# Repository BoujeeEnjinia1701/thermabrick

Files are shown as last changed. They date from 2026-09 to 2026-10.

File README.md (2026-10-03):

# ThermaBrick

  

**Area:** CleanTech · **TRL:** 3 of 9 (proof of concept) · **Status:** Concept · **Value-engineering target:** USD 728, the test article budget decided by Amish on 2026-09-25 (on hold with TRL 4); estimated cost of the constructable design USD 3,869 (USD 3,141 over the target) · **Difficulty:** 3 of 5

Sand thermal battery in an insulated steel drum. Resistive elements charge it from surplus PV, and a fan pulls hot air out for space heating.

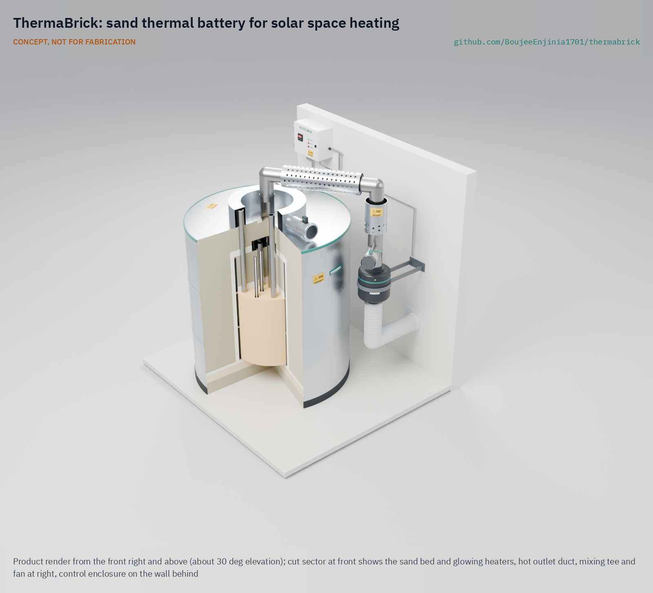
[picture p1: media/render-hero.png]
ThermaBrick: sand thermal battery for solar space heating, product render


[Exploded render](media/render-exploded.png) · [Detail render](media/render-detail.png) · [Interactive 3D model](media/viewer.html) · [Concept blueprint (PDF)](media/concept-blueprint.pdf) · [General arrangement TBK-DWG-001 (PDF)](cad/drawings/TBK-DWG-001.pdf) · [Sizing calculations](docs/04-calcs/TBK-CAL-001-sizing.md) · [Prototype build plan](docs/05-build-plan.md) · [Design decisions](docs/06-design-decisions.md) · [Review note](docs/REVIEW.md)

> **Out-of-phase work archived (2026-09-25).** The portfolio is capped at TRL 3, and TRL 4 is on hold by Amish's instruction. The reduced-scale test article, its test plan and report template, firmware, controller schematic and board, enclosure, purchasing checklist, build procedure and cut list were made in an earlier session that went past the cap. They are kept, unchanged and with full history, in [archive/out-of-phase-trl4/](archive/out-of-phase-trl4/README.md), and are not current work.

## Concept rationale

Heat is the largest energy load in a cold-climate home, and it is the one load that can be stored cheaply in an inert, abundant material. Sand costs almost nothing, does not burn and does not wear out with cycling, and quartz holds more heat per kilogram as it gets hotter. Storing midday solar surplus as heat at up to 450 °C, and releasing it as warm air in the evening, uses the surplus far better than exporting it for a few cents. It also avoids spending lithium battery cycles on a job that sand can do.

The design is open and garage-buildable because the ideas that make it work are simple and well published, while the barrier is detail: how many heater wells, how thick the insulation, how to keep the sand below its quartz inversion and the jacket cool. A standard 55 US gal drum, threaded black steel pipe, stock cartridge heaters and fiber insulation need no welding, pressure parts or machining. Publishing the model, calculations and drawings lets makers, students and community energy groups check the numbers and adapt the design to their own climate and tariff.

## Burning platform

Heat is the largest energy end use. The International Energy Agency reports that heat accounted for almost half of total final energy consumption and for 38 % of energy-related CO2 emissions in 2022, and that renewables supplied only 13 % of global heat consumption that year ([IEA, *Renewables 2023*, Heat](https://www.iea.org/reports/renewables-2023/heat)).

At the same time, grids with a lot of solar already throw some of it away. The California Independent System Operator curtailed 2.4 million MWh (2.4 TWh) of utility-scale wind and solar output in 2022, and more than 2.3 million MWh in the first nine months of 2023 ([US EIA, *Today in Energy*](https://www.eia.gov/todayinenergy/detail.php?id=60822)). Rooftop systems face the same timing problem at house scale: the surplus arrives at midday and the heating demand arrives after dark.

## Where it could be used

### By industry

| Industry | Use |
| --- | --- |
| Residential heating | Shift rooftop solar surplus into evening and night space heat in homes with a slab-on-grade utility room, basement or garage |
| Agriculture | Warm air for small greenhouses, farm workshops and livestock rooms from the farm's own PV |
| Small commercial and workshops | Background heat for workshops and small warehouses that stand empty at midday and need heat at opening time |
| Community energy groups | A documented, shared demonstrator for absorbing local solar surplus as heat instead of exporting it |
| Education and research | A teaching rig for heat transfer, thermal storage and control, with a published model and calculation note |

*Table 1. Uses by industry.*

### By country or region

| Country or region | Why it matters there |
| --- | --- |
| United States (California) | Solar output is already curtailed at grid scale, 2.4 TWh in 2022 ([US EIA](https://www.eia.gov/todayinenergy/detail.php?id=60822)), and since April 15, 2023 new rooftop systems take the Net Billing Tariff, which credits exports at avoided-cost values that are usually lower than the retail rate ([California Public Utilities Commission](https://www.cpuc.ca.gov/industries-and-topics/electrical-energy/demand-side-management/customer-generation/net-energy-metering-and-net-billing)) |
| Finland | Sand heat storage already supplies district heating there: a 200 kW, 8 MWh unit at Kankaanpää since 2022 and a 1 MW, 100 MWh unit at Pornainen since June 2025 ([Polar Night Energy](https://polarnightenergy.com/news/what-is-a-sand-battery/); see also [UNRIC](https://unric.org/en/sand-warms-up-the-finnish-polar-night/) on the Kankaanpää unit); ThermaBrick tests the idea at single-house scale |
| Australia | About 4.2 million homes and small businesses had rooftop solar by June 2025 ([Clean Energy Council, September 15, 2025](https://cleanenergycouncil.org.au/news-resources/australia-powers-ahead-on-rooftop-solar-as-nation-set-to-achieve-2030-rooftop-target-new-report)), and in South Australia the market operator can direct rooftop solar exports to be curtailed during minimum-demand events ([SA Power Networks](https://www.sapowernetworks.com.au/your-power/quality-reliability/solar-curtailment-for-minimum-system-demand-events/)); storing the surplus as heat keeps it in the home |
| China | China, the European Union and the United States account for three-quarters of recent renewable heat growth, and China dominates global solar thermal ([IEA, *Renewables 2023*, Heat](https://www.iea.org/reports/renewables-2023/heat)); a solar-to-sand store brings rooftop PV into a market already large for solar heat |
| Mongolia (Ulaanbaatar) | January temperatures fall below −20 °C, and more than half of ger-area households still heat with traditional coal stoves, pushing winter fine-particle levels in those neighborhoods above 100 times the WHO 24-hour guideline ([World Bank, 2018](https://www.worldbank.org/en/news/feature/2018/06/26/better-air-quality-in-ulaanbaatar-begins-in-ger-areas)); clean stored heat is a direct substitute for the stove |

*Table 2. Where ThermaBrick matters, by country or region.*

## What sparked the idea

The starting point was Finland's sand batteries, which store surplus renewable electricity as heat in sand for district heating. The first commercial unit, built by Polar Night Energy for the utility Vatajankoski at Kankaanpää and commissioned in 2022, is rated 200 kW and 8 MWh and feeds a network that heats homes, offices and the municipal swimming pool ([Polar Night Energy, "World's first Sand Battery"](https://polarnightenergy.com/reference/worlds-first-sand-battery/)); the United Nations Regional Information Centre reports that it holds its sand at 500 to 600 °C ([UNRIC, "Sand warms up the Finnish polar night"](https://unric.org/en/sand-warms-up-the-finnish-polar-night/)). A 1 MW, 100 MWh unit followed at Pornainen in June 2025 ([Polar Night Energy, "What is a Sand Battery?"](https://polarnightenergy.com/news/what-is-a-sand-battery/)). Those units serve district heating networks. ThermaBrick asks whether the same physics can be scaled down to one house with rooftop PV and no heating network: a drum of sand, a set of cartridge heaters and a warm-air outlet, built from parts a maker can buy.

## Problem

Surplus rooftop solar gets exported cheaply or curtailed, while heating still burns gas.

## Concept

Sand thermal battery in an insulated steel drum. Resistive elements charge it from surplus PV, and a fan pulls hot air out for space heating.

The v0.2 design, made constructable on 2026-09-30 (TBK-DDR-003), stores 18.3 kWh(th) in 210 kg of sand between 150 °C and 450 °C. Twelve 250 W heaters charge it at up to 3.0 kW, filling it in 9.6 h, and six steel U-tubes deliver 1.0 kW of warm air for about 14 h. A reduced-scale test article (about 6 kWh(th), budget $727.70) is the next step, to measure the sand and insulation properties the design depends on. It is archived and on hold with TRL 4.

| Document | ID | Version |
| --- | --- | --- |
| [Problem statement](docs/01-problem.md) | TBK-PRB-001 | 0.11 |
| [Design precis](docs/02-concept.md) | TBK-PRC-001 | 0.8 |
| [Requirements](docs/03-requirements.md) | TBK-REQ-001 | 0.12 |
| [Thermal and electrical sizing](docs/04-calcs/TBK-CAL-001-sizing.md) | TBK-CAL-001 | 0.5 |
| [General arrangement](cad/drawings/TBK-DWG-001.pdf) | TBK-DWG-001 | Rev P3 |
| [Concept sheet](media/concept-blueprint.pdf), with [hero](media/hero.png), [cutaway](media/cutaway.png) and [exploded](media/exploded.png) renders, [heat flow](media/flow.png) and [3D viewer](media/viewer.html) | TBK-DWG-006 | Rev P3 |
| [Recommendations accepted](docs/decisions/0002-recommendations-accepted.md) | TBK-DDR-002 | 0.2 |
| [Design for construction](docs/decisions/0003-design-for-construction.md) | TBK-DDR-003 | 0.3 |
| [Prototype build plan](docs/05-build-plan.md), with making sketches TBK-DWG-101 to 110 | TBK-BLD-001 | 0.2 |
| [Design decisions register](docs/06-design-decisions.md) | TBK-DEC-001 | 0.3 |
| [Purchasing checklist](archive/out-of-phase-trl4/bom/purchasing-checklist.md) (archived) | | Test article, by supplier |
| [Controller board BOM (optional, deferred; archived)](archive/out-of-phase-trl4/bom/bom-controller-board.csv) | | +$24.85 net |

## Key components

- 55 gal open-head steel drum, unlined
- Sand, 210 kg
- AES fiber blanket and stone wool insulation
- Nichrome cartridge heaters, 12 x 250 W, in steel wells
- Six 1-1/4 in steel U-tubes (discharge heat exchanger)
- Solid state relays and a safety contactor
- K-type thermocouples and an independent high-limit controller
- ESP32 controller and PV export meter
- Inline fan with mixing tee

The working bill of materials is in [bom/bom.csv](bom/bom.csv).

## Building the prototype

The [prototype build plan](docs/05-build-plan.md) (TBK-BLD-001) shows how to make each of the 21 components and put them together, with a making sketch for every made part, close-ups of the joints and a picture for every assembly step. Writing it made the design constructable: the wells and U-tubes now have a seat and fittings that match the drawings, the base and plenum can be built and fixed, the hot outlet clears the galvanized cap, and the heater leads and thermocouples reach the outside (TBK-DDR-003). Decisions still open are in the [design decisions register](docs/06-design-decisions.md). It is a plan only; building to it is TRL 4 work, which is on hold.

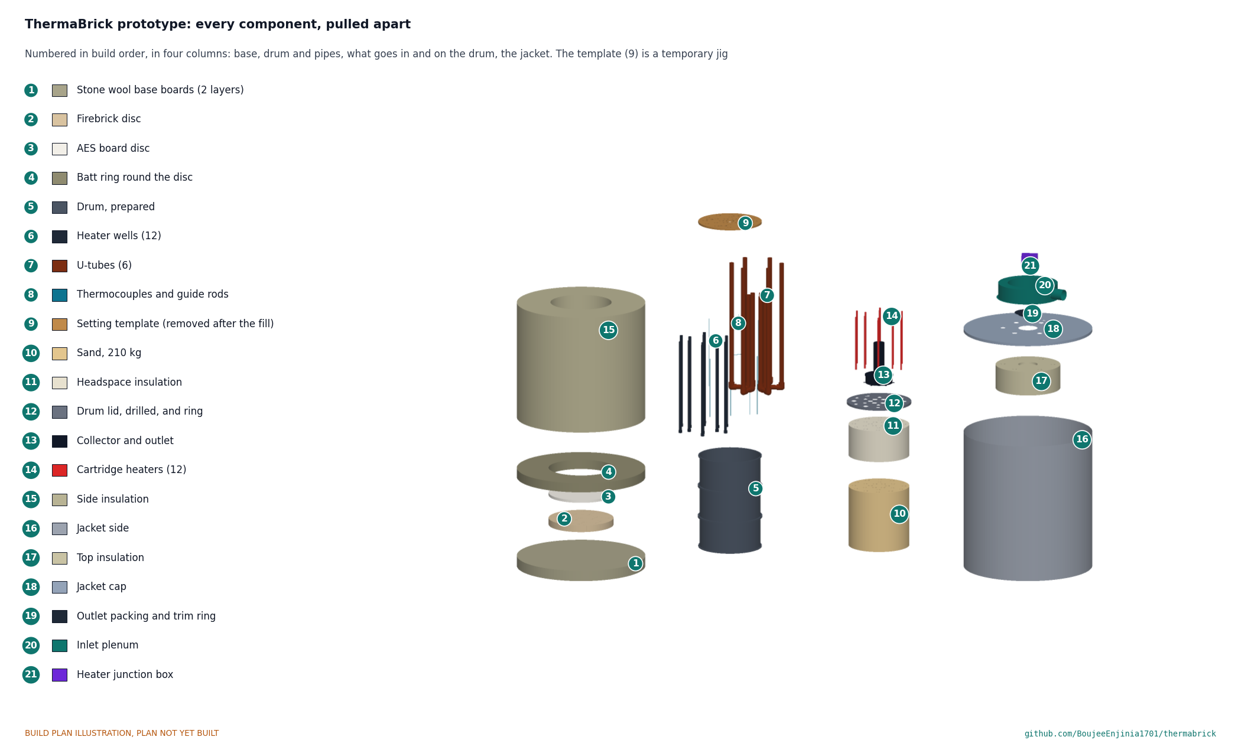
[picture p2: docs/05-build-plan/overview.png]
ThermaBrick prototype: every component, pulled apart and numbered in build order


## Safety

> Operates at up to 550 °C inside and weighs about 415 kg. Use a dedicated 240 V circuit with a 5 mA GFCI breaker, keep the hot outlet duct guarded and 450 mm from combustibles, keep the independent high limit in service, and stand the unit on a concrete slab. See TBK-PRC-001, sections 6 and 7.

## Repository layout

| Folder | Contents |
| --- | --- |
| `docs/` | Problem, concept, requirements, calculations and design decisions |
| `cad/src/` | build123d Python source, the source of truth for all geometry |
| `cad/step/`, `cad/stl/` | Exported models for FreeCAD, other CAD tools and printing |
| `cad/drawings/` | 2D sketches and dimensioned drawings |
| `bom/` | Bill of materials |
| `electronics/` | KiCad schematics and PCB layouts (empty at TRL 3; earlier work archived) |
| `firmware/` | Microcontroller code (empty at TRL 3; earlier work archived) |
| `media/` | Renders, perspectives and photos |
| `build-log/` | Dated prototyping notes |

## Documentation

Controlled documents follow the portfolio [documentation standard](.kit/STANDARDS.md). Each carries a document ID (TBK-PRC-001 for the precis), a version and a revision history. Branded PDFs are built with `python .kit/render.py` and attached to GitHub Releases when a document is tagged, for example `TBK-PRC-001/v1.0`.

## Credits

Designed by Amish Chadha, with contributions from Ashok Kumar Chadha. See [CONTRIBUTORS.md](CONTRIBUTORS.md) for roles. To cite this design, use [CITATION.cff](CITATION.cff) (GitHub shows it as "Cite this repository").

AI assistance (Claude) was used to accelerate concept renders, prototype documentation and first-pass sizing calculations. Design direction and all decisions are Amish Chadha's, recorded in this repository's decision records (`docs/decisions/`).

## Licenses

- **Hardware** (CAD, drawings, BOM, electronics): [CERN-OHL-S v2](LICENSE)
- **Software** (firmware, scripts, notebooks): [MIT](LICENSE-SOFTWARE)

A project of the [Design Molecule](https://designmolecule.com) lab.

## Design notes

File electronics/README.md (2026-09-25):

# Electronics

| Path | Contents |
| --- | --- |
| `src/schematic.py` | Generator for the test article controller schematic (TBK-DWG-003), the source of truth for that circuit |
| `src/board.py` | Generator for the optional controller board: schematic, PCB layout, gerbers and TBK-DWG-004 |
| `test-article/` | KiCad project for TBK-DWG-003: the whole controller, mains and low voltage, as hand-wired modules |
| `controller-board/` | KiCad project for the optional low-voltage controller board, with gerbers for fabrication. **Optional and deferred:** not to be ordered unless Amish decides so |

Change a circuit in its script, not in KiCad, then regenerate from the repo root:

```bash
python electronics/src/schematic.py
```

```bash
python electronics/src/board.py
```

Both scripts need KiCad 9 or later. They look for it in `/Applications/KiCad`, in `~/Applications/KiCad`, or on the mounted KiCad disk image.

`schematic.py` runs KiCad's electrical rules check (ERC). It then exports the netlist and checks every net against the circuit the script declares. It fails on any ERC error or net mismatch.

`board.py` works in three stages:

1. It builds and checks the board schematic in the same way as `schematic.py`.
2. It re-runs itself inside KiCad's bundled Python. That stage places the footprints, routes the board with its own two-layer grid router (F.Cu preferred, clearance 0.25 mm against a 0.2 mm rule) and pours the GND plane on B.Cu.
3. It runs KiCad's DRC with schematic parity, then exports the gerber and drill package and the drawing sheet.

The P1 board passes with 0 errors, 0 warnings and 0 unconnected items. The routing is reproducible, but KiCad assigns fresh internal IDs, so the `.kicad_pcb` file changes on every run even when the layout does not.

Both projects carry every symbol and footprint they use, so they open without KiCad's global libraries installed. Terminal numbers on K1, U1 and U2 of TBK-DWG-003 are functional; wire to each part's own label.

**Board fit.** The board takes an ESP32-DevKitC V4 with 38 pins and header rows 25.4 mm apart. 30-pin and narrow clone boards do not fit. The pinout follows the Espressif DevKitC V4 user guide, header J2 on the left and J3 on the right, both numbered from the antenna end. Check your module against it before soldering the sockets.

**Licenses.** CERN-OHL-S-2.0 for the hardware; MIT for the generator scripts.

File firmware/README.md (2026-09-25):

# ThermaBrick test article firmware

ESP32 controller firmware for the reduced-scale test article (TBK-PRC-002). It covers the five functions that test plan TBK-TST-001, section 1, requires: charge mode, hold mode, blower control, logging and the safe state. It is written for the Arduino framework and built with PlatformIO. Licensed MIT (see `LICENSE-SOFTWARE`).

> **Safety:** This firmware is the second layer of protection, not the first. The REX-C100 limit and the latching relay open the heater circuit at 600 °C whatever the ESP32 is doing. Never bridge or bypass them, and run TBK-TST-001 TP1 before any heated test.

## Layout

| Path | Contents |
| --- | --- |
| `src/main.cpp` | Controller: thermocouples, heater burst firing, blower, HTTP API, log buffer |
| `lib/control/` | Control and safety logic with no Arduino dependency: PI loops, fault latching, MAX6675 decoding, airflow and power math |
| `test/test_control/` | Unit tests for `lib/control`, run on the host |
| `tools/logger.py` | Logging host: polls the controller and writes the test CSV; also the heartbeat |
| `tools/git_rev.py` | Stamps the build with the Git commit |
| `include/secrets.example.h` | Template for Wi-Fi credentials and the API token |

## Build and flash

```bash
pip install platformio
```

```bash
cp firmware/include/secrets.example.h firmware/include/secrets.h
```

Edit `secrets.h` with the Wi-Fi name, password and a long random `API_TOKEN`. The file is ignored by Git. Then, from `firmware/`:

```bash
pio test -e native
```

```bash
pio run -e esp32dev -t upload
```

```bash
pio device monitor
```

The monitor prints the IP address once Wi-Fi connects, then one CSV row every 10 s. Build `esp32dev_test` instead only for TP1 step 5. It adds an `/inject` endpoint that fakes T1, and it must never be used for a heated test.

## Wiring

The complete circuit, including the 120 V side, is the schematic TBK-DWG-003 (`cad/drawings/TBK-DWG-003.pdf`), with KiCad source in `electronics/test-article/`. Table 1 lists the ESP32 connections. The optional controller board, TBK-DWG-004, uses the same pins. On that board GPIO 26 drives the SSR through a 2N3904 and GPIO 25 drives an IRLZ44N; high means on in both cases, so the firmware is unchanged.

| Signal | ESP32 GPIO | Connects to |
| --- | --- | --- |
| SCK (shared) | 18 | SCK on all five MAX6675 modules |
| SO (shared) | 19 | SO on all five MAX6675 modules |
| CS, T1 well wall (control) | 5 | MAX6675 #1 |
| CS, T3 sand center | 17 | MAX6675 #2 |
| CS, T4 sand outer | 16 | MAX6675 #3 |
| CS, T5 exchanger outlet air | 4 | MAX6675 #4 |
| CS, T6 room air | 22 | MAX6675 #5 |
| SSR input + | 26 | SSR terminal 3, with a **10 kΩ pull-down from GPIO 26 to GND** |
| Blower PWM | 25 | MOSFET module signal input, with a 10 kΩ pull-down to GND |
| 5 V and GND | 5V, GND | 12 V to 5 V buck converter; MAX6675 modules take 3.3 V |

*Table 1. Controller wiring.*

Generic SSR-25DA relays specify a 3 V to 32 V input, so 3.3 V from the GPIO is near the bottom of their range. If the SSR's LED does not light reliably, drive its input from 5 V through a small NPN transistor, and keep the pull-down on the GPIO. The pull-down on GPIO 26 is required. It holds the SSR off while the ESP32 boots, resets or is unprogrammed (TBK-TST-001, section 1, item 5). T2 is not wired to the ESP32; it goes only to the REX-C100.

The heater circuit is the 120 V line through the 10 A fuse, then the latching relay contacts, then the SSR, then the four heaters in parallel. The latching relay coil circuit is the line through STOP (normally closed), then START (normally open) in parallel with the relay's own holding contact, then the REX-C100 relay (closed below 600 °C), then the coil.

## How it works

- **Thermocouples.** All five channels are read once a second, by a bit-banged read with the timing of the Adafruit driver. A frame of all zeros, or with the dummy sign bit or device ID bit set, is rejected as a bus fault. An open thermocouple is reported separately. Invalid readings are logged as blank fields, never as 0 °C.
- **Heater output.** A 10 ms timer fires the SSR in bursts within a 1 s window, so the zero-cross SSR switches whole mains cycles. The duty resolution is 1 %, or 10 W on the 1.0 kW article.
- **Charge mode.** Full power until T1 first reaches the setpoint (550 °C by default), then PI control on T1 with a bumpless handover. The default gains are 0.05 per K (full to zero over 20 K) and 300 s. Tune them in TP3 if T1 overshoots by more than 10 K or oscillates.
- **Hold mode.** PI control on T1 from the start, at a lower setpoint, for the TP2 bake-out.
- **Manual mode.** A fixed duty of up to 25 %, for commissioning and the TP1 fault checks only.
- **Blower.** Either a fixed PWM duty, or a closed-loop exchanger duty in watts: ṁ cp (T5 − T6), with airflow from the TP0 duty-to-flow table. The PWM frequency defaults to 100 Hz, which suits 2-wire 12 V blowers switched by a MOSFET. Change it with `/config?pwm_hz=` if the blower stalls or whines.
- **Logging.** One row every 10 s goes into a 3 h ring buffer in RAM and to the serial port. `tools/logger.py` collects the rows over HTTP. The time stamp is seconds since boot; the logger adds wall-clock time.

## Safety model

Any of the conditions in Table 2 latches a fault. A latched fault turns the heaters off at once and sets the heater mode to off. Clearing the fault never restarts heating: the operator must clear it and then command the heater mode again.

| Bit | Fault | Trigger |
| --- | --- | --- |
| 1 | T1 invalid | T1 open or unreadable for 3 consecutive reads (3 s) |
| 2 | T1 high | T1 above 575 °C, after the calibration offset |
| 4 | Sand high | T3 or T4 above 560 °C (quartz inversion margin) |
| 8 | Log stale | No `/log` poll for more than 60 s, or none since boot |
| 16 | Loop stall | Main loop silent for 6 s; the output timer also forces the SSR off by itself |

*Table 2. Latched faults.*

The ESP32 task watchdog resets the controller if the main loop hangs for 8 s. After a reset the heaters stay off, held by the pull-down resistor, until they are commanded again. The "log stale" fault is latched at every boot, so heaters cannot run until a logging host is connected and the fault has been cleared.

## HTTP API

Every request needs `?token=` when `API_TOKEN` is set. All requests are GET, so they can be sent with `curl` or a browser.

| Request | Effect |
| --- | --- |
| `/status` | JSON: temperatures, modes, duties, power, energy, airflow, exchanger duty, faults |
| `/log?since=N` | CSV header, then the buffered rows after sequence N (up to 360 per call); also the heartbeat |
| `/heater?mode=charge&sp=550` | Charge mode; the setpoint is limited to 20 °C to 550 °C |
| `/heater?mode=hold&sp=200` | Hold mode |
| `/heater?mode=manual&duty=0.10` | Manual duty, 0 to 0.25 |
| `/heater?mode=off` | Heaters off |
| `/blower?mode=duty&value=0.5` | Fixed blower duty, 0 to 1 |
| `/blower?mode=power&value=250` | Closed-loop exchanger duty in W |
| `/blower?mode=off` | Blower off |
| `/config` | Show the configuration. With parameters, set and save it to flash: `v_line`, `r_heat`, `kp`, `ti`, `kpb`, `tib`, `bmin`, `off_t1`, `pwm_hz`, `air` |
| `/clear` | Clear latched faults if no fault condition is present |

*Table 3. HTTP API.*

The `air` table takes duty-to-airflow pairs from TP0, as duty (0 to 1) and L/s, in ascending order. For example: `/config?air=0.25:1.1,0.5:2.2,0.75:3.2,1:4.0`. Set `r_heat` to the parallel hot resistance: the TP0 cold values in parallel, times 1.04. Set `v_line` to the voltage measured at the start of each run.

## Running a test

A typical TP3 charge, from the repo root. Replace `HOST` and `TOKEN` with the controller's address and the API token.

```bash
python firmware/tools/logger.py --host HOST --token TOKEN --procedure TP3 --vline 119.6
```

With the logger running, in a second terminal:

```bash
curl "http://HOST/clear?token=TOKEN"
```

```bash
curl "http://HOST/heater?mode=charge&sp=550&token=TOKEN"
```

Stop by commanding `mode=off`, or press STOP on the enclosure. The logger writes to `docs/05-tests/data/YYYY-MM-DD_TP3.csv`, and a restart on the same day appends to the same file.

## Tests

`pio test -e native` runs 14 unit tests on the host. They cover:

- MAX6675 decoding and bus-fault rejection;
- charge mode's full-power-then-PI behavior;
- PI windup recovery;
- hold and manual modes;
- every safety latch and the rule that faults clear only when conditions are gone;
- burst timing, the airflow lookup and the power and duty math.

The hardware behavior is tested on the article itself in TBK-TST-001, TP1.

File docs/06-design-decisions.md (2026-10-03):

---
doc_id: TBK-DEC-001
title: ThermaBrick design decisions register
project: ThermaBrick
doc_type: Design decisions register
version: "0.4"
status: Draft
date: '2026-10-03'
author: Amish Chadha
license: CERN-OHL-S-2.0
revisions:
  - version: "0.1"
    date: '2026-10-01'
    author: Amish Chadha
    change: Register opened with the open decisions from REVIEW.md, TBK-PRC-001, TBK-DDR-002 and TBK-DDR-003; budget treated as a value-engineering target
  - version: "0.2"
    date: '2026-10-02'
    author: Amish Chadha
    change: 'Amish approved the recommendations for all nine open decisions on 2026-10-02 (TBK-DDR-003 accepted); moved to decisions made'
  - version: "0.3"
    date: '2026-10-02'
    author: Amish Chadha
    change: 'Cost restated to USD 3,869 with the warning labels (BOM line 47) and the approved wording; stray full stop fixed'
  - version: "0.4"
    date: '2026-10-03'
    author: Amish Chadha
    change: "Amish accepted the cost overrun against the value-engineering target on 2026-10-03; row added to decisions made; value engineering section updated"
---

# ThermaBrick design decisions register

Every design decision still to be made, and every decision made, in one place. Each decision is argued in full in its decision record under `docs/decisions/` or in the review note; this register is the index Amish works from. The build plan (`docs/05-build-plan.md`) describes the design as it stands and does not list open decisions.

## Open decisions

None. All open decisions were decided on 2026-10-02.

## To confirm when parts are bought

| # | What to confirm | Why it matters | Source |
| --- | --- | --- | --- |
| 1 | The cartridge heaters can be made with 72 in (1,829 mm) ceramic-beaded leads | Shorter leads do not reach the junction box from the far wells | TBK-DDR-003, P9 |
| 2 | The 1-1/4 in elbows' centre-to-end size (about 44.5 mm) and thread make-up, with the 4 in nipple, give 155 mm between leg centres | Sets the U-tube leg spacing that matches the lid holes | TBK-DDR-003, P2 |
| 3 | The stone wool base board is rated 60 kPa or more at 10 % strain | It carries the firebrick load of 15.0 kPa with a safety factor of 4 | TBK-CAL-001, section 7 |
| 4 | The inline fan's pressure curve and speed input meet 60 L/s at 150 Pa | Sets the discharge air flow | TBK-PRC-001, section 9 |
| 5 | The drum's lid is 16 ga, its rim 597 mm and its bottom rim stands on a flat ring | The lid layout and the AES disc size depend on it | TBK-DDR-003, P3 and P5 |
| 6 | At the first firing (TRL 4): the galvanized jacket cap at the edge of the outlet hole stays below 200 °C | R13; if not, fit a listed double-wall stovepipe thimble | TBK-DDR-003, P8 |

## Value engineering

Value-engineering target: USD 728 (a hypothetical control target, not a limit; `budget_usd` in `project.yaml`, set as the reduced-scale test article budget by Amish on 2026-09-25). Estimated cost of the constructable design: USD 3,869 (USD 3,141 over the target). Main cost drivers and savings worth trying:

Amish accepted this overrun on 2026-10-03: the full-scale estimate of USD 3,869 against the USD 728 target (USD 3,141 over). Amish: "Cost over target - i accept all the cost variations and overruns". It stays reported against the target as an accepted overrun, and the savings below remain worth trying.

- The largest groups are insulation (USD 871), controls and instrumentation (USD 863), heaters and wells (USD 776) and the discharge exchanger and air path (USD 740). The largest single lines are the twelve cartridge heaters (USD 588), the stone wool batts (USD 225), the four stone wool boards (USD 180) and the eight thermocouples (USD 208).
- Making the design constructable added USD 180, and the approved warning labels USD 15: longer heater leads and thermocouples, 4 in nipples, two firebricks, a second AES rope, fasteners, and the template, trim ring, guide rods and grommets.
- Savings worth trying (`bom/bom-notes.md`, Table 2): generic import heaters (about USD 300), a reconditioned drum (about USD 100), reading export from the inverter instead of a meter (USD 90), MAX31855 amplifiers (about USD 50), and an existing 240 V circuit (up to USD 190), and stone wool batts in place of board in the base (about USD 100), together about USD 830, which would bring the estimate to about USD 3,040, still far over the target; only the reduced-scale test article (archived, on hold with TRL 4) comes near it.

## Decisions made

| Date | Decision | Decided by | Record |
| --- | --- | --- | --- |
| 2026-09-24 | Build a reduced-scale test article first, within the prototype budget | Amish | TBK-PRB-001, section 5 |
| 2026-09-25 | Test article budget USD 727.70; revisit the full-scale budget with its results (both on hold with TRL 4) | Amish: "i accept all your recommendations, go with them across all repos." | [TBK-DDR-002](decisions/0002-recommendations-accepted.md), A1, A2 |
| 2026-09-25 | Design decisions D1 to D8: silica sand 150 to 450 °C, cartridge heaters in capped wells, twelve 250 W wells, closed U-tubes, cold-side damper with mixing tee and heat trap, wells end at the lid, AES hot face with stone wool, 240 V burst-fire SSRs with contactor | Amish, same instruction | [TBK-DDR-002](decisions/0002-recommendations-accepted.md), A3 |
| 2026-09-25 | Requirement targets R1 to R20 as written, including the 500 °C drum-wall limit | Amish, same instruction | [TBK-DDR-002](decisions/0002-recommendations-accepted.md), A4, A5 |
| 2026-09-25 | R3 charge-time miss: choose the fix after the test article measures sand conductivity (on hold with TRL 4) | Amish, same instruction | [TBK-DDR-002](decisions/0002-recommendations-accepted.md), A6 |
| 2026-09-25 | Controller board stays deferred; KiCad install on hold with TRL 4 | Amish, same instruction | [TBK-DDR-002](decisions/0002-recommendations-accepted.md) |
| 2026-09-30 | The design is made physically buildable as the build plan is drawn | Amish: "If you are realising that the design cannot be built as per concept - fix the design assumptions to match and be physically feasible as you draw the illustrations." | [TBK-DDR-003](decisions/0003-design-for-construction.md) (its changes accepted on 2026-10-02, below) |
| 2026-09-30 | Outstanding decisions live in this register, not in the build plan | Amish: "don't log outstanding decisions in this build plan - that is not the place for it." | This register |
| 2026-10-01 | Budgets are value-engineering targets, not limits | Amish: "the budgets are a hypothethical control target to ensure we are thinking along a value engineering lens." | This register, Value engineering |
| 2026-10-02 | Design for construction accepted: the changes P1 to P11 and their knock-on changes, as made | Amish: "i approve your recommendations for all 555 open decisions." | TBK-DDR-003, Table 1 |
| 2026-10-02 | Warning labels: one BOM line, about USD 15, for hot-surface and 240 V warning labels on the jacket, outlet guard, junction box and enclosure (option a) | Amish: "i approve your recommendations for all 555 open decisions." | TBK-DDR-003, C1; REVIEW 2026-09-26, item 4 |
| 2026-10-02 | Air path beyond the unit: the layout stays illustrative at TRL 3 (option a), and its siting rules become requirements an installer must meet: the hot outlet duct is kept 450 mm from combustibles and guarded by a perforated steel sleeve, the outlet run forms a heat trap, and the fan sits below the mixing tee | Amish: "i approve your recommendations for all 555 open decisions." | TBK-DDR-003, C2; REVIEW 2026-09-26, item 2 |
| 2026-10-02 | Standby loss: 459 W standby loss accepted for now (option a); the stainless upper inlet legs and microporous hot face (357 W, about USD 450) are decided together with the R3 charge-time fix once the test article has measured loss | Amish: "i approve your recommendations for all 555 open decisions." | TBK-PRC-001, section 9; TBK-CAL-001, Table 5 |
| 2026-10-02 | Ground-fault protection: a 2-pole 5 mA GFCI breaker; 30 mA equipment ground-fault protection only if the heaters still trip it after bake-out and the installing electrician confirms the code allows it at that location | Amish: "i approve your recommendations for all 555 open decisions." | TBK-PRC-001, sections 8 and 9 |
| 2026-10-02 | The 80 degree cut sector is kept for the hero and detail renders only; drawings and STEP files stay whole | Amish: "i approve your recommendations for all 555 open decisions." | REVIEW 2026-09-26, item 1 |
| 2026-10-02 | Fan, guard sleeve, intake and grille sizes in the renders accepted as placeholders until the fan is chosen | Amish: "i approve your recommendations for all 555 open decisions." | REVIEW 2026-09-26, item 3 |
| 2026-10-02 | The teal top trim ring and kick plinth are optional cosmetic parts with no BOM line; the renders must also show the functional black outlet trim ring (BOM line 44) | Amish: "i approve your recommendations for all 555 open decisions." | REVIEW 2026-09-26, item 4 |
| 2026-10-02 | The insulation stays drawn as an AES hot face over stone wool | Amish: "i approve your recommendations for all 555 open decisions." | REVIEW 2026-09-26, item 5 |
| 2026-10-03 | Cost overrun accepted: the full-scale estimate of USD 3,869 against the USD 728 target (USD 3,141 over) | Amish: "Cost over target - i accept all the cost variations and overruns" | [REVIEW.md](REVIEW.md), session 2026-10-03 |

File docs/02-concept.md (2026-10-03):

---
doc_id: TBK-PRC-001
title: ThermaBrick design precis
project: ThermaBrick
doc_type: Design precis
version: "0.8"
status: Draft
date: '2026-10-02'
author: Amish Chadha
license: CERN-OHL-S-2.0
revisions:
- version: "0.1"
  date: '2026-09-24'
  author: Amish Chadha
  change: Initial scaffold
- version: "0.2"
  date: '2026-09-24'
  author: Amish Chadha
  change: Full v0.2 design. Architecture, sizing summary from TBK-CAL-001, charge and discharge subsystems, controls, build and commissioning sequence, safety, design decisions, risks and open questions; general arrangement TBK-DWG-001 Rev P1
- version: "0.3"
  date: '2026-09-24'
  author: Amish Chadha
  change: Updated charge and discharge figures for standby loss (TBK-CAL-001 v0.2); recorded the R3 shortfall and the options to close it; added the reduced-scale test article (TBK-PRC-002) as the next build
- version: "0.4"
  date: '2026-09-24'
  author: Amish Chadha
  change: 'Review pass: design decisions D1 to D8 marked proposed, awaiting Amish; none has been reviewed or accepted'
- version: "0.5"
  date: '2026-09-25'
  author: Amish Chadha
  change: Recommendations accepted by Amish (DDR-002)
- version: "0.6"
  date: '2026-10-01'
  author: Amish Chadha
  change: 'Design made constructable (TBK-DDR-003): mass 415 kg, parts $3,854, build sequence points to the build plan TBK-BLD-001; budget worded as a value-engineering target'
- version: "0.7"
  date: '2026-10-02'
  author: Amish Chadha
  change: 'Decisions of 2026-10-02 (TBK-DEC-001): 5 mA GFCI breaker, siting rules as installer requirements, warning labels, standby loss accepted for now'
- version: "0.8"
  date: '2026-10-02'
  author: Amish Chadha
  change: 'Parts cost $3,869 with BOM line 47 (warning labels); label positions in TBK-BLD-001 step 22'
---

# ThermaBrick design precis

ThermaBrick is a 55 US gal steel drum filled with 210 kg of dry silica sand, insulated to 1.21 m diameter and charged by twelve 250 W cartridge heaters from surplus rooftop PV. It stores 18.3 kWh(th) between 150 °C and 450 °C. It fills in 9.6 h at up to 3.0 kW, then delivers 1.0 kW of warm air for 14.3 h through six steel U-tubes buried in the sand. The design needs no welding and no pressure parts. It keeps all sand below the 573 °C quartz inversion and the jacket below 30 °C. Its weaknesses are cost, standby loss and charge time. The constructable design's parts are estimated at $3,854 (TBK-DDR-003), USD 3,126 over the USD 728 value-engineering target. It releases 459 W passively at full charge. With that loss running, a full charge takes 9.6 h, against the 8 h in R3. A reduced-scale test article (TBK-PRC-002, budget $727.70 decided by Amish on 2026-09-25) will measure the sand and loss properties behind all three before the full-scale build. It is archived and on hold with TRL 4.

| Parameter | Value |
| --- | --- |
| Storage | 210 kg dry silica sand in an unlined 55 US gal open-head drum |
| Usable heat | 18.3 kWh(th), 150 to 450 °C energy-weighted mean |
| Charge | 12 cartridge heaters of 250 W in steel wells; 3.0 kW, 12.5 A at 240 V |
| Charge time from empty | 10.9 kWh in 4 h; full in 9.6 h |
| Discharge | Six 1-1/4 in U-tubes; 1.0 kW for 14.3 h, to 154 °C sand mean; 1.5 kW boost for 8.1 h |
| Supply air | 30 L/s at 50 °C (1.0 kW), mixed from exchanger outlet air and room air |
| Standby loss | 459 W at full charge; 8.7 kWh over 24 h idle |
| Envelope and mass | 1,209 mm diameter by 1,462 mm high; about 415 kg in service |
| Controls | ESP32, seven thermocouple channels, live PV export from an energy meter, independent 600 °C hardware limit |
| Parts cost | $3,869 estimated (bom/bom.csv), against a USD 728 value-engineering target |

*Table 1. Key parameters of the v0.2 design.*

General arrangement drawing TBK-DWG-001 Rev P2

*Figure 1. General arrangement, TBK-DWG-001 Rev P2, generated from `cad/src/model.py`. The front view is a section with the sand omitted; the isometric view has one quarter cut away.*

## 1. Architecture

ThermaBrick has five subsystems. Heat flows between them in one direction during charge and the other during discharge, and the sand never moves.

1. **Storage vessel and medium.** The drum holds the sand bed, 571 mm deep, with a 299 mm stack of insulation in the headspace above it.
2. **Charge subsystem.** Twelve cartridge heaters sit in capped steel wells in two rings of six. Heat conducts from each well into the surrounding sand.
3. **Discharge subsystem.** Six U-tubes run through the bed. Room air flows down the outer legs, across the drum floor and up the inner legs into a collector on the lid. From there a steel duct carries it to a mixing tee, where room air tempers it before the fan delivers it.
4. **Insulation envelope.** The side is insulated with AES blanket and stone wool, the top with a stack in the headspace plus more over the lid, and the base with board and firebrick. A galvanized jacket covers it all.
5. **Controls and safety.** An ESP32 reads the thermocouples and the grid export meter. It drives two SSRs and the inlet damper, and controls the fan. A separate hardware limit opens a contactor if a well wall passes 600 °C.

## 2. Storage vessel and medium

The vessel is a new, unlined, open-head 55 US gal steel drum (571.5 mm inside diameter, 883 mm high) with a bolted lid. It carries no pressure: the lid penetrations are gasketed with AES rope but not sealed, so the bed breathes to the room. Most of the drum wall stays near the 432 °C sand temperature midway between wells. Beside the outer ring of wells, 41 mm from the wall, it may reach about 480 °C at full charge. Mild steel keeps adequate strength at that temperature and scales only slowly; R8 caps the wall at 500 °C.

The medium is 210 kg of washed silica sand, sieved to remove fines and dried in place during commissioning. Silica sand was chosen over basalt, olivine or brick for cost and availability. Its one drawback is the alpha to beta inversion of quartz at 573 °C, so the controller keeps the hottest sand, at the well walls, at or below 550 °C. The heat capacity of quartz rises from 916 J/(kg K) at 150 °C to 1,162 J/(kg K) at 450 °C, which is why 210 kg is enough (TBK-CAL-001, section 2).

## 3. Charge subsystem

Heat input is limited by how fast dry sand conducts heat, not by heater rating. The sand conducts only about 0.3 W/(m K), so twelve wells are used instead of six. That cuts the full-charge time from over 30 h to 9.6 h at the same 3.0 kW, with standby loss counted (TBK-CAL-001, Table 9).

- **Heaters.** 5/8 in by 20 in cartridge heaters, 250 W at 240 V, with an Incoloy 800 sheath, NiCr 80/20 winding in MgO and ceramic-beaded nickel leads. The surface load is 1.1 W/cm², and the hottest calculated sheath temperature is 634 °C against a 760 °C rating.
- **Wells.** 3/4 in Sch 40 black steel pipe, 906 mm long, with a threaded malleable iron cap at the bottom. The wells stand on the drum floor in rings of 150 mm and 245 mm radius and end 25 mm above the lid, so no steel crosses the top insulation. The heater leads rise through the insulation to a junction box on the jacket top. Any heater can be drawn out and replaced from above.
- **Switching.** Two groups of six heaters, each on a zero-cross SSR, with burst-fire control over 1 s windows. A 2-pole contactor upstream opens both legs whenever a hardware limit trips.
- **Charge profile.** Full 3.0 kW for the first 3.2 h, then tapering as the well walls reach 550 °C, to 1.2 kW at full charge (TBK-CAL-001, Figure 1).

## 4. Discharge subsystem

Air never touches the sand. Six closed U-tubes of 1-1/4 in black steel pipe carry it, so no dust is carried into the room and the pressure drop stays low (107 Pa at 25 L/s). Table 2 traces the air path.

| Step | Component | Air temperature |
| --- | --- | --- |
| 1 | Room air enters the 4 in inlet collar on the annular inlet plenum on the jacket top, through a servo-driven damper | 20 °C |
| 2 | Down the six outer legs (radius 235 mm), across the drum floor, up the six inner legs (radius 80 mm) | Rising |
| 3 | Into the 10 in collector on the lid, then up the 4 in steel outlet, which rises and turns down as a heat trap | Up to 314 °C |
| 4 | Mixing tee: room air joins through a manual balancing damper | 50 °C setpoint |
| 5 | 4 in EC inline fan, then insulated flexible duct to the room register | 50 °C or below |

*Table 2. Discharge air path.*

The controller sets heat output with the inlet damper and holds the supply air at 50 °C with fan speed. At full charge 2.8 L/s through the exchanger carries 1.0 kW. As the bed cools the damper opens, up to 25 L/s at a 154 °C sand mean (TBK-CAL-001, Figure 2). Of the 18.3 kWh stored, 14.5 kWh leaves as controlled output and 3.8 kWh as standby loss into the same room. The inlet damper sits on the cold side, so an ordinary galvanized butterfly and a hobby servo can do the job. When it closes, the heat-trap bend in the outlet stops convection through the tubes.

## 5. Controls and instrumentation

The ESP32 runs three modes, and more than one can be active at once.

- **Charge.** When the meter shows export above 150 W, the controller raises heater power by the export less a 100 W margin, up to 3.0 kW. A PI loop on the hotter of the two well-wall thermocouples holds 550 °C, and charging stops at 100 % state of charge.
- **Discharge.** When the room is below its setpoint, or on a schedule, the damper opens under PI control on estimated heat output, and the fan holds supply air at 50 °C.
- **Idle and fault.** The heaters are off and the damper is closed. On a controller reset, loss of the export signal for 60 s, an open thermocouple or a supply-air reading above 65 °C, the controller drops into this mode and stays there until the fault clears.

State of charge is the energy-weighted mean of the four sand thermocouples, converted through the quartz enthalpy curve. The weights will be calibrated against the calorimetric test for R18.

| Tag | Location | Sensor | Purpose |
| --- | --- | --- | --- |
| T1, T2 | Well wall, one ring A and one ring B well, mid heated length | Type K, MI 3 mm | Charge limit, 550 °C |
| T3 | Well wall, second ring A well | Type K, MI 3 mm | Independent hardware limit, 600 °C |
| T4 to T6 | Sand at mid-depth: center; 200 mm radius; 270 mm radius | Type K, MI 3 mm | State of charge, radial gradient |
| T7 | Sand 100 mm below the surface, 200 mm radius | Type K, MI 3 mm | State of charge, top of bed |
| T8 | Collector air | Type K, MI 3 mm | Exchanger outlet, heat output estimate |
| A1 to A3 | Room, supply air, jacket surface | DS18B20 | Comfort control, supply limit, surface check |
| E1 | Main panel, grid conductors | Energy meter with 50 A CTs | PV export signal |

*Table 3. Instrumentation.*

## 6. Build and commissioning

The prototype build plan TBK-BLD-001 (`docs/05-build-plan.md`) gives the full, illustrated sequence for the constructable design (TBK-DDR-003); this section is the summary. The build takes about three weekends. It needs a pipe threader (rental), a drill with hole saws, snips and a rivet gun.

1. **Drum.** Strip the exterior paint, then burn the drum empty outdoors to 300 °C to remove residues. Drill the lid through a plywood setting template made from the model: twelve 36 mm holes for the wells (each also passes a well-wall thermocouple), twelve 48 mm holes for the U-tube legs and four 6 mm holes for the sand thermocouples.
2. **Base.** Lay two layers of stone wool board over the full diameter on the slab. Add a 610 mm disc of insulating firebrick under the drum footprint and a 25 mm AES board disc on top, with a ring of 89 mm stone wool batt round them out to the jacket.
3. **Internals.** Set the drum on the base. Level a 14 mm first lift of sand and stand the capped wells on it; stand the U-tubes (two elbows and a 4 in nipple each) on the floor. Fix thermocouples T1 to T3 to the wells and T4 to T7 to stainless guide rods, then clamp the setting template on the rim to hold every pipe upright during the fill.
4. **Sand.** Fill in 100 mm lifts to 571 mm, settling each lift around the pipes by rodding. Weigh every bag; the total is 210 kg.
5. **Top and side.** In the headspace, lay 50 mm of AES blanket on the sand and fill the rest with stone wool, cut around the pipes. Lift off the template and fit the lid, ring, collector (riveted to the lid by six tabs) and outlet. Wrap two layers of AES blanket and three of stone wool around the drum. Close the jacket, add the top insulation, the screwed top cap with the outlet trim ring, and the inlet plenum, then connect the ducts.
6. **Electrical.** Drop the heaters into the wells before the top insulation goes on and land their 72 in leads in the junction box on the cap. Wire the enclosure, then have the 240 V circuit connected.
7. **Bake-out.** Check each heater's insulation resistance; it should read 1 MΩ or more at 500 V. Hold the bed at a 150 °C sand mean for 24 h with the collector outlet open and the room ventilated, to drive out moisture and burn off the stone wool binder. Then step to 300 °C and finally 450 °C, logging throughout.

> **Safety:** Respirable crystalline silica. Fill the drum outdoors or with local exhaust, and wear a P100 or N95 respirator while pouring and sieving sand.

> **Safety:** Fiber insulation. AES and stone wool fibers irritate skin, eyes and airways. Wear gloves, long sleeves, eye protection and a respirator while cutting and fitting.

> **Safety:** First firing. Binder burn-off and residual coatings release smoke and odor up to about 350 °C. Keep the space ventilated and occupied only as needed until the bake-out is complete.

## 7. Safety design

The design layers its protection so that no single failure can overheat the unit.

- **Temperature limits.** The ESP32 limits the well walls to 550 °C. The independent limit controller on T3 opens the 2-pole contactor at 600 °C and latches until reset by hand. The heaters are rated to 760 °C, so even a failure of both limits would leave some margin. An SSR that fails shorted is the most likely single failure, and it is covered by the contactor.
- **Electrical.** Dedicated 20 A circuit with a 2-pole 5 mA GFCI breaker, supplementary 10 A fuses per group and a steel enclosure. 30 mA equipment ground-fault protection is used only if the heaters still trip the 5 mA device after bake-out and the installing electrician confirms the code allows it at that location (decided 2026-10-02). The heater junction box on the jacket top stays near room temperature.
- **Surfaces.** The jacket runs at 26 °C at full charge. The hot outlet duct, up to 314 °C, is the only hot part outside the jacket. It is guarded by a perforated steel sleeve and kept 450 mm from combustibles, as for single-wall stovepipe. These siting rules, with the heat trap in the outlet run and the fan below the mixing tee, are requirements an installer must meet (R15, decided 2026-10-02).
- **Warning labels.** Hot-surface and 240 V warning labels go on the jacket, outlet guard, junction box and enclosure (decided 2026-10-02; BOM line 47, USD 15, positions in TBK-BLD-001 step 22).
- **Materials.** No zinc, paint, liner or plastic above 200 °C. The jacket is galvanized, but it runs cold. AES fiber replaces refractory ceramic fiber, which is classed as a possible carcinogen.
- **Structure.** The unit weighs about 415 kg and must stand on a concrete slab; wood floors are not permitted.

> **Safety:** Stored energy. A charged unit stays hot for days after power is removed. Label it, and do not open the lid or pull a heater until the sand mean reads below 60 °C.

## 8. Key design decisions and risks

The choices in Table 4 were proposals by the designer. Amish accepted all of them on 2026-09-25, and they are recorded in design decision record TBK-DDR-002 (`docs/decisions/0002-recommendations-accepted.md`).

| No. | Decision | Alternatives considered | Reason | Status |
| --- | --- | --- | --- | --- |
| D1 | Silica sand, window 150 to 450 °C | Basalt, olivine or soapstone to 600 °C and above | Cost and availability. The window keeps all sand below the 573 °C quartz inversion, and the 150 °C floor is where 1.0 kW output ends. | Decided by Amish, 2026-09-25: go with recommendation |
| D2 | Cartridge heaters in capped wells | Bare nichrome coils buried in sand; electric air heater in a closed air loop | Replaceable from the top without removing sand; heaters isolated from sand and moisture; standard parts | Decided by Amish, 2026-09-25: go with recommendation |
| D3 | Twelve wells of 250 W | Six of 500 W; six of 1-1/2 in; nine of 333 W; twelve of 1 in | Fastest affordable layout: 9.6 h against 15.2 h or more for fewer wells. Twelve 1 in wells reach 8.4 h at higher cost (TBK-CAL-001, Table 9) | Decided by Amish, 2026-09-25: go with recommendation |
| D4 | Closed U-tubes for discharge | Air blown directly through the sand bed | No dust in room air, low pressure drop and no fluidization risk | Decided by Amish, 2026-09-25: go with recommendation |
| D5 | Cold-side damper with a mixing tee and heat trap | Hot-side damper; fan pushing through the bed | Room-temperature damper and fan; convection stopped with no moving parts | Decided by Amish, 2026-09-25: go with recommendation |
| D6 | Wells end at the lid | Wells run through the top insulation | Removes a 94 W thermal bridge | Decided by Amish, 2026-09-25: go with recommendation |
| D7 | AES fiber hot face, stone wool bulk | Refractory ceramic fiber throughout | Handling safety and cost | Decided by Amish, 2026-09-25: go with recommendation |
| D8 | 240 V, 3.0 kW, burst-fire SSRs plus contactor | 120 V at 1.8 kW | Only 240 V can absorb a full sunny day's surplus; the contactor covers SSR failure | Decided by Amish, 2026-09-25: go with recommendation |

*Table 4. Key design decisions.*

The main technical risks are as follows.

- **Thermal ratcheting.** The sand expands while the drum is still cool, then settles into the gap when the drum expands, and the drum may grow a little each cycle. Heating from the core outward helps, and R19 sets a 1 % growth limit to watch. A compressible AES liner inside the drum wall is the fallback if growth appears.
- **Sand conductivity.** If the sand conducts 20 % less heat than assumed, the charge time grows to 12.1 h (TBK-CAL-001, Table 8). The test article will fit the real value.
- **GFCI nuisance trips.** Twelve MgO heaters leak a little current when damp. Bake-out usually cures this. The design specifies a 5 mA GFCI breaker; a 30 mA equipment ground-fault device is a measured exception, used only if the heaters still trip the 5 mA device after bake-out and the installing electrician confirms the code allows it (decided 2026-10-02).
- **Cost.** At $3,869, the parts cost about five times the USD 728 value-engineering target. Heaters, insulation and pipe account for 53 % of it (`bom/bom-notes.md`). The prototype budget now funds the test article, at $727.70 (decided by Amish, 2026-09-25).
- **Charge time.** With standby loss counted, a full charge takes 9.6 h against the 8 h in R3. The options are to cut loss (TBK-CAL-001, Table 5), move to twelve 1 in wells (8.4 h), or relax R3 to 10 h. Decided by Amish, 2026-09-25 (TBK-DDR-002): choose after the test article has measured sand conductivity and loss. That choice is on hold with TRL 4.

## 9. Open questions

- [x] Decide the budget path. Amish decided on 2026-09-24 to build the reduced-scale test article (TBK-PRC-002) first, and on 2026-09-25 set its budget at $727.70 and accepted revisiting the full-scale budget with its results (TBK-DDR-002). Both are on hold with TRL 4.
- [ ] Close the R3 charge-time gap of 1.6 h (section 8, charge time risk). Decided: choose the fix after the test article measures sand conductivity (TBK-DDR-002); on hold with TRL 4.
- [x] Accept 459 W standby loss, or adopt the stainless leg sections and microporous panel (TBK-CAL-001, Table 5). Decided 2026-10-02 (TBK-DEC-001): accept 459 W for now; decide the upgrade together with the R3 charge-time fix once the test article has measured loss.
- [ ] Confirm the fan's pressure curve and speed-control interface against 60 L/s at 150 Pa.
- [ ] Confirm the compressive strength of the stone wool base board on the data sheet (60 kPa or more).
- [x] Choose between a 5 mA GFCI and 30 mA equipment protection with the electrician. Decided 2026-10-02 (TBK-DEC-001): a 2-pole 5 mA GFCI breaker; 30 mA equipment ground-fault protection only if the heaters still trip it after bake-out and the installing electrician confirms the code allows it at that location.
- [ ] Controller schematic, firmware and test plan TBK-TST-001: drafted for the test article in an earlier session and archived under `archive/out-of-phase-trl4/`; on hold with TRL 4.
- [x] Review proposals D1 to D8. Accepted by Amish on 2026-09-25 and recorded in TBK-DDR-002.

## 10. Deliverables in this revision

| Item | Location |
| --- | --- |
| Problem statement v0.2 | `docs/01-problem.md` (TBK-PRB-001) |
| Requirements v0.2 | `docs/03-requirements.md` (TBK-REQ-001) |
| Sizing calculation v0.2 and script | `docs/04-calcs/` (TBK-CAL-001) |
| Test article precis, sizing, drawing and BOM (archived, on hold with TRL 4) | TBK-PRC-002, TBK-CAL-002, TBK-DWG-002, `bom/bom-test-article.csv`, all under `archive/out-of-phase-trl4/` |
| Parametric model | `cad/src/model.py`; exports in `cad/step/` and `cad/stl/` |
| General arrangement, Rev P2 | `cad/drawings/TBK-DWG-001` (SVG, PDF, PNG), built by `cad/src/sheets.py` |
| Bill of materials | `bom/bom.csv` and `bom/bom-notes.md` |

*Table 5. Deliverables of the v0.2 draft.*

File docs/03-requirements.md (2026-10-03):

---
doc_id: TBK-REQ-001
title: ThermaBrick requirements
project: ThermaBrick
doc_type: Requirements
version: "0.12"
status: Draft
date: '2026-10-02'
author: Amish Chadha
license: CERN-OHL-S-2.0
revisions:
- version: "0.1"
  date: '2026-09-24'
  author: Amish Chadha
  change: Initial scaffold
- version: "0.2"
  date: '2026-09-24'
  author: Amish Chadha
  change: Defined 20 requirements with targets, verification methods and v0.2 compliance status traced to TBK-CAL-001
- version: "0.3"
  date: '2026-09-24'
  author: Amish Chadha
  change: Updated R3, R4 and R5 status for standby loss (TBK-CAL-001 v0.2), so R3 is now not met; R20 notes the $600 reduced-scale test article
- version: "0.4"
  date: '2026-09-24'
  author: Amish Chadha
  change: R20 test article estimate updated to $599.70 after adding the pull-down resistors
- version: "0.5"
  date: '2026-09-24'
  author: Amish Chadha
  change: R20 test article estimate updated to $635.70 after the controller enclosure fit check (TBK-DWG-005)
- version: "0.6"
  date: '2026-09-24'
  author: Amish Chadha
  change: R20 records the decision to accept the test article at $635.70
- version: "0.7"
  date: '2026-09-24'
  author: Amish Chadha
  change: R20 test article budget updated to $727.70 after the build procedure's additions
- version: "0.8"
  date: '2026-09-24'
  author: Amish Chadha
  change: 'Review pass: R20 shows $727.70 as the BOM total, proposed and awaiting Amish; the accepted budget remains $635.70'
- version: "0.9"
  date: '2026-09-25'
  author: Amish Chadha
  change: Recommendations accepted by Amish (DDR-002)
- version: "0.10"
  date: '2026-10-01'
  author: Amish Chadha
  change: 'Design made constructable (TBK-DDR-003). R15 at 415 kg; R20 full-scale estimate $3,854 reported against the value-engineering target; R13 and R17 notes for the outlet trim ring and the screwed jacket cap'
- version: "0.11"
  date: '2026-10-02'
  author: Amish Chadha
  change: 'Decisions of 2026-10-02 (TBK-DEC-001): R11 names the 5 mA GFCI breaker and the condition for 30 mA protection; R15 adds the siting rules as installer requirements. No status changed'
- version: "0.12"
  date: '2026-10-02'
  author: Amish Chadha
  change: 'R20 full-scale estimate $3,869 (warning labels, BOM line 47); no status changed'
---

# ThermaBrick requirements

The v0.2 design meets 16 of the 20 requirements below, by analysis, inspection or design. Three depend on firmware or on testing that has not yet been done (R12, R18 and R19). One is not met: charge time (R3) misses by 1.6 h once standby loss is counted. Amish accepted the recommendation to choose how to close R3 only after the test article has measured sand conductivity, so R3 stays open while TRL 4 is on hold (TBK-DDR-002). R20 is restated to match the budget decisions: the prototype budget covers the reduced-scale test article, set at $727.70 by Amish on 2026-09-25, and the full-scale estimate is reported against it. The targets of R1 to R20 were accepted by Amish on 2026-09-25 (TBK-DDR-002). Every requirement will be confirmed by test on the first build.

Verification methods are analysis (A), inspection (I), demonstration (D) and test (T). Status reflects the v0.2 analysis in TBK-CAL-001 and the BOM. "Met (A)" means shown by analysis and not yet tested.

## 1. Performance

| ID | Requirement | Target | Verification | v0.2 status |
| --- | --- | --- | --- | --- |
| R1 | Stored heat between 150 °C and 450 °C energy-weighted mean sand temperature | 18 kWh(th) or more | A: TBK-CAL-001 section 2. T: calorimetric discharge (air flow and temperature rise) | Met (A): 18.3 kWh(th) |
| R2 | Charge power drawn only from PV surplus, following export in real time | 0 to 3.0 kW in steps of 25 W or finer; grid import from charging 50 Wh per day or less | D: log export meter and heater power through three sunny days | Met by design |
| R3 | Charge acceptance from empty with full surplus available | 11 kWh or more in 4 h; full in 8 h or less | A: TBK-CAL-001 section 3. T: charge from 150 °C at 3.0 kW | **Not met (A):** 10.9 kWh in 4 h, full in 9.6 h. The fix is chosen after the test article measures sand conductivity (TBK-DDR-002); on hold with TRL 4 |
| R4 | Rated heat output | 1.0 kW held down to 170 °C sand mean or lower | A: TBK-CAL-001 section 4. T: discharge at 1.0 kW demand | Met (A): held 14.3 h, to 154 °C |
| R5 | Boost heat output | 1.5 kW for 8 h or more from full | A: TBK-CAL-001 section 4. T | Met (A): 8.1 h |
| R6 | Supply air temperature at the register | 55 °C or below at all times | T: log supply air through charge and discharge | Met by design (50 °C setpoint) |
| R7 | Standby loss | 500 W or less at full charge; 9 kWh or less over 24 h idle from full | A: TBK-CAL-001 section 5. T: 24 h cool-down from full | Met (A): 459 W; 8.7 kWh |

## 2. Safety

| ID | Requirement | Target | Verification | v0.2 status |
| --- | --- | --- | --- | --- |
| R8 | Peak temperatures | Sand and well wall 550 °C or below; heater sheath 700 °C or below; drum wall 500 °C or below | A: TBK-CAL-001 section 3. T: well-wall and sand thermocouples, plus a temporary drum-wall thermocouple beside a ring B well | Met (A): 550 °C, 634 °C and about 480 °C |
| R9 | Accessible surface temperature at full charge, 20 °C room | 45 °C or below on the jacket; hot outlet duct guarded | A: TBK-CAL-001 section 5. T: surface survey with a contact probe | Met (A): 26 °C side |
| R10 | Independent over-temperature protection | Hardware limit, separate from the ESP32, opens a 2-pole contactor at 600 °C well-wall temperature and latches until manually reset | I: wiring against the schematic. T: trip test with a heated thermocouple | Met by design |
| R11 | Electrical supply and protection | Dedicated 240 V, 20 A circuit with a 2-pole 5 mA GFCI breaker (30 mA equipment ground-fault protection only if the heaters still trip it after bake-out and the installing electrician confirms the code allows it; TBK-DEC-001, 2026-10-02); continuous current 16 A or less; supplementary fuses per heater group | A: TBK-CAL-001 section 6. I | Met (A): 12.5 A |
| R12 | Fail-safe behavior | On controller reset, loss of Wi-Fi, a sensor fault or a fan fault: heaters off, inlet damper closed | D: fault injection for each case | Firmware to be written |
| R13 | Materials in hot zones | No zinc, paint, liner or plastic above 200 °C; AES (body-soluble) fiber in place of refractory ceramic fiber | I: against the BOM | Met by design. The hot outlet passes the galvanized jacket cap in a 180 mm hole packed with AES and covered by a black steel trim ring, so no zinc sits within 39 mm of it (TBK-DDR-003) |

## 3. Physical and installation

| ID | Requirement | Target | Verification | v0.2 status |
| --- | --- | --- | --- | --- |
| R14 | Envelope | 1,250 mm diameter or less; 1,500 mm high or less, including ducts | I: CAD and as-built | Met: 1,209 mm by 1,462 mm |
| R15 | Siting and floor load | Indoors, inside the heated space, on a concrete slab; 450 kg or less in service. Installer rules (TBK-DEC-001, 2026-10-02): the hot outlet duct is kept 450 mm from combustibles and guarded by a perforated steel sleeve, the outlet run forms a heat trap, and the fan sits below the mixing tee | A: TBK-CAL-001 section 7 | Met (A): 415 kg (TBK-CAL-001 v0.3); the installer rules are checked at installation |
| R16 | Buildability | No welding, machining or pressure parts; hand tools, a pipe threader and pop rivets only | I: build log | Met by design |
| R17 | Serviceability | Any heater replaceable from the top without removing sand | D: replace one heater | Met by design: heaters sit in wells; the jacket cap is screwed, not riveted, so it and the top insulation lift off to reach them (TBK-DDR-003) |

## 4. Controls, openness and cost

| ID | Requirement | Target | Verification | v0.2 status |
| --- | --- | --- | --- | --- |
| R18 | Monitoring | Log all temperatures, heater power and export at 10 s intervals; report state of charge within 10 % of the calorimetric value | T: compare against R1 test | Firmware to be written |
| R19 | Durability | 1,000 charge cycles without drum growth over 1 % in circumference or loss of heater function | T: measure drum circumference every 25 cycles | Open: sand ratcheting risk, see TBK-PRC-001 section 8 |
| R20 | Prototype cost | Reduced-scale test article (TBK-PRC-002, archived): $727.70 USD or less in parts, decided by Amish on 2026-09-25 (TBK-DDR-002). Full-scale parts cost estimated and reported; its budget is revisited with the test article's results | I: against the BOMs | Met (I): test article BOM $727.70 (archived, on hold with TRL 4). Full-scale estimate of the constructable design $3,869 reported, USD 3,141 over the USD 728 value-engineering target; revisit on hold with TRL 4 |

## 5. Traceability

The requirements trace to TBK-PRB-001 as follows: R1 to R7 to section 4 (success measures); R8 to R13 to section 3 (safety constraint); R14 to R17 to section 3 (buildability and siting); R18 to section 4 (reproducibility); R20 to section 3 (budget). R19 comes from the ratcheting risk identified in the design precis.

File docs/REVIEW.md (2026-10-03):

# ThermaBrick review, September 2026

Prepared for Amish's review on 2026-09-24. It covers everything built since the v0.2 draft (commit `982233a`), every decision recorded on Amish's behalf, and every open issue. Nothing in this review adds scope.

**Where things stand.** The full-scale design is complete as a draft, but it misses its charge-time requirement (R3) by 1.6 h and loses 47 % of its stored heat in a day of standing. The reduced-scale test article is fully documented, from purchasing to the test report template, and none of it has been built or tested. Its BOM now totals $727.70. Amish accepted $635.70; the rise to $727.70 is proposed and awaits Amish's decision.

## 1. What was built since v0.2

| Commit | Work | Verified by | Not verified |
| --- | --- | --- | --- |
| `b575702` | Test article design: TBK-PRC-002, TBK-CAL-002, TBK-DWG-002, `cad/src/test_article.py`, `bom/bom-test-article.csv`. Corrected TBK-CAL-001 to v0.2 (see section 4) | CAD solids valid; sand mass checked in CAD within 0.4 % | Nothing built |
| `9823c32` | Test plan TBK-TST-001 (TP0 to TP6) | Renderer check | Not run |
| `9628cf2` | ESP32 firmware and logging host (`firmware/`) | 14 host unit tests pass; compiles for ESP32 with no warnings; logger checked against a mock controller | Never run on an ESP32 |
| `2c9b262` | Analysis script `docs/05-tests/tbk_tst_001_fit.py` | Synthetic self-test recovers known values (two seeds) | No real data yet |
| `a5ae50d` | Controller schematic TBK-DWG-003, generated from `electronics/src/schematic.py` | KiCad ERC 0 errors, 0 warnings; all 36 nets checked against the netlist | Not wired |
| `b37fd78` | Optional controller board TBK-DWG-004, gerbers | KiCad DRC 0 errors, 0 warnings, 0 unconnected, schematic parity clean | Not fabricated; now deferred |
| `412cf5d` | Controller enclosure model TBK-DWG-005; schematic to Rev P2 (DIN-rail supply) | Fit check at 3 mm clearance, including three deliberate faults it caught | Part envelopes from supplier listings, not measured |
| `24cfbd1` | Recorded Amish's decision to accept $635.70 | | |
| `08a839f` | Purchasing checklist, generated from the BOM | Totals match the BOM | Prices are estimates, not quotes |
| `a4b95ba` | Build procedure and generated cut list (`docs/07-build/`); TBK-DWG-002 to Rev P2; four BOM additions | Cut list generated from the models and schematic | Not used on a build |
| `45bdd0f` | Build log template and entry helper | Helper tested on a scratch copy | No entries yet |
| `d8c6256` | Test report template TBK-TST-002 and fill script | Dry run on self-test results | No real data yet |

*Table 1. Work since v0.2.*

**Software installed on this machine for this work:**

- through Homebrew: `uv`, `pango` and `cairo`;
- as a `uv` tool: PlatformIO;
- a Python environment at `~/.venvs/ohp-kit`.

The KiCad install failed because the Homebrew package needs an administrator password. KiCad is running from the downloaded disk image, mounted at `/Volumes/KiCad` until the next restart.

## 2. Decisions

### 2.1 Made by Amish

| Decision | Date |
| --- | --- |
| Develop ThermaBrick to a v0.2 draft | 2026-09-24 |
| Build the 6 kWh reduced-scale test article, within $600 | 2026-09-24 |
| Budget option 1: accept the test article at $635.70, all parts at once | 2026-09-24 |
| Add the four items the build procedure found to the BOM | 2026-09-24 |
| Commit and push each step to `main` | 2026-09-24 |

*Table 2. Decisions made explicitly by Amish.*

### 2.2 Recorded on Amish's behalf, now returned to "proposed, awaiting Amish"

| Item | Where it was recorded as accepted | Now |
| --- | --- | --- |
| Test article budget of $727.70 | TBK-PRB-001, TBK-REQ-001 R20, TBK-PRC-002, BOM notes, purchasing checklist, README, `project.yaml` (budget 728) | Proposed, awaiting Amish at the time. Decided by Amish, 2026-09-25: go with recommendation ($727.70; `project.yaml` 728; TBK-DDR-002) |
| Full-scale design decisions D1 to D8 | TBK-PRC-001, Table 4 | Each marked "Proposed, awaiting Amish" at the time. Decided by Amish, 2026-09-25: go with recommendation (TBK-DDR-002) |

*Table 3. Items reverted in this pass.*

### 2.3 Design choices never reviewed

These were never labeled as accepted when this review was written. Decided by Amish, 2026-09-25: go with recommendation (TBK-DDR-002, items A4 to A11); the test article, enclosure, firmware, test plan and board items are on hold with TRL 4.

- **Storage window:** 150 °C to 450 °C, with a 550 °C well-wall limit for the quartz inversion margin.
- **Full scale:** twelve 250 W heater wells, 1-1/4 in U-tubes, and 50 mm AES blanket plus 267 mm stone wool.
- **Test article scale and cuts:** a 16 US gal drum, 68 kg of sand, four heater cells, one U-tube, 120 V plug-in, stone wool as the hot face, and a 12 V blower with a dilution stack.
- **Controller enclosure:** 250 × 200 × 150 mm polycarbonate, with a DIN-rail Mean Well HDR-15-12, a DPDT JQX-30F relay, a REX-C100 as the independent limit, and ungrounded thermocouples.
- **Firmware safety rules:** heaters stay off until the logging host connects; any fault switches the heater mode off; T1 trips at 575 °C and the sand at 560 °C.
- **Test plan:** the pass criteria and tolerances in TBK-TST-001, and the fitted power correction in its analysis.
- **Requirements:** the targets for R1 to R20 in TBK-REQ-001, including R8's 500 °C drum-wall limit.
- **Optional controller board:** its circuit choices (R-78E regulator, IRLZ44N, 2N3904).

## 3. Open issues

1. **Charge time misses R3.** With standby loss included, the full-scale unit fills in 9.6 h against the 8 h target, and stores 10.9 kWh in 4 h against 11 kWh (TBK-CAL-001 v0.2). If the sand conducts 20 % less than assumed, the fill takes 12.1 h. There are three options (TBK-PRC-001, section 8): cut the loss, use twelve 1 in wells (8.4 h), or relax R3 to 10 h. The test article is meant to measure the sand conductivity before a choice is made.
2. **Standby loss is 47 % of the stored heat per day.**
   - **Full scale:** loses 459 W at full charge, or 8.65 kWh over 24 h idle, 47 % of the 18.3 kWh window.
   - **Test article:** loses 249 W, 69 % in 24 h.
   - **Where it goes:** the heat is released into the room, so the unit must stand inside the heated space, but it cannot be switched off.
   - **Options:** stainless upper inlet legs and a microporous hot face would bring the full-scale loss to 357 W (7.1 kWh per day) for about $450 (TBK-CAL-001, Table 5).
   - **Decision needed:** whether the loss is acceptable is an open decision in TBK-PRB-001.
3. **The test article budget has risen from $600 to $727.70.** Every step came from correcting a real gap, not from added features:

   | Stage | Total |
   | --- | --- |
   | First estimate | $599.50 |
   | Pull-down resistors added | $599.70 |
   | Enclosure fit check, which replaced a $10 enclosure too shallow for the REX-C100 and a barrel-jack supply, and added glands, DIN rail and connectors | $635.70, accepted by Amish |
   | Build procedure: second stone wool pack, heater cable, wiring consumables, thermocouple extension | $727.70, proposed |

   The optional board would take it to $752.55. The full-scale BOM is $3,673.50, about six times the original $600 target.
4. **The full-scale CAD model had one invalid solid. Fixed after this review was written, at Amish's request.** The U-tube at 270° failed the BRep validity check, because building each tube at its own angle let near-zero sine and cosine terms defeat the boolean. The model now builds one U-tube along +X and rotates copies into place. All six tubes are valid and identical (935.34 cm³), the assembly is valid, and the re-exported STEP reads back as 47 valid solids. The design geometry is unchanged. The regenerated TBK-DWG-001 differed from the committed sheet by one pixel in 2.26 million, so the sheet was not reissued.
5. **TRL is not recorded.** Section 9 of the standard is in the newer kit (1.1.x) used by the other portfolio repos. ThermaBrick still runs kit 1.0.0, which has no section 9, and its `render.py --check` does not check TRL. The TRL 3 evidence is otherwise complete:
   - calculation notes TBK-CAL-001 and TBK-CAL-002;
   - the build123d model and its STEP export;
   - drawing sheets TBK-DWG-001 to TBK-DWG-005;
   - fully priced BOMs, with no empty unit cost in 89 lines.

   When this review was written, the invalid solid in item 4 meant the "working model" condition was not fully met, so `trl`, `trl_target` and `trl_evidence` were not added to `project.yaml`. With item 4 fixed, the TRL 3 evidence is complete. **Update after the review:** at Amish's request the kit was synced to 1.1.4 and `trl: 3` recorded, with the build log entry `build-log/2026-09-24-trl-3-recorded.md`. **Second update:** at Amish's request the kit was then synced to 1.2.0 (option A): `trl_target` is now 3 under the portfolio cap in `.kit/PHASE.yaml`, and the required concept media are generated in `media/` by `cad/src/concept_media.py` (concept sheet TBK-DWG-006 Rev P1). Recorded in `build-log/2026-09-24-kit-1-2-0.md`. The 1.2.0 check warns that the test article work is beyond the TRL 3 cap; it is kept and not extended. The 1.1.4 check would also pass an unsupported `trl: 4` here, because it counts the test plan and the build log's `README.md` and `TEMPLATE.md` as TRL 4 evidence. That weakness belongs in the kit source. Section 9 also requires every change of TRL to be recorded in the build log. That would be a new entry, which this pass does not create.
6. **Nothing physical has been verified.** Specifically:
   - **Prices:** estimates from US list prices, not quotes.
   - **Heaters:** made-to-order imports with a two to four week lead time and untested quality.
   - **SSR:** counterfeits are common.
   - **Blower:** its curve is assumed.
   - **Enclosure parts:** sized from supplier listings, not measured.
   - **Firmware:** never run on an ESP32.
   - **Controller board:** never fabricated.
7. **Design risks carried forward:**
   - sand ratcheting and drum growth (R19);
   - GFCI nuisance trips from the MgO heaters;
   - a drum-wall hot spot of about 480 °C beside the outer wells, estimated but not resolved by the 1D model;
   - stone wool used at a 450 °C hot face in the test article, which burns off its binder;
   - the full-scale AES blanket, which the test article does not test.
8. **Model limitations.** The radial cell model treats each pipe's share of sand as a circle, spreads the standby loss evenly, and lumps axial effects. The fit intervals are optimistic. The TP5 self-test checks the code path, not the physics.
9. **Documentation gaps:**
   - D1 to D8 are not yet design decision records.
   - TBK-TST-002 is an empty template.
   - `project.yaml` still says `status: concept`.
   - Nothing has been tagged or released.
10. **Tooling:** KiCad needs a proper install before any schematic or board can be regenerated after a restart:

    ```bash
    brew install --cask kicad
    ```

## 4. Errors found and corrected along the way

| Error | Found by | Correction |
| --- | --- | --- |
| TBK-CAL-001 v0.1 left standby loss out of the charge and discharge runs. It claimed a 7.9 h charge and 1.0 kW for 18 h | Test article sizing | CAL-001 v0.2: 9.6 h and 14.3 h; R3 marked not met |
| Test article thermocouples left too low: tips at 245 mm would put the 500 mm probes' lead junctions in the hot insulation | Build procedure | Tips at 300 mm (TBK-TST-001 v0.4) |
| Wells listed as 717 mm long | Cut list | 692 mm (667 mm finished plus 25 mm crimp) |
| Base bricks overlapped at the drum center in the model | Cut list | Moved under the chime (TBK-DWG-002 Rev P2) |
| U-tube legs modeled 80 mm above the jacket; the shortest stock nipple that reaches gives 152 mm | Cut list | Model and TBK-DWG-002 Rev P2 |
| Enclosure 100 mm deep, which cannot take the REX-C100 | Enclosure fit check | 250 × 200 × 150 mm |
| 12 V supply specified as a barrel-jack adapter | Enclosure model | DIN-rail HDR-15-12; TBK-DWG-003 Rev P2 |
| Relay not specified as double pole; pull-downs missing from the BOM; earth bonding unspecified | Schematic | BOM and TBK-PRC-002 corrected |
| Glands, DIN rail, connectors, earth stud, second insulation pack, heater cable, wiring consumables and thermocouple extension missing from the BOM | Enclosure model and build procedure | Added |
| Grounded-junction thermocouples not excluded, which risked a ground loop | Purchasing checklist | Specified as ungrounded |
| This review's first commit (`b2bc80a`) pushed four revision rows whose unquoted "Review pass:" text broke the YAML front matter; a piped command hid the failing check | Re-running the check with its exit status | Rows quoted and PDFs rendered in the following commit |

*Table 4. Errors and corrections.*

## 5. Changed in this review pass

- **This document:** added as `docs/REVIEW-2026-09.md`; renamed `docs/REVIEW.md` at Amish's request on 2026-09-24, as kit 1.2.0 expects.
- **Budget:** $727.70 returned to proposed in TBK-PRB-001 (v0.7), TBK-REQ-001 (v0.8), TBK-PRC-002 (v0.11), the BOM notes, the purchasing checklist, the README, and `project.yaml` (budget back to 636).
- **Design decisions:** D1 to D8 in TBK-PRC-001 (v0.4) marked "Proposed, awaiting Amish".
- **Controller board:** marked optional and deferred in TBK-PRC-002, the README, the BOM notes, the purchasing checklist and `electronics/README.md`.
- **Attribution:** the two decisions Amish made are now attributed to Amish by name.
- **TRL:** not added (section 3, item 5).

## 6. Awaiting Amish

1. Accept, cut or reject the $727.70 test article budget. Decided by Amish, 2026-09-25: go with recommendation ($727.70; on hold with TRL 4).
2. Review design proposals D1 to D8 and the unreviewed choices in section 2.3. Decided by Amish, 2026-09-25: go with recommendation (TBK-DDR-002).
3. Choose a path on the R3 charge-time miss, or wait for the test article's measurements. Decided by Amish, 2026-09-25: go with recommendation (wait for the test article's measurements; on hold with TRL 4).
4. Decide whether 47 % daily standby loss is acceptable, or adopt the loss-reduction options. No recommendation made; still proposed, awaiting Amish.
5. Confirm the controller board stays deferred. Decided by Amish, 2026-09-25: go with recommendation (deferred; archived).
6. Done after the review: the U-tube solid is fixed, TRL 3 is recorded, and the kit is on 1.3.1 with `trl_target: 3`.
7. Install KiCad properly. Decided by Amish, 2026-09-25: go with recommendation; on hold with TRL 4, since the electronics are archived.
8. Done: renamed to `docs/REVIEW.md` at Amish's request, as kit 1.2.0 expects.

## 7. Log

- 2026-09-24: kit synced to 1.3.0 at Amish's request. Concept media regenerated with a scale figure, a 3D viewer (`media/model.glb`, `media/viewer.html`) and a heat flow diagram (`media/flow.png`, TBK-CAL-001 estimates); TBK-DWG-006 reissued at Rev P2. Recorded in `build-log/2026-09-24-kit-1-3-0.md`.
- 2026-09-24: kit synced to 1.3.1 at Amish's request. Only `media/flow.png` changed (new layout, same values). Recorded in `build-log/2026-09-24-kit-1-3-1.md`.

## Session 2026-09-25: rein-in to TRL 3

Done at Amish's instruction ("yes" to the rein-in recommendation, 2026-09-25). TRL 4 is on hold for the whole portfolio.

**What was done**

- Moved all TRL 4 material to [archive/out-of-phase-trl4/](../archive/out-of-phase-trl4/README.md) with `git mv`, keeping history and deleting nothing: the test article precis, sizing, drawings, models and BOMs; test plan and report template; build procedure and cut list; KiCad schematic, controller board and Gerbers; firmware and logging host; purchasing checklist; build-log template and helper.
- `cad/src/sheets.py` now builds TBK-DWG-001 only. The archived copy builds the test article and enclosure sheets.
- README: links to archived items removed and an archive note added.
- `project.yaml`: `trl: 3`, `trl_target: 3` unchanged. The `trl_evidence` list already pointed only at TRL 3 files (TBK-CAL-001, the model, STEP, TBK-DWG-001, `bom/bom.csv`).

**Decisions**

- Unchanged and still Amish's: develop to a v0.2 draft; the test article budget of $635.70. That budget now applies to archived work and is on hold.
- Still "Proposed, awaiting Amish" at the time: the $727.70 test article budget; full-scale design decisions D1 to D8; the design choices in section 2.3. All three decided by Amish, 2026-09-25: go with recommendation (see the session below).

**Still open at TRL 3** (from section 3): R3 charge time (9.6 h against 8 h); 47 % standby loss per day; the full-scale budget ($3,674 against the $600 concept figure); design decision records for D1 to D8.

**Recommended next step.** Decide D1 to D8 and how to close R3 and the standby loss, all on paper. TRL 4 stays on hold; when it is lifted, the archived test article is the starting point.

## Session 2026-09-25: recommendations accepted

On 2026-09-25 Amish wrote: "i accept all your recommendations, go with them across all repos." Every item with a recommendation is now decided by Amish, 2026-09-25: go with recommendation. The full list is in [TBK-DDR-002](decisions/0002-recommendations-accepted.md).

**Decisions applied and what changed**

| Decision | Before | After |
| --- | --- | --- |
| Test article budget | $635.70 accepted; $727.70 proposed | $727.70 decided; on hold with TRL 4 |
| `project.yaml` `budget_usd` | 636 | 728 |
| R20 prototype cost | "About $600 USD in parts"; not met | Restated to the test article budget of $727.70 or less, full-scale cost reported; met (I) for the test article BOM ($727.70). Full-scale estimate unchanged at $3,674 |
| D1 to D8 (TBK-PRC-001, Table 4) | Proposed, awaiting Amish | Decided; TBK-DDR-002 is their design decision record |
| Section 2.3 design choices and R1 to R20 targets | Unreviewed proposals | Decided; test article, enclosure, firmware, test plan and board items on hold with TRL 4 |
| R3 charge-time path | Open | Decided: choose the fix after the test article measures sand conductivity; on hold with TRL 4. R3 stays not met (9.6 h against 8 h) |
| Full-scale budget | Revisit proposed | Revisit with test results decided; on hold with TRL 4 |
| Controller board | Deferred, to be confirmed | Kept deferred (archived) |
| KiCad install | Awaiting Amish | Decided; on hold with TRL 4 |

*Table 5. Decisions applied on 2026-09-25.*

No geometry, BOM line or calculation changed, because the full-scale design already embodied D1 to D8. `cad/src/model.py`, TBK-DWG-001 (Rev P1), TBK-CAL-001 (v0.2) and the concept media were regenerated only to refresh the footer, which now points to designmolecule.com.

Controlled documents changed: TBK-PRB-001 0.7 to 0.8; TBK-PRC-001 0.4 to 0.5; TBK-REQ-001 0.8 to 0.9; TBK-DDR-002 0.1 new. Also changed: `project.yaml`, `README.md` (budget line, hero image and links line, links to archived files corrected, and new sections "Concept rationale", "Burning platform", "Where it could be used" and "What sparked the idea"), and `bom/bom-notes.md`.

**Requirement status now (TBK-REQ-001 v0.9)**

- Not met (1): R3 charge time, 10.9 kWh in 4 h and full in 9.6 h against 11 kWh and 8 h.
- Open (3): R12 fail-safe behavior and R18 monitoring (firmware; archived and on hold), R19 durability (ratcheting, needs test).
- Met (16): R1, R2, R4 to R11, R13 to R17 and R20, by analysis, inspection or design; none tested.

**Still awaiting Amish** (no recommendation was made)

- Standby loss: accept 459 W at full charge (8.7 kWh, 47 % of the window, per day idle), or adopt the Table 5 options in TBK-CAL-001 (357 W for about $450).
- GFCI choice: 5 mA GFCI or 30 mA equipment protection, with the installing electrician.

**Cross-repo actions:** none.

**TRL.** `trl: 3` and `trl_target: 3` are unchanged. TRL 4 remains on hold by Amish's instruction: nothing was built, bought, tested or measured, and `archive/out-of-phase-trl4/` was not touched.

## Session 2026-09-26: sources strengthened

README "Where it could be used" and "What sparked the idea", per Amish's instruction of 2026-09-26 ("Fix the weaker sources"). Every link below was fetched and checked against the claim it supports.

| Item | Old source | New source |
| --- | --- | --- |
| United States (California) row, tariff claim | None | California Public Utilities Commission, "Net Energy Metering and Net Billing" (Net Billing Tariff from April 15, 2023, Decision D.22-12-056); US EIA curtailment link rechecked and kept |
| United States (Colorado and the Mountain West) row | None | Row removed; no credible source found for the climate claim within this session's search budget |
| Finland row | Wikipedia, "Thermal energy storage" (alone) | Polar Night Energy, "What is a Sand Battery?", with UNRIC alongside |
| Australia row | None | Clean Energy Council rooftop solar report, September 15, 2025, and SA Power Networks on AEMO-directed curtailment; the uncited "export limits common" and "cool winters" claims were dropped |
| Northern China row | None | Rewritten as "China" to state only what the IEA reports (*Renewables 2023*, Heat) |
| Ladakh, India row | None | Replaced by "Mongolia (Ulaanbaatar)": World Bank feature, June 26, 2018 (coal stoves, winter PM2.5 above 100 times the WHO 24-hour guideline) |
| What sparked the idea | Wikipedia, "Thermal energy storage" | Polar Night Energy, "World's first Sand Battery" and "What is a Sand Battery?"; UNRIC, "Sand warms up the Finnish polar night" |

Corrections from the primary source: the Kankaanpää unit is 200 kW and 8 MWh per Polar Night Energy, not the 0.1 MW that Wikipedia gave (UNRIC also gives 100 kW; the company figure is used). The "up to 600 °C" claim is now attributed to UNRIC (500 to 600 °C storage). The inspiration event is unchanged; its line in `INSPIRATIONS.md` was updated to the new sources. No controlled document changed; TBK-PRB-001 had no link to the weak source.

## Session 2026-09-26: product appearance model and photoreal renders

Amish chose this repo for the first batch of product renders on 2026-09-26. This session added `cad/src/product_model.py`, an appearance model for photoreal renders, and pointed the README hero at `media/render-hero.png` with a link to `media/render-exploded.png`. The render files are produced later by the orchestrator. No existing model, BOM, drawing or controlled document was changed.

**What `product_model.py` adds**

- `product_parts()`: 80 named parts (18 shell, 13 internal, 44 accessory, 5 context), each with colour, material, BOM line, group and explode offset; `TITLE` and three `RENDER_VIEWS` (hero, exploded, detail).
- Jacket finish: three lapped rows with riveted seams, a vertical lap seam, a teal top trim ring, a dark kick plinth, a name plate, and HOT SURFACES INSIDE and HOT OUTLET warning labels.
- An 80 deg cut sector at the front through the jacket, stone wool, AES blanket, drum, sand and base, showing the sand bed, two heater wells split open with lit cartridge heaters and their beaded leads, a U-tube, and the three base layers (stone wool board, insulating firebrick with joints, AES board).
- Inlet damper with its servo, intake bell mouth and grille on the plenum collar; heater junction box with lid, screws, gland and a DANGER 240 V label.
- Hot outlet duct as 4 in black stovepipe that rises and turns down as a heat trap, in a perforated guard sleeve with a HOT SURFACE label; mixing tee with the balancing damper and room-air grille; EC inline fan with collars, accent ring, rating label and lit run light, on a wall bracket; ribbed insulated flexible supply duct into a wall collar.
- Wall-mounted control enclosure with door, hinges, latch, name plate, 1/16 DIN high-limit readout (lit), charge, discharge and fault lights (charge lit) and a DANGER 240 V label.
- Context: a compact slab floor patch, a back wall patch, surface conduit and straps.

**Where the appearance model differs from `model.py`** (each one Proposed, awaiting Amish)

1. *Cut sector.* The renders remove an 80 deg sector (268 to 345 deg) to show the inside, and the two wells in it are split open. Recommendation: keep it for the hero and detail renders only; the drawings and STEP stay whole.
2. *Duct, fan and enclosure layout.* `model.py` ends at the 4 in outlet stub and the inlet collar. The route of the hot duct (toward 35 deg, drop at 800 mm radius, tee at 1,150 mm), the fan position and bracket, the supply duct into the back wall, the junction box position (120 deg, 430 mm radius) and the enclosure position on the wall are an appearance layout only. Recommendation: treat it as illustrative; add it to TBK-DWG-001 only if Amish wants an installation layout sheet.
3. *Sizes not in the design.* The fan body (236 mm diameter by 230 mm), guard sleeve (about 160 mm diameter), intake bell mouth and grille, and the room-air grille are assumed for appearance. Recommendation: accept as placeholders until the fan is chosen (open question on its pressure curve).
4. *Cosmetic items not in the BOM.* The teal top trim ring, kick plinth, name plates and warning labels have no BOM lines. Recommendation: add one BOM line for warning and rating labels, since hot-surface and 240 V labels are a safety item; treat the trim ring and plinth as optional cosmetic parts.
5. *Insulation split.* `model.py` draws all insulation as one body; the appearance model splits it into the AES hot face and the stone wool by the thicknesses in PARAMS. No dimension changes.

**TRL.** This is an appearance model only: no tolerances, fabrication detail, PCB layout or firmware. `trl: 3` and `trl_target: 3` are unchanged, and TRL 4 remains on hold by Amish's instruction.

## Session 2026-09-27: kit 1.5.0 and image quality

- Kit 1.5.0 synced: STANDARDS v1.5 (sections 12 to 15: product renders, storefront images and image quality, public release, authorship and signing), `.kit/cards.py`, `.kit/image_qc.py`, `.kit/release_gate.py`, issue templates, and the `/render-product` and `/release` commands. `CLAUDE.md` now matches `.kit/CLAUDE.md`.
- Every `media/render-*.png` recaptioned from its original render with the new layout: the title, concept label and repository sit in a band above the render and the view note in a band below it, each line wrapped to the image width, so no text overlaps other text or the render or runs off the image. `media/card.png` and `media/social-preview.png` regenerated with the same rules.
- `python .kit/image_qc.py` and `python .kit/release_gate.py` pass. trl stays 3.

## Session 2026-10-01: kit 1.7.0, design for construction and the prototype build plan

Kit 1.7.0 installed (`.kit/`, `.claude/commands/`, `CLAUDE.md` from `.kit/CLAUDE.md`). Following `/build-plan` and `.kit/STANDARDS.md` section 18, the model was reviewed for constructability with build123d checks, made physically buildable under Amish's 2026-09-30 instruction ("fix the design assumptions to match and be physically feasible"), and the illustrated build plan and the design decisions register were written. `design_state: constructable` is set in `project.yaml`. Nothing was built, bought or tested; TRL stays 3.

**Design changes made for construction** (TBK-DDR-003, Draft, open for Amish's review)

1. Heater wells stand on a levelled 14 mm first lift of sand at their concept height (they hung unsupported); cut length 876 mm (the BOM said 906 mm).
2. U-tubes: two elbows and a 1-1/4 x 4 in nipple (the 2-1/2 in nipple gave 118 mm leg spacing, not 155 mm), elbows resting on the drum floor; leg cut lengths 1,175 and 866 mm.
3. Lid holes 36 mm (wells, with room for the T1 to T3 sheaths) and 48 mm (legs), four 6 mm holes for T4 to T7, AES rope collars.
4. Plywood setting template on the drum rim holds the pipes during the sand fill (the concept used the lid, which blocks the fill). New BOM line 43.
5. Base: 610 mm firebrick disc (16 bricks, was 14) and AES disc, with an 89 mm stone wool batt ring out to the jacket (the concept left a void).
6. Inlet plenum 140 mm tall (was 110), collar hole cut through, flanges riveted to the cap; inlet legs 30 mm longer.
7. Collector fixed to the lid by six tabs between the wells with steel rivets; top disc with a folded, riveted edge.
8. Hot outlet passes the galvanized cap in a 180 mm hole packed with AES and covered by a black steel trim ring (the cap touched the 314 °C pipe, against R13). New BOM line 44.
9. Heaters with 72 in leads (36 in could not reach the junction box); junction box placed on the cap at 120°, 430 mm out, over a grommeted hole. New BOM line 46.
10. Thermocouples: routes through the lid, T4 bent across the sand surface to a lid hole, stainless guide rods for T4 to T7 (new BOM line 45), 1,500 mm sheaths (was 1,000 mm), one exit grommet in the cap.
11. Jacket cap from three lapped strips with a 25 mm skirt held by screws, so it lifts off for heater service (R17).

`python cad/src/model.py --check` runs 72 constructability checks; all pass.

**Key results.** Operating mass 415 kg (was 410 kg; R15 450 kg met); TBK-CAL-001 v0.3 re-run, thermal and electrical results unchanged; R3 is still **not met** (9.6 h against 8 h). Value-engineering target: USD 728. Estimated cost of the constructable design: USD 3,854 (USD 3,126 over the target; +USD 180 for construction).

**Files.** `cad/src/model.py`, `cad/src/build_plan_media.py` (new), `cad/src/sheets.py`, `cad/step/thermabrick.step`, `cad/stl/thermabrick.stl`, TBK-DWG-001 Rev P2, TBK-DWG-101 to 110 (new), `docs/05-build-plan/` (overview, 3 layouts, 9 joints, 20 steps, wiring), `docs/05-build-plan.md` TBK-BLD-001 v0.1 (new), `docs/06-design-decisions.md` TBK-DEC-001 v0.1 (new), `docs/decisions/0003-design-for-construction.md` TBK-DDR-003 v0.1 (new), TBK-CAL-001 v0.3, TBK-PRC-001 v0.6, TBK-REQ-001 v0.10, TBK-PRB-001 v0.9, `bom/bom.csv`, `bom/bom-notes.md`, `project.yaml`, `README.md`, concept media (`media/hero.png`, `cutaway.png`, `exploded.png`, `flow.png`, `concept-blueprint.*`, `model.glb`, `viewer.html`).

**Proposed, awaiting Amish** (all in TBK-DEC-001): review of the changes above; a BOM line for warning labels; keep the air path layout illustrative; plus the items carried over (standby loss, ground-fault device, render deviations).

**Stale, made on Amish's Mac.** `media/render-*.png`, `media/card.png`, `media/social-preview.png` and `cad/src/product_model.py` still show the concept base, the 110 mm plenum and no trim ring or cap fixings; the visible changes are small but real, so they should be re-rendered.

**Safety.** Unchanged in substance: the trim ring restores R13 at the outlet; the cap-edge temperature is to be confirmed at the first firing (TBK-DEC-001). The build plan carries the silica, fiber, 240 V, first-firing and stored-heat stops.

**Recommended next step.** Amish reviews TBK-DDR-003 and the register; then re-render the product images on the Mac.

## Session 2026-10-02: open-decision recommendations approved

Amish, 2026-10-02: "i approve your recommendations for all 555 open decisions." This approves the recommendation for every open decision in the design decisions register. 9 decisions were recorded: each moved to Decisions made, dated 2026-10-02, with the approved recommendation and its record. trl stays 3; no build or test work was done, and the CAD model, BOM quantities and prices, and pictures were not changed.

### Documents changed

- `docs/06-design-decisions.md` (TBK-DEC-001 v0.2): the nine open decisions moved to Decisions made; Open decisions now reads none
- `docs/decisions/0003-design-for-construction.md` (TBK-DDR-003 v0.2): status accepted with Amish's words (P1 to P11, C1 and C2); Table 3 marked accepted; consequence added
- `docs/decisions/0002-recommendations-accepted.md` (TBK-DDR-002 v0.2): standby loss and GFCI choice decided
- `docs/03-requirements.md` (TBK-REQ-001 v0.11): R11 names the 5 mA GFCI breaker and the condition for 30 mA protection; R15 adds the siting rules as installer requirements; no status changed
- `docs/04-calcs/TBK-CAL-001-sizing.md` (TBK-CAL-001 v0.4): branch circuit breaker stated as 5 mA GFCI; no result changed
- `docs/02-concept.md` (TBK-PRC-001 v0.7): safety design: 5 mA GFCI, siting rules as installer requirements, warning labels; standby loss and GFCI open questions closed
- `docs/01-problem.md` (TBK-PRB-001 v0.10): standby loss open decision recorded as decided
- `README.md`: safety note: 5 mA GFCI breaker and the outlet duct guard and clearance
- `bom/bom-notes.md`: breaker type, approved label line, and the cosmetic and functional trim rings noted; no quantity or price changed
- PDFs regenerated with `python3 .kit/render.py`; superseded PDF versions removed by the render.

### Follow-up actions to carry approved decisions into the design

1. Decision 2 (bom): Add one BOM line, about USD 15, for hot-surface and 240 V warning labels on the jacket, outlet guard, junction box and enclosure, and re-run the cost total
2. Decision 2 (pictures): Add the label positions to the build plan (TBK-BLD-001) final steps and pictures
3. Decision 5 (bom): Change the spec of BOM line 39 to a 2-pole 20 A, 5 mA GFCI breaker
4. Decision 8 (pictures): Regenerate the photoreal renders from `cad/src/product_model.py` so they show the functional black outlet trim ring (BOM line 44) as well as the optional teal top ring, and name the two rings distinctly in the appearance model (on Amish's Mac)
5. Decision 1 (pictures): Regenerate the photoreal renders, `media/card.png` and `media/social-preview.png` for the accepted construction (base, plenum, cap fixings), on Amish's Mac
6. Decision 4 (calcs): Decide the stainless upper inlet legs and microporous hot face together with the R3 charge-time fix once the test article has measured loss (on hold with TRL 4); no change now

### Points found in the review

- The value-engineering target ($728) is the reduced-scale test article's budget, but it is compared with the full-scale constructable design ($3,854); these are not like for like, so the $3,126 overrun is not meaningful. Set a full-scale target or compare the test article with its own estimate.
- Value engineering text has a stray full stop mid-sentence: "(up to USD 190). with stone wool batts".
- Two different "trim rings" now exist: the cosmetic teal top ring in the renders and the functional black outlet ring of P8; name them distinctly.
- There is no 0001 decision record in this repo; the 2026-09-24 decision is recorded only in TBK-PRB-001.

## Session 2026-10-02: approved follow-ups carried out

Amish approved all follow-up actions on 2026-10-02. Done: 4 of 6 in full, 2 on Amish's Mac. No requirement changed status; R3 stays not met. trl stays 3.

### Follow-ups

1. Decision 2, BOM: done. Line 47 added, USD 15.00 (five labels at about USD 3 each); BOM total $3,868.50. Value-engineering target: USD 728. Estimated cost of the constructable design: USD 3,869 (USD 3,141 over the target). `budget_usd` unchanged.
2. Decision 2, pictures: done. Step 22 and Figure 26 (`docs/05-build-plan/step-22.png`) give the five label positions; the bought components list and safety stop S6 name the labels. Label plates added to the CAD model (jacket, cap, junction box) with 11 new checks; 88 of 88 checks pass; STEP and STL regenerated.
3. Decision 5, BOM: done. Line 39 is a 2-pole 20 A, 5 mA GFCI breaker; price kept at $110.00 with the basis in `bom/bom-notes.md`.
4. Decision 8, renders: scenes done, photoreal not done (made on Amish's Mac). `cad/src/product_model.py` now shows the galvanized jacket cap and the functional black outlet trim ring (BOM line 44), and names the teal part "Optional teal top bead (cosmetic, no BOM line)". Render scenes exported to `/home/claude/renders/thermabrick` (hero, exploded, detail, plus `thermabrick__jobs.json`).
5. Decision 1, renders, card and social preview: not done: made on Amish's Mac from the exported scenes.
6. Decision 4, calcs: not done: on hold with TRL 4 and the R3 charge-time fix; no change by decision.

### Documents changed

- `bom/bom.csv`, `bom/bom-notes.md`: lines 39 and 47, total, groups, cost-down figure
- `cad/src/model.py`, `cad/step/thermabrick.step`, `cad/stl/thermabrick.stl`: label plates and checks
- `docs/04-calcs/tbk_cal_001.py` and TBK-CAL-001 v0.5: mass re-run, 414.7 kg (about 415 kg), no result changed
- TBK-DWG-001 Rev P3 (labels row); concept media regenerated; overview picture redrawn
- TBK-BLD-001 v0.2, TBK-DEC-001 v0.3 (cost wording; stray full stop fixed), TBK-PRC-001 v0.8, TBK-PRB-001 v0.11, TBK-REQ-001 v0.12 (R20 cost), TBK-DDR-003 v0.3, `README.md`

### Cross-repo actions

None.

### Points for Amish

- The outlet guard sleeve has no BOM line (it is only in the appearance model and the build plan text). Consider a line for it.

## 2026-10-02: photoreal renders redone on the constructable design

Rendered with Blender Cycles on Amish's Mac from the updated appearance model; captioned with `.kit/photo_caption.py`; `media/card.png` and `media/social-preview.png` regenerated with `.kit/cards.py`. Views: hero, exploded, detail. image_qc passes. Appearance deviations are those logged above as proposed, awaiting Amish.

## 2026-10-03: decisions recorded

Amish decided on 2026-10-03: "Cost over target - i accept all the cost variations and overruns". Recorded for this repo: the full-scale estimate of USD 3,869 against the USD 728 target (USD 3,141 over).

- `docs/06-design-decisions.md`: row added to decisions made; value engineering section says the overrun was accepted by Amish on 2026-10-03.

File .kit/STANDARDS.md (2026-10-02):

---
doc_id: OHP-STD-001
title: Documentation and drawing standard
project: Open Hardware Portfolio
doc_type: Standard
version: "1.7"
status: Released
date: 2026-09-30
author: Amish Chadha
license: CC-BY-SA-4.0
revisions:
  - version: "1.0"
    date: 2026-09-24
    author: Amish Chadha
    change: First release of the standard
  - version: "1.1"
    date: 2026-09-24
    author: Amish Chadha
    change: Adopt Technology Readiness Levels (section 9) for project maturity
  - version: "1.2"
    date: 2026-09-24
    author: Amish Chadha
    change: Portfolio phase cap (section 10), concept media standard (section 11), CLAUDE.md guardrails
  - version: "1.3"
    date: 2026-09-24
    author: Amish Chadha
    change: Scale figure, interactive 3D viewer and flow diagrams added to concept media; session slash commands
  - version: "1.4"
    date: 2026-09-26
    author: Amish Chadha
    change: Every sheet and render names the project and its GitHub repository; overall dimensions, ISO centre lines and 300 dpi PNG on sheets; titles name the device and view labels state the viewing direction; optional photoreal renders with Blender
  - version: "1.5"
    date: 2026-09-27
    author: Amish Chadha
    change: Product renders (section 12), storefront images and image quality check (section 13), public release and release gate (section 14), authorship, citation and commit signing (section 15)
  - version: "1.6"
    date: 2026-09-29
    author: Amish Chadha
    change: Licensing metadata with REUSE (section 16), Zenodo DOI and Software Heritage archiving (section 17), release gate checks REUSE and a single CITATION.cff license, archive.py
  - version: "1.7"
    date: 2026-09-30
    author: Amish Chadha
    change: Concept and constructable design states; design decisions register (DEC) kept apart from the build plan; prototype build plan (BLD, section 18) with pictures by component is required TRL 3 evidence; every repo targets TRL 3 during the populate phase; build_views.py; /to-trl3 and /build-plan commands
---

# Documentation and drawing standard

Every project in the portfolio uses this standard, so that each precis, write-up and sketch looks the same and carries its own version history. The standard ships as a kit in each repo's `.kit/` folder. The kit version is in `.kit/KIT_VERSION`.

## 1. Document types and IDs

Every controlled document has a unique ID in the form `PRJ-TYP-NNN`.

- `PRJ` is the three-letter project code listed in section 7.
- `TYP` is the document type code from the table below.
- `NNN` is a sequence number within that project and type, starting at 001.

| Code | Type | Typical file |
| --- | --- | --- |
| PRC | Design precis | `docs/02-concept.md` |
| PRB | Problem statement | `docs/01-problem.md` |
| REQ | Requirements | `docs/03-requirements.md` |
| CAL | Calculation or sizing note | `docs/04-calcs/*.md` |
| DDR | Design decision record | `docs/decisions/*.md` |
| BOM | Bill of materials | `bom/bom.csv` |
| DWG | Drawing or sketch sheet | `cad/drawings/*.svg` |
| BLD | Prototype build plan (section 18) | `docs/05-build-plan.md` |
| DEC | Design decisions register (section 18) | `docs/06-design-decisions.md` |
| TST | Test plan or test report (front matter adds `environment: lab` or `relevant`) | `docs/05-tests/*.md` |

Example: `TBK-PRC-001` is the ThermaBrick design precis.

## 2. Revision scheme

| Artifact | While in draft | When released | Change after release |
| --- | --- | --- | --- |
| Documents | 0.1, 0.2, 0.3 ... | 1.0 | 1.1 for minor edits, 2.0 for a design change |
| Drawings | Rev P1, P2 ... (preliminary) | Rev A | Rev B, C ... |

- Every change to a controlled document adds a row to its revision history before the commit.
- The `version` field in front matter always equals the newest row in `revisions`. The renderer rejects a document where they differ.
- Status is one of `Draft`, `In review`, `Released` or `Superseded`. Draft and In review documents print with a status band on every page.
- Every release is tagged in Git as `<doc_id>/v<version>`, for example `TBK-PRC-001/v1.0`. Drawings are tagged `TBK-DWG-001/revA`.
- Git history is the full audit trail. The in-document revision table is the human-readable summary.

## 3. Document front matter

Every Markdown document under version control starts with this block:

```yaml
---
doc_id: TBK-PRC-001
title: ThermaBrick design precis
project: ThermaBrick
doc_type: Precis
version: "0.1"
status: Draft
date: 2026-09-24
author: Amish Chadha
license: CERN-OHL-S-2.0
revisions:
  - version: "0.1"
    date: 2026-09-24
    author: Amish Chadha
    change: Initial draft
---
```

Quote version numbers so YAML keeps `1.0` as text instead of turning it into a number. List revisions newest last.

## 4. Writing style

- Chicago Manual of Style.
- No em dashes. Restructure the sentence instead.
- Lead each section with its conclusion, then support it.
- SI units throughout, in the form `12 kW`, `450 °C`, `3.2 m`. Imperial values may follow in parentheses.
- Number every figure and table ("Figure 2", "Table 1") and give each a caption.
- State every assumption in the calculation that depends on it.
- Put safety notes in a blockquote starting with **Safety:**.

## 5. Visual identity

| Element | Specification |
| --- | --- |
| Typeface | IBM Plex Sans for text, IBM Plex Mono for code and values (SIL Open Font License, bundled in `.kit/fonts`) |
| Ink | `#111827` |
| Secondary text | `#4B5563` |
| Rules and grid | `#D1D5DB` |
| Accent (one only) | `#0F766E` teal |
| Document page | US Letter, 20 mm margins |
| Drawing sheet | ANSI B landscape (431.8 x 279.4 mm) |
| Footer | Document ID, version, status, license and designmolecule.com on every page |

## 6. Drawing and sketch conventions

- Units are millimeters unless the title block says otherwise.
- Third-angle projection, marked with the symbol in the title block.
- Line weights: visible outlines 0.5 mm, hidden lines 0.25 mm dashed, center lines 0.18 mm chain.
- The title block contains the project, title, drawing number, revision, scale, units, projection, sheet, author, date, material or notes, and license.
- Every sheet and every render names the project and its GitHub repository (from `repo:` in `project.yaml`), at the top of the sheet and in the title block, so a printed or forwarded sheet is never anonymous.
- The drawing title names the device, not only the drawing type (for example "Handheld near-infrared resin scanner: general arrangement").
- Every view label states its scale and viewing direction (for example "Scale 1:1; side elevation looking along +Y"), and every isometric or render states where it is seen from.
- Orthographic views generated with `add_ortho` carry overall dimensions (length and depth on the top view, height on the front view) and ISO 128 centre lines on cylinders; hidden lines are dashed. Tolerances are not shown before TRL 4.
- Sheets are exported as SVG, PDF and a 300 dpi PNG.
- The revision table in the top right of the sheet lists every revision.
- Concept sketches use the same sheet and title block and carry the label "CONCEPT, NOT FOR FABRICATION".
- Geometry comes from `cad/src/*.py` (build123d). Sheets are generated by `.kit/drawing.py` and never edited by hand.

## 7. Project codes

| Code | Project | Code | Project | Code | Project |
| --- | --- | --- | --- | --- | --- |
| TBK | ThermaBrick | PCF | PicoFlow | HLT | HelioLite |
| CCB | CharCube | DRN | DustRunner | TRT | TremorTrace |
| STC | StepCue | FXH | FlexHand | CPD | ColdPod |
| SCL | SunClave | STR | SteamRoot | GGD | GrainGuard |
| SDL | SeedLine | ZBX | ZeerBox | RMS | RootMesh |
| DWD | DewDrive | SSK | StillStack | PPR | PotPress |
| WWT | WaterWatch | LMF | LumaFlow | FCL | FieldCell |
| CNP | ConePro | CVC | CulvertCrawl | EGD | EmberGuard |
| SNF | SnapFrame | CGM | CargoMule | SCM | StepClimber |
| SWC | SwapCell | PLP | PalletPilot | FTK | FlatTrike |
| WWK | WaterWalker | GRR | GrowRider | SSP | SunSpoke |
| SGN | StepGen | PBX | PowerBox | WML | WasteWise-ml |
| WSC | WasteWise Scan | RFE | ReflowEconomy | | |
| OHP | Portfolio-wide | | | | |

## 8. Build and publish

- `python .kit/render.py` checks every controlled document and renders it to `docs/pdf/<doc_id>_v<version>.pdf`.
- `python .kit/drawing.py` (called from each project's `cad/src/sheets.py`) builds drawing sheets as SVG and PDF in `cad/drawings/`.
- The GitHub Action in `.github/workflows/docs.yml` runs the checks on every push and attaches PDFs to a GitHub Release whenever a release tag is pushed.
- Public releases follow section 14: `python .kit/release_gate.py` must pass, and the release tag is `v0.<TRL>.0` (for example `v0.3.0` at TRL 3).

## 9. Technology Readiness Level (TRL)

Each project states its maturity as a Technology Readiness Level on the NASA and US DOE 1 to 9 scale. The TRL rates this specific design, not the underlying technology. A sand battery is commercial elsewhere, but a new sand battery design starts at TRL 2 until evidence shows otherwise.

| TRL | Definition | Evidence the repo must contain |
| --- | --- | --- |
| 1 | Basic principles observed | Problem statement (PRB) |
| 2 | Technology concept formulated | Draft precis (PRC) and requirements (REQ) |
| 3 | Analytical or experimental proof of concept | Calculation note (CAL), working build123d model with STEP export, drawing sheet (DWG), priced BOM with every unit cost filled in, prototype build plan (BLD) with pictures, `design_state: constructable` |
| 4 | Components validated in the lab | Test report (TST) with `environment: lab`, build log entries |
| 5 | Validated in a relevant environment | Test report (TST) with `environment: relevant` |
| 6 | System prototype demonstrated in a relevant environment | Precis at version 1.0 or later with status Released, a drawing at a lettered revision (Rev A or later), and a system-level TST with `environment: relevant` |
| 7 to 9 | Operational demonstration through proven in service | Beyond portfolio scope; claim only with a named deployment partner and evidence |

Rules:

- `project.yaml` records `trl` (current level), `trl_target` (the level the current effort aims for) and `trl_evidence` (the files that support the claim).
- `python .kit/render.py --check` fails if the evidence for the claimed TRL is missing. CI runs this check on every push.
- Documentation alone cannot go past TRL 3. TRL 4 and above require hardware and a test report.
- TRL and visibility are independent. A repo can be public at TRL 3 as a documented design ready to build.
- A change of TRL is recorded in the build log with the date and the evidence that justified it.
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

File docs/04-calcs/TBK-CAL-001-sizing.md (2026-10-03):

---
doc_id: TBK-CAL-001
title: ThermaBrick thermal and electrical sizing
project: ThermaBrick
doc_type: Calculation
version: "0.5"
status: Draft
date: '2026-10-02'
author: Amish Chadha
license: CERN-OHL-S-2.0
revisions:
- version: "0.1"
  date: '2026-09-24'
  author: Amish Chadha
  change: Initial draft. Sizing for 18 kWh(th) of sand storage, charge and discharge models, standby loss, electrical, air path and floor load
- version: "0.2"
  date: '2026-09-24'
  author: Amish Chadha
  change: Corrected the charge and discharge results to include standby loss, which v0.1 omitted. Full charge now takes 9.6 h, so R3 is not met; rated output holds for 14.3 h. Updated Tables 1, 3, 8 and 9 and Figures 1 and 2
- version: "0.3"
  date: '2026-10-01'
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

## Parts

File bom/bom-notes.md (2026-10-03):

# BOM notes

The bill of materials in `bom.csv` totals **$3,868.50** for the constructable design (Table 1). It was $3,673.50 for the v0.2 concept; making the design buildable (TBK-DDR-003, 2026-09-30) added $180.00: longer heater leads and thermocouple sheaths, 4 in nipples, two more firebricks, a second AES rope, more fasteners, and four new lines (setting template, outlet trim ring, thermocouple guide rods and cap grommets, lines 43 to 46). The warning labels approved on 2026-10-02 (line 47, $15.00) bring the total to $3,868.50.

Value-engineering target: USD 728 (`budget_usd` in `project.yaml`, set as the reduced-scale test article budget, decided by Amish on 2026-09-25, TBK-DDR-002; the concept's original target was about $600). Estimated cost of the constructable design: USD 3,869 (USD 3,141 over the target). The target is a hypothetical control figure for value engineering, not a spending limit.

| Group | Cost (USD) | Share |
| --- | --- | --- |
| Insulation | 871.00 | 23 % |
| Controls and instrumentation | 862.50 | 22 % |
| Heaters and wells | 776.00 | 20 % |
| Discharge exchanger and air path | 740.00 | 19 % |
| Storage vessel, sand and setting template | 233.00 | 6 % |
| Branch circuit | 190.00 | 5 % |
| Jacket, trim ring, grommets and warning labels | 196.00 | 5 % |
| Total | 3,868.50 | 100 % |

*Table 1. BOM cost by group.*

## Cost basis

- Unit costs are budgetary estimates in US dollars, based on typical US retail and distributor list prices in September 2026, before tax and shipping. They are not quotes. Confirm every price at order.
- Suppliers are examples of where each part can be bought. "Or equal" means any part that meets the spec column.
- Quantities include cutting allowance: 227 kg of sand is bought for a 210 kg fill, and pipe comes in full 10 ft sticks.
- Excluded: tool purchase or rental (pipe threader, hole saws), electrician labor for the branch circuit, permits, and the room thermostat if one is added.
- Quantities and dimensions follow `cad/src/model.py`. When the model changes, update this BOM in the same commit (CONTRIBUTING.md).

## Cost-down options

These options together save about $830 (to about $3,040) with no change in performance. None of them reaches the value-engineering target at 18 kWh(th).

| Option | Saving | Trade-off |
| --- | --- | --- |
| Generic import cartridge heaters instead of US industrial brands | About $300 | Wider tolerance on resistance and weaker lead insulation; test each on arrival |
| Reconditioned open-head drum | About $100 | Must be unlined and free of residues; burn out before use |
| Read export from the inverter's local API instead of an energy meter | $90 | Works only with supported inverters |
| MAX31855 amplifiers instead of MAX31856 | About $50 | Type K only, which is all this design uses |
| Stone wool batts for the base instead of board, loads carried by firebrick under the full base | About $100 | More firebrick; slightly higher base loss |
| Existing 240 V circuit or breaker | Up to $190 | Site dependent |

*Table 2. Cost-down options.*

A reduced-scale test article is the only route to a cost near the target. It was the next build, and is now archived and on hold with TRL 4. It is a 16 US gal drum with 68 kg of sand, four heater cells and one U-tube, storing 5.9 kWh(th) (TBK-PRC-002). Its separate BOM, `archive/out-of-phase-trl4/bom/bom-test-article.csv`, is estimated at $727.70. Modeling the controller enclosure (TBK-DWG-005) added $36.00. The resulting $635.70 was accepted as the test article budget on 2026-09-24. The build procedure then added a second stone wool pack, the heater cable, wiring consumables and thermocouple extension wire ($92.00), for $727.70. Decided by Amish, 2026-09-25: go with recommendation, so the test article budget is $727.70 (TBK-DDR-002). Nothing will be bought while TRL 4 is on hold. The optional controller board (`archive/out-of-phase-trl4/bom/bom-controller-board.csv`, TBK-DWG-004), kept deferred by Amish's 2026-09-25 decision, would add $24.85 net, taking the test article to $752.55, so it is not part of the $600 baseline. An earlier note here suggested a 30 US gal drum. Sizing showed that drum gives a bed too shallow for the full-scale heaters, so the 16 US gal drum replaced it.

The purchasing checklist and its generator, `checklist.py`, are archived with the test article under `archive/out-of-phase-trl4/bom/`.

Decisions of 2026-10-02 (TBK-DEC-001), carried into the bill of materials the same day:

- Line 39 is now a 2-pole 20 A, 5 mA GFCI breaker; the price stays at $110.00 (basis: a Class A 2-pole GFCI breaker for a typical residential panel is within the same price band as the 30 mA type it replaces; confirm at order). 30 mA equipment ground-fault protection only as a measured exception agreed with the installing electrician.
- Line 47 (new, $15.00): five self-adhesive vinyl warning labels rated 105 C or higher, at about $3 each: HOT SURFACES INSIDE (jacket), HOT OUTLET (jacket cap), HOT SURFACE (outlet guard sleeve), DANGER 240 V (junction box) and DANGER 240 V (control enclosure). Positions are in TBK-BLD-001 step 22. The labels add about 0.05 kg; operating mass stays 415 kg.
- The teal top bead and kick plinth in the renders are optional cosmetic parts with no BOM line; the black outlet trim ring (line 44) is a functional part and is drawn as such in the appearance model.

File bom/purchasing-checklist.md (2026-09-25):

# Purchasing checklist

Test article (TBK-PRC-002). BOM total $727.70; accepted budget $635.70, rise to $727.70 proposed, awaiting Amish. Generated from `bom-test-article.csv` and `bom-controller-board.csv` by `bom/checklist.py`; regenerate after any BOM change instead of editing this file.

Prices are the BOM's budgetary estimates (US list prices, September 2026, before tax and shipping). Record the price actually paid beside each line.

Tick an item's box when it is ordered, and its **Received** box once it has arrived and passed its check.

## 1. Made-to-order heaters (order first)

Made-to-order cartridge heaters take two to four weeks. Order them the day the build is approved. Subtotal $72.00.

- [ ] **Nichrome heating elements**, qty 4, $18.00 each, $72.00. Supplier: Made-to-order import cartridge heater supplier (Amazon or AliExpress).
  - Specify: 5/8 in (15.9 mm) diameter, 18 in long, 120 V, 250 W, 16 in heated with the 2 in cold end at the lead end, leads 24 in or longer rated for high temperature.
  - [ ] Received: Measure each cold resistance: 55 to 60 ohm, all four within 5 % of each other.

## 2. Uline

Ships in one to three days. Subtotal $115.00.

- [ ] **Steel drum**, qty 1, $115.00 each, $115.00. Supplier: Uline S-19411.
  - Specify: Open head with bolt ring, unlined interior (Uline S-19411).
  - [ ] Received: No liner or interior coating. Remove the lid gasket before first firing.

## 3. Kiln or refractory supplier

Local pottery or kiln suppliers stock K-23 brick; call ahead. Subtotal $22.00.

- [ ] **Insulating firebrick**, qty 4, $5.50 each, $22.00. Supplier: Kiln or refractory supplier.
  - Specify: K-23 insulating firebrick, not dense firebrick.
  - [ ] Received: Light enough to lift easily; about 0.8 kg each.

## 4. DigiKey or Mouser

One order. Subtotal $12.20.

- [ ] **12 V supply**, qty 1, $12.00 each, $12.00. Supplier: Mean Well HDR-15-12 via DigiKey or Mouser.
  - Specify: Mean Well HDR-15-12, or an equal DIN-rail 12 V supply of 1.25 A or more.
  - [ ] Received: quantity and specification match the order.
- [ ] **Pull-down resistors**, qty 2, $0.10 each, $0.20. Supplier: DigiKey or an assortment on hand.
  - Specify: 10 kOhm, 1/4 W. Skip if an assortment is on hand.
  - [ ] Received: quantity and specification match the order.

## 5. Amazon or an electrical wholesaler

Controls, wiring and small parts. Buy from sellers with easy returns. Subtotal $182.00.

- [ ] **Inlet blower**, qty 1, $10.00 each, $10.00. Supplier: Amazon (9733 blower or equal).
  - Specify: 12 V, 0.8 A or less, 97 x 94 x 33 mm. High-speed 2 A to 3 A versions overload the supply.
  - [ ] Received: Run it on 12 V and measure the current.
- [ ] **Blower driver**, qty 1, $3.00 each, $3.00. Supplier: Amazon.
  - Specify: Logic-level MOSFET module rated 5 A or more.
  - [ ] Received: quantity and specification match the order.
- [ ] **Buck converter**, qty 1, $3.00 each, $3.00. Supplier: Amazon.
  - Specify: 12 V in, 5 V out, 3 A.
  - [ ] Received: Set or check 5.0 V out before connecting the ESP32.
- [ ] **ESP32 controller**, qty 1, $7.00 each, $7.00. Supplier: Amazon or Espressif via DigiKey.
  - Specify: Any ESP32-WROOM-32 board exposing GPIO 4, 5, 16, 17, 18, 19, 22, 25 and 26. For the optional controller board, a genuine 38-pin ESP32-DevKitC V4 only.
  - [ ] Received: quantity and specification match the order.
- [ ] **Thermocouple amplifier**, qty 1, $15.00 each, $15.00. Supplier: Amazon.
  - Specify: MAX6675 modules, pack of five.
  - [ ] Received: Pin order GND, VCC, SCK, CS, SO (required for the optional board).
- [ ] **K-type thermocouples**, qty 4, $8.00 each, $32.00. Supplier: Amazon (or Omega or Auber for tighter tolerance).
  - Specify: Type K, mineral insulated, ungrounded junction, 3 mm sheath, 500 mm.
  - [ ] Received: Check with a multimeter that neither lead is connected to the sheath.
- [ ] **Solid state relay**, qty 1, $9.00 each, $9.00. Supplier: Amazon (SSR-25DA or equal).
  - Specify: Zero-cross, DC control 3 to 32 V, AC load, 25 A.
  - [ ] Received: Counterfeits are common. Test it switching a lamp from a 3.3 V and a 5 V control signal.
- [ ] **SSR heat sink**, qty 1, $6.00 each, $6.00. Supplier: Amazon.
  - Specify: Panel mount with thermal pad, sized for one SSR.
  - [ ] Received: quantity and specification match the order.
- [ ] **Independent high limit**, qty 1, $14.00 each, $14.00. Supplier: Amazon.
  - Specify: REX-C100 with relay output (R*AN code), type K input, 100 to 240 VAC supply.
  - [ ] Received: Confirm the output is a relay, not an SSR driver, before panel cutting.
- [ ] **Latching power relay**, qty 1, $10.00 each, $10.00. Supplier: Amazon.
  - Specify: JQX-30F 2Z, DPDT, 120 VAC coil (not 220 VAC or 12 VDC), with DIN-rail socket.
  - [ ] Received: quantity and specification match the order.
- [ ] **Start and stop buttons**, qty 1, $5.00 each, $5.00. Supplier: Amazon.
  - Specify: 22 mm, one red normally closed (STOP) and one green normally open (START), rated 120 VAC.
  - [ ] Received: Check contact states with a multimeter.
- [ ] **Control enclosure**, qty 1, $30.00 each, $30.00. Supplier: Amazon or an electrical wholesaler.
  - Specify: Polycarbonate, 250 x 200 x 150 mm or larger, UL 94 V-0 or 5VA, IP65, with a mounting plate.
  - [ ] Received: Inside depth 140 mm or more (TBK-DWG-005).
- [ ] **DIN rail**, qty 1, $3.00 each, $3.00. Supplier: Amazon or an electrical wholesaler.
  - Specify: TS35 x 7.5.
  - [ ] Received: quantity and specification match the order.
- [ ] **Cable glands**, qty 4, $1.50 each, $6.00. Supplier: Amazon (assortment).
  - Specify: Nylon, IP68, with locknuts: one M16, two M20, one M25.
  - [ ] Received: quantity and specification match the order.
- [ ] **Lever connectors and PE stud**, qty 1, $5.00 each, $5.00. Supplier: Amazon or Home Depot.
  - Specify: Two 5-way lever connectors (Wago 221-415 or equal); M5 earth stud with ring lugs.
  - [ ] Received: quantity and specification match the order.
- [ ] **Wiring consumables**, qty 1, $12.00 each, $12.00. Supplier: Amazon.
  - Specify: Stranded 16 AWG and 22 AWG hookup wire rated 105 C; ferrules to suit; M5 ring lugs; heat-shrink.
  - [ ] Received: quantity and specification match the order.
- [ ] **Thermocouple extension**, qty 1, $12.00 each, $12.00. Supplier: Amazon.
  - Specify: Type K extension grade (not copper), with miniature type K plugs and jacks.
  - [ ] Received: Check polarity: yellow positive, red negative (ANSI).

## 6. Home Depot or Lowe's (one trip)

Pipe, sheet metal, insulation and sand. Subtotal $324.50.

- [ ] **Sand**, qty 3, $6.50 each, $19.50. Supplier: Home Depot or Lowe's (Quikrete play sand or equal).
  - Specify: Washed play sand. Avoid all-purpose or leveling sand, which contains clay.
  - [ ] Received: Weigh each bag.
- [ ] **Heater well pipe**, qty 1, $28.00 each, $28.00. Supplier: Home Depot or Lowe's.
  - Specify: 3/4 in black steel, not galvanized, 10 ft.
  - [ ] Received: quantity and specification match the order.
- [ ] **U-tube legs**, qty 2, $28.00 each, $56.00. Supplier: Home Depot or Lowe's.
  - Specify: 1-1/4 in x 36 in black steel nipples, not galvanized.
  - [ ] Received: quantity and specification match the order.
- [ ] **U-tube elbow**, qty 2, $8.00 each, $16.00. Supplier: Home Depot or Lowe's.
  - Specify: 1-1/4 in black malleable iron 90 deg elbows.
  - [ ] Received: quantity and specification match the order.
- [ ] **U-tube bottom nipple**, qty 1, $6.00 each, $6.00. Supplier: Home Depot or Lowe's.
  - Specify: 1-1/4 in x 6 in black steel nipple.
  - [ ] Received: quantity and specification match the order.
- [ ] **Dilution stack**, qty 1, $12.00 each, $12.00. Supplier: Home Depot or Lowe's.
  - Specify: 4 in single-wall black stovepipe, 24 in, not galvanized.
  - [ ] Received: quantity and specification match the order.
- [ ] **Stone wool batt**, qty 2, $60.00 each, $120.00. Supplier: ROCKWOOL Comfortbatt R15 via Home Depot or Lowe's.
  - Specify: ROCKWOOL Comfortbatt R15, 3.5 in, unfaced.
  - [ ] Received: quantity and specification match the order.
- [ ] **Jacket sheet**, qty 1, $30.00 each, $30.00. Supplier: Home Depot or Lowe's.
  - Specify: Aluminum roll flashing, 20 in x 25 ft.
  - [ ] Received: quantity and specification match the order.
- [ ] **Jacket fasteners and tape**, qty 1, $8.00 each, $8.00. Supplier: Home Depot or Lowe's.
  - Specify: Aluminum foil tape and sheet metal screws.
  - [ ] Received: quantity and specification match the order.
- [ ] **Fuse**, qty 1, $5.00 each, $5.00. Supplier: Home Depot or auto parts store.
  - Specify: Inline holder with 10 A fast-acting fuse; buy a spare fuse.
  - [ ] Received: quantity and specification match the order.
- [ ] **Supply cord**, qty 1, $8.00 each, $8.00. Supplier: Home Depot or Lowe's.
  - Specify: 14/3 SJT with NEMA 5-15 plug, 6 ft.
  - [ ] Received: quantity and specification match the order.
- [ ] **Heater junction box**, qty 1, $8.00 each, $8.00. Supplier: Home Depot plus Amazon.
  - Specify: Steel handy box; ceramic terminal block rated 250 V, 10 A or more.
  - [ ] Received: quantity and specification match the order.
- [ ] **Heater cable**, qty 1, $8.00 each, $8.00. Supplier: Home Depot or Lowe's.
  - Specify: 16/3 SJT, 2 m, black, white and green conductors.
  - [ ] Received: quantity and specification match the order.

**Test article total: $727.70** across 35 lines.

## Optional and deferred: controller board (TBK-DWG-004)

Deferred: do not order unless Amish decides to build the controller on the printed board. Parts $27.85; the board replaces the buck converter and blower driver above ($6.00), so skip those two lines. Upload `electronics/controller-board/thermabrick-controller-board-gerbers-P1.zip` to the board house: 2 layers, 1.6 mm FR-4, 1 oz copper, HASL, any color.

- [ ] **Printed circuit board**, qty 1, $15.00 each, $15.00. 110 x 80 mm, 2 layer FR-4 1.6 mm, 1 oz copper, HASL; gerbers in electronics/controller-board (minimum order of 5 shares the cost). Supplier: JLCPCB or PCBWay.
  - [ ] Received: quantity and specification match the order.
- [ ] **Regulator**, qty 1, $4.50 each, $4.50. RECOM R-78E5.0-1.0, 12 V to 5 V switching regulator, SIP-3 (U1). Supplier: DigiKey or Mouser.
  - [ ] Received: quantity and specification match the order.
- [ ] **Input capacitor**, qty 1, $0.20 each, $0.20. Aluminum electrolytic 10 uF 25 V, 5 mm diameter, 2 mm pitch (C1). Supplier: DigiKey or Mouser.
  - [ ] Received: quantity and specification match the order.
- [ ] **Output capacitor**, qty 1, $0.20 each, $0.20. Aluminum electrolytic 22 uF 10 V, 5 mm diameter, 2 mm pitch (C2). Supplier: DigiKey or Mouser.
  - [ ] Received: quantity and specification match the order.
- [ ] **SSR driver transistor**, qty 1, $0.10 each, $0.10. 2N3904 NPN, TO-92 (Q1). Supplier: DigiKey or Mouser.
  - [ ] Received: quantity and specification match the order.
- [ ] **Blower MOSFET**, qty 1, $1.20 each, $1.20. IRLZ44N logic-level N-MOSFET, TO-220 (Q2). Supplier: DigiKey or Mouser.
  - [ ] Received: quantity and specification match the order.
- [ ] **Flyback diode**, qty 1, $0.15 each, $0.15. 1N5819 Schottky, DO-41 (D1). Supplier: DigiKey or Mouser.
  - [ ] Received: quantity and specification match the order.
- [ ] **Resistors**, qty 2, $0.10 each, $0.20. 1 kOhm (R3) and 100 Ohm (R4), 1/4 W, axial. Supplier: DigiKey or an assortment on hand.
  - [ ] Received: quantity and specification match the order.
- [ ] **ESP32 sockets**, qty 2, $0.80 each, $1.60. Female header 1x19, 2.54 mm, straight. Supplier: DigiKey or Amazon.
  - [ ] Received: quantity and specification match the order.
- [ ] **Module sockets**, qty 5, $0.30 each, $1.50. Female header 1x5, 2.54 mm, straight. Supplier: DigiKey or Amazon.
  - [ ] Received: quantity and specification match the order.
- [ ] **Screw terminals**, qty 3, $0.40 each, $1.20. 2-way screw terminal, 5.08 mm pitch (Phoenix MKDS 1,5 or equal). Supplier: DigiKey or Amazon.
  - [ ] Received: quantity and specification match the order.
- [ ] **Standoffs**, qty 4, $0.50 each, $2.00. M3 x 10 mm nylon standoff with screw. Supplier: Amazon.
  - [ ] Received: quantity and specification match the order.

## Tools and safety equipment (not in the budget)

- [ ] Multimeter with continuity and resistance ranges
- [ ] Bathroom scale (0.1 kg graduation)
- [ ] Vise, pipe cutter for 3/4 in pipe, and pipe wrenches
- [ ] Drill with hole saws or step drill: 22.5 mm (buttons), 28.7 mm and 44.2 mm (drum lid), 16.5, 20.5 and 25.5 mm (glands)
- [ ] Jigsaw or nibbler and file for the 45 x 45 mm REX-C100 cutout
- [ ] Tin snips and pop rivet gun
- [ ] Stopwatch and 159 L (42 gal) contractor bags for the airflow calibration
- [ ] Contact or infrared thermometer for jacket and stack surfaces (all five MAX6675 channels are in use)
- [ ] Insulation tester at 500 V, borrowed or rented, for TBK-TST-001 TP2
- [ ] P100 or N95 respirator, gloves and eye protection for sand and mineral wool

## Before building

- [ ] Every Received box ticked and every arrival check passed.
- [ ] Heater resistances recorded for TBK-TST-001 TP0.
- [ ] Firmware built and host unit tests passing (`pio test -e native` in `firmware/`).
- [ ] Analysis self-test passing (`python docs/05-tests/tbk_tst_001_fit.py selftest`).

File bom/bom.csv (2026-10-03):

item | qty | spec | supplier | unit_cost_usd | make_buy | notes
55 gal steel drum | 1 | Open-head steel drum, 55 US gal, unlined, 18 ga body, 16 ga lid, bolted closing ring, ID 571.5 mm | Uline or local drum reconditioner | 150.00 | buy | Storage vessel. Strip exterior paint before first firing. No interior liner or coating.
Sand, 210 kg fill | 10 | Washed play sand, 50 lb (22.7 kg) bag, sieved to remove fines; 227 kg bought for 210 kg fill | Home Depot or Lowe's (Quikrete play sand or equal) | 6.50 | buy | Storage medium. Dried in place during bake-out; see TBK-PRC-001.
Nichrome heating elements | 12 | Cartridge heater, 5/8 in x 20 in (15.9 x 508 mm), 240 V, 250 W, Incoloy 800 sheath, NiCr 80/20 winding in MgO, 2 in cold end, 72 in (1829 mm) ceramic-beaded nickel leads | Tempco or Watlow (or equal industrial heater supplier) | 49.00 | buy | 1.1 W/cm2 watt density. Rated sheath 760 C; controller keeps it below 700 C. 72 in leads reach the junction box from every well (TBK-DDR-003 P9).
Heater well pipe | 4 | Black steel pipe, 3/4 in Sch 40, ASTM A53, 10 ft; cut to twelve 876 mm wells, threaded one end | Home Depot or Lowe's | 32.00 | buy | Not galvanized. Three wells per stick. Each well stands on its cap on a levelled 14 mm first lift of sand (TBK-DDR-003 P1).
Heater well cap | 12 | Black malleable iron cap, 3/4 in NPT | Home Depot or Lowe's | 3.50 | buy | Assemble with nickel anti-seize; no PTFE tape or paste.
U-tube pipe | 5 | Black steel pipe, 1-1/4 in Sch 40, ASTM A53, 10 ft; cut to six 1175 mm inlet legs (two per stick) and six 866 mm outlet legs (three per stick), threaded one end | Home Depot or Lowe's | 55.00 | buy | Discharge heat exchanger.
U-tube elbow | 12 | Black malleable iron 90 deg elbow, 1-1/4 in NPT | Home Depot or Lowe's | 9.00 | buy | Two per U-tube.
U-tube nipple | 6 | Black steel nipple, 1-1/4 in x 4 in | Home Depot or Lowe's | 7.00 | buy | Radial run at the bottom of each U-tube. With two elbows it sets the 155 mm leg spacing (TBK-DDR-003 P2).
Nickel anti-seize | 1 | Nickel anti-seize compound, rated 1300 C, 8 oz | McMaster-Carr or auto parts store | 18.00 | buy | All threads inside the drum.
Collector shell | 1 | Single-wall black stovepipe, 10 in, 24 ga, 24 in length; cut an 80 mm ring | Home Depot or Lowe's | 32.00 | buy | Hot collector on the lid over the six outlet legs.
Collector top and outlet collar | 1 | Steel sheet 18 ga, 12 x 12 in, plus 4 in crimped start collar | Home Depot or Lowe's | 22.00 | make | Top disc with its edge folded down over the ring and riveted; the ring's foot is cut into six tabs folded out and riveted to the lid with steel rivets (TBK-DDR-003 P7). Seal with AES rope.
Hot outlet duct | 1 | Single-wall black stovepipe kit, 4 in, 24 ga: 24 in length and two adjustable 90 deg elbows | Home Depot or Lowe's | 40.00 | buy | Rises and turns down as a heat trap. Guard it; keep 450 mm from combustibles.
Mixing tee | 1 | Black stovepipe tee, 4 in, 24 ga | Home Depot or Lowe's | 20.00 | buy | Hot branch meets room air; air downstream is 60 C or below.
Inlet damper | 1 | Manual butterfly damper, 4 in, galvanized, with blade shaft extended for servo drive | Home Depot or Lowe's | 12.00 | buy | Cold side. Closed whenever the fan is off.
Inlet damper servo | 1 | Metal-gear hobby servo, 180 deg, 5 to 6 V, 10 kg cm (MG996R class) | Amazon or Adafruit | 12.00 | buy | Modulates heat output. Linkage stays below 40 C.
Bypass damper | 1 | Manual balancing damper, 4 in, galvanized | Home Depot or Lowe's | 12.00 | buy | Sets the room-air share at the mixing tee.
Inline fan | 1 | EC inline duct fan, 4 in (100 mm), at least 60 L/s at 150 Pa, PWM or 0-10 V speed input, air temperature rating 60 C or higher | AC Infinity CLOUDLINE T4 or Vents TT PRO 100 (confirm speed interface) | 130.00 | buy | Pulls through the exchanger and bypass; delivers mixed air at 50 C.
Supply duct and register | 1 | Insulated flexible duct 4 in x 8 ft, clamps and a 4 in floor or wall register | Home Depot or Lowe's | 35.00 | buy | Downstream of the fan only.
Ceramic fiber insulation | 2 | AES (body-soluble) fiber blanket, 25 mm x 610 mm x 7.62 m (1 in x 24 in x 25 ft), 128 kg/m3, rated 1100 C or higher | Superwool Plus (Morgan Thermal Ceramics) via a kiln or refractory supplier | 130.00 | buy | Two layers on the drum side and 50 mm hot face in the headspace and over the lid. AES replaces RCF for handling safety.
AES fiber board | 1 | Rigid AES fiber board, 25 mm, 610 x 914 mm, rated 1100 C or higher | Kiln or refractory supplier | 70.00 | buy | Hot face under the drum, cut to a 610 mm disc (TBK-DDR-003 P5).
Insulating firebrick | 16 | K-23 insulating firebrick, 230 x 114 x 64 mm | Kiln or refractory supplier | 6.00 | buy | One course laid flat, cut to a 610 mm disc under the drum; 15 bricks needed with cuts, one spare (TBK-DDR-003 P5). Carries the load.
Stone wool batt | 3 | Stone wool batt, 89 mm (3.5 in), 15.25 x 47 in, 59.7 ft2 per pack | ROCKWOOL Comfortbatt R15 via Home Depot or Lowe's | 75.00 | buy | Three layers on the side; headspace and over the lid; one layer as the 89 mm ring round the firebrick disc in the base (TBK-DDR-003 P5). Binder burns off on first heat.
Stone wool board | 4 | Stone wool board, 50 mm, 610 x 1219 mm, compressive strength 60 kPa or higher at 10 % strain | ROCKWOOL Comfortboard 110 or ProRox board | 45.00 | buy | Two layers across the full base. Verify the data sheet strength before purchase.
AES rope gasket | 2 | AES fiber rope, 12 mm, 3 m | Kiln or refractory supplier | 20.00 | buy | Lid, collector, lid penetrations (a collar round every pipe) and the outlet packing.
Jacket sheet | 2 | Galvanized steel flashing coil, 0.4 to 0.6 mm, 610 mm x 15.2 m (24 in x 50 ft) | Home Depot or Lowe's | 65.00 | buy | Side wrap in three rows plus the top cap and inlet plenum. Surface stays below 30 C.
Jacket fasteners and tape | 1 | Aluminum pop rivets, steel pop rivets (collector tabs), stainless sheet metal screws (jacket cap), aluminum foil tape | Home Depot or Lowe's | 30.00 | buy | The cap is screwed, not riveted, so it can be lifted for heater service (TBK-DDR-003 P11).
ESP32 controller | 1 | ESP32-DevKitC-32E, 4 MB flash | Espressif via DigiKey or Mouser | 11.00 | buy | Charge and discharge control; logs to local API.
Thermocouple amplifier | 7 | MAX31856 universal thermocouple amplifier breakout, SPI | Adafruit (product 3263) | 17.50 | buy | Two well-wall, four sand and one collector channel.
K-type thermocouples | 8 | Type K, mineral insulated, 3 mm Inconel 600 sheath, 1500 mm, ungrounded junction, mini plug | Omega or Auber Instruments (or equal) | 26.00 | buy | Seven on the controller and one on the independent limit. 1500 mm reaches the exit grommet on the jacket cap from every point; spare length is coiled in the top insulation (TBK-DDR-003 P10).
Air temperature sensor | 3 | DS18B20 digital probe, stainless tip, 1 m lead | Adafruit or Amazon | 4.00 | buy | Room, supply air and jacket surface.
Solid state relay | 2 | Zero-cross SSR, 25 A, 24 to 280 VAC load, 3 to 32 VDC control | Crydom D2425 via DigiKey or Mouser | 60.00 | buy | One per six-heater group (1.5 kW each). Burst-fire control.
SSR heat sink | 2 | Panel heat sink for single-phase SSR, 2 K/W or better, with thermal pad | DigiKey or Mouser | 15.00 | buy | 7.5 W per SSR at 6.25 A.
Safety contactor | 1 | Definite-purpose contactor, 2-pole, 30 A, 24 VAC coil | Grainger or HVAC supply | 30.00 | buy | Opens both legs when any limit trips.
Control transformer | 1 | Control transformer, 240 VAC to 24 VAC, 40 VA, with fused secondary | Grainger or HVAC supply | 22.00 | buy | Powers the contactor coil through the limit chain.
Independent high limit | 1 | 1/16 DIN temperature controller, type K input, relay output, latching alarm with manual reset | Auber Instruments or equal | 45.00 | buy | Trips the contactor at 600 C well-wall temperature. Separate from the ESP32.
Branch fuses | 2 | 2-pole DIN rail fuse holder with 10 A class CC fuses | DigiKey or Mouser | 15.00 | buy | Supplementary protection per heater group.
DC power supply | 1 | DIN rail power supply, 12 VDC, 2 A, with 5 V buck converter | DigiKey or Mouser | 25.00 | buy | ESP32, servo and fan signal.
Export meter | 1 | Two-channel Wi-Fi energy meter with 50 A CT clamps and local API | Shelly Pro EM-50 | 90.00 | buy | Measures grid export at the main panel; sets the charge power.
GFCI breaker | 1 | 2-pole 20 A, 5 mA (Class A) GFCI breaker to match the existing panel | Home Depot or Lowe's | 110.00 | buy | Dedicated 240 V circuit (decision of 2026-10-02, TBK-DEC-001). 30 mA protection only as a measured exception agreed with the installing electrician. Installed by a licensed electrician where required.
Branch wiring | 1 | 12 AWG THHN copper, conduit, fittings and disconnect | Home Depot or Lowe's | 80.00 | buy | 20 A circuit to the control enclosure.
Control enclosure | 1 | Steel enclosure 300 x 250 x 150 mm, DIN rail, terminal blocks, cable glands | DigiKey or Automation Direct | 70.00 | buy | Mounted on the wall beside the unit.
Heater junction box | 1 | Steel junction box 150 x 150 x 100 mm with ceramic terminal blocks | Home Depot plus McMaster-Carr | 35.00 | buy | On the jacket top; gathers the 24 heater leads.
Setting template | 1 | Exterior plywood 18 mm, 610 x 610 mm (2 x 2 ft), cut to a 597 mm disc and drilled as the lid plus five pour holes | Home Depot or Lowe's | 18.00 | make | Temporary jig that holds the wells, U-tubes and thermocouples upright on the drum rim during the sand fill (TBK-DDR-003 P4). Not part of the finished unit.
Outlet trim ring | 1 | Uncoated (black) steel sheet 18 ga, 12 x 12 in, cut to a 250 mm ring with a 106 mm hole | Home Depot or Lowe's | 12.00 | make | Covers the AES packing where the hot outlet passes through the galvanized jacket cap; keeps zinc 39 mm from the hot pipe (TBK-DDR-003 P8).
Thermocouple guide rods | 4 | Stainless steel rod 3/16 in (4.8 mm) x 36 in, with stainless tie wire | McMaster-Carr or welding supply | 3.00 | buy | Cut to 561 mm. One beside each sand thermocouple T4 to T7, standing on the drum floor.
Cap grommets | 1 | Silicone rubber grommets, 40 mm and 25 mm hole sizes, rated 200 C, pack | McMaster-Carr | 9.00 | buy | Heater lead hole under the junction box and the thermocouple exit in the jacket cap.
Warning labels | 1 | Self-adhesive vinyl labels rated 105 C or higher: HOT SURFACES INSIDE (jacket side), HOT OUTLET (jacket cap), HOT SURFACE (outlet guard sleeve), DANGER 240 V (junction box and control enclosure) | Amazon or a safety-sign supplier (Brady or equal) | 15.00 | buy | Five labels, one pack per site. Positions in TBK-BLD-001 step 22 (decision of 2026-10-02, TBK-DEC-001). Basis: about USD 3 per 100 x 65 mm label.

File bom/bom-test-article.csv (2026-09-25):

item | qty | spec | supplier | unit_cost_usd | make_buy | notes
Steel drum | 1 | Open-head steel drum, 16 US gal, unlined, 20 ga, bolt ring; 13.5 in (343 mm) ID x 26.5 in (673 mm) high | Uline S-19411 | 115.00 | buy | Strip the exterior paint and discard the lid gasket before first firing. Seal the lid with stone wool strip.
Sand | 3 | Washed play sand, 50 lb (22.7 kg) bag; 68 kg fill | Home Depot or Lowe's (Quikrete play sand or equal) | 6.50 | buy | 5.9 kWh(th) between 150 and 450 C. Weigh every bag.
Nichrome heating elements | 4 | Cartridge heater, 5/8 in x 18 in (15.9 x 457 mm), 120 V, 250 W, stainless or Incoloy sheath, NiCr winding in MgO, 16 in heated, 2 in cold end, 24 in high-temperature leads | Made-to-order import cartridge heater supplier (Amazon or AliExpress) | 18.00 | buy | Same diameter and linear power class as the full-scale heater. Measure each cold resistance on arrival (57.6 ohm hot nominal).
Heater well pipe | 1 | Black steel pipe, 3/4 in Sch 40, ASTM A53, 10 ft; cut to four 692 mm wells (C1 in docs/07-build/cut-list.md), bottoms crimped closed in a vise | Home Depot or Lowe's | 28.00 | buy | Not galvanized. No threading needed.
U-tube legs | 2 | Black steel nipple, 1-1/4 in x 36 in | Home Depot or Lowe's | 28.00 | buy | One inlet leg and one outlet leg.
U-tube elbow | 2 | Black malleable iron 90 deg elbow, 1-1/4 in NPT | Home Depot or Lowe's | 8.00 | buy | Dry threads; the joint is never taken apart.
U-tube bottom nipple | 1 | Black steel nipple, 1-1/4 in x 6 in | Home Depot or Lowe's | 6.00 | buy | Sets the 206 mm leg spacing.
Inlet blower | 1 | 12 V DC centrifugal blower, 97 x 94 x 33 mm, about 12 L/s free air, 0.8 A or less | Amazon (9733 blower or equal) | 10.00 | buy | Taped to the inlet leg; PWM speed from the ESP32. Removed and the leg taped shut for standby tests.
Blower driver | 1 | Logic-level MOSFET PWM module, 5 A | Amazon | 3.00 | buy
12 V supply | 1 | DIN-rail supply 12 VDC 1.25 A (15 W), 85 to 264 VAC in, 17.5 x 90 x 54.5 mm | Mean Well HDR-15-12 via DigiKey or Mouser | 12.00 | buy | PS1 on TBK-DWG-003 Rev P2. Blower and controller power; wired inside the enclosure (TBK-DWG-005).
Buck converter | 1 | 12 V to 5 V buck converter, 3 A | Amazon | 3.00 | buy | Powers the ESP32.
Dilution stack | 1 | Single-wall black stovepipe, 4 in, 24 ga, 24 in | Home Depot or Lowe's | 12.00 | buy | Over the outlet leg; room air drawn in at the open bottom dilutes the exchanger air. Held with steel tie wire.
Stone wool batt | 2 | Stone wool batt, 89 mm (3.5 in), 15.25 x 47 in, 59.7 ft2 per pack | ROCKWOOL Comfortbatt R15 via Home Depot or Lowe's | 60.00 | buy | Three side layers, two in the headspace, two over the lid, and the base fill: about 5.98 m2 (cut list C9), so two packs. Binder burns off on first heat.
Insulating firebrick | 4 | K-23 insulating firebrick, 230 x 114 x 64 mm | Kiln or refractory supplier | 5.50 | buy | Stood on edge under the chime. Bearing stress 0.55 MPa against about 1 MPa crushing strength.
Jacket sheet | 1 | Aluminum roll flashing, 20 in x 25 ft | Home Depot or Lowe's | 30.00 | buy | Side wrap in two rows plus the top cap. Runs at 26 C, so aluminum is acceptable here.
Jacket fasteners and tape | 1 | Aluminum foil tape and sheet metal screws | Home Depot or Lowe's | 8.00 | buy | Tape also seals the pipe ends for standby tests.
ESP32 controller | 1 | ESP32 development board (ESP32-WROOM-32) | Amazon or Espressif via DigiKey | 7.00 | buy | Charge control on the well-wall thermocouple and 10 s logging over Wi-Fi.
Thermocouple amplifier | 1 | MAX6675 module with K probe, pack of five | Amazon | 15.00 | buy | Five channels: well wall, sand center, sand near the drum wall, U-tube outlet air and room air. The two kit probes serve the air channels (400 C or below).
K-type thermocouples | 4 | Type K, mineral insulated, ungrounded junction, 3 mm 310 or 304 stainless sheath, 500 mm, 1 m lead | Amazon (or Omega or Auber for tighter tolerance) | 8.00 | buy | Well wall (control), well wall (limit), sand center, sand near the drum wall.
Solid state relay | 1 | Zero-cross SSR, 25 A, 24 to 380 VAC load, 3 to 32 VDC control | Amazon (SSR-25DA or equal) | 9.00 | buy | Switches all four heaters. A shorted SSR is covered by the latching relay.
SSR heat sink | 1 | Aluminum SSR heat sink with thermal pad | Amazon | 6.00 | buy | About 10 W dissipation at 8.3 A.
Independent high limit | 1 | REX-C100 temperature controller, relay output (R*AN), type K input, 120 VAC supply | Amazon | 14.00 | buy | Set as an on-off permissive that opens at 600 C well-wall temperature. Wired into the latching relay coil circuit.
Latching power relay | 1 | Power relay, DPDT, 30 A per pole, 120 VAC coil, with DIN-rail socket (JQX-30F 2Z class) | Amazon | 10.00 | buy | K1 on TBK-DWG-003. Pole 1 switches the heaters; pole 2 is the holding contact that latches it after START.
Start and stop buttons | 1 | Momentary pushbuttons, one normally open (START) and one normally closed (STOP), 22 mm | Amazon | 5.00 | buy | Any limit trip or power loss drops the relay until START is pressed.
Control enclosure | 1 | Polycarbonate wall enclosure 250 x 200 x 150 mm, IP65, UL 94 V-0 or 5VA, with steel mounting plate | Amazon or an electrical wholesaler | 30.00 | buy | TBK-DWG-005. A 100 mm deep box cannot take the REX-C100, which needs 98 mm behind the lid.
DIN rail | 1 | TS35 x 7.5 DIN rail, 250 mm, cut to 152 mm | Amazon or an electrical wholesaler | 3.00 | buy | Carries PS1 and the K1 socket.
Cable glands | 4 | Nylon cable gland IP68 with locknut: one M16, two M20, one M25 | Amazon (assortment) | 1.50 | buy | Bottom face: thermocouples (M25), blower (M16), supply cord and heater cable (M20).
Lever connectors and PE stud | 1 | Two 5-way lever connectors (Wago 221-415 or equal), M5 earth stud with ring lugs | Amazon or Home Depot | 5.00 | buy | L_F and N junctions under the REX-C100; PE stud on the mounting plate.
Fuse | 1 | Inline fuse holder with 10 A fast-acting fuse | Home Depot or auto parts store | 5.00 | buy | Protects the heater leads.
Supply cord | 1 | 14/3 SJT cord with NEMA 5-15 plug, 6 ft | Home Depot or Lowe's | 8.00 | buy | Plugs into a GFCI-protected 15 A or 20 A garage receptacle; 8.3 A load.
Pull-down resistors | 2 | Resistor, 10 kOhm, 1/4 W, 5 % | DigiKey or an assortment on hand | 0.10 | buy | R1 and R2 on TBK-DWG-003: hold the SSR and blower off through ESP32 boot and reset.
Heater junction box | 1 | Steel handy box with a ceramic terminal block | Home Depot plus Amazon | 8.00 | buy | On the jacket top; gathers the eight heater leads.
Heater cable | 1 | 16/3 SJT cord, 2 m (6 ft), no plug | Home Depot or Lowe's | 8.00 | buy | Junction box to controller enclosure: L_HEAT, N and PE (drum bond).
Wiring consumables | 1 | 16 AWG and 22 AWG stranded hookup wire rated 105 C, insulated ferrules, ring lugs and heat-shrink assortment | Amazon | 12.00 | buy | Panel wiring per cut list C12.
Thermocouple extension | 1 | Type K extension wire, 20 AWG, 5 m, with six pairs of miniature type K connectors | Amazon | 12.00 | buy | Extends the 1 m probe leads to the enclosure; yellow positive, red negative.

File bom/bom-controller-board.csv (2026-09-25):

item | qty | spec | supplier | unit_cost_usd | make_buy | notes
Printed circuit board | 1 | 110 x 80 mm, 2 layer FR-4 1.6 mm, 1 oz copper, HASL; gerbers in electronics/controller-board (minimum order of 5 shares the cost) | JLCPCB or PCBWay | 15.00 | buy | Cost of one order of five boards including economy shipping.
Regulator | 1 | RECOM R-78E5.0-1.0, 12 V to 5 V switching regulator, SIP-3 (U1) | DigiKey or Mouser | 4.50 | buy | Replaces the buck converter module in bom-test-article.csv.
Input capacitor | 1 | Aluminum electrolytic 10 uF 25 V, 5 mm diameter, 2 mm pitch (C1) | DigiKey or Mouser | 0.20 | buy
Output capacitor | 1 | Aluminum electrolytic 22 uF 10 V, 5 mm diameter, 2 mm pitch (C2) | DigiKey or Mouser | 0.20 | buy
SSR driver transistor | 1 | 2N3904 NPN, TO-92 (Q1) | DigiKey or Mouser | 0.10 | buy | Drives the SSR input from 5 V.
Blower MOSFET | 1 | IRLZ44N logic-level N-MOSFET, TO-220 (Q2) | DigiKey or Mouser | 1.20 | buy | Replaces the MOSFET module in bom-test-article.csv.
Flyback diode | 1 | 1N5819 Schottky, DO-41 (D1) | DigiKey or Mouser | 0.15 | buy | Across the blower.
Resistors | 2 | 1 kOhm (R3) and 100 Ohm (R4), 1/4 W, axial | DigiKey or an assortment on hand | 0.10 | buy | R1 and R2 (10 kOhm) are already in bom-test-article.csv.
ESP32 sockets | 2 | Female header 1x19, 2.54 mm, straight | DigiKey or Amazon | 0.80 | buy | For the ESP32-DevKitC V4 (U2). Rows 25.4 mm apart.
Module sockets | 5 | Female header 1x5, 2.54 mm, straight | DigiKey or Amazon | 0.30 | buy | For the MAX6675 modules (U3 to U7).
Screw terminals | 3 | 2-way screw terminal, 5.08 mm pitch (Phoenix MKDS 1,5 or equal) | DigiKey or Amazon | 0.40 | buy | J1 12 V in, J2 SSR drive, J3 blower.
Standoffs | 4 | M3 x 10 mm nylon standoff with screw | Amazon | 0.50 | buy | Mounts the board in the control enclosure.

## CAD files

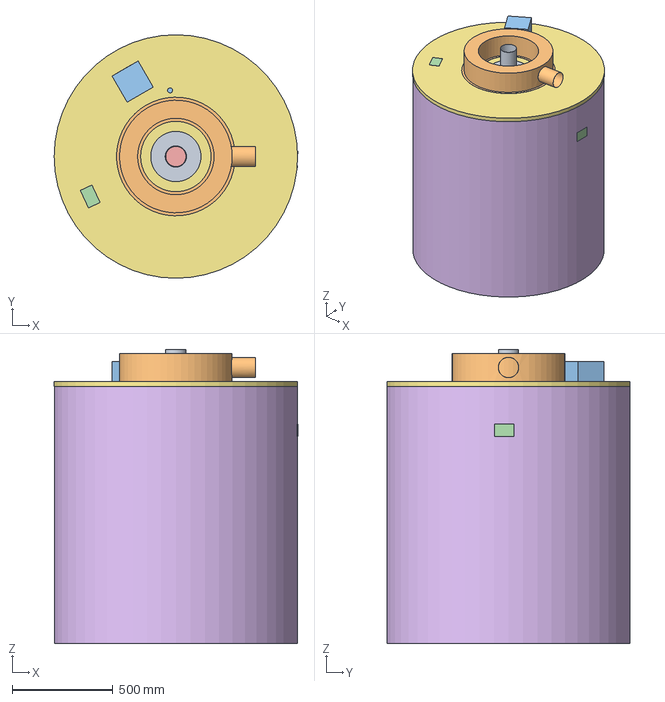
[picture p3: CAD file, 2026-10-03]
cad/step/thermabrick.step
1211.5 x 1210.3 x 1461.6 mm

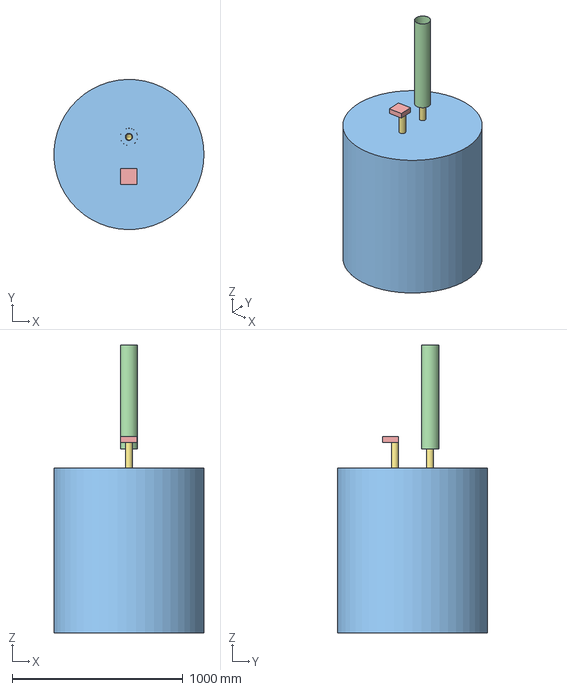
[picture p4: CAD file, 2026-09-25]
cad/step/thermabrick-test-article.step
878.9 x 879.3 x 1687.6 mm

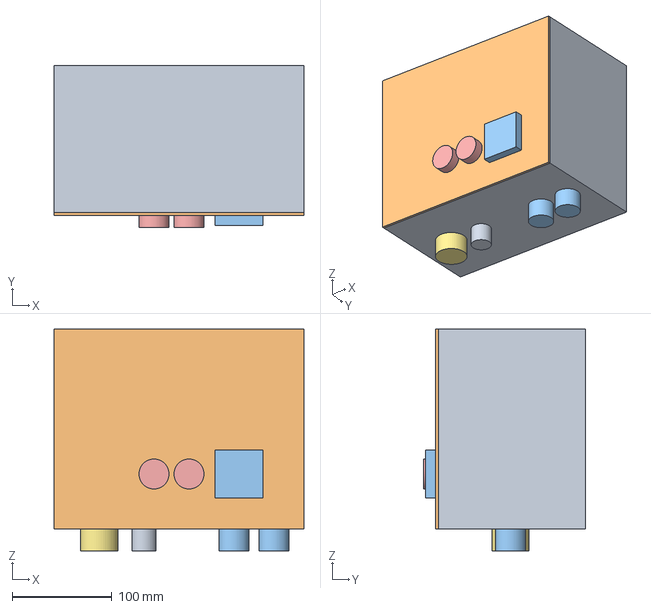
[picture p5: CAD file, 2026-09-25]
cad/step/thermabrick-controller-enclosure.step
250.0 x 162.0 x 222.0 mm

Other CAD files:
archive/out-of-phase-trl4/cad/stl/thermabrick-controller-enclosure.stl
archive/out-of-phase-trl4/cad/stl/thermabrick-test-article.stl
cad/stl/thermabrick-controller-enclosure.stl
cad/stl/thermabrick-test-article.stl
cad/stl/thermabrick.stl

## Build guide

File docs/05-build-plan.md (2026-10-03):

---
doc_id: TBK-BLD-001
title: ThermaBrick prototype build plan
project: ThermaBrick
doc_type: Build plan
version: "0.2"
status: Draft
date: '2026-10-02'
author: Amish Chadha
license: CERN-OHL-S-2.0
revisions:
  - version: "0.1"
    date: '2026-10-01'
    author: Amish Chadha
    change: First build plan, with pictures by component and step; design made constructable (TBK-DDR-003)
  - version: "0.2"
    date: '2026-10-02'
    author: Amish Chadha
    change: Step 22 and Figure 26 added for the five warning labels (BOM line 47); label line in the bought components
---

# ThermaBrick prototype build plan

**Plan, not yet built.** How to build the first full-scale proof-of-concept ThermaBrick, component by component. Building and testing to it is TRL 4 work, which is on hold. Decisions still to be made are kept in the design decisions register ([docs/06-design-decisions.md](06-design-decisions.md)), not here.

## 1. What you are building

Figure 1. Every component, pulled apart and numbered in build order

*Figure 1. Every component pulled apart and numbered in build order, in four columns: the base; the drum and the pipes that stand in it; what goes into and onto the drum; the jacket and what sits on top. The setting template (9) is a temporary jig.*

ThermaBrick is a 55 US gal steel drum filled with 210 kg of dry sand, with twelve electric heaters in capped steel pipes (the wells) to charge it and six steel U-tubes to carry room air through it and take the heat out. The drum stands on an insulated base and is wrapped in 317 mm of fiber insulation inside a galvanized steel jacket, 1,209 mm across and 1,462 mm high. Figure 1 shows the 21 components in the order you make or fit them. Ten are made in a home workshop: the base layers, the drilled drum lid, a plywood setting template, the wells, the U-tubes, the collector and outlet, the jacket side and cap, a steel trim ring and the inlet plenum. Everything else is bought: sand, heaters, thermocouples, insulation, the air path parts and the controls. The work is cutting and threading black steel pipe, drilling sheet steel with hole saws, cutting firebrick and fiber insulation, and cutting, folding and riveting thin sheet metal. No welding, machining or pressure parts. The parts cost about USD 3,870 from the bill of materials. The finished unit weighs about 415 kg and must stand on a concrete slab.

> **Safety:** The bed runs at up to 550 °C at the heater wells and stays hot for days after the power is off. The heaters run on 240 V: the branch circuit and the control enclosure are wired or checked by a licensed electrician. Pouring sand and cutting firebrick release respirable crystalline silica, and fiber insulation irritates skin, eyes and airways: work outdoors or with local exhaust, and wear a P100 or N95 respirator, gloves, long sleeves and eye protection. The first firing gives off smoke from coatings and the insulation binder. Section 6 lists every stop point.

## 2. What changed to make it buildable

The concept showed what ThermaBrick does and sized it; some of its parts could not be made, fixed or assembled as drawn. Each change below keeps what the unit does, and all of them are recorded in decision record TBK-DDR-003, open for Amish's review.

*Table 1. Changes from the concept.*

| Component | The concept had | The buildable design has | Why |
| --- | --- | --- | --- |
| Heater wells | Wells hanging 14 mm above the drum floor with nothing under them | Each well stands on a levelled 14 mm first layer of sand, at the same height (Figure 9) | Supports the wells without putting hot steel against the drum floor |
| U-tube bottoms | Floating 50 mm above the floor; the listed 2-1/2 in nipple set the legs 118 mm apart, not 155 mm | Two elbows and a 4 in nipple, resting on the floor (Figure 11) | The stock fittings now give the 155 mm leg spacing, and the tube has a firm seat |
| Lid holes | 1 mm clear of each pipe; no way through for the thermocouples | 36 mm holes for the wells, 48 mm for the U-tube legs, 6 mm for four sand thermocouples, a fiber rope collar round each pipe (Figures 5, 6) | The lid can be lowered over 24 pipes at once; the well-wall thermocouples pass beside their wells |
| Holding the pipes during the fill | The lid on spacers, which leaves no way to pour the sand | A plywood setting template on the drum rim, with five pour holes (Figure 7) | Holds every pipe upright until the sand locks it |
| Base | One solid layer; firebrick only under the drum, leaving a gap out to the jacket | A 610 mm firebrick disc and AES board disc, with a ring of stone wool batt round them (Figures 2, 3, 4) | A level, fully filled base; the firebrick still carries the drum |
| Inlet plenum | 110 mm tall, 4 mm of wall round the 4 in collar, no fixing | 140 mm tall, collar hole cut through, flanges riveted to the cap (Figures 23, 24) | Room to rivet the collar; a fixing for the plenum |
| Collector | No fixing to the lid | Six tabs folded out between the wells and riveted to the lid (Figures 13, 14) | A fixing that clears the wells |
| Outlet through the jacket | Galvanized cap touching the hot outlet | A 180 mm hole packed with fiber and covered by a black steel trim ring (Figures 21, 22) | Keeps zinc away from the hot pipe, as requirement R13 asks |
| Heater leads and junction box | 36 in leads, too short for most wells; no position for the box | 72 in leads; the box on the cap at 120°, 430 mm out (Figures 19, 20) | Every lead reaches the box |
| Thermocouples | No route out of the drum; 1,000 mm sheaths too short | Routes through the lid, guide rods for the sand sensors, 1,500 mm sheaths, one exit in the cap (Figures 6, 12) | Every sensor reaches the outside at its stated measuring point |
| Jacket cap | No fixing; drawn as one sheet wider than the flashing | Three lapped strips with a turned-down skirt, held by screws (Figures 16, 18) | The cap can be lifted off to change a heater |

## 3. Making the components

Make and check each component before the assembly step that needs it. Sizes are in millimetres. Angles are measured anticlockwise, seen from above, from a 0° mark on the drum rim (the side where the inlet plenum's collar will point). Workshop tolerance is 2 mm unless a step says otherwise; drawings do not carry tolerances before TRL 4.

### 3.1 Base

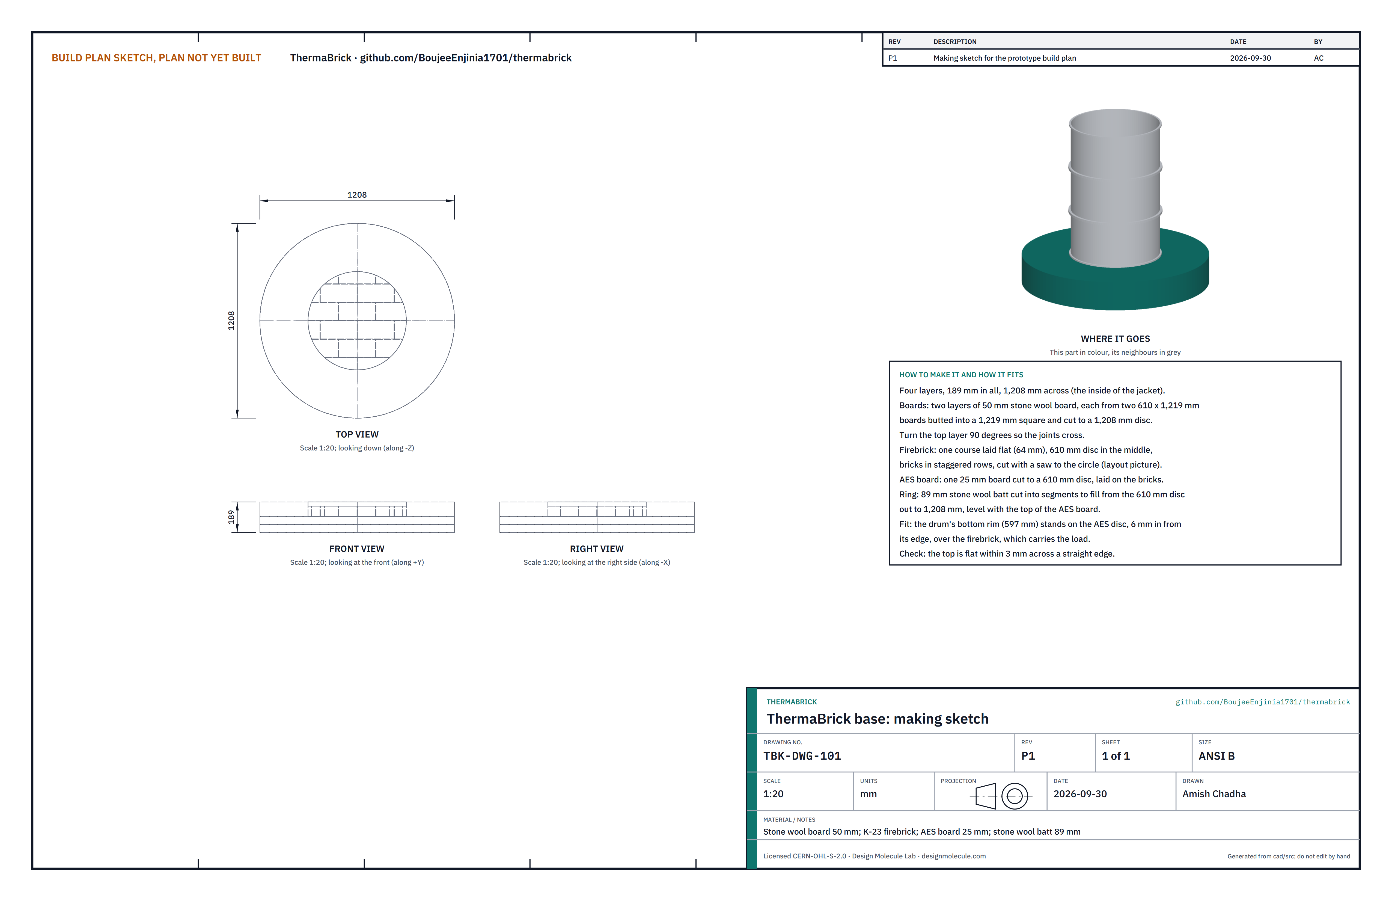
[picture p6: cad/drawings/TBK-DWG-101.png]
Figure 2. Making sketch of the base


*Figure 2. Base making sketch (TBK-DWG-101).*

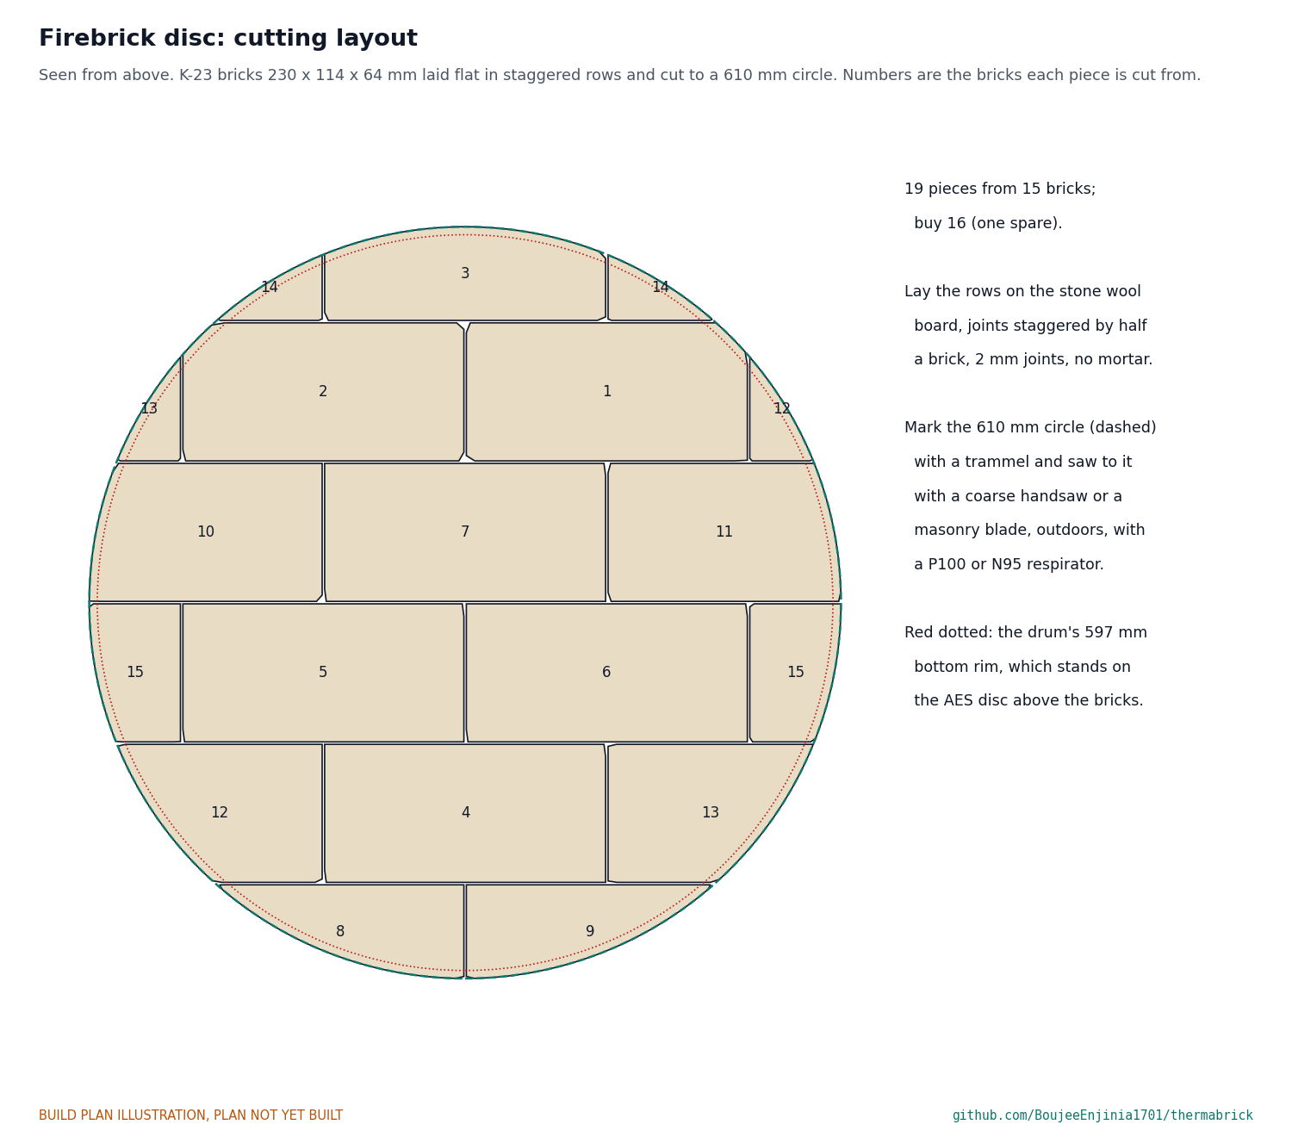
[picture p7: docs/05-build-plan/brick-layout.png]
Figure 3. Firebrick disc cutting layout


*Figure 3. Firebrick disc cutting layout: 19 pieces cut from 15 bricks.*

**What it is and what it is made from.** Four layers, 189 mm thick in all, that carry the drum and keep its heat out of the floor. Two layers of 50 mm stone wool board (four boards of 610 x 1,219 mm); one course of K-23 insulating firebrick laid flat (16 bricks of 230 x 114 x 64 mm); one 25 mm AES fiber board (610 x 914 mm); and a ring of 89 mm stone wool batt.

**How to make it.**

1. Butt two stone wool boards into a 1,219 mm square, draw a 1,208 mm circle with a trammel and cut it with a long serrated knife. Repeat for the second layer.
2. Lay the bricks dry in staggered rows as Figure 3 shows, with 2 mm joints. Mark a 610 mm circle and number the pieces.
3. Cut the bricks outdoors with a coarse handsaw or a masonry blade, wearing a respirator. Use the offcuts for the small edge pieces marked with the same number.
4. Cut a 610 mm disc from the AES board.
5. Cut the 89 mm batt into segments that fill the ring from 610 mm to 1,208 mm across.

**How it fits the parts next to it.**

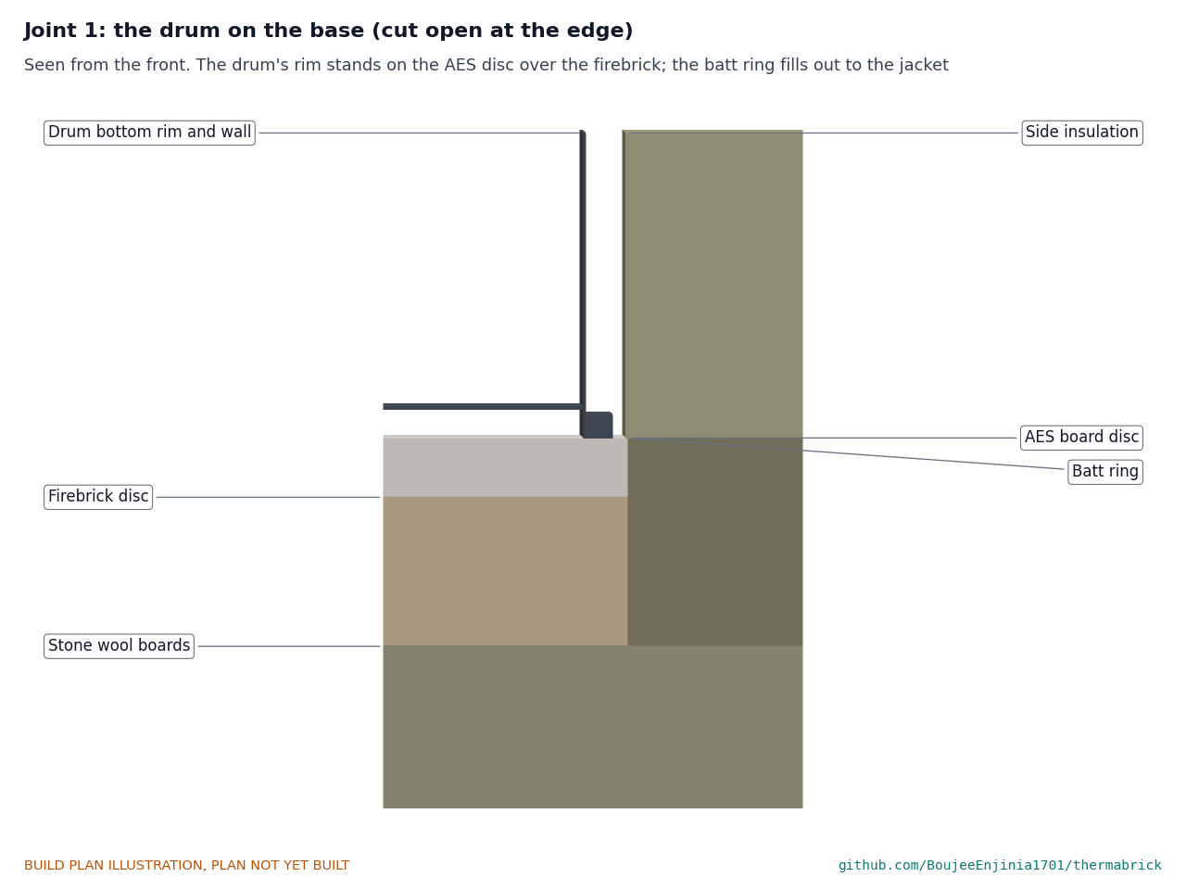
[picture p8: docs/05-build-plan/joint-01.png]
Figure 4. Joint 1: the drum on the base


*Figure 4. The drum's bottom rim stands on the AES disc, 6 mm in from its edge, over the firebrick; the batt ring fills out to the jacket, level with the AES disc.*

The two board layers lie on the slab with their joints crossed. The firebrick disc sits in the middle of the top board, the AES disc on the bricks, and the batt ring round both, all level at 189 mm. The drum's 597 mm bottom rim stands on the AES disc; the firebrick under it carries the full 415 kg.

**Check before moving on.** A straight edge across the top shows no gap over 3 mm; the AES disc does not rock.

### 3.2 Drum and drum lid

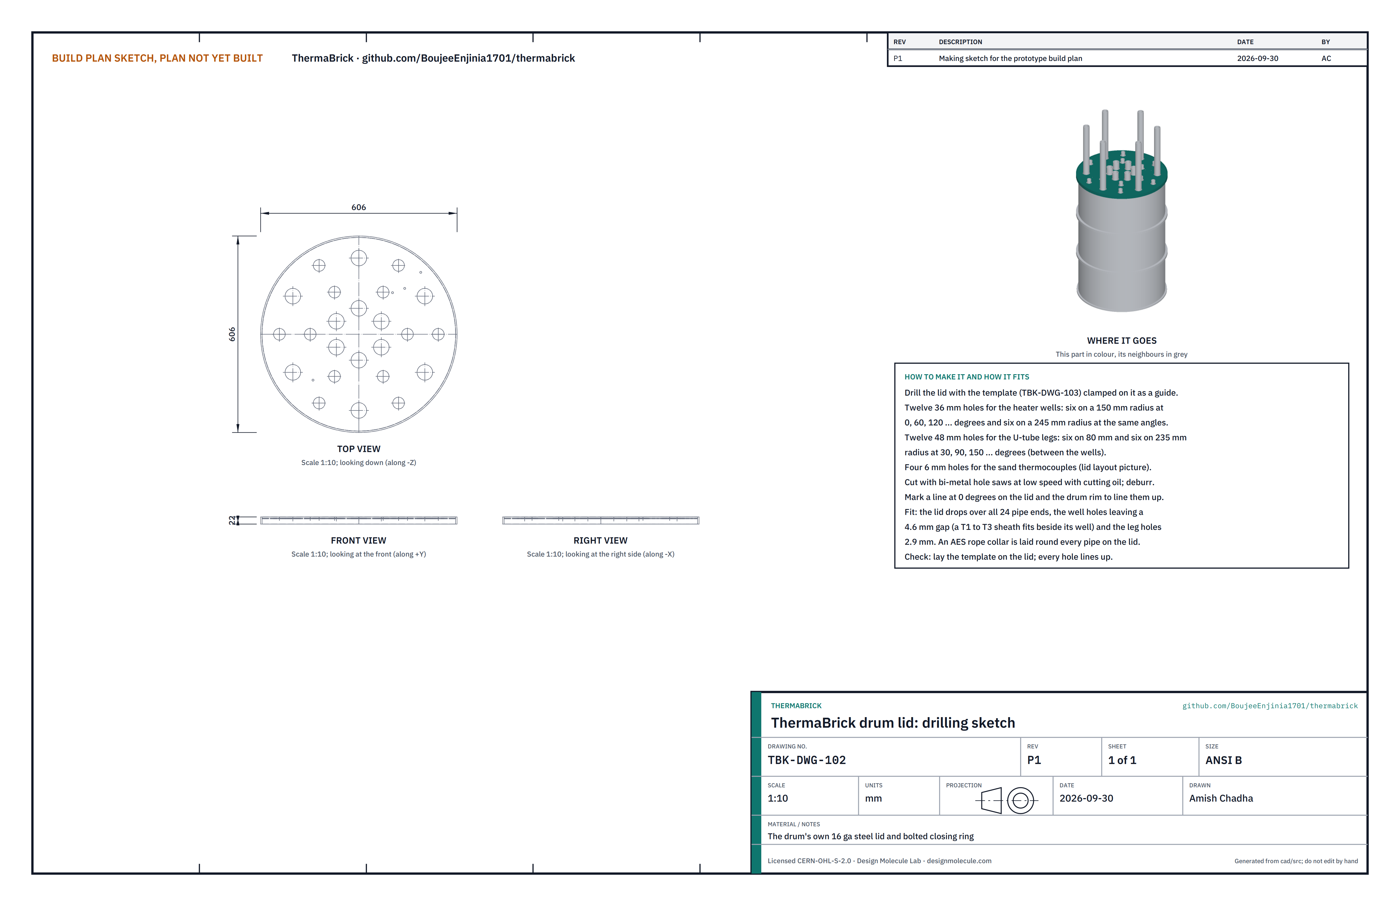
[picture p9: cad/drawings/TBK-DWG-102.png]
Figure 5. Drilling sketch of the drum lid


*Figure 5. Drum lid drilling sketch (TBK-DWG-102).*

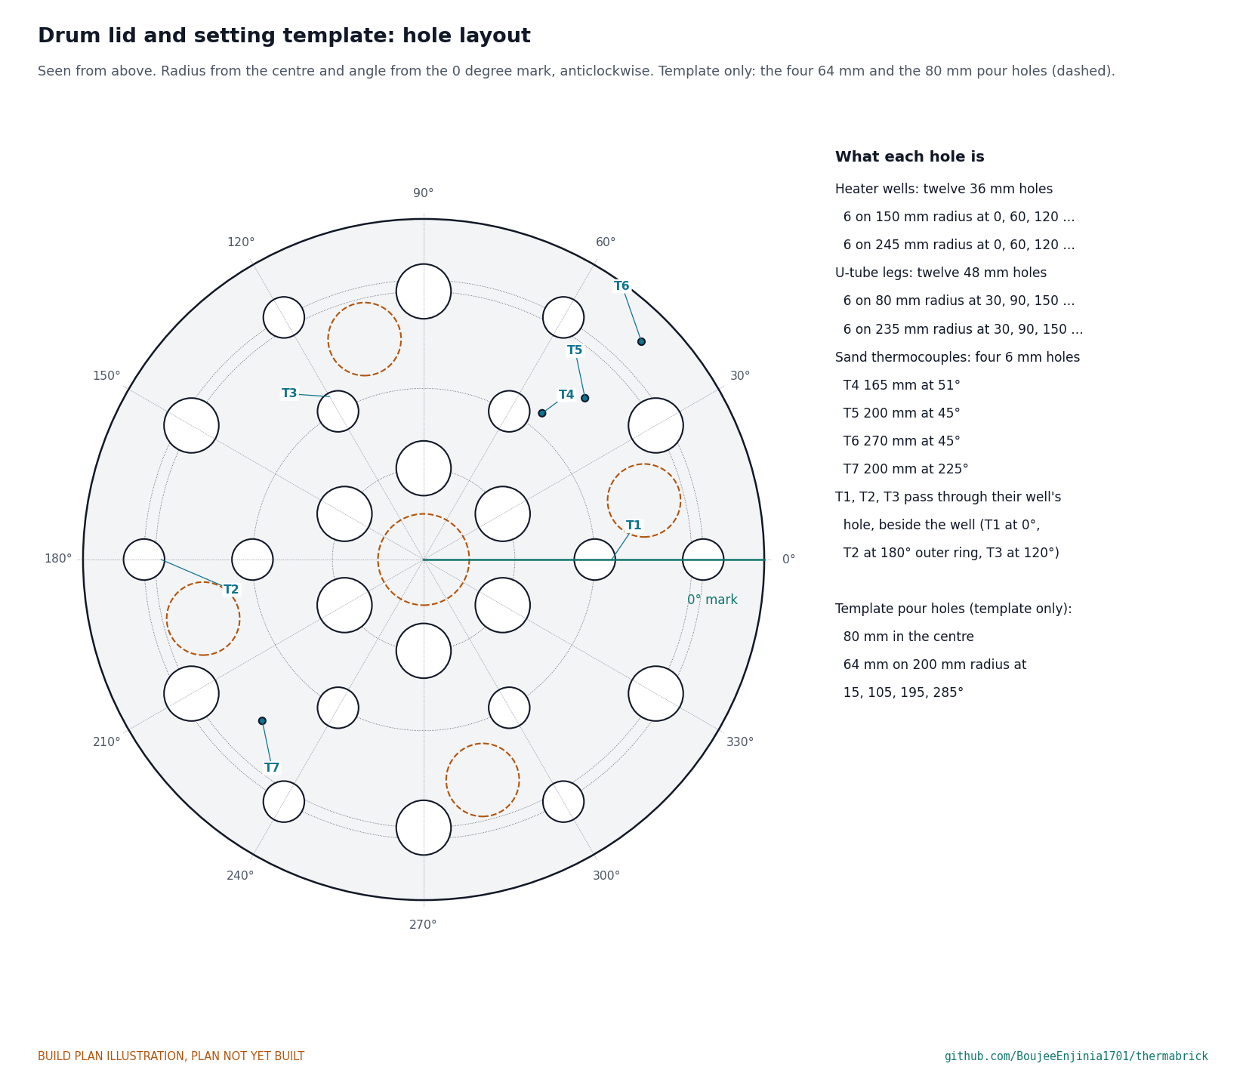
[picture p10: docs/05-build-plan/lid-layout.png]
Figure 6. Lid and template hole layout


*Figure 6. Lid and template hole layout, with the thermocouple positions T1 to T7.*

**What it is and what it is made from.** A new, unlined, open-head 55 US gal steel drum (571.5 mm inside, 883 mm high, 18 ga body) with its 16 ga lid and bolted closing ring. The lid carries 28 holes.

**How to make it.**

1. Strip the outside paint with a flap disc. Burn the empty drum outdoors to about 300 °C (a wood fire round it) to remove residues; let it cool and brush it out.
2. Mark a 0° line on the drum rim and on the lid edge.
3. Make the setting template first (section 3.3), clamp it on the lid with the 0° marks together, and drill through it.
4. Twelve 36 mm holes for the wells: six on a 150 mm radius and six on 245 mm, both at 0, 60, 120, 180, 240 and 300°.
5. Twelve 48 mm holes for the U-tube legs: six on 80 mm and six on 235 mm, at 30, 90, 150, 210, 270 and 330°.
6. Four 6 mm holes for the sand thermocouples: T4 at 165 mm and 51°, T5 at 200 mm and 45°, T6 at 270 mm and 45°, T7 at 200 mm and 225°.
7. Use bi-metal hole saws at low speed with cutting oil; deburr and degrease.

**How it fits the parts next to it.** The lid drops over all 24 pipe ends at once: each well hole leaves 4.6 mm round the well, enough for the well-wall thermocouple beside it, and each leg hole 2.9 mm. A collar of 12 mm AES rope is laid round every pipe on top of the lid, and the closing ring is bolted as the drum maker supplies it. The bed breathes through the collars; nothing is sealed or pressurized.

**Check before moving on.** The template laid on the lid lines up with every hole.

### 3.3 Setting template

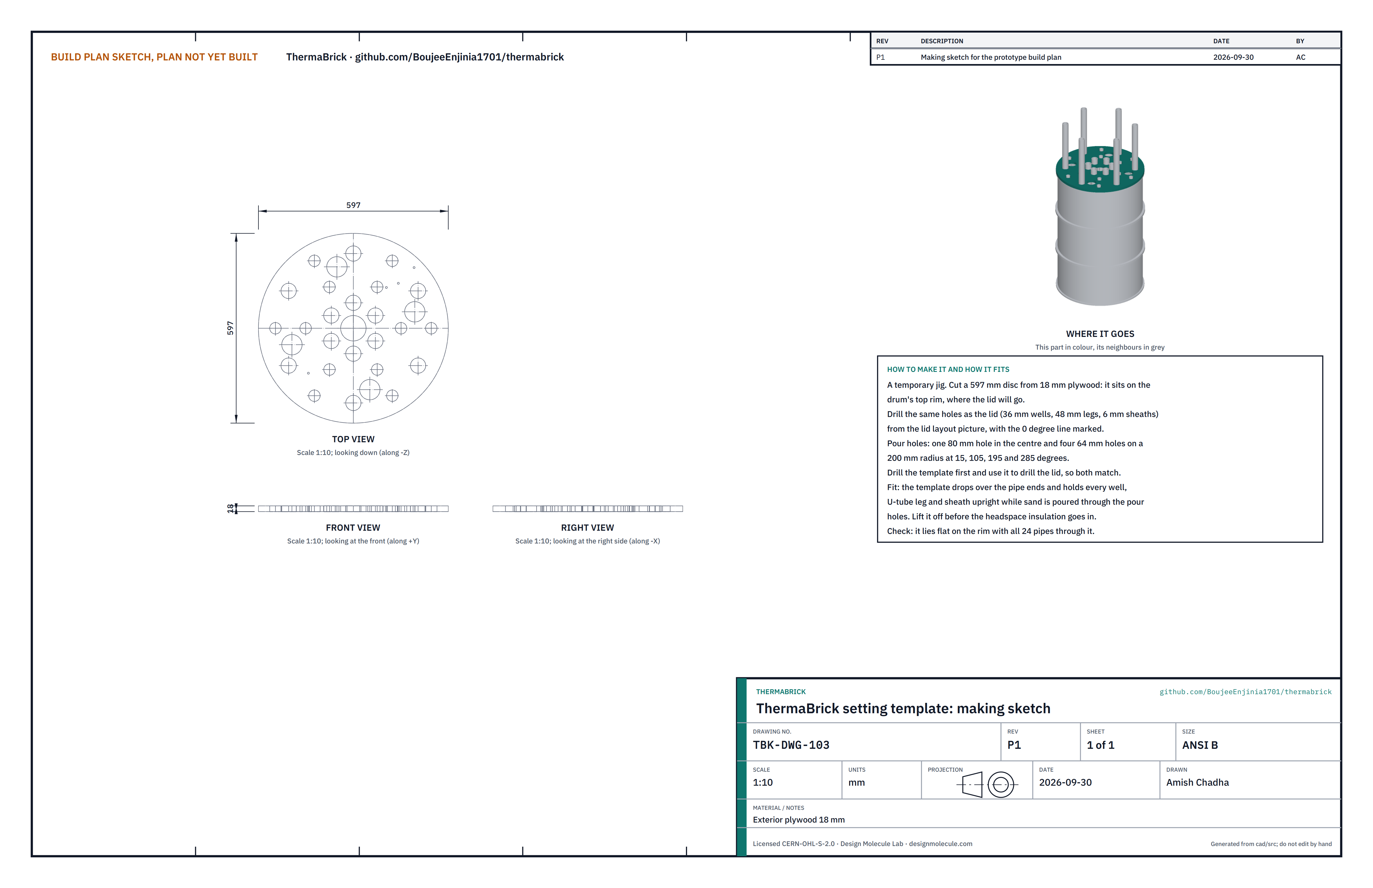
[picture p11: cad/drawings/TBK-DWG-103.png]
Figure 7. Making sketch of the setting template


*Figure 7. Setting template making sketch (TBK-DWG-103).*

**What it is and what it is made from.** A temporary plywood disc that sits on the drum rim and holds every pipe and sensor upright while the sand is poured. Exterior plywood 18 mm, 610 x 610 mm.

**How to make it.**

1. Cut a 597 mm disc. Mark the centre and the 0° line.
2. Drill the 28 holes of Figure 6 with the same hole saws as the lid.
3. Cut the pour holes: 80 mm in the centre and four of 64 mm on a 200 mm radius at 15, 105, 195 and 285°.
4. Sand the edges so it lifts off without snagging.

**How it fits the parts next to it.** It lies on the drum's top rim where the lid will go, 0° marks together, clamped at four points. Every pour hole is at least 10 mm from a pipe hole.

**Check before moving on.** It lies flat on the rim.

### 3.4 Heater wells (make 12)

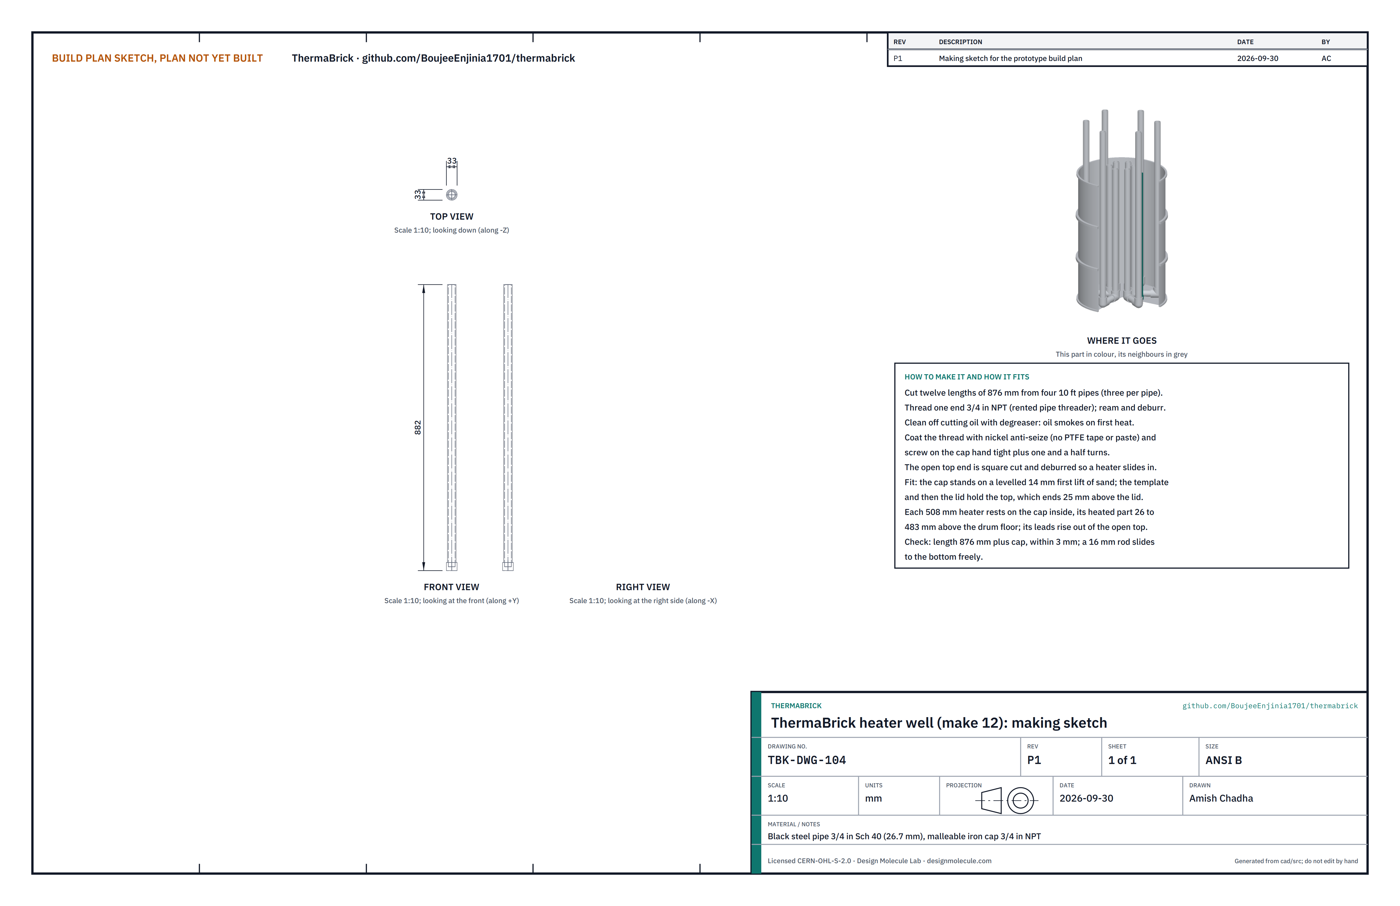
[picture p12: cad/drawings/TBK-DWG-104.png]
Figure 8. Making sketch of the heater well


*Figure 8. Heater well making sketch (TBK-DWG-104).*

**What it is and what it is made from.** A capped steel pipe that a cartridge heater slides into, so the heater never touches the sand and can be pulled out from above. Black (uncoated) steel pipe 3/4 in Sch 40 (26.7 mm outside), four 10 ft lengths; twelve 3/4 in malleable iron caps.

**How to make it.**

1. Cut twelve lengths of 876 mm, three from each pipe. Square the ends.
2. Thread one end of each 3/4 in NPT with a rented pipe threader; ream and deburr both ends.
3. Degrease inside and out: cutting oil smokes on the first firing.
4. Coat the thread with nickel anti-seize (never PTFE tape or paste) and screw on a cap, hand tight plus one and a half turns.

**How it fits the parts next to it.**

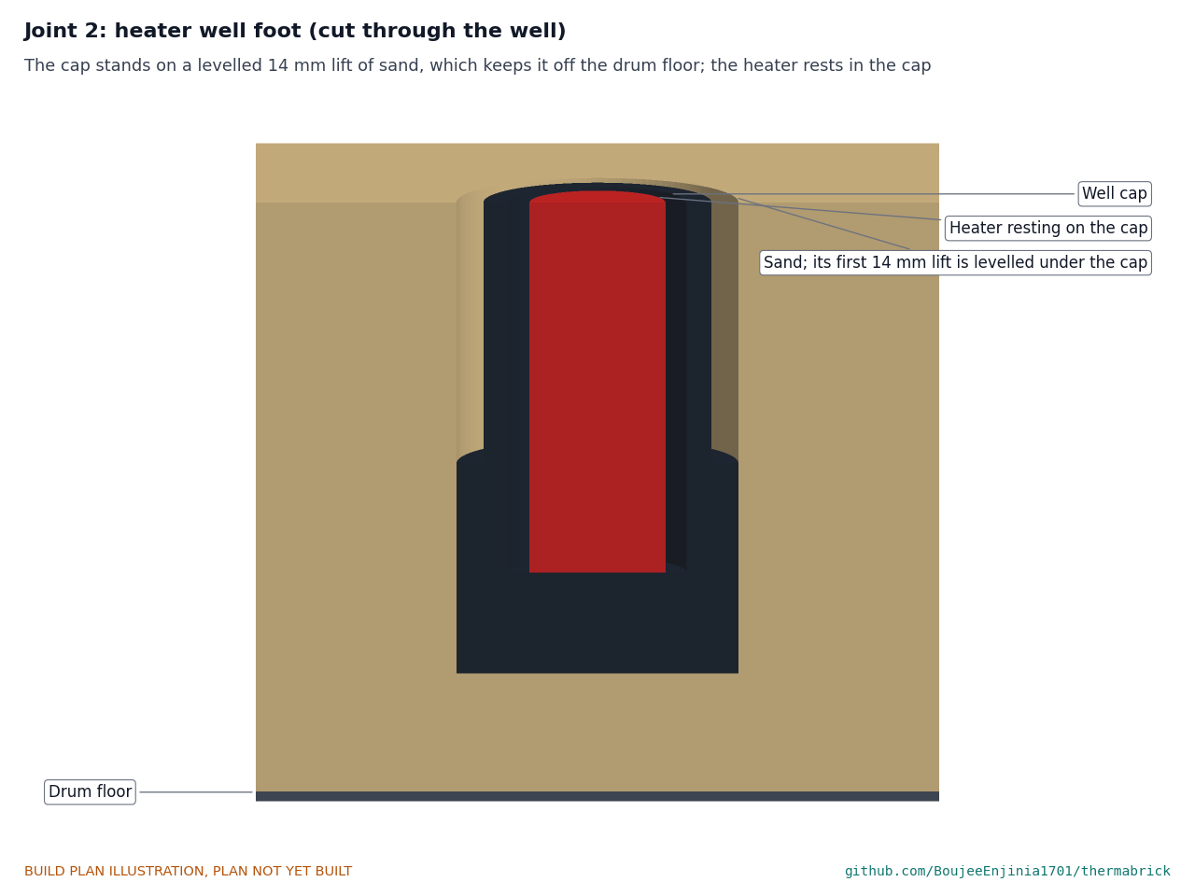
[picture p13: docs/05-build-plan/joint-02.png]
Figure 9. Joint 2: heater well foot


*Figure 9. The cap stands on a levelled 14 mm first layer of sand, which keeps it off the drum floor; the heater rests in the cap.*

Each well stands on its cap at its mark, held upright by the template and then the lid; its open top ends 25 mm above the lid. The heater rests on the inside of the cap, its heated length from 26 to 483 mm above the drum floor, and its leads rise out of the open top.

**Check before moving on.** A 16 mm rod slides to the bottom of every well freely.

### 3.5 U-tubes (make 6)

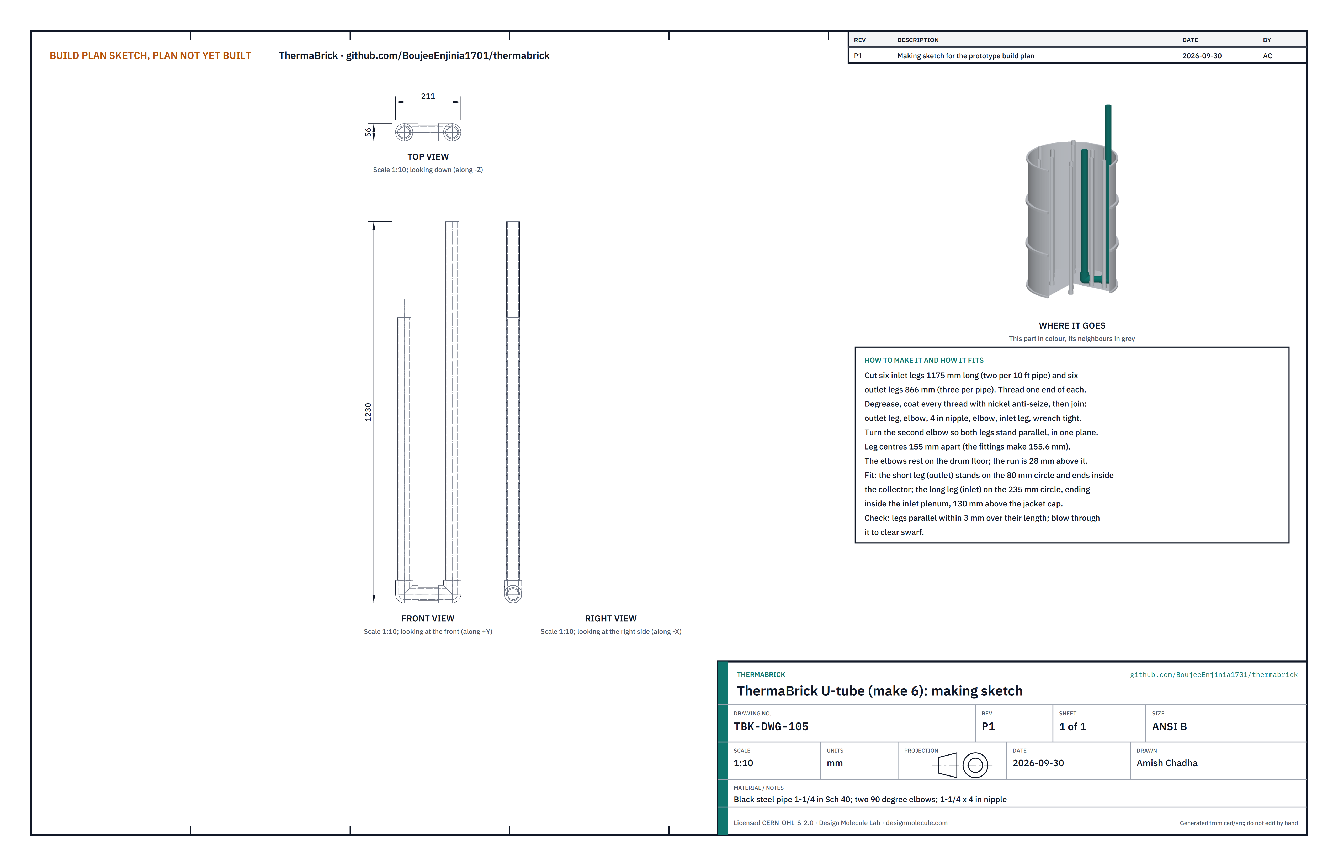
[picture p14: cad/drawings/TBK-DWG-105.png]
Figure 10. Making sketch of the U-tube


*Figure 10. U-tube making sketch (TBK-DWG-105).*

**What it is and what it is made from.** The heat exchanger: room air goes down the long leg, across the bottom and up the short leg, picking up heat from the sand without ever touching it. Black steel pipe 1-1/4 in Sch 40 (42.2 mm outside), five 10 ft lengths; twelve 1-1/4 in malleable iron 90° elbows; six 1-1/4 x 4 in black nipples.

**How to make it.**

1. Cut six long (inlet) legs of 1,175 mm, two from each of three pipes, and six short (outlet) legs of 866 mm, three from each of two pipes.
2. Thread one end of each; ream, deburr and degrease.
3. Coat every thread with nickel anti-seize and join, wrench tight: short leg, elbow, 4 in nipple, elbow, long leg.
4. Turn the second elbow so the two legs are parallel and in one plane, 155 mm apart between centres.
5. Blow through each tube to clear swarf.

**How it fits the parts next to it.**

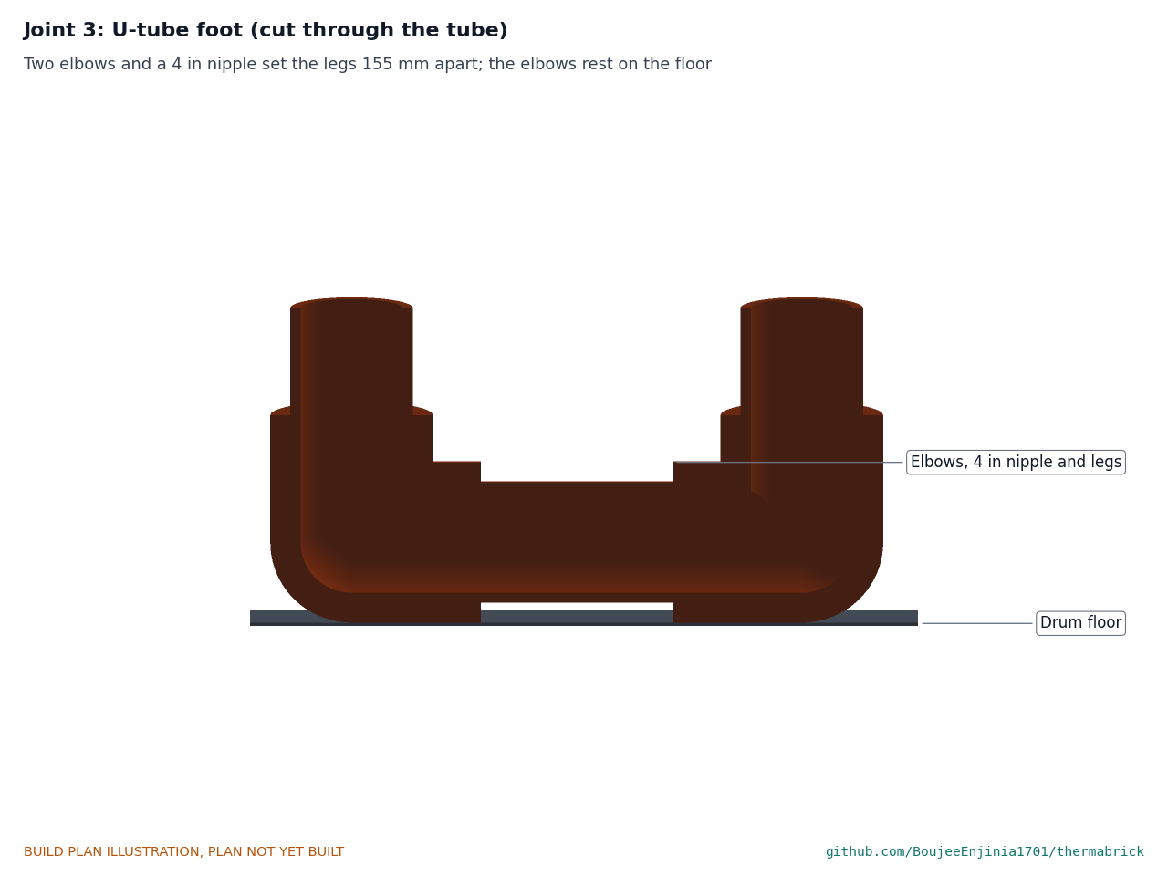
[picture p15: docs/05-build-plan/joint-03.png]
Figure 11. Joint 3: U-tube foot


*Figure 11. Two elbows and a 4 in nipple set the legs 155 mm apart; the elbows rest on the drum floor.*

The elbows rest on the drum floor, the bottom run 28 mm above it. The short leg stands on the 80 mm circle and ends 50 mm above the lid, inside the collector; the long leg stands on the 235 mm circle and ends inside the inlet plenum, 130 mm above the jacket cap.

**Check before moving on.** The legs are parallel within 3 mm over their length.

### 3.6 Thermocouples and guide rods

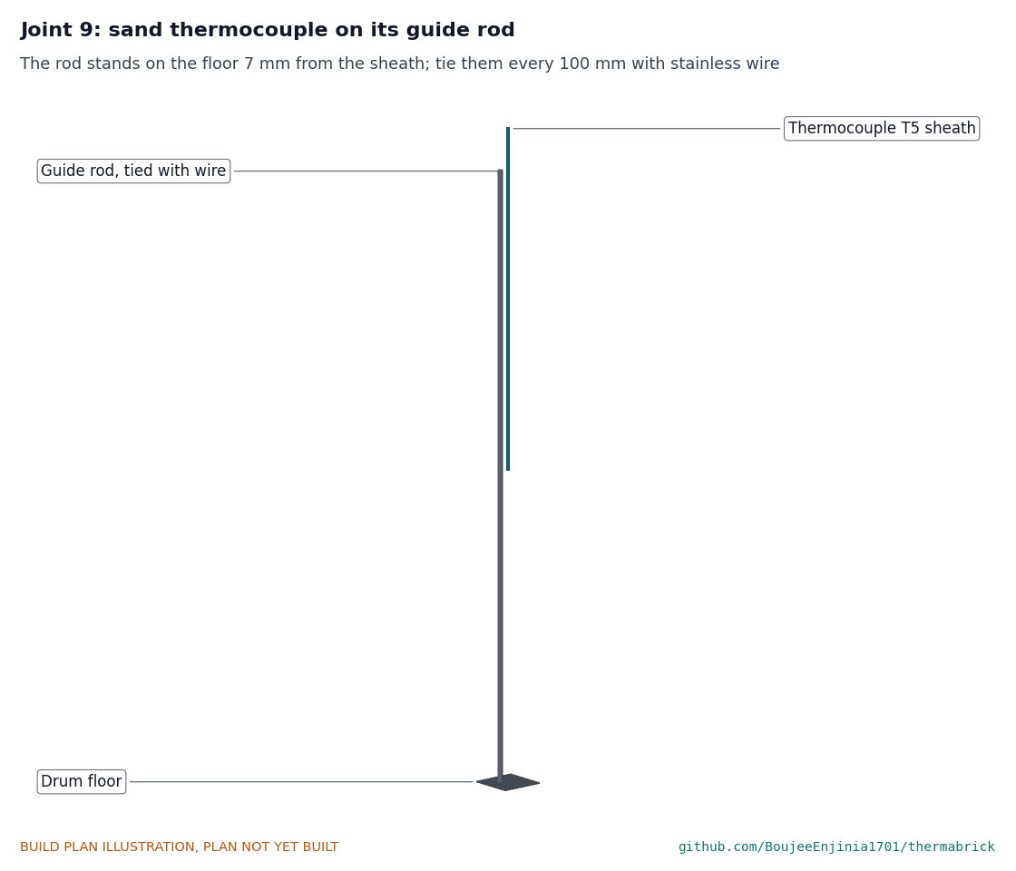
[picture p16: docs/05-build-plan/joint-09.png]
Figure 12. Joint 9: sand thermocouple on its guide rod


*Figure 12. Each sand thermocouple is tied to a stainless rod that stands on the drum floor.*

**What it is and what it is made from.** Eight type K mineral-insulated thermocouples, 3 mm Inconel sheath, 1,500 mm long, with mini plugs; four stainless rods 4.8 mm, cut to 561 mm; stainless tie wire.

**How to fit them.** Their positions are in Figure 6.

1. Well walls: T1 on the inner-ring well at 0°, T2 on the outer-ring well at 180° (on its inner side), T3 on the inner-ring well at 120°. Tie each sheath to its well with stainless wire, its tip 255 mm above the drum floor (the middle of the heated length).
2. Sand: stand a guide rod on the floor 7 mm inboard of each sand position and tie the sheath to it every 100 mm. T5 (200 mm, 45°) and T6 (270 mm, 45°) with tips 286 mm above the floor; T7 (200 mm, 225°) with its tip 471 mm above the floor.
3. T4 measures the centre: its rod stands 7 mm off the centre, its tip 286 mm above the floor. Above the sand, bend its sheath once by hand and run it across the sand surface at 51°, between two short U-tube legs, to its lid hole at 165 mm.
4. T8 goes in later, through the 4 mm hole in the collector top, into the collector air.
5. Above the lid, every sheath runs in the top insulation to the exit grommet in the cap; coil the spare length flat in the insulation.

**Check before moving on.** Each thermocouple reads room temperature on a meter, and its tip is at its stated height within 10 mm.

### 3.7 Collector and outlet

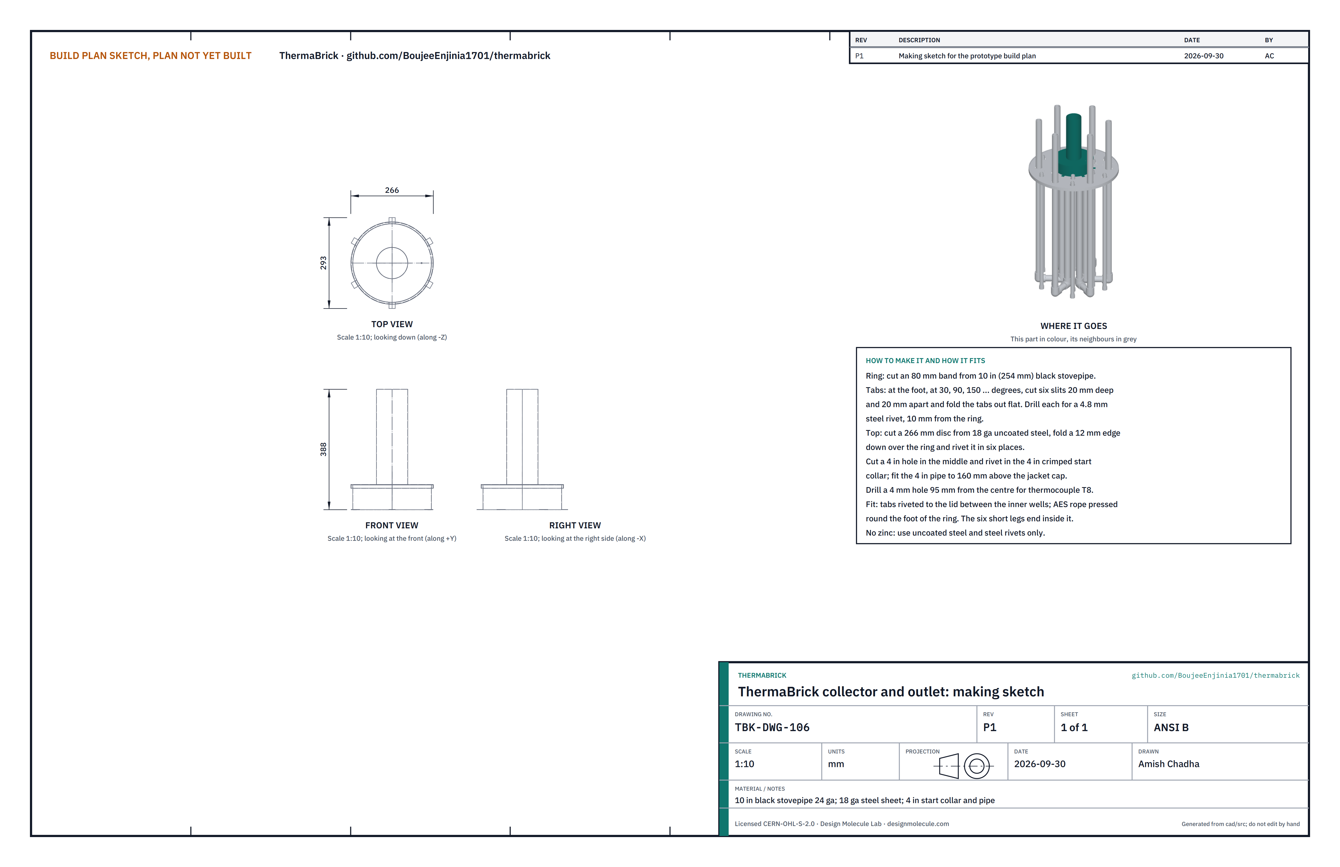
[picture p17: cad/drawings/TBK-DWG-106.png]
Figure 13. Making sketch of the collector


*Figure 13. Collector and outlet making sketch (TBK-DWG-106).*

**What it is and what it is made from.** A shallow drum on the lid that gathers the hot air from the six short legs and sends it up the 4 in outlet. A section of 10 in (254 mm) black stovepipe, 24 ga; 18 ga uncoated steel sheet; a 4 in crimped start collar and 4 in black steel pipe; steel pop rivets.

**How to make it.**

1. Cut an 80 mm band from the stovepipe and close its seam.
2. At the foot, at 30, 90, 150, 210, 270 and 330°, make two 20 mm slits 20 mm apart and fold each tab out flat. Drill each tab 4.9 mm, 10 mm out from the ring.
3. Cut a 266 mm disc of 18 ga sheet; fold a 12 mm edge down and rivet it over the ring in six places.
4. Cut a 4 in hole in the middle of the disc and rivet in the start collar. Drill a 4 mm hole 95 mm from the centre for T8.
5. Fit the 4 in pipe in the collar, long enough to stand 160 mm above the jacket cap (about 300 mm).

**How it fits the parts next to it.**

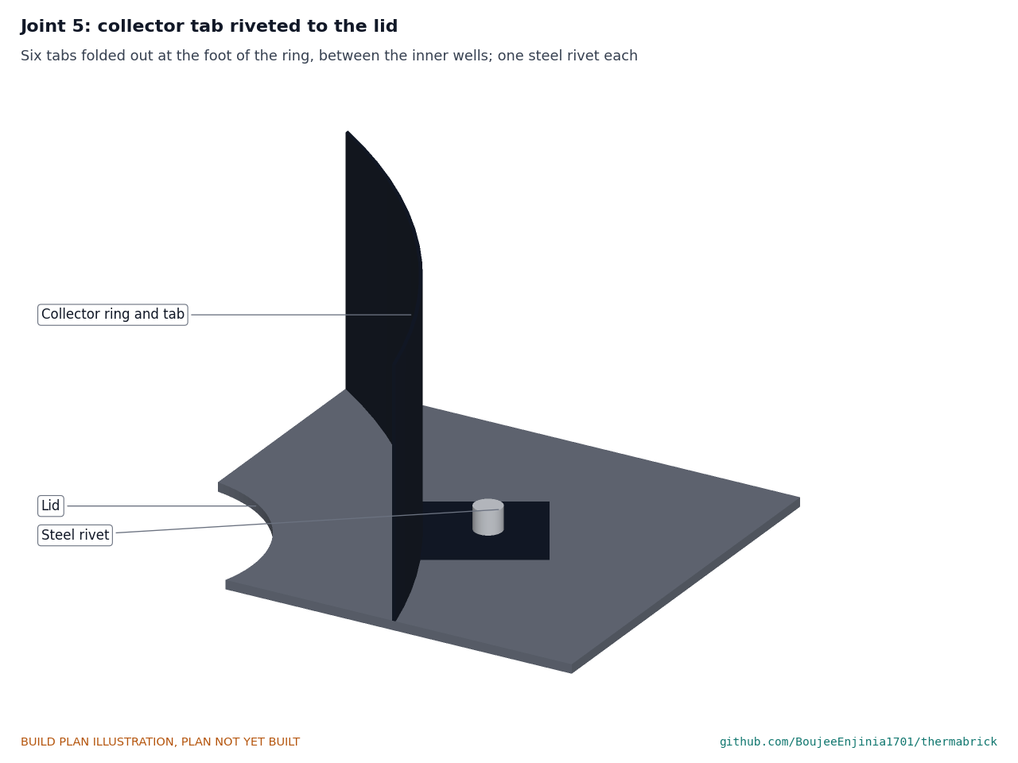
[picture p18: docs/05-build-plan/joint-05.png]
Figure 14. Joint 5: collector tab on the lid


*Figure 14. Each tab lies on the lid between two inner-ring wells and is held by one steel rivet.*

The ring stands on the lid over the six short legs, 9.6 mm clear of the inner wells. Each tab is riveted to the lid with a steel rivet (never aluminium in the hot zone), and AES rope is pressed round the foot of the ring.

**Check before moving on.** The collector sits flat; no tab touches a well.

### 3.8 Jacket side

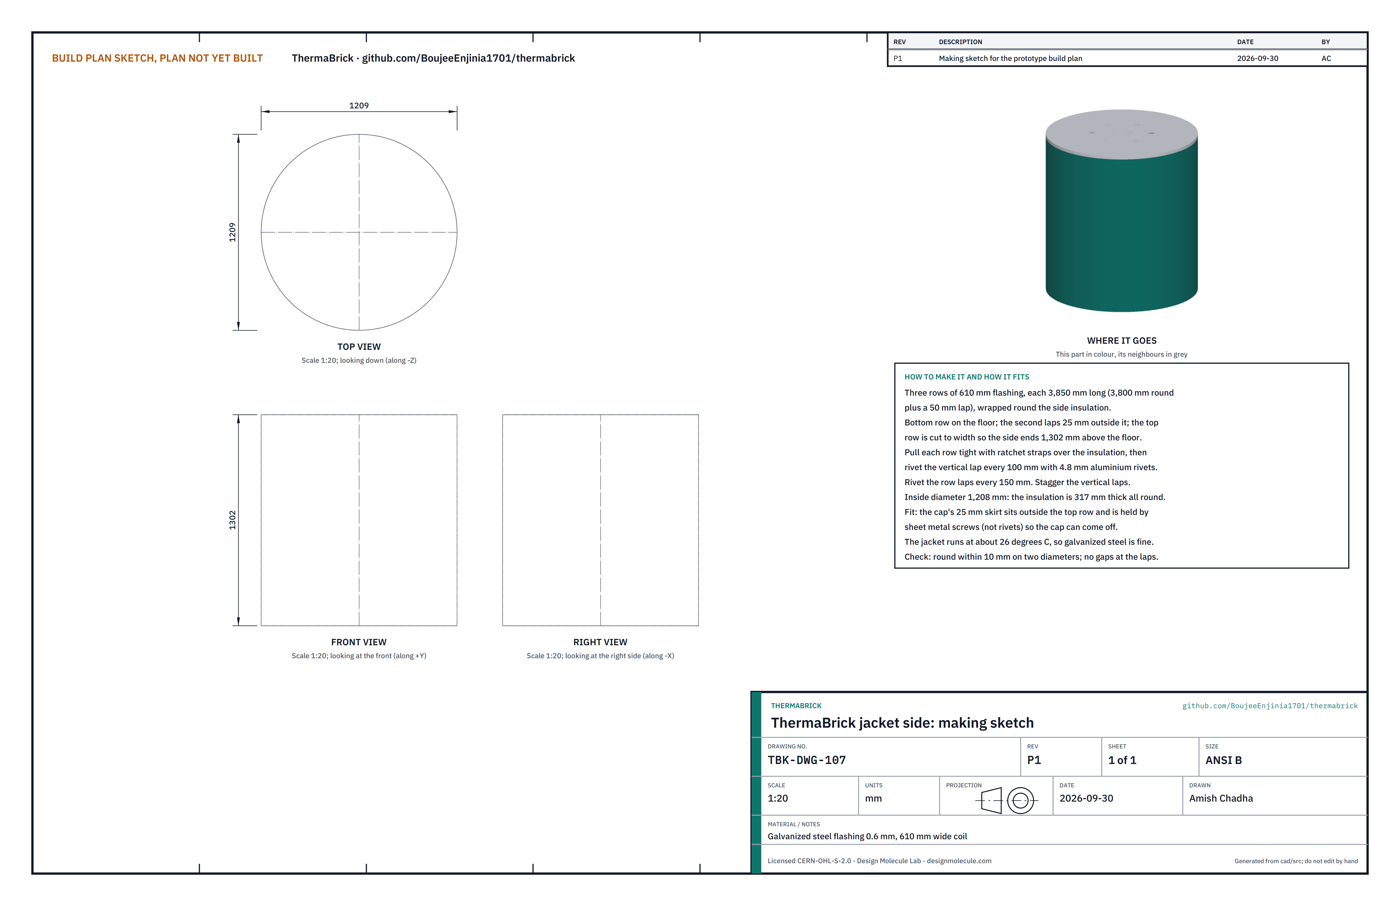
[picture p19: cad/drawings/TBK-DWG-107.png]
Figure 15. Making sketch of the jacket side


*Figure 15. Jacket side making sketch (TBK-DWG-107).*

**What it is and what it is made from.** The outer skin, 1,210 mm across and 1,302 mm high, that holds the side insulation. Galvanized steel flashing 0.6 mm, 610 mm wide coil; aluminium pop rivets.

**How to make it.**

1. Cut three strips 3,850 mm long (3,800 mm round plus a 50 mm lap). Cut the top strip to the width that brings the side to 1,302 mm with 25 mm laps between rows.
2. Wrap the bottom strip round the insulated unit on the floor, pull it tight with two ratchet straps, and rivet the vertical lap every 100 mm.
3. Add the second and top rows, each lapping 25 mm outside the one below, the vertical laps staggered. Rivet the row laps every 150 mm.

**How it fits the parts next to it.** The jacket stands on the slab round the base and holds the 317 mm of side insulation. The cap's skirt sits outside its top edge (Figure 18). The jacket runs at about 26 °C, so galvanized steel is allowed here.

**Check before moving on.** Two diameters at right angles agree within 10 mm; no gap at any lap.

### 3.9 Jacket cap

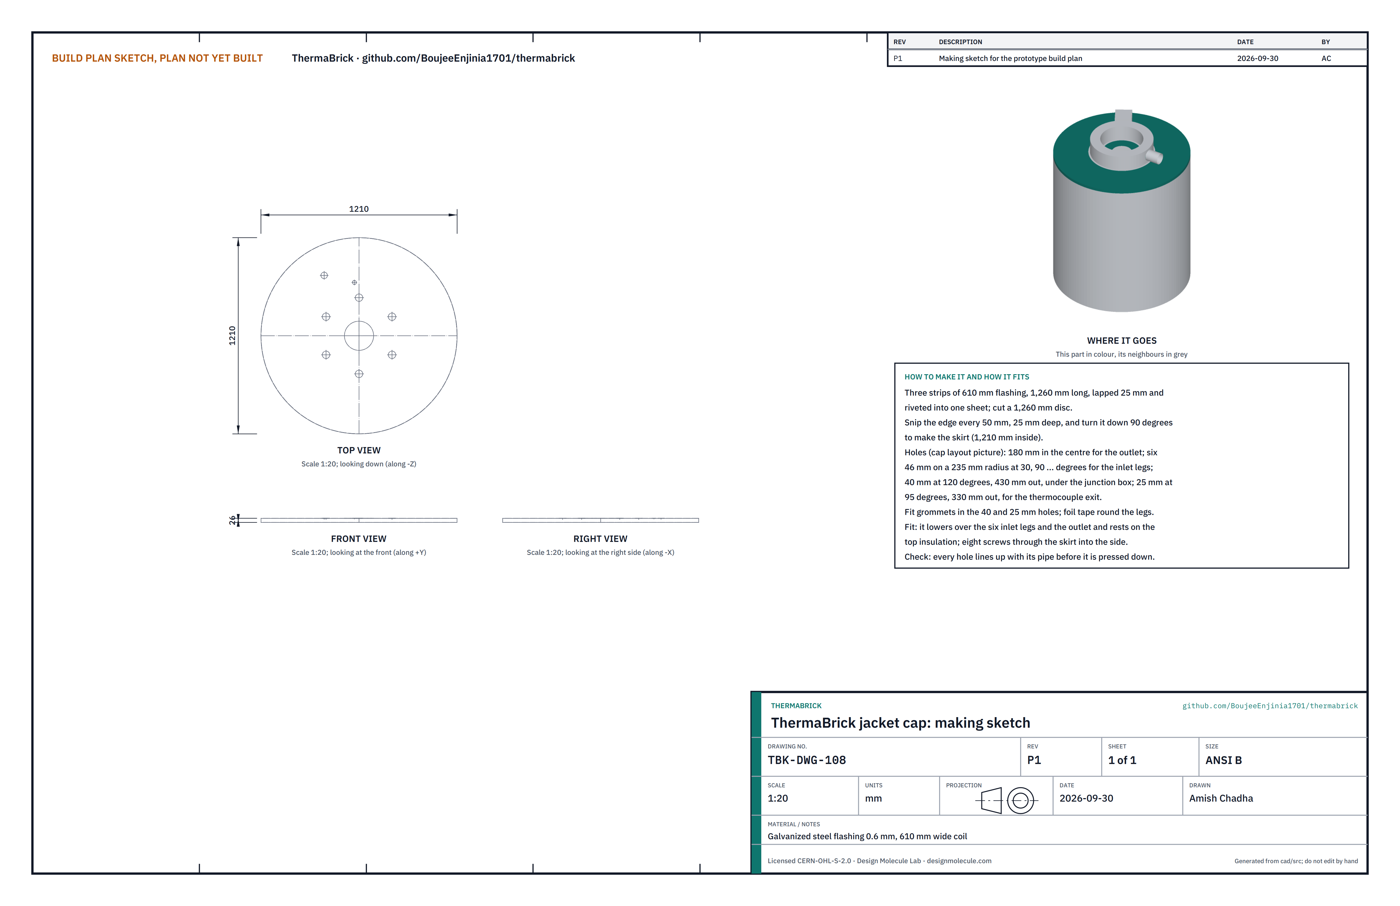
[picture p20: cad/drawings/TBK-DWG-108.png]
Figure 16. Making sketch of the jacket cap


*Figure 16. Jacket cap making sketch (TBK-DWG-108).*

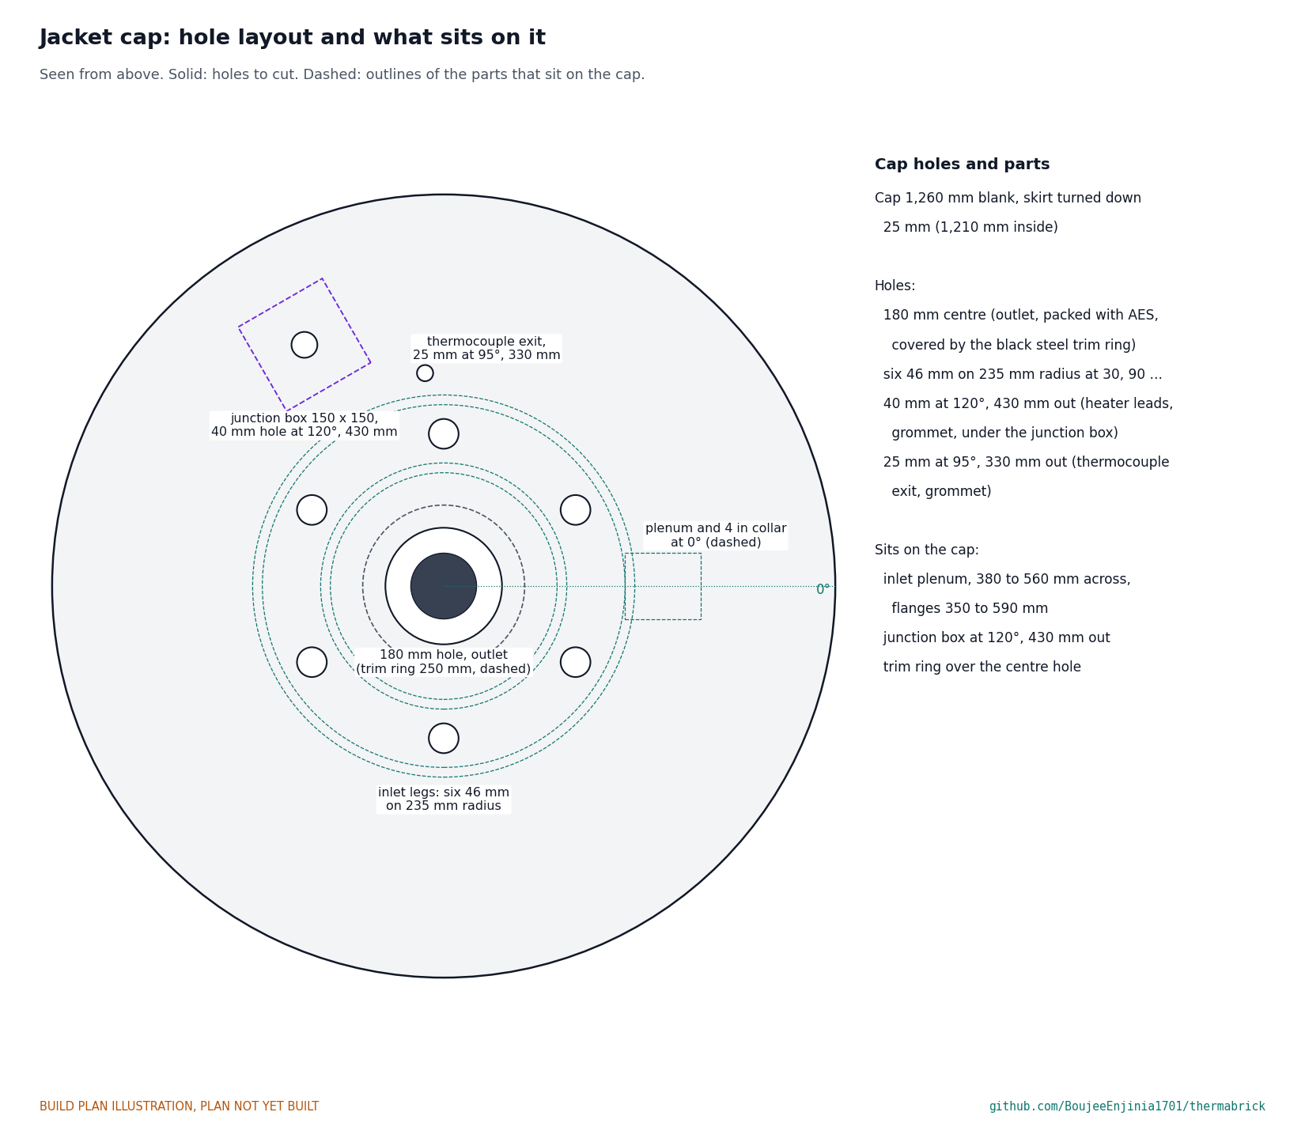
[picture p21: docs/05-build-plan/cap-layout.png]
Figure 17. Jacket cap hole layout


*Figure 17. Jacket cap hole layout and the outlines of the parts that sit on it.*

**What it is and what it is made from.** The removable top of the jacket. Three strips of the same flashing, stainless sheet metal screws, two silicone grommets.

**How to make it.**

1. Cut three strips 1,260 mm long, lap them 25 mm and rivet the laps every 100 mm. Cut a 1,260 mm disc.
2. Snip the edge every 50 mm, 25 mm deep, and turn it down 90° to make the skirt.
3. Cut the holes of Figure 17: 180 mm in the centre for the outlet; six of 46 mm on a 235 mm radius at 30, 90, 150, 210, 270 and 330° for the long legs; 40 mm at 120°, 430 mm out, under the junction box; 25 mm at 95°, 330 mm out, for the thermocouple exit.
4. Fit grommets in the 40 mm and 25 mm holes.

**How it fits the parts next to it.** It lowers over the six long legs and the outlet and rests on the top insulation; the heater leads and thermocouple sheaths come up through the grommets. Eight sheet metal screws through the skirt hold it to the jacket side, so it can be lifted off to reach a heater.

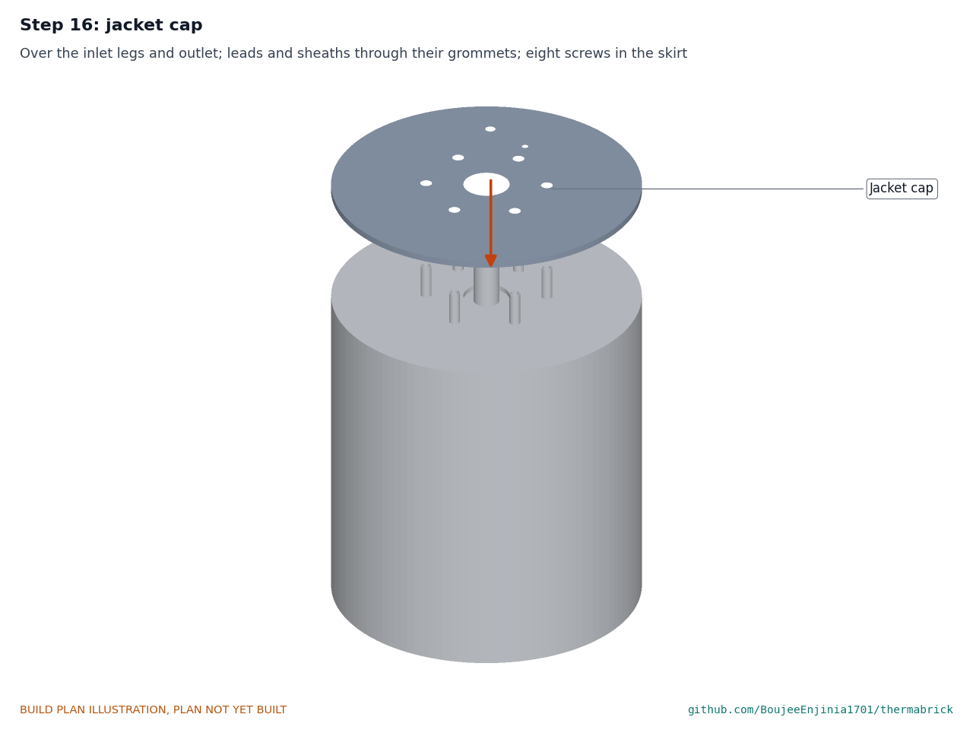
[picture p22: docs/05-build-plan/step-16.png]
Figure 18. The jacket cap going on (assembly step 16)


*Figure 18. The cap lowers over the six long legs and the outlet; its skirt sits outside the top row of the jacket side.*

**Check before moving on.** Every hole lines up with its pipe before the cap is pressed down.

### 3.10 Heater junction box

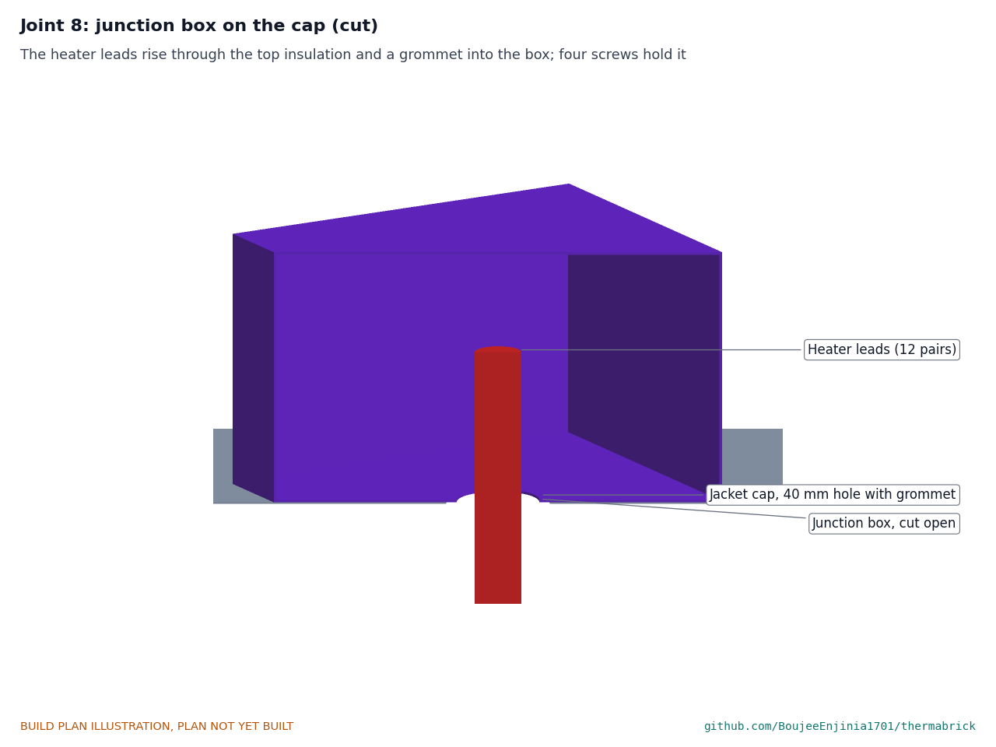
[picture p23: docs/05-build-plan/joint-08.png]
Figure 19. Joint 8: junction box on the cap


*Figure 19. The heater leads rise through the top insulation and the grommet into the box.*

**What it is.** A bought steel box, 150 x 150 x 100 mm, with ceramic terminal blocks, where the 24 heater leads meet the cable from the control enclosure.

**What to do to it.** Drill a 40 mm hole in its floor to match the cap hole, and four 4.5 mm holes for screws. Fit a cable gland for the supply cable. It sits on the cap at 120°, 430 mm out, 60 mm clear of the plenum.

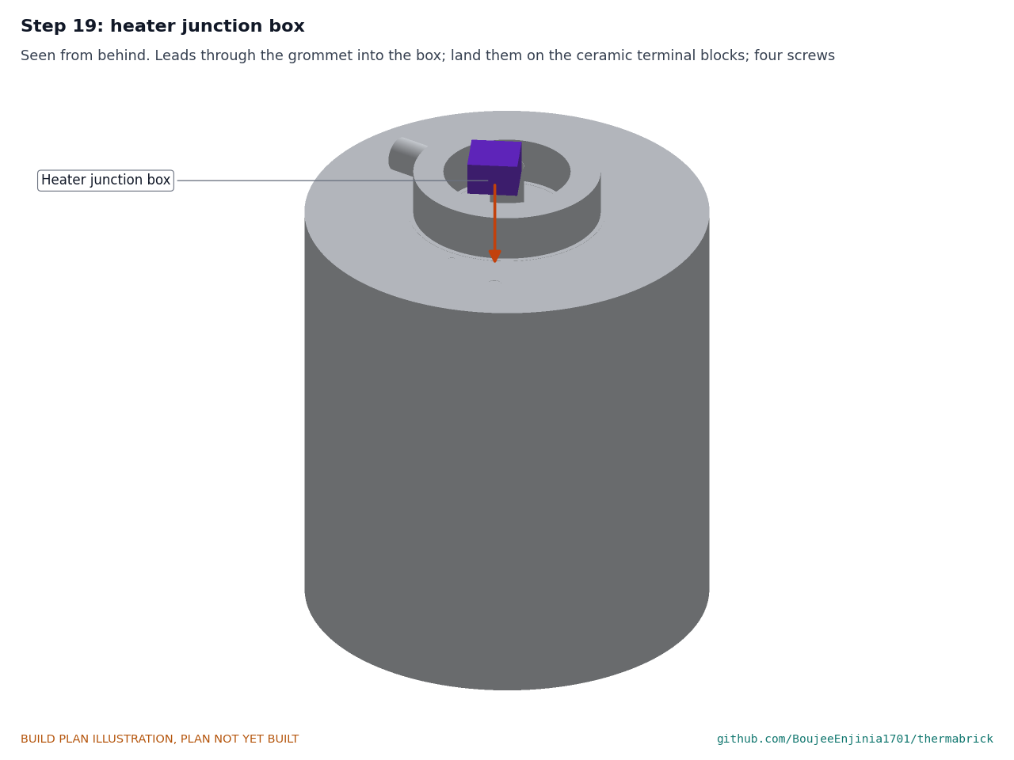
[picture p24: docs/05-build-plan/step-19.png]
Figure 20. Step 19: junction box


*Figure 20. The box goes on last, over the leads (assembly step 19).*

### 3.11 Outlet trim ring

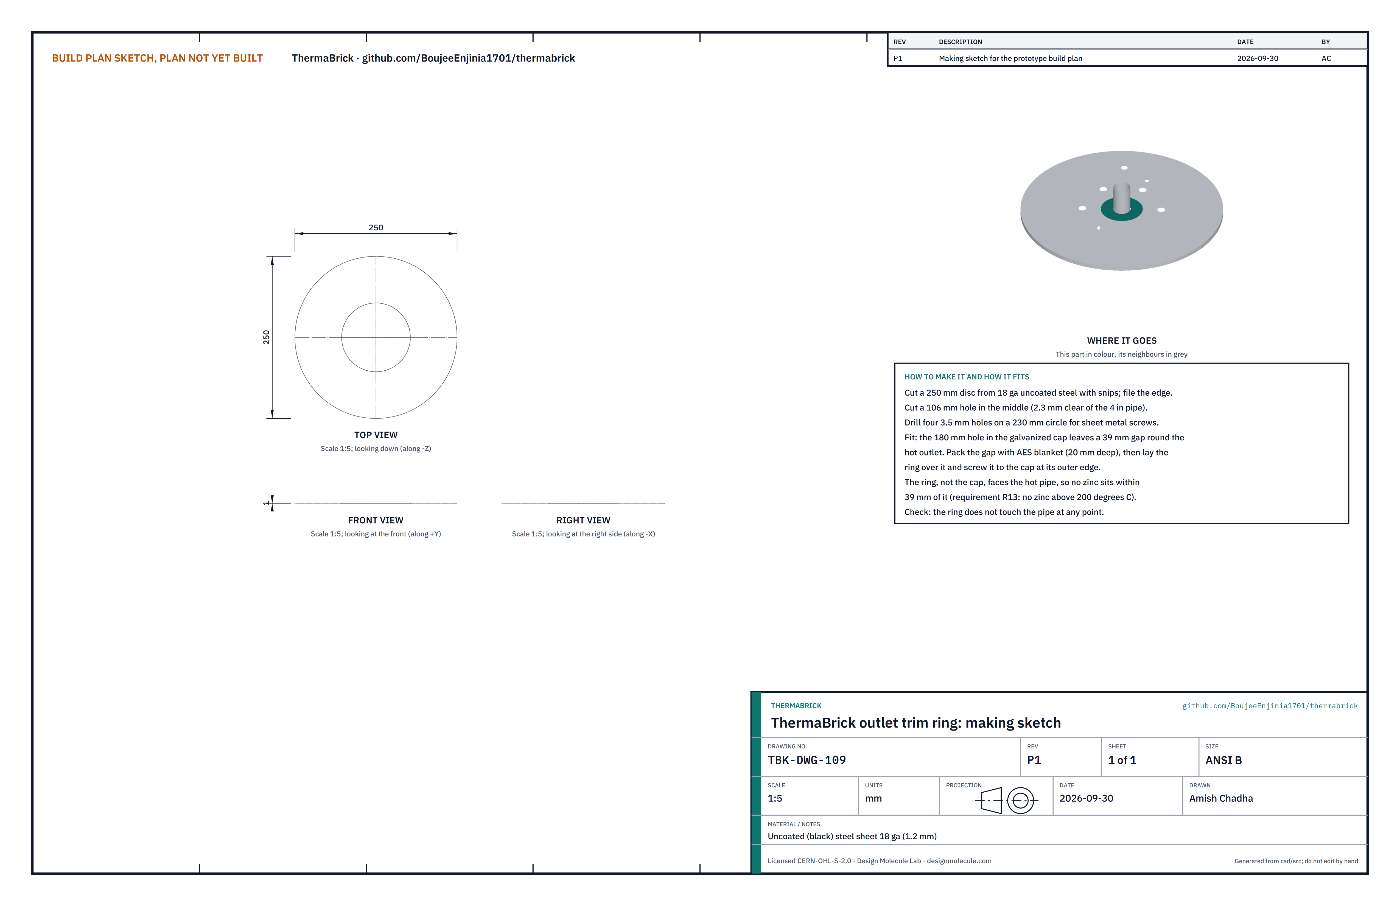
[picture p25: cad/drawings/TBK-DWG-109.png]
Figure 21. Making sketch of the outlet trim ring


*Figure 21. Outlet trim ring making sketch (TBK-DWG-109).*

**What it is and what it is made from.** A flat steel ring that covers the fiber packing where the hot outlet passes through the cap. 18 ga (1.2 mm) uncoated steel sheet.

**How to make it.**

1. Cut a 250 mm disc with snips and file the edge.
2. Cut a 106 mm hole in the middle.
3. Drill four 3.5 mm holes on a 230 mm circle.

**How it fits the parts next to it.**

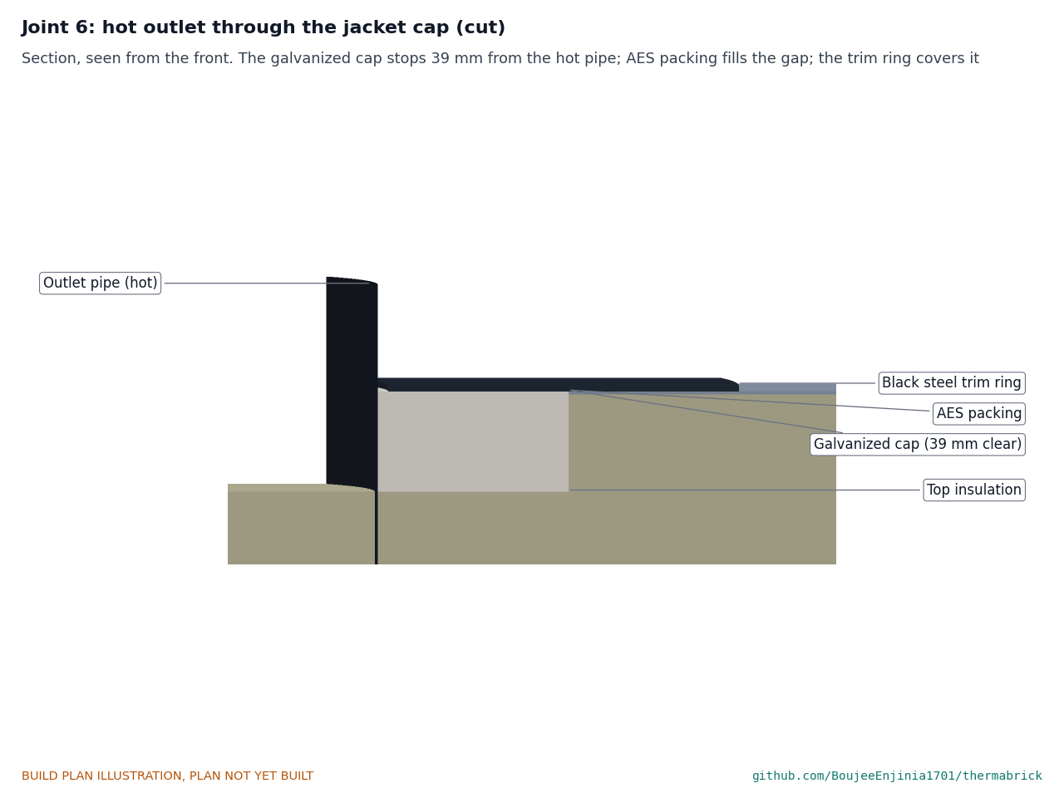
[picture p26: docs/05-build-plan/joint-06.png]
Figure 22. Joint 6: hot outlet through the jacket cap


*Figure 22. The galvanized cap stops 39 mm from the hot pipe; fiber packing fills the gap and the trim ring covers it.*

The 39 mm gap between the outlet and the cap is packed 20 mm deep with AES blanket. The ring lies on the packing and the cap, 2.3 mm clear of the pipe all round, held by four screws at its outer edge.

**Check before moving on.** The ring touches the pipe nowhere.

### 3.12 Inlet plenum

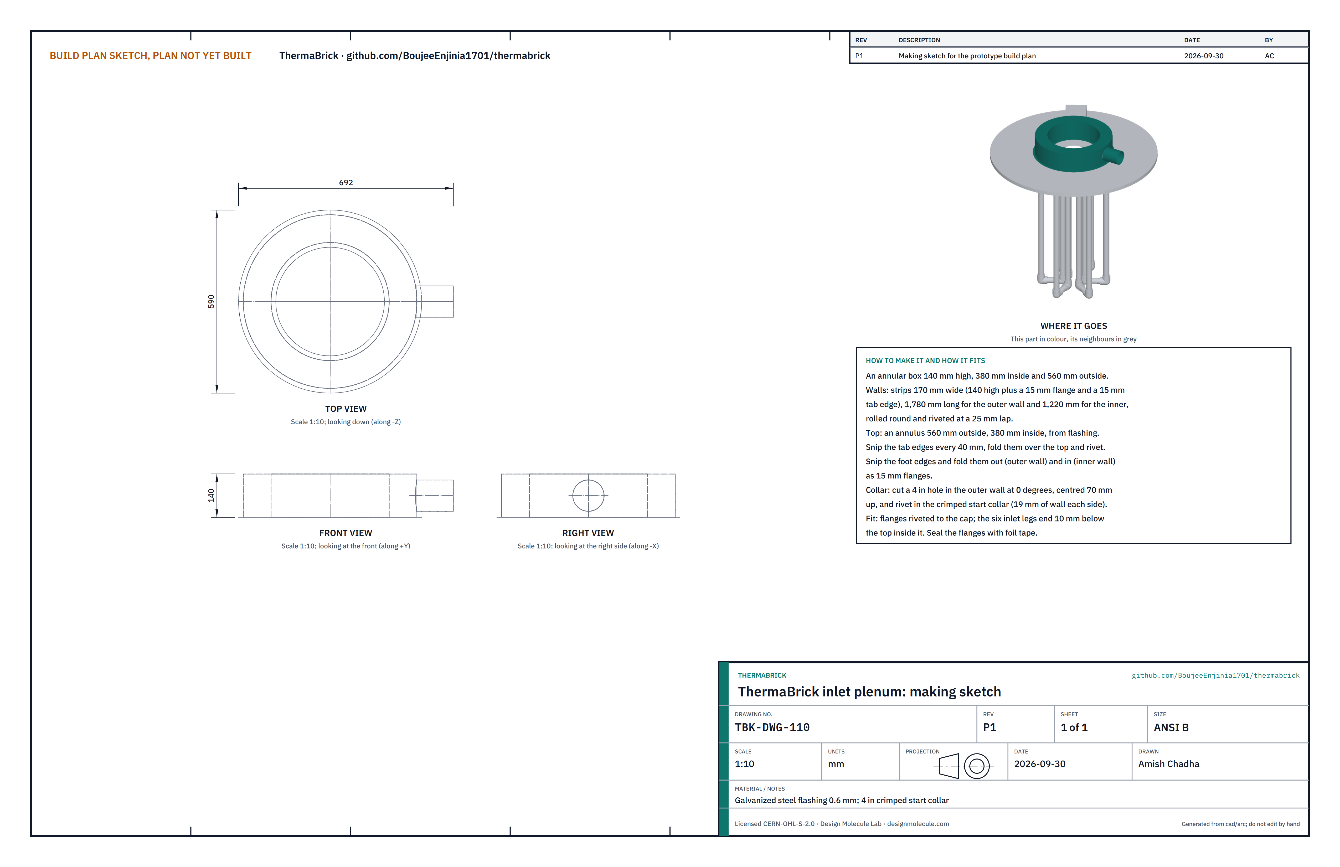
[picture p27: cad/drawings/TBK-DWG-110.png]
Figure 23. Making sketch of the inlet plenum


*Figure 23. Inlet plenum making sketch (TBK-DWG-110).*

**What it is and what it is made from.** A ring-shaped sheet metal box on the cap that takes room air from the 4 in inlet collar and shares it among the six long legs. Galvanized flashing 0.6 mm; a 4 in crimped start collar; pop rivets; foil tape.

**How to make it.**

1. Cut two strips 170 mm wide: 1,780 mm long for the outer wall and 1,220 mm for the inner wall. Roll each into a ring (560 mm and 380 mm across) and rivet a 25 mm lap.
2. Cut the top: a ring 560 mm outside and 380 mm inside.
3. On each wall, snip the top 15 mm every 40 mm, fold the tabs over the top and rivet them.
4. Snip the bottom 15 mm every 40 mm and fold the tabs out (outer wall) or in (inner wall) as flanges.
5. In the outer wall at 0°, cut a 4 in hole centred 70 mm up and rivet in the start collar, which leaves 19 mm of wall above and below it.

**How it fits the parts next to it.**

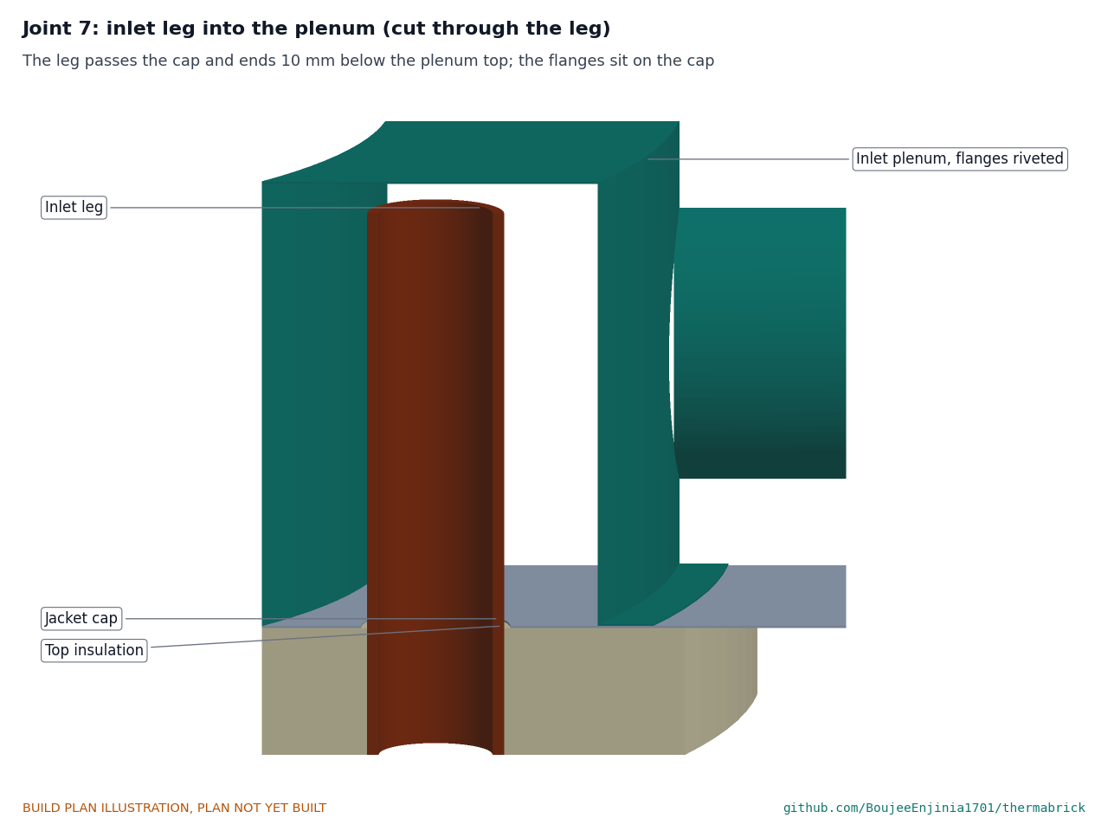
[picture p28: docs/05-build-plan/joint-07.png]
Figure 24. Joint 7: inlet leg into the plenum


*Figure 24. A long leg passes through the cap and ends 10 mm below the plenum top.*

The plenum sits over the six long legs with its flanges on the cap, riveted and sealed with foil tape. The inlet damper fits on the collar.

**Check before moving on.** Air blown into the collar comes out of the outlet; none escapes at the flanges.

### 3.13 Wiring

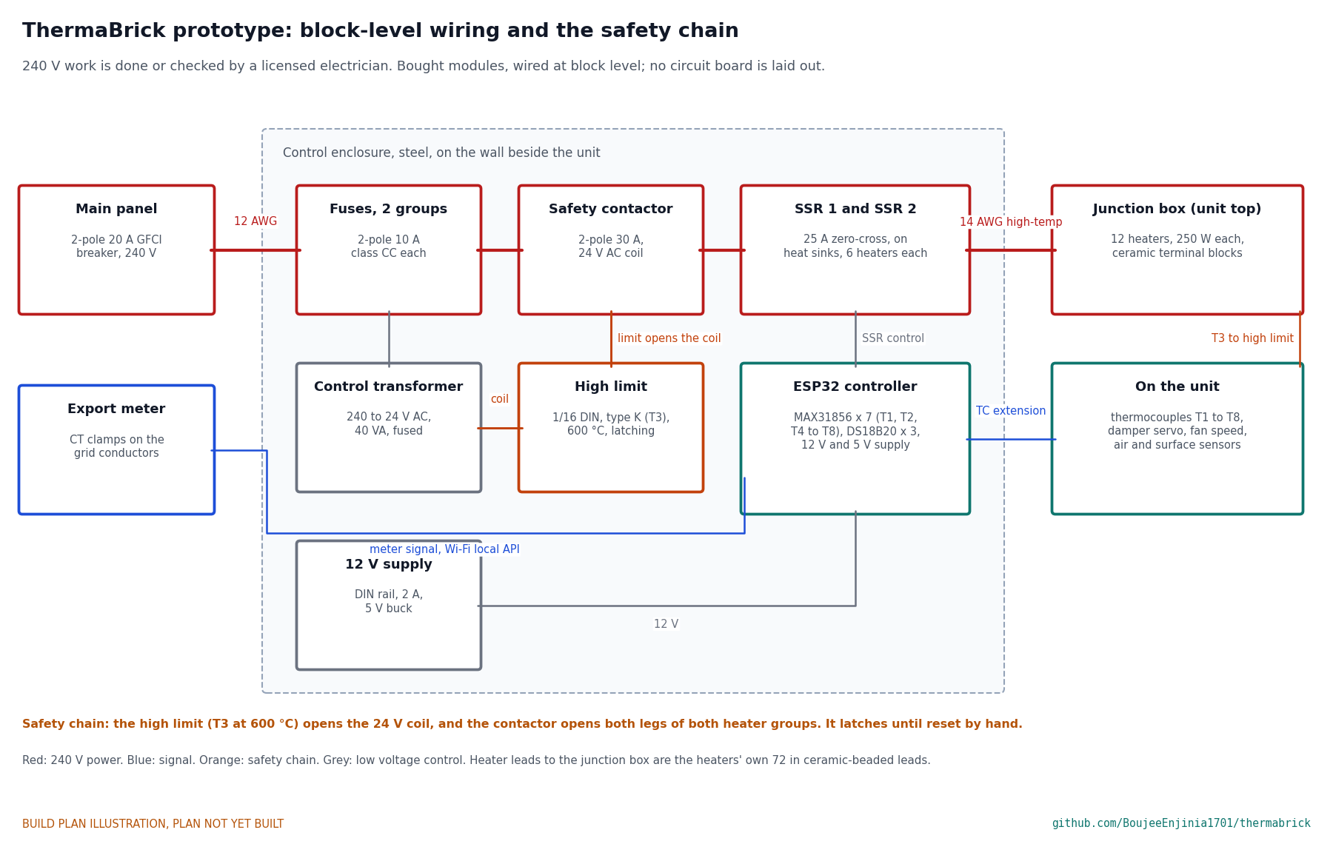
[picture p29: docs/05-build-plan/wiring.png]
Figure 25. Block-level wiring and the safety chain


*Figure 25. Block-level wiring. The 240 V circuit and the control enclosure are wired or checked by a licensed electrician.*

The heaters are wired as two groups of six (1.5 kW each), each through a 10 A fuse pair and a solid-state relay, with a 2-pole safety contactor ahead of both groups. The contactor's 24 V coil runs through the independent high limit on thermocouple T3, which opens it at 600 °C and latches until reset by hand. The ESP32 controller reads T1, T2 and T4 to T8, the air and surface sensors and the export meter, and drives the relays, the damper servo and the fan speed. Wire to the bill of materials: 12 AWG to the enclosure on a dedicated 20 A circuit with 2-pole ground-fault protection; high-temperature 14 AWG from the enclosure to the junction box; type K extension cable from the exit grommet to the amplifiers.

### 3.14 Bought components

Buy to specification, not brand. Line numbers are those of the bill of materials.

- **Drum (line 1).** New, unlined, open-head 55 US gal steel drum, 18 ga body, 16 ga lid with bolted ring, 571.5 mm inside.
- **Sand (line 2).** Ten 50 lb (22.7 kg) bags of washed play sand, sieved to remove fines.
- **Heaters (line 3).** Twelve cartridge heaters 5/8 x 20 in (15.9 x 508 mm), 250 W at 240 V, Incoloy 800 sheath, 2 in cold end, **72 in (1,829 mm) ceramic-beaded leads**.
- **Pipe and fittings (lines 4 to 9).** As sections 3.4 and 3.5, with nickel anti-seize.
- **Collector parts (lines 10, 11).** As section 3.7.
- **Air path (lines 12 to 18).** 4 in black stovepipe kit with two adjustable elbows, 4 in tee, 4 in galvanized butterfly damper with a hobby servo, 4 in balancing damper, 4 in EC inline fan (60 L/s at 150 Pa, speed input, rated for 60 °C air), insulated flexible duct and a register.
- **Insulation (lines 19 to 24).** Two rolls of 25 mm AES blanket, one AES board, 16 firebricks, three packs of 89 mm stone wool batt, four 50 mm stone wool boards (60 kPa or more at 10 % strain), two 3 m lengths of 12 mm AES rope.
- **Jacket (lines 25, 26).** Two coils of 610 mm galvanized flashing; aluminium and steel pop rivets, stainless sheet metal screws, foil tape.
- **Controls (lines 27 to 42).** As Figure 25 and the bill of materials.
- **New for construction (lines 43 to 46).** Plywood for the template, 18 ga uncoated steel for the trim ring, four stainless guide rods, silicone grommets.
- **Warning labels (line 47).** Five self-adhesive vinyl labels rated 105 °C or higher; positions in step 22.

## 4. Putting it together

In each picture the parts already fitted are grey and the part being fitted is in colour, with an arrow showing the way it goes in. The drum is drawn with a quarter cut away where the inside matters.

### Step 1: stone wool boards on the slab

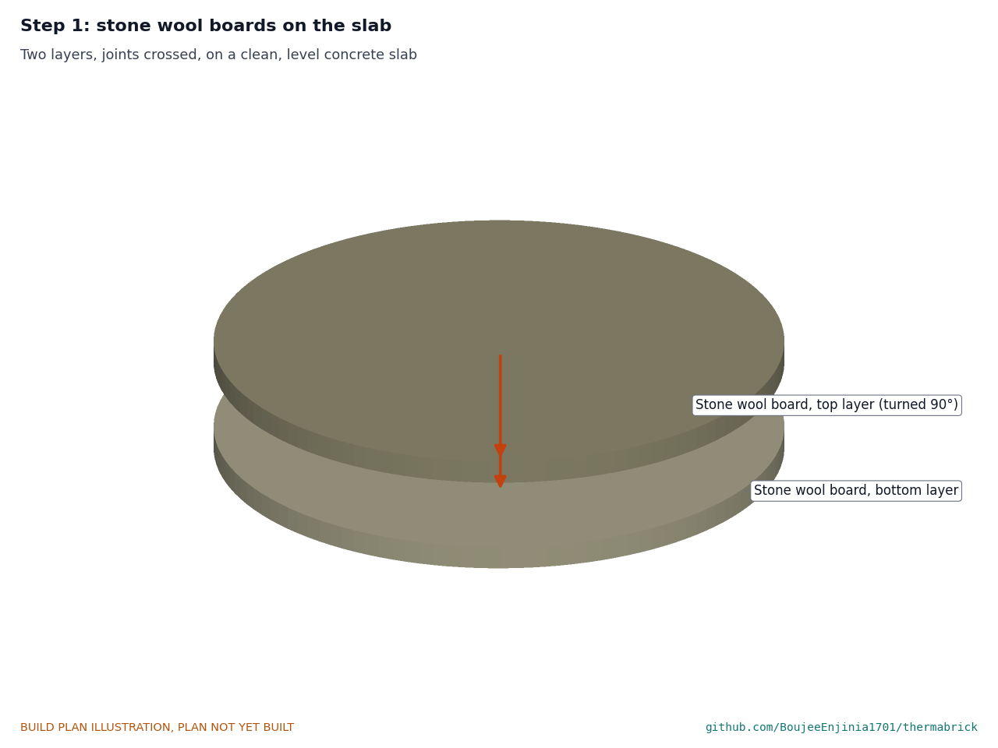
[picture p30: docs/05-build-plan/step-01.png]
Step 1


On a clean, level concrete slab inside the heated space, at least 450 mm from anything combustible. Two layers, joints crossed.

### Step 2: firebrick disc, AES disc and batt ring

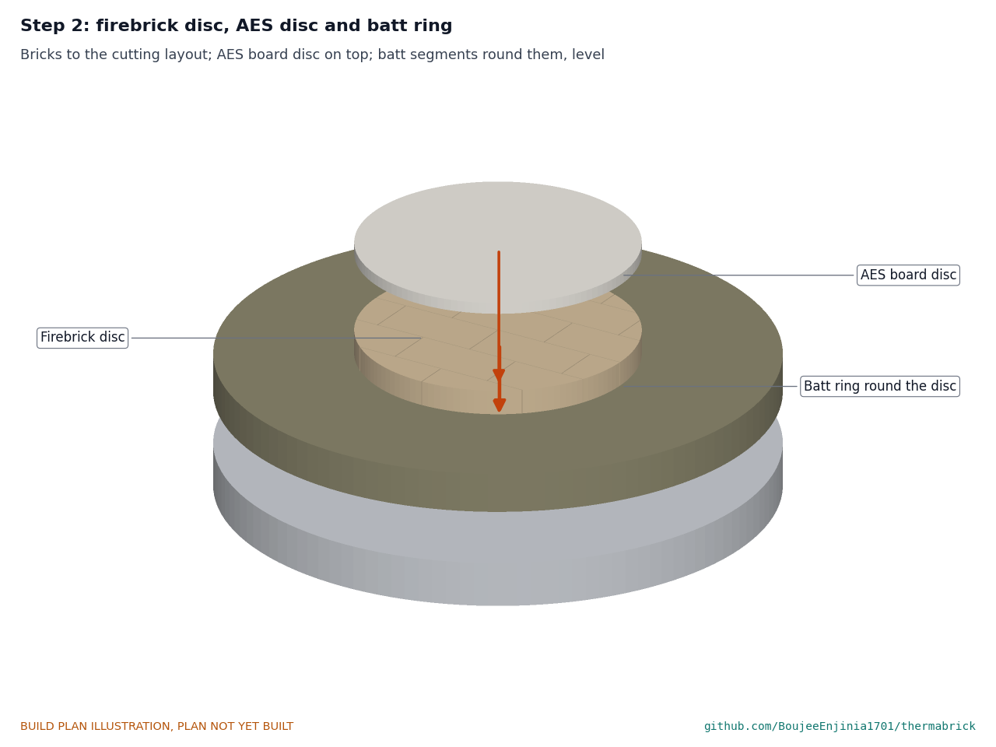
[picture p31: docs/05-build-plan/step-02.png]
Step 2


Bricks to the cutting layout, dry, in the middle; the AES disc on top; the batt ring round both, level with the AES disc.

### Step 3: drum onto the base

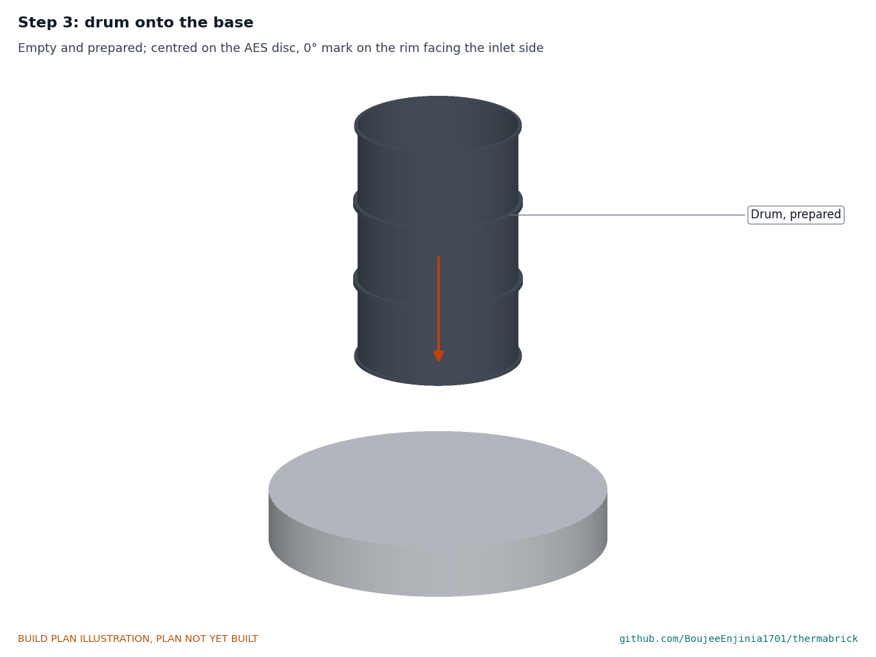
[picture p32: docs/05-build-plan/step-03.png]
Step 3


Empty and prepared, centred on the AES disc (two people lift it), with its 0° mark facing where the inlet duct will come from. It is not moved again.

### Step 4: heater wells into the drum

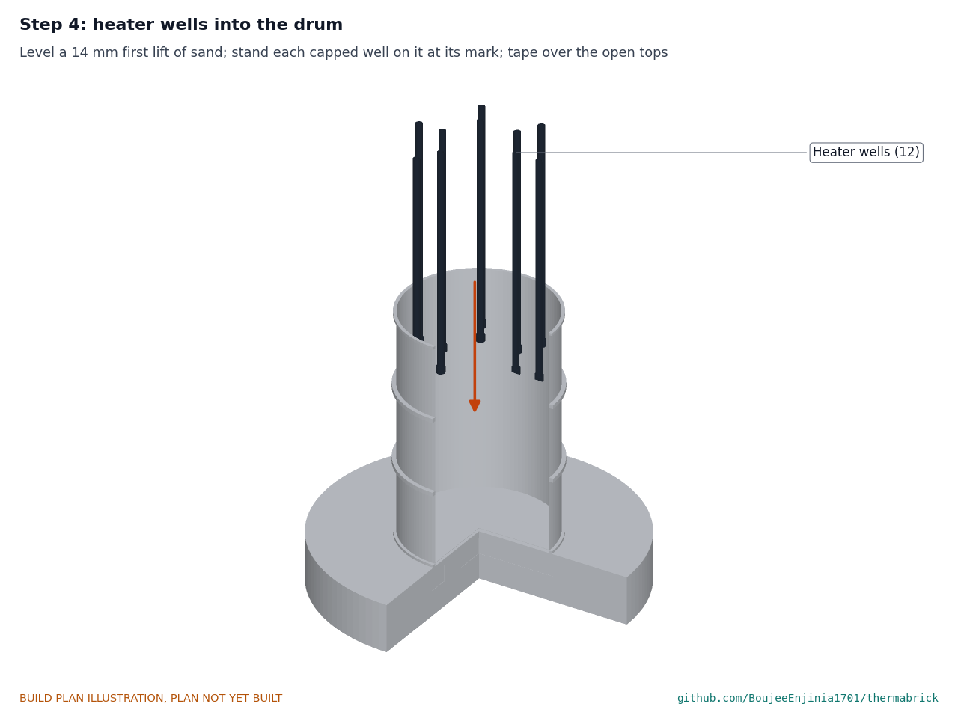
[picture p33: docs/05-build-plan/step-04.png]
Step 4


Pour and level a 14 mm first layer of sand with a short board. Stand each capped well on it at its mark from Figure 6. Tape over the open tops so no sand gets in.

### Step 5: U-tubes into the drum

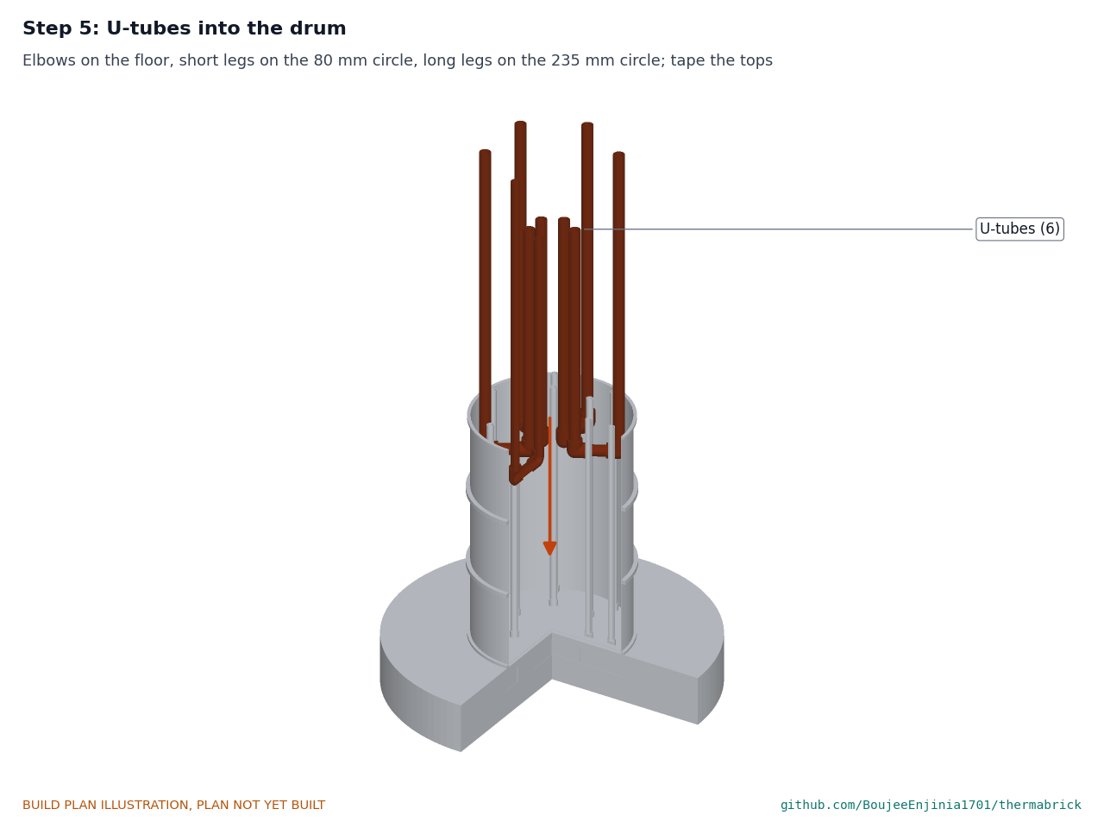
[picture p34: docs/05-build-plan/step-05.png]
Step 5


Elbows on the floor (scrape the sand clear under them), short legs on the 80 mm circle, long legs on the 235 mm circle, each tube on its ray at 30, 90, 150 ... °. Tape the tops.

### Step 6: thermocouples and guide rods

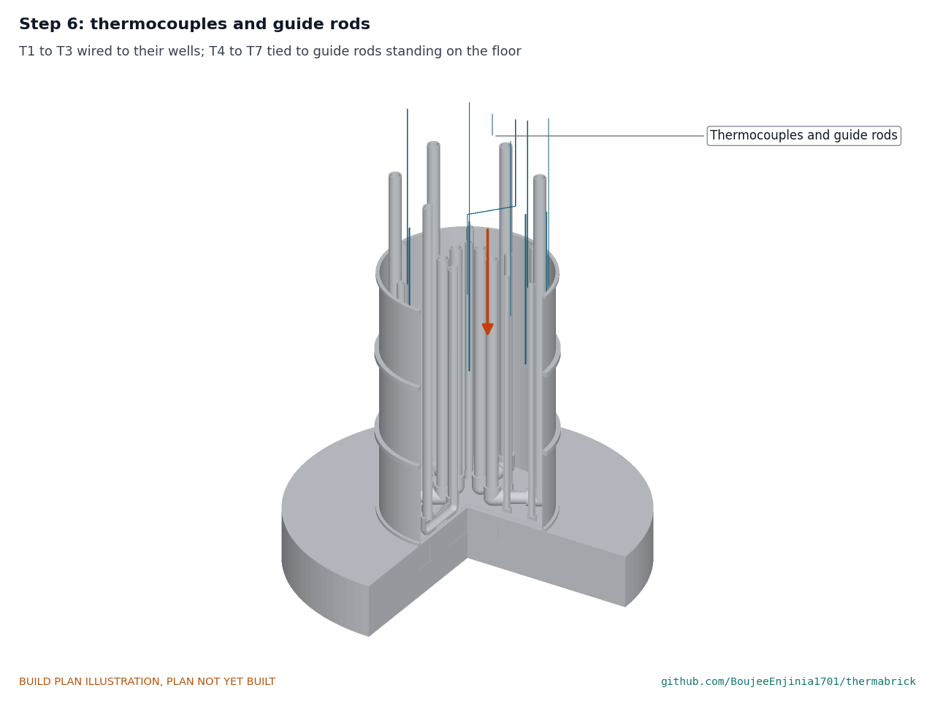
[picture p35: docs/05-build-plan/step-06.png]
Step 6


As section 3.6: T1 to T3 wired to their wells, guide rods for T4 to T7 standing on the floor with the sheaths tied to them.

### Step 7: setting template onto the rim

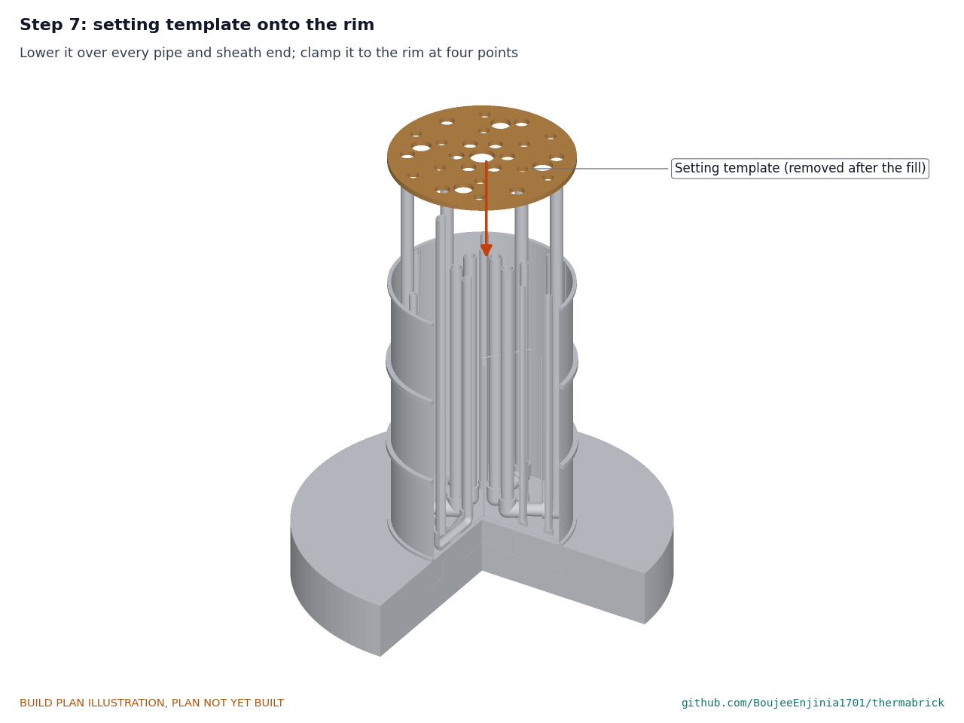
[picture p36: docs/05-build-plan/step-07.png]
Step 7


Lower it over every pipe and sheath end, 0° marks together, and clamp it at four points. **Hold point:** every pipe stands upright in its hole; the template lies flat.

### Step 8: fill with sand

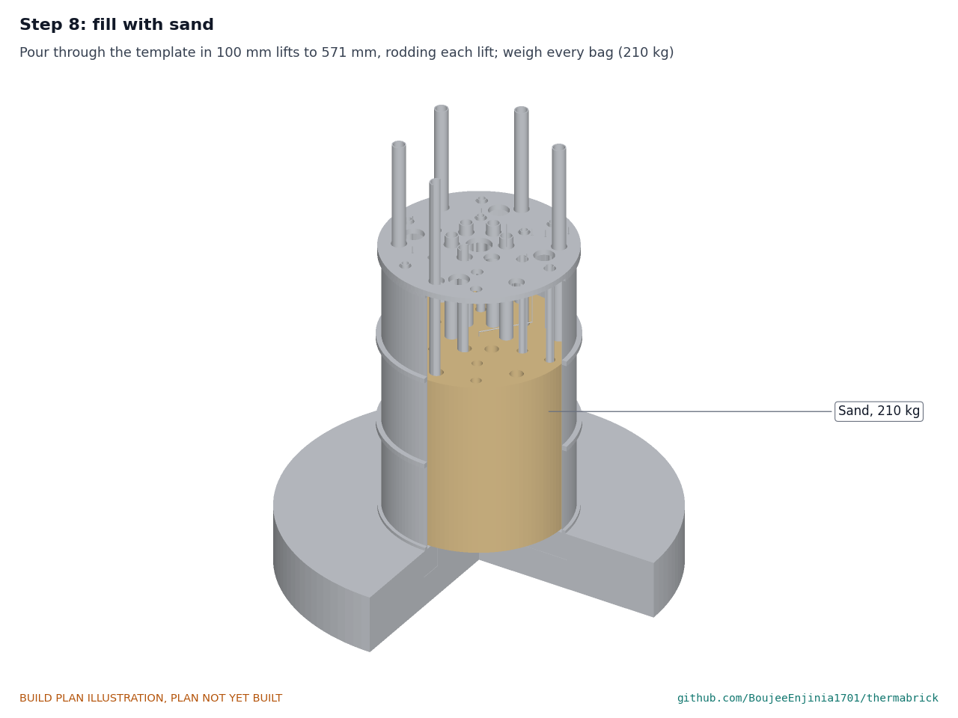
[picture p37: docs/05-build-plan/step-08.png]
Step 8


Dust control as safety stop S1: outdoors or local exhaust, and a respirator. Pour through the pour holes in 100 mm layers to 571 mm above the floor, rodding each layer round the pipes. Weigh every bag: 210 kg in all. Check the pipes stay upright as you go.

### Step 9: template off, headspace insulation in

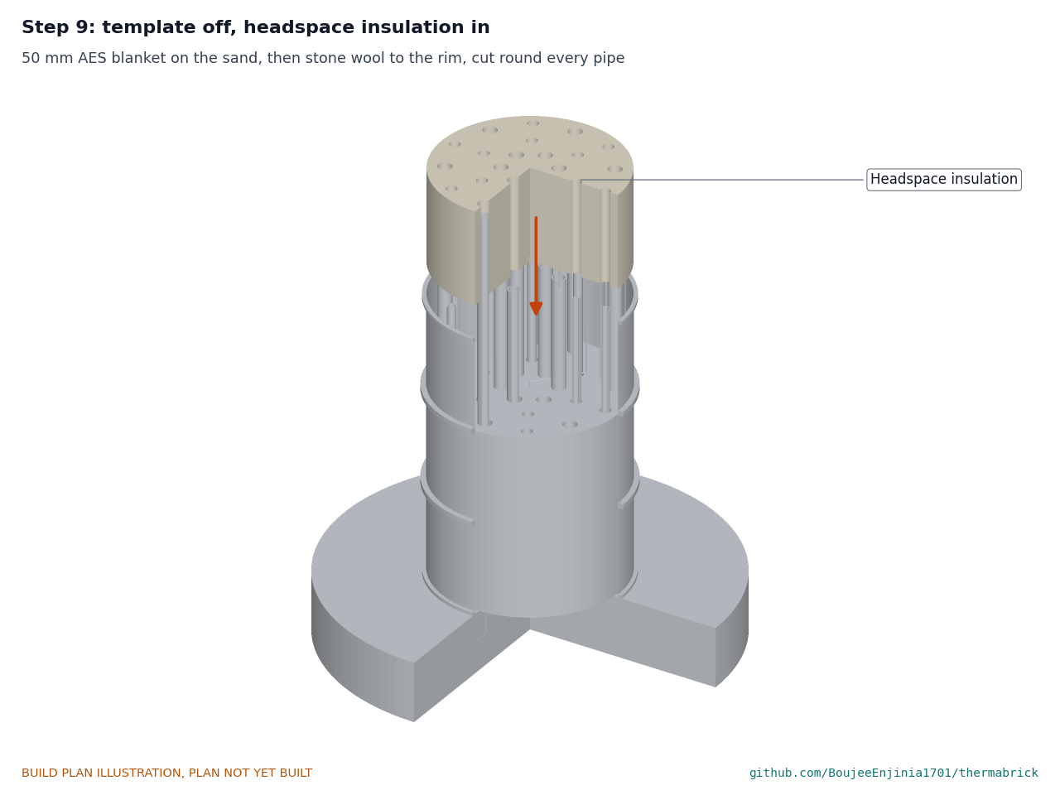
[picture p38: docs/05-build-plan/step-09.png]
Step 9


Lift the template off. Lay 50 mm of AES blanket on the sand, then stone wool batt to the rim, cut round every pipe and sheath. Bend T4 across the sand surface first (section 3.6).

### Step 10: lid and closing ring

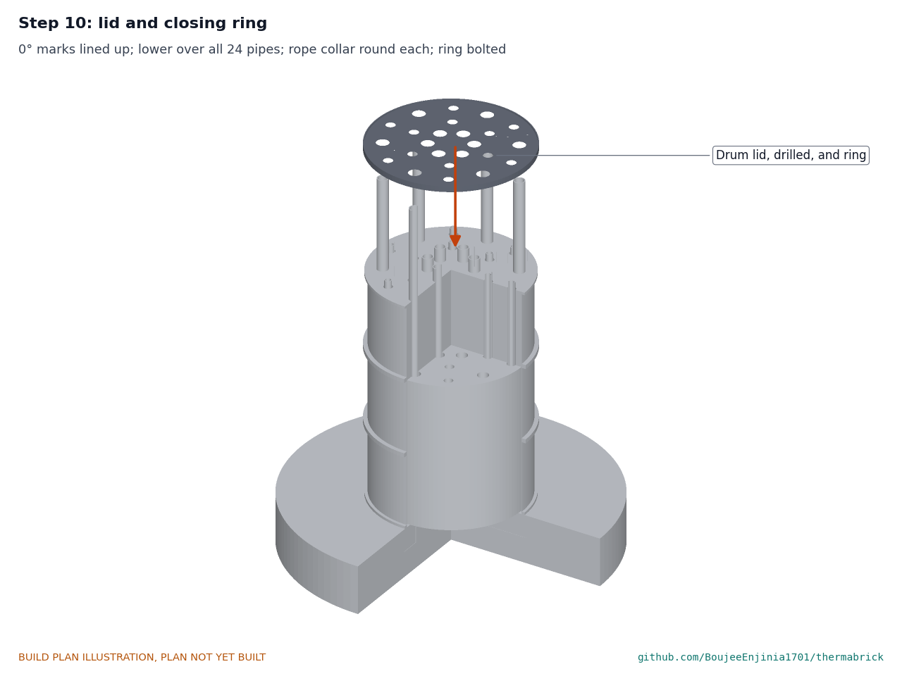
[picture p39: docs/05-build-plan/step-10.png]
Step 10


0° marks lined up; lower the lid over all 24 pipe ends and the four sand sheaths, passing T1 to T3 through their well holes. Lay an AES rope collar round each pipe and bolt the closing ring.

### Step 11: collector and outlet onto the lid

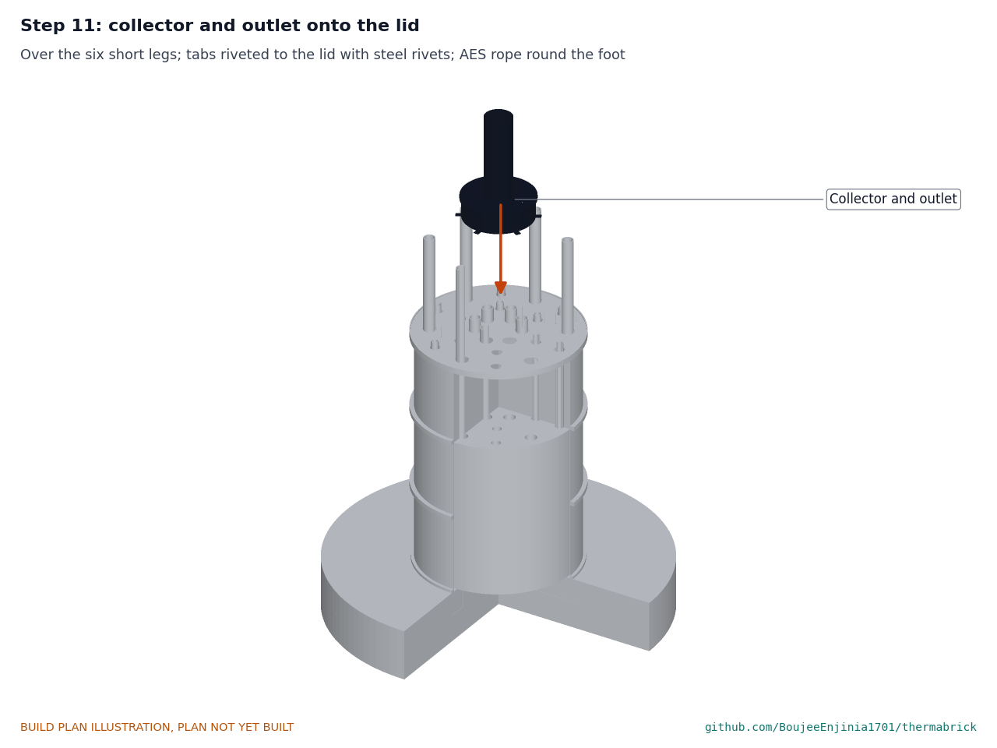
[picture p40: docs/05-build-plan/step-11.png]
Step 11


Over the six short legs, tabs between the wells; one steel rivet through each tab into the lid; AES rope round the foot of the ring. Fit T8 through the collector top.

### Step 12: heaters into the wells

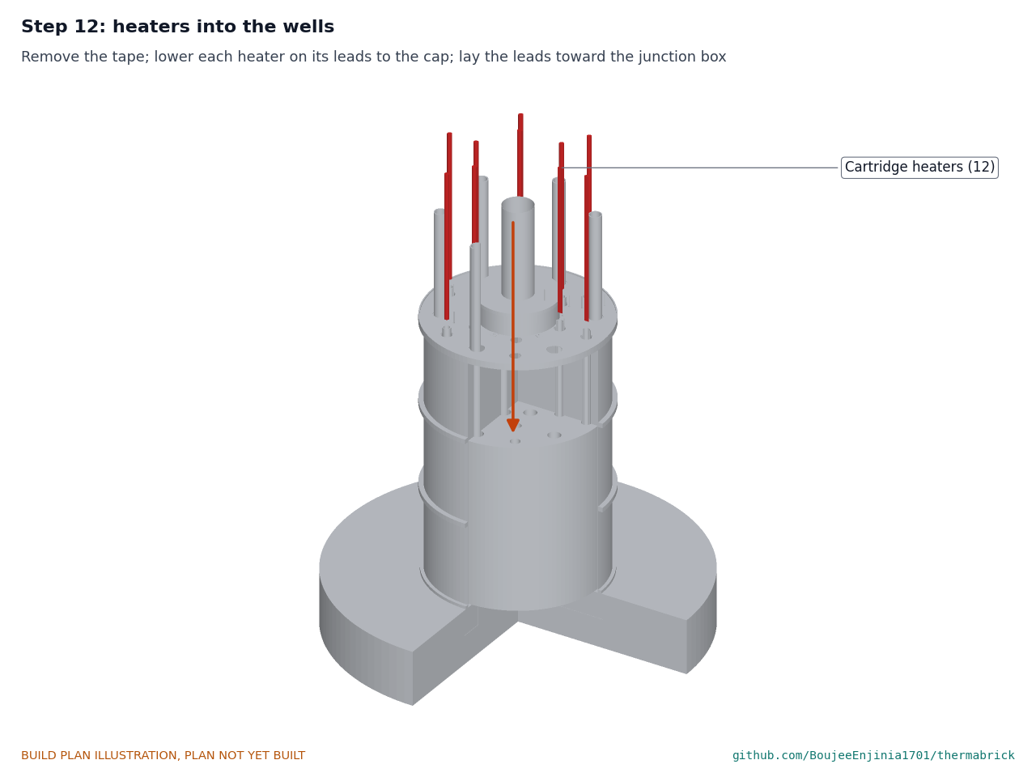
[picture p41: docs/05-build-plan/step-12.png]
Step 12


Remove the tape. Lower each heater on its leads until it rests on the cap. Lay the leads across the lid toward the junction box position (120°), labelled by well. **Hold point:** each heater reads 1 MΩ or more at 500 V to its sheath before the top insulation covers it.

### Step 13: side insulation

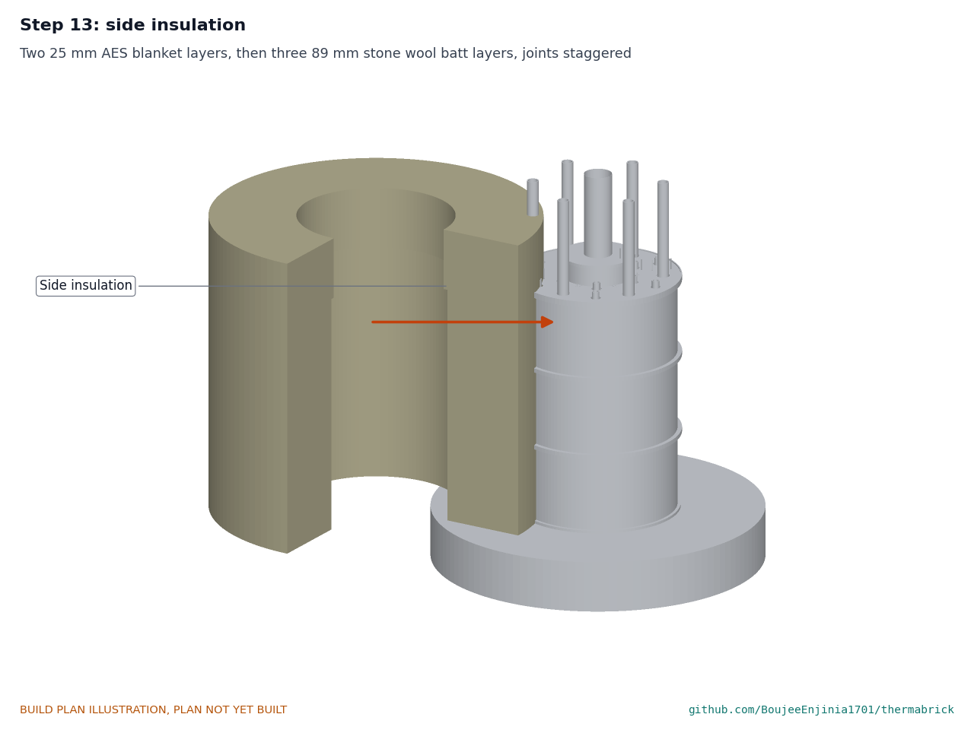
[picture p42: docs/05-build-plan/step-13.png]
Step 13


Two layers of 25 mm AES blanket against the drum, then three layers of 89 mm stone wool batt, joints staggered, held with wire until the jacket closes.

### Step 14: jacket side

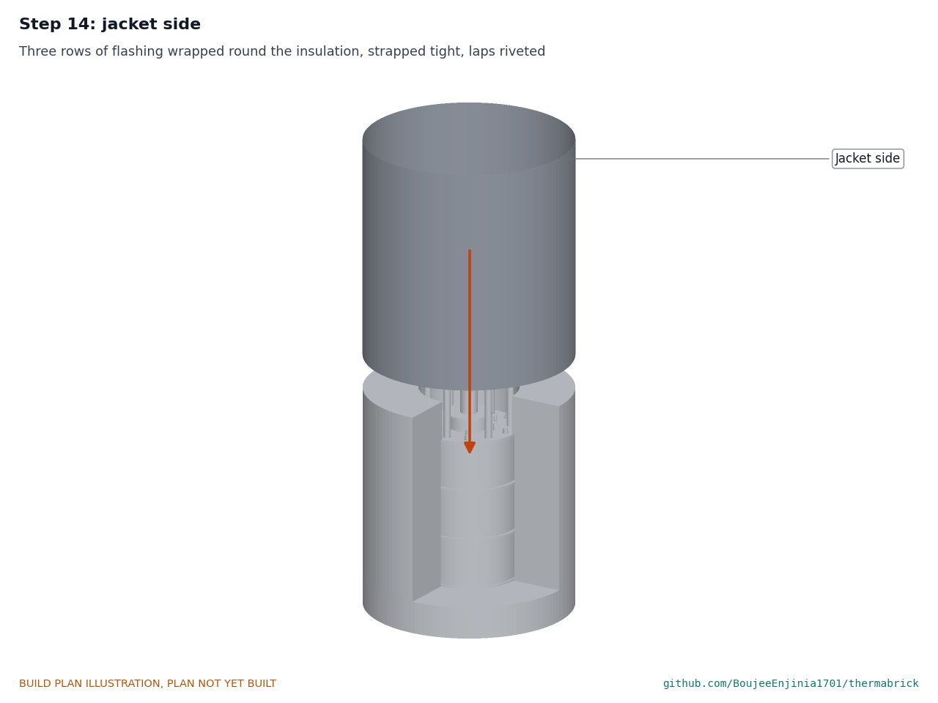
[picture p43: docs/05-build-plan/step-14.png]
Step 14


Three rows, strapped tight and riveted as section 3.8.

### Step 15: top insulation

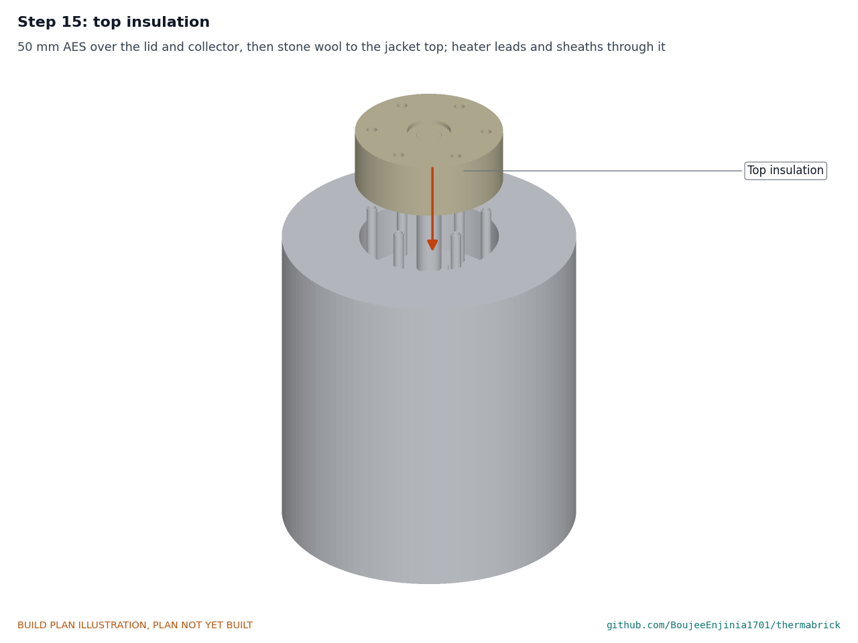
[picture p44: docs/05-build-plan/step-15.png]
Step 15


50 mm of AES blanket over the lid and collector, then stone wool batt to the top of the jacket, cut round the outlet and the long legs. Bring the heater leads up at the junction box position and the sheaths at the exit position; coil the spare sheath in the batt.

### Step 16: jacket cap

Step 16

Lower it over the long legs and the outlet, threading the leads and sheaths through their grommets. Eight screws through the skirt. Foil tape round each long leg.

### Step 17: outlet packing and trim ring

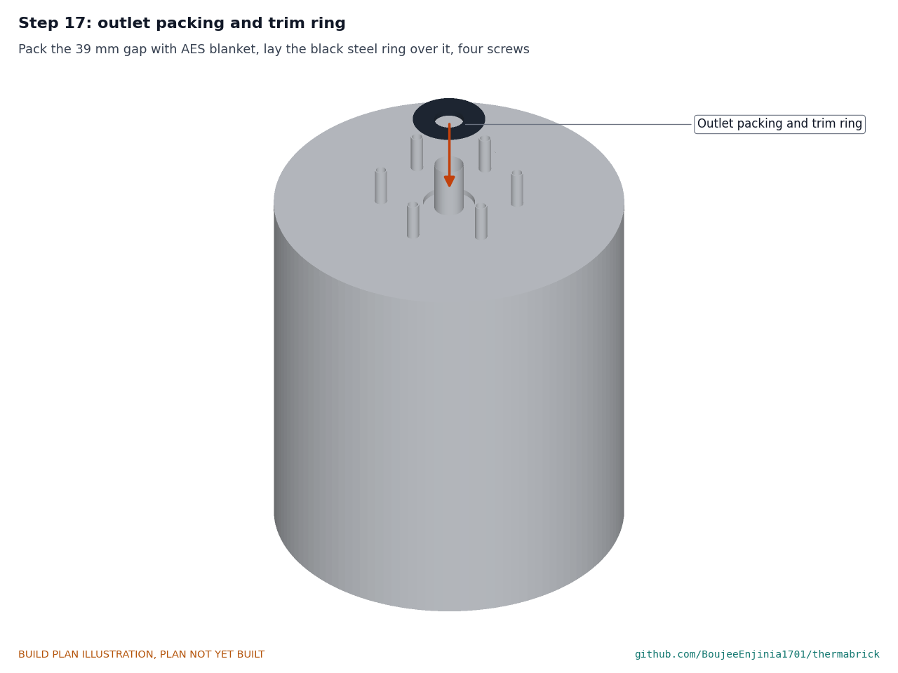
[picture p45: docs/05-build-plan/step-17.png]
Step 17


Pack the 39 mm gap round the outlet with AES blanket, 20 mm deep. Lay the black steel ring over it and screw it to the cap.

### Step 18: inlet plenum

Step 18

Over the six long legs, collar at 0°; rivet the flanges to the cap and seal them with foil tape.

### Step 19: heater junction box

Step 19

Over the 40 mm grommet; four screws to the cap. Land the leads on the ceramic terminal blocks in two groups of six, as Figure 25.

### Step 20: air path: damper, outlet duct, tee and fan

Step 20

The damper and its servo on the inlet collar. The 4 in outlet rises, turns and drops to the mixing tee as a heat trap; guard it with a perforated steel sleeve and keep it 450 mm from anything combustible. The balancing damper on the tee's room-air branch, then the fan below the tee, then the flexible duct to the register. The layout shown is one site; the rules are what matter.

### Step 21: control enclosure and wiring

The picture for this step is Figure 25. The control enclosure goes on the wall beside the unit. A licensed electrician runs the dedicated 240 V circuit and checks the wiring of Figure 25. **Hold point:** safety stop S5.

### Step 22: warning labels

Figure 26. Step 22: warning label positions

*Figure 26. The five warning labels and where they go (assembly step 22).*

Stick the labels on clean, dry metal once the unit is finished and the air path is in place, in this order:

1. HOT SURFACES INSIDE on the jacket side, at the front (0°), 1,060 mm above the floor.
2. HOT OUTLET on the jacket cap, 470 mm from the centre at 205°, clear of the plenum and the trim ring.
3. DANGER 240 V on the outer face of the junction box.
4. HOT SURFACE on the drop of the guard sleeve, facing the room.
5. DANGER 240 V on the door of the control enclosure.

**Check before moving on.** All five labels are on, square and readable from a standing position.

## 5. First checks

These are the checks a TRL 4 test report would record; this plan only lists them. Requirement numbers are those of TBK-REQ-001.

*Table 2. First checks.*

| Check | Requirement | How | Pass when |
| --- | --- | --- | --- |
| Envelope | R14 | Tape and level | 1,250 mm across or less; 1,500 mm high or less with the outlet stub |
| Heater insulation | R11 | 500 V insulation tester, each heater lead to sheath, before and after the bake-out | 1 MΩ or more |
| Branch circuit | R11 | Clamp meter on each heater group at full power | Under 16 A in all; about 6.25 A per group |
| Independent limit | R10 | Heat the T3 input (or a thermocouple simulator) past 600 °C with the heaters on | The contactor opens both legs and stays open until reset by hand |
| Fail-safe | R12 | Reset the controller, unplug a thermocouple, cut the export signal | Heaters off and damper closed within 60 s each time |
| Charge follows export | R2 | Log export and heater power through a sunny day | Heater power tracks surplus in 25 W steps; little or no grid import |
| Well wall and sand limit | R8 | Log T1, T2 and T4 to T7 through a full charge; a temporary thermocouple on the drum wall beside an outer well | Well walls 550 °C or less; drum wall 500 °C or less |
| Jacket and cap surfaces | R9, R13 | Contact probe at full charge: jacket side and top, and the cap at the edge of the outlet hole | Jacket 45 °C or less; cap edge under 200 °C |
| Supply air | R6 | Log the supply air sensor through a discharge | 55 °C or less at all times |
| Stored heat | R1 | Calorimetric discharge from full (air flow and temperature rise) | 18 kWh(th) or more between 150 and 450 °C |
| Heater service | R17 | Lift the cap and the top insulation, draw one heater, refit it | Done without disturbing the sand |

## 6. Safety stops

Stop at each point. Carry on only when everything listed is true.

- **S1. Before cutting firebrick or pouring sand.** Work outdoors or with local exhaust; P100 or N95 respirator, eye protection and gloves on; the area wet-cleaned afterwards, never dry-swept.
- **S2. Before handling fiber insulation.** Gloves, long sleeves, eye protection and a respirator; offcuts bagged.
- **S3. Before burning out the drum.** Outdoors, clear of buildings, with water to hand; the drum empty, open and never sealed.
- **S4. Before the top insulation covers the heaters.** Every heater reads 1 MΩ or more at 500 V lead to sheath; every lead is labelled and its beads are whole.
- **S5. Before the 240 V circuit is energized.** A licensed electrician has run and checked the dedicated circuit; the enclosure is closed and earthed; the junction box lid is on; the high limit trips the contactor in a test with the heaters disconnected.
- **S6. Before the first firing (bake-out).** The room is ventilated and smoke detectors are not disabled; the hot outlet guard is fitted and nothing combustible is within 450 mm of it; all five warning labels are on; someone stays with the unit until it holds 150 °C steadily.
- **S7. Before any heater is pulled or the lid opened.** The sand mean reads below 60 °C; the circuit is isolated and locked off.

## 7. Tools, skills and workspace

**Tools.** Pipe threader for 3/4 and 1-1/4 in (rental) with cutting oil; pipe cutter or hacksaw; two pipe wrenches; reamer; bi-metal hole saws 6 to 106 mm and a drill with a side handle; step drill; aviation snips; hand seamer (folding pliers); rivet gun for 4.8 mm rivets; sheet metal screwdriver bits; coarse handsaw or masonry blade for firebrick; long serrated insulation knife; trammel or string and nail; tape, steel rule and square; two ratchet straps; flap disc and angle grinder for paint stripping; 500 V insulation tester; multimeter with a type K input; clamp meter; kitchen or platform scale for the sand bags.

**Skills.** Pipe cutting and threading, sheet metal layout, cutting, folding and riveting, careful handling of fiber and dust. The 240 V circuit and enclosure wiring need a licensed electrician; everything else needs no certified trade.

**Workspace.** The final position on a concrete slab inside the heated space, with about 1 m of clear floor round it; an outdoor area for burning out the drum, cutting brick and pouring dusty materials; a bench with a pipe vice.

**Personal protective equipment.** P100 or N95 respirator for sand, brick and fiber; safety glasses; cut-resistant gloves for sheet metal; leather gloves for the drum burn-out; hearing protection for grinding.

## 8. Where the numbers come from

- Model and constructability checks: `cad/src/model.py` (`python cad/src/model.py --check`, 88 checks); STEP and STL in `cad/step/` and `cad/stl/`.
- Pictures: `cad/src/build_plan_media.py`, using `.kit/build_views.py`; written to `docs/05-build-plan/` and `cad/drawings/TBK-DWG-101` to `TBK-DWG-110`.
- General arrangement: `cad/drawings/TBK-DWG-001.pdf`, Rev P3.
- Calculations: `docs/04-calcs/TBK-CAL-001-sizing.md` (TBK-CAL-001 v0.5) and `docs/04-calcs/tbk_cal_001.py`; mass and floor load section 7, electrical section 6.
- Bill of materials: `bom/bom.csv` and `bom/bom-notes.md`.
- Decisions: `docs/decisions/0003-design-for-construction.md` (TBK-DDR-003), with TBK-DDR-002; open items in `docs/06-design-decisions.md` (TBK-DEC-001).
- Requirements: `docs/03-requirements.md` (TBK-REQ-001 v0.12).

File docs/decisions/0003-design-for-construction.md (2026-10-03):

---
doc_id: TBK-DDR-003
title: ThermaBrick design for construction
project: ThermaBrick
doc_type: Design decision record
version: "0.3"
status: Draft
date: '2026-10-02'
author: Amish Chadha
license: CERN-OHL-S-2.0
revisions:
- version: "0.1"
  date: '2026-09-30'
  author: Amish Chadha
  change: Changes that make the concept physically buildable, with the reason for each; made under Amish's 2026-09-30 instruction to make the design physically buildable; open for his review
- version: "0.2"
  date: '2026-10-02'
  author: Amish Chadha
  change: 'Accepted by Amish on 2026-10-02, including the recommendations for C1 and C2'
- version: "0.3"
  date: '2026-10-02'
  author: Amish Chadha
  change: 'Cost update for the approved warning labels (C1): BOM line 47, GA Rev P3'
---

# 0003: Design for construction

- **Date:** 2026-09-30
- **Status:** accepted. Amish, 2026-10-02: "i approve your recommendations for all 555 open decisions." This covers every change made under Amish's 2026-09-30 instruction to make the design physically buildable (P1 to P11 and their knock-on changes) and the recommendations for C1 and C2 in Table 3, now decided as recommended and recorded in the design decisions register (TBK-DEC-001).

## Context

On 2026-09-30 Amish asked for an illustrated build plan for every repo and wrote: "If you are realising that the design cannot be built as per concept - fix the design assumptions to match and be physically feasible as you draw the illustrations." The v0.2 model of ThermaBrick (TBK-PRC-001, TBK-DWG-001 Rev P1) showed what the unit does and sized it correctly, but a constructability review of `cad/src/model.py` and `bom/bom.csv` found eleven places where it could not be built, fixed or assembled as drawn (P1 to P11 below).

The changes keep what ThermaBrick does: the same drum, sand mass and depth, heater layout and rating, U-tube positions and bore, insulation thicknesses, envelope (1,209 mm by 1,462 mm), air path, controls and safety chain. Nothing here changes the pitch or the safety case; P1 is chosen specifically so that the drum-wall temperature case (R8) is unchanged. Every change is in `cad/src/model.py`, which now runs 72 constructability checks (`python cad/src/model.py --check`): parts that must not overlap do not; parts that stand on or are fixed to another touch it; holes, gaps, cut lengths, lead lengths and the firebrick count meet the stated limits; every part is a valid solid. All 72 pass.

## Decision

*Table 1. Changes made to the model, the BOM and the calculations.*

| # | Problem in the concept | Change made | Why this way |
| --- | --- | --- | --- |
| P1 | The heater wells hung 14 mm above the drum floor with nothing under them. The BOM cut length (906 mm) did not match the model (876 mm). | Each well stands on its cap on a levelled 14 mm first lift of sand, at the concept height; cut length 876 mm. | Standing the caps on the steel floor would put the hottest part of the bed in metal contact with the drum, against the R8 drum-wall case; a levelled sand lift supports the wells and keeps that case unchanged. |
| P2 | The U-tube bottoms floated 50 mm above the floor. Two 1-1/4 in elbows and the 2-1/2 in nipple in the BOM set the legs 118 mm apart, not the 155 mm the model and calculations use. The BOM leg lengths (1,149 and 901 mm) did not match the model. | Each U-tube is two malleable iron elbows and a 1-1/4 x 4 in nipple (155.6 mm between leg centres); the elbows rest on the drum floor, the run 28 mm above it. Leg cut lengths 1,175 mm (inlet) and 866 mm (outlet). | A 4 in nipple is the stock size that gives the 155 mm spacing. Resting on the floor gives every U-tube a firm seat during the fill. The U-tube carries no heat source, so floor contact does not change R8. |
| P3 | Lid holes 1 mm larger than the pipes in radius: 24 sand-set pipes cannot all pass at once, and the well-wall thermocouples T1 to T3 had no way through. | Well holes 36 mm (4.65 mm radial gap, enough for a 3 mm sheath beside the well), leg holes 48 mm (2.9 mm), four 6 mm holes for T4 to T7. An AES rope collar is laid round every pipe on the lid. | The lid can be lowered over every pipe; the rope collar keeps the headspace closed as the concept intended (the bed still breathes; no pressure). |
| P4 | The concept used the lid "as a top template on spacers" during the sand fill, but sand cannot be poured with the lid in place. | A plywood setting template (18 mm, 597 mm disc) drilled like the lid, with an 80 mm centre pour hole and four 64 mm pour holes, sits on the drum rim during the fill and is lifted off before the headspace insulation. New BOM line 43. | A temporary jig is the simplest way to hold 24 pipes and four sheaths upright and in place until the sand locks them. Every pour hole is at least 10 mm from a pipe or sheath hole. |
| P5 | The base was one solid cylinder. The firebrick course "under the drum footprint" left a void out to the jacket at the firebrick and AES levels, and 14 bricks cannot be cut to cover the footprint. | Firebrick laid flat and cut to a 610 mm disc (19 pieces from 15 bricks; 16 bought, one spare), an AES board disc of 610 mm on it, and a ring of 89 mm stone wool batt from 610 mm out to the jacket. | The drum's 597 mm bottom rim stands 6 mm inside the AES disc, over the firebrick that carries the load (15.0 kPa, safety factor 4 on the 60 kPa board). The 89 mm batt equals the 64 mm brick plus 25 mm AES board, so the base is level. |
| P6 | The inlet plenum was 110 mm tall, leaving 4 mm of wall above and below the 4 in collar, the collar's bore did not pass through the wall, and the plenum had no fixing to the cap. | Plenum 140 mm tall, a 4 in hole cut in the outer wall behind the collar, and 15 mm flanges folded out (outer wall) and in (inner wall), riveted to the cap and sealed with foil tape. The inlet legs are 30 mm longer to end 10 mm below its top. | 19 mm of wall each side of the collar takes the crimped collar's rivets. The overall height is unchanged because the plenum stays below the 160 mm outlet stub. |
| P7 | The collector ring had no fixing to the lid, and a continuous flange is impossible because the inner ring of wells passes 9.6 mm outside it. | Six tabs folded out at the foot of the ring, between the wells (at 30, 90, 150 ... degrees), each with one steel pop rivet into the lid; AES rope round the foot. The 18 ga top disc has a folded edge riveted to the ring. | Uses the stovepipe's own metal; steel rivets, not aluminium, in the hot zone (R13). |
| P8 | The galvanized jacket cap was drawn touching the 4 in outlet, which carries air at up to 314 °C, against R13 (no zinc above 200 °C). | A 180 mm clearance hole in the cap, the 39 mm gap packed with AES blanket, and a 250 mm black (uncoated) steel trim ring screwed to the cap over it. New BOM line 44. | Keeps zinc 39 mm from the hot pipe behind insulation, the same practice as a stovepipe passing a combustible surface. The cap-edge temperature is to be confirmed at the first firing (TBK-DEC-001). |
| P9 | The heaters' 36 in (914 mm) leads reach only about 350 mm sideways after rising out of the wells and the top insulation, but the farthest well is about 680 mm from the junction box; the box had no position in the model. | Heaters specified with 72 in (1,829 mm) ceramic-beaded leads (needs up to 1,593 mm with a 30 % routing allowance). Junction box on the cap at 120 degrees, 430 mm out, over a 40 mm grommeted hole; four screws. New BOM line 46 (grommets). | Longer leads are a standard option on made-to-order cartridge heaters. The box sits clear of the plenum (60 mm) and on the cool cap. |
| P10 | The thermocouples had no lid holes and no route out; the centre sand thermocouple T4 sat under the collector and outlet; 1,000 mm sheaths could not reach outside the jacket. | T1 to T3 tied to their wells and passing through the well holes; T4 rises from the centre to the sand surface and is bent once to cross between two outlet legs to a lid hole 165 mm out at 51 degrees; T5 to T7 at their stated positions, each tied to a stainless guide rod standing on the floor (new BOM line 45); T8 through a 4 mm hole in the collector top. Sheaths 1,500 mm, spare length coiled in the top insulation, leaving through one 25 mm grommet in the cap at 95 degrees, 330 mm out. | Mineral-insulated sheaths can be bent by hand. The measuring points of TBK-PRC-001 Table 3 are kept. |
| P11 | The jacket cap had no fixing, yet it must come off to replace a heater (R17), and it was drawn as one 1,210 mm disc although the flashing is 610 mm wide. | Cap made from three 610 mm strips lapped 25 mm and riveted, cut to a 1,260 mm disc with a 25 mm skirt turned down over the side, held by eight stainless sheet metal screws. | Screws let the cap, plenum and junction box lift off together for heater service; the side stays riveted. |

*Table 2. Knock-on changes.*

| Item | Change | Reason |
| --- | --- | --- |
| Mass | Insulation estimate 75 to 80 kg (base batt ring, two more firebricks); operating mass 415 kg (was 410 kg), within R15's 450 kg. Firebrick load 15.0 kPa (was 14.8 kPa). | TBK-CAL-001 v0.3, section 7, re-run with the sizing script. |
| Thermal and electrical | Unchanged. The changes alter no input of the sizing model. The U-tube runs sit 22 mm lower in the bed, which the one-dimensional model does not resolve. | TBK-CAL-001 v0.3 |
| Cost | BOM $3,853.50 (was $3,673.50, +$180.00): longer heater leads (+$48), longer thermocouples (+$32), 4 in nipples (+$12), two firebricks (+$12), second AES rope (+$20), fasteners (+$5) and lines 43 to 46 (+$51). Value-engineering target: USD 728. Estimated cost of the constructable design: USD 3,854 (USD 3,126 over the target). | `bom/bom.csv`, `bom/bom-notes.md` |
| Update, 2026-10-02 | The approved warning labels (C1) add BOM line 47, USD 15: BOM $3,868.50. Value-engineering target: USD 728. Estimated cost of the constructable design: USD 3,869 (USD 3,141 over the target). Mass unchanged at 415 kg; GA TBK-DWG-001 Rev P3. | `bom/bom.csv` |
| Drawing | TBK-DWG-001 Rev P2; making sketches TBK-DWG-101 to TBK-DWG-110 added. | Follows the model. |
| Documents | TBK-CAL-001 v0.3, TBK-PRC-001 v0.6, TBK-REQ-001 v0.10, TBK-PRB-001 v0.9: mass, cost, build summary, R13, R15, R17 and R20 notes. No requirement changed status: R3 stays not met (9.6 h against 8 h). | Follows the model. |

*Table 3. Proposed, then accepted by Amish as recommended on 2026-10-02.*

| # | Question | Options | Recommendation |
| --- | --- | --- | --- |
| C1 | Hot-surface and 240 V warning labels have no BOM line, though the appearance model shows them (REVIEW 2026-09-26, item 4) and they are a safety item. | (a) add one BOM line for the labels, about USD 15; (b) leave to the installer. | (a). Accepted 2026-10-02; the BOM line is still to be added. |
| C2 | The air path beyond the unit (hot duct route, tee and fan position, control enclosure on the wall) is drawn in the build plan from the illustrative layout of the appearance model (REVIEW 2026-09-26, item 2); real sites differ. | (a) keep it illustrative, with the rules the plan states (450 mm from combustibles, guard, heat trap, fan below the tee); (b) add an installation layout sheet. | (a) at TRL 3. Accepted 2026-10-02, with the rules stated as requirements an installer must meet (TBK-REQ-001, R15). |

## Consequences

- `design_state: constructable` in `project.yaml`. The build plan TBK-BLD-001 (`docs/05-build-plan.md`) shows every component and step in pictures generated from the model (`cad/src/build_plan_media.py`); open items are in the design decisions register TBK-DEC-001 (`docs/06-design-decisions.md`).
- STEP and STL exports (`cad/step/thermabrick.step`, `cad/stl/thermabrick.stl`), TBK-DWG-001 Rev P3 and the concept media are regenerated from the changed model.
- The photoreal renders (`media/render-*.png`), `media/card.png`, `media/social-preview.png` are made on Amish's Mac and are out of date until re-rendered. The appearance model `cad/src/product_model.py` was updated on 2026-10-02 to the constructable design and the render scenes were exported for that re-render.
- With C1 and C2 accepted, a warning label line (USD 15, BOM line 47) is in the BOM, and the siting rules (450 mm from combustibles, guard, heat trap, fan below the tee) are installer requirements in TBK-REQ-001 R15.
- The test article (TBK-PRC-002, archived) was not touched.

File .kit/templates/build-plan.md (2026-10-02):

---
doc_id: PRJ-BLD-001
title: Project prototype build plan
project: Project name
doc_type: Build plan
version: "0.1"
status: Draft
date: YYYY-MM-DD
author: Amish Chadha
license: CERN-OHL-S-2.0
revisions:
  - version: "0.1"
    date: YYYY-MM-DD
    author: Amish Chadha
    change: First build plan; design made constructable
---

# Project prototype build plan

**Plan, not yet built.** How to build the first proof-of-concept prototype, component by component. Building and testing to it is TRL 4 work. Decisions still to be made are kept in the design decisions register (`docs/06-design-decisions.md`), not here.

## 1. What you are building

Every component, pulled apart and numbered in build order

One short paragraph: what the prototype is, how many components, which are made and which are bought, and the main ways they are made.

## 2. What changed to make it buildable

| Component | The concept had | The buildable design has | Why |
| --- | --- | --- | --- |

## 3. Making the components

### 3.1 Component name

Making sketch

**What it is and what it is made from.**

**How to make it.**

1. Mark out ...
2. Cut ...

**How it fits the parts next to it.**

Close-up of the joint

**Check before moving on.**

## 4. Putting it together

### Step 1: ...

Step 1

## 5. First checks

| Check | Requirement | How | Pass when |
| --- | --- | --- | --- |

## 6. Safety stops

## 7. Tools, skills and workspace

## 8. Where the numbers come from

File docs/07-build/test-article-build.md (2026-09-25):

# Test article build procedure

Working document for building the ThermaBrick reduced-scale test article (TBK-PRC-002), from received parts to the start of test plan TBK-TST-001. Every dimension is taken from the generated cut list, `cut-list.md`, by item number (C1 to C12). Changes to this procedure are tracked in Git. Record each working session in the build log: `python build-log/new_entry.py "Title" --stage B` starts an entry with that stage's record table (see `build-log/README.md`).

Plan on three working days for the build, then the tests in TBK-TST-001, starting with TP0. Two people are needed to set the drum on its base. The finished unit weighs about 116 kg and is not moved once it is filled, so build it where it will be tested: indoors, on a concrete slab, with 1 m clear all round.

> **Safety:** The finished unit runs at up to 550 °C inside and on 120 V mains. Build and wire it exactly to TBK-DWG-003. Do not power the heaters until Stage L is signed off.

> **Safety:** Respirable silica and mineral fiber. Handle sand and stone wool outdoors or with local exhaust, wearing a P100 or N95 respirator, gloves, long sleeves and eye protection.

## 1. Before you start

**Documents.** Have these open or printed:

- TBK-DWG-002 (test article general arrangement);
- TBK-DWG-003 (controller schematic);
- TBK-DWG-005 (enclosure layout);
- `cut-list.md`;
- `bom/purchasing-checklist.md`, with every Received box ticked.

**Tools and safety equipment.** Those in the purchasing checklist, plus:

- a plywood disc of the drum's inner diameter to use as a template (Stage F);
- a 12 mm rod about 1 m long, for settling the sand;
- a 3 mm (1/8 in) mesh screen for sieving the sand;
- a stainless hose clamp for each of wells W1 and W3;
- steel tie wire;
- a paint pen.

**Parts added while writing this procedure.** These BOM lines came out of this procedure, so check they were bought:

- a second pack of stone wool batt, since cut list C9 needs about 5.98 m²;
- the heater cable, 16/3 SJT from the junction box to the enclosure;
- wiring consumables;
- type K extension wire with miniature connectors, which extends the 1 m probe leads to the enclosure. Keep the extension wire and connectors type K all the way to the MAX6675 terminals; a copper joint anywhere adds error.

## 2. Stage A: Incoming checks

1. Carry out every arrival check in the purchasing checklist.
2. Record each heater's cold resistance (55 Ω to 60 Ω) on the TBK-TST-001 TP0 sheet.
3. Check each type K probe with a multimeter: neither lead may be connected to the sheath (ungrounded junction). Label the probes T1 to T4 and the kit probes T5 and T6.

Type K color codes: in the US (ANSI), **yellow is positive and red is negative**. Kit probes often follow other codes, so check the polarity by warming the tip and watching the reading rise.

## 3. Stage B: Drum preparation (outdoors)

1. Remove the lid gasket and discard it. It is rated only to 121 °C.
2. Strip the exterior paint with a wire wheel or chemical stripper.
3. Burn out the rust inhibitor inside the empty drum with a small wood fire, lid off. Let it cool, then wire-brush the inside.
4. Mark the lid's +x direction (toward the controller) and its center. Drill the six holes of C3 and the three 4 mm thermocouple holes of C4. Deburr every hole.
5. Mark the sand level of C5 on the inside of the drum wall, measured from the inner floor.

## 4. Stage C: Wells and U-tube

1. Cut the four wells to the C1 length from the 3/4 in stick. Deburr the cut ends.
2. Crimp the bottom 25 mm of each well flat and closed in the vise. Fold the crimp over once more so that sand cannot enter.
3. Assemble the U-tube (C2) dry. Use no tape or sealant, which would burn out. Tighten every joint firmly so that the two legs are parallel and in one plane.
4. Trial-fit the wells and legs through the lid holes. The legs must be 206 ± 2 mm apart at the lid.

## 5. Stage D: Thermocouples on the internals

1. Clamp T1 to the outer face of well W1 with a stainless hose clamp. The tip goes at the C4 height, touching the pipe on the side facing the drum wall, with the probe running straight up the well.
2. Fit T2 to well W3 in the same way.
3. Cut two lengths of steel tie wire as guides for T3 and T4, each long enough to stand on the drum floor and reach the lid. Tie each probe to its guide so that the tip sits at the C4 height.

## 6. Stage E: Base and drum

1. Clean the slab at the final position.
2. Stand the four bricks on edge as in C6, radial at 45, 135, 225 and 315 degrees, with their centers 150 mm from the drum axis.
3. Pack stone wool between and around the bricks, to the brick height, across the full base diameter of C6.
4. With two people, set the empty drum on the bricks so that the chime bears across all four. Check it is level; shim a brick with a stone wool offcut if needed.

## 7. Stage F: Internals and sand

1. Make the template: a plywood disc of the drum's inner diameter, drilled to C3 and C4, with two 80 mm fill holes at x = ±130 mm, y = 0.
2. Stand the wells, U-tube and thermocouple guides in the drum and thread them through the template, which rests on the drum rim. Turn each well's crimp tangentially. The U-tube legs stand on the elbows, with the bend at the C2 height.
3. Sieve the sand. Weigh each bag and record the total, which should be 68 kg.
4. Pour the sand through the fill holes in lifts of about 100 mm. Settle each lift by pushing the rod down all over the surface, working around every pipe and probe. Keep the probes on their marks.
5. Stop at the C5 level mark. Record the mass poured and the measured depth.
6. Lift the template off over the pipes.

## 8. Stage G: Heaters

1. Lower a heater into each well, lead end up, until it rests on the crimp.
2. Run the leads straight up out of the well. They must not bend sharply where they leave the well mouth.

## 9. Stage H: Insulation and jacket

1. **Headspace (C7).** Lay the two stone wool discs on the sand, threading the wells, legs, heater leads and probes through their holes.
2. **Lid.** Lay a strip of stone wool around the rim as the gasket. Fit the lid over the pipes, probes and leads, then fit and bolt the closing ring. Pack stone wool into any gap around each pipe where it passes through the lid.
3. **Side (C8).** Wrap the three layers, staggering the joints between layers. Hold each layer with steel tie wire.
4. **Top (C9).** Lay the two discs over the lid, slit to pass the legs, leads and probes.
5. **Jacket (C10).** Wrap the two side rows with a 50 mm overlap. Fix the vertical seams with sheet metal screws and seal them with foil tape.
6. **Top cap.** Cut the cap with the leg holes and cable exits, and fit it over the top.
7. **Junction box.** Rivet the heater junction box to the top cap through a scrap reinforcing plate at least 100 mm square, 50 mm or more from either leg. Land the eight heater leads on the ceramic terminal block: all four first leads on one side (L_HEAT), all four second leads on the other (N).
8. **Cable.** Bring the heater cable into the box. Bond its green (PE) conductor to the drum with a ring lug under a closing-ring bolt.

## 10. Stage I: Blower and stack

1. Tape the blower outlet to the top of the inlet leg with aluminum foil tape, sealing all round.
2. Hang the stovepipe over the outlet leg so that the leg ends 40 mm inside its open bottom (C2). Hold it with three tie wires to the leg.
3. Fit T5 50 mm down inside the outlet leg top, and hang T6 300 mm from the blower intake, shaded from the unit.

> **Safety:** Keep 450 mm clear of combustibles around the stack, and guard it from casual contact.

## 11. Stage J: Controller enclosure

1. **Cutouts.** Mark and cut the lid and gland holes of C11. Cut the REX-C100 square by drilling the corners and joining them with a jigsaw or nibbler, then file to 45 mm. Fit the glands and buttons.
2. **Mounting plate.** Lay out the plate to TBK-DWG-005: the DIN rail at the C11 height with PS1 and the K1 socket on it, the SSR on its heat sink at top right (with thermal pad, fins vertical), and the controller area at bottom left. Fit the earth stud, and bond the plate to it.
3. **Controller.** Mount the ESP32, buck converter, MOSFET module, R1 and R2 and the five MAX6675 modules on perfboard in the controller area. Alternatively, fit the optional board (TBK-DWG-004).
4. **Mains wiring.** Wire every net in the C12 wiring list, starting with the mains nets:
   - the cord (14 AWG) goes to the fuse holder, and all other mains wiring is 16 AWG;
   - make the L_F and N junctions with the lever connectors under the REX-C100 position;
   - bond PE from the cord, plate, heater cable and enclosure to the earth stud.
5. **Low-voltage wiring.** Wire the low-voltage nets in 22 AWG, following `firmware/README.md`, Table 1. Fit the 10 kΩ pull-downs R1 and R2 at the ESP32 end.
6. **Thermocouples.** Join each probe lead to type K extension wire with a miniature type K plug and jack, and bring it in through the M25 gland. Land T1 and T3 to T6 on their MAX6675 modules, and T2 on the REX-C100 input, observing polarity.
7. **Lid.** Fit the REX-C100 and the buttons to the lid. Leave enough slack in their wires for the lid to open fully.

## 12. Stage K: Checks with the unit unplugged

| Check | Between | Expect |
| --- | --- | --- |
| Earth continuity | Plug earth pin to drum, jacket, stack, plate, enclosure stud, junction box and SSR heat sink | 0.5 Ω or less each |
| Heater load | SSR terminal 2 (L_HEAT) to N at the enclosure | 14 Ω to 15 Ω (four heaters in parallel, cold) |
| Heater insulation | L_HEAT and N to earth | Open on the multimeter's highest range |
| Mains short | Plug L to N, with START not pressed | Open, or the PS1 input only (not a short) |
| Coil path | Plug L to K1 coil A1 | Open (the REX-C100 relay is open while unpowered) |
| 12 V rail | +12V to GND | Not shorted |
| SSR input | GPIO 26 side of the SSR input to GND | About 10 kΩ (R1) |

*Table 1. Checks before power.*

## 13. Stage L: First power-up, heaters disconnected

1. Disconnect the heater cable's L_HEAT conductor from SSR terminal 2 and insulate it.
2. Press TEST on the GFCI receptacle to confirm it trips, reset it, and plug in the unit.
3. Check that PS1's LED lights and the 12 V rail reads 11.5 V to 12.5 V. Set the buck converter to 5.0 V before connecting the ESP32.
4. Configure the REX-C100 for on-off heating action with its relay output, setpoint 600 °C and type K input. Follow the supplier's manual. At room temperature its relay must be closed.
5. Press START: K1 pulls in and holds. Press STOP: K1 drops. Press START again, then unplug and replug the unit: K1 must stay open until START is pressed.
6. Build and flash the firmware (`firmware/README.md`), then set `v_line` to the measured line voltage. Set `r_heat` to the parallel resistance measured in Stage K multiplied by 1.04.
7. Start the logger. Check that T1 and T3 to T6 all read room temperature within ±2 K, and that T2 on the REX-C100 agrees. Warm each probe by hand to confirm it is the right channel.
8. Run the blower at 50 % from `/blower?mode=duty&value=0.5`; air must blow out of the stack. Turn it off.
9. Unplug the unit, reconnect L_HEAT to SSR terminal 2, and close the enclosure.

The build is complete. Start TBK-TST-001 at TP0, then run TP1 (limit test, cold) before any heating.

## 14. Sign-off

| Stage | Done by | Date | Notes |
| --- | --- | --- | --- |
| A Incoming checks | | | |
| B Drum preparation | | | |
| C Wells and U-tube | | | |
| D Thermocouples | | | |
| E Base and drum | | | |
| F Internals and sand (record mass and depth) | | | |
| G Heaters | | | |
| H Insulation and jacket | | | |
| I Blower and stack | | | |
| J Controller enclosure | | | |
| K Checks unplugged | | | |
| L First power-up | | | |

*Table 2. Build sign-off.*

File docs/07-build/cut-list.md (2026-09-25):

# Test article cut list

Generated by `docs/07-build/cutlist.py` from `cad/src/test_article.py`, `cad/src/enclosure.py` and `electronics/src/schematic.py`. Do not edit; regenerate after any model change. Dimensions in mm. The build procedure (`test-article-build.md`) refers to the item numbers.

## C1. Heater wells

Four pieces of 3/4 in black steel pipe, **692 mm** each, from one 10 ft (3,048 mm) stick. Crimp the bottom 25 mm of each closed in a vise, leaving a finished well of 667 mm. The well bottom stands 20 mm above the inner drum floor and the top ends 25 mm above the lid.

## C2. U-tube

Two 1-1/4 in x 36 in black nipples (legs), two 1-1/4 in 90 degree elbows and one 1-1/4 in x 6 in nipple. No cutting.
Assembled, the leg centers are 206.4 mm apart and each leg top stands 152 mm above the jacket top. The bend centerline sits 50 mm above the inner floor.

## C3. Drum lid holes

Measured from the lid center. Mark +x toward the front, where the controller will stand, before drilling.

| Hole | x | y | Diameter | For |
| --- | --- | --- | --- | --- |
| W1 | 90 | 75 | 28.7 | Heater well W1 |
| W2 | -90 | 75 | 28.7 | Heater well W2 |
| W3 | -90 | -75 | 28.7 | Heater well W3 |
| W4 | 90 | -75 | 28.7 | Heater well W4 |
| Inlet | 0 | -103.2 | 44.2 | U-tube inlet leg |
| Outlet | 0 | 103.2 | 44.2 | U-tube outlet leg |

*Thermocouple probes pass through the headspace insulation beside wells W1 and W3 and at the center; drill three 4 mm holes in the lid at the C4 positions.*

## C4. Thermocouple positions

Tips **300 mm above the inner drum floor**, all four. With 500 mm probes the probe top ends 40 mm below the jacket top, inside the top insulation, so the lead junction stays cool.

| Tag | Location | x | y |
| --- | --- | --- | --- |
| T1 | Well W1 outer face (control) | 100 | 84 |
| T2 | Well W3 outer face (limit) | -100 | -84 |
| T3 | Sand, drum axis | 0 | 0 |
| T4 | Sand on the W1 ray, 20 mm from the drum wall | 116 | 97 |

T5 goes 50 mm inside the top of the outlet leg; T6 hangs 300 mm from the blower intake.

## C5. Sand

68 kg of dry washed sand, filled to **491 mm above the inner floor** (42.5 L). Mark the level on the inside of the drum wall before filling. The headspace above it is 170 mm.

## C6. Base

Four K-23 bricks stood on edge (230 x 64 x 114), radial at 45, 135, 225 and 315 degrees, centered 150 mm from the drum axis (inner ends 35 mm, outer ends 265 mm). The drum chime bears across each brick. Pack stone wool between the bricks to the full base diameter of 879 mm.

## C7. Headspace insulation

Two discs of stone wool, 343 mm diameter, stacked to 170 mm. Cut holes for the four wells, both legs and three thermocouple probes at the C3 and C4 positions.

## C8. Side insulation

Three layers of 89 mm batt around the drum, 852 mm tall (base to jacket top). Butt the joints and stagger them between layers.

| Layer | Inner radius | Wrap length at mid-thickness | Batt pieces (387 wide) |
| --- | --- | --- | --- |
| 1 | 172 | 1,363 | 4 pieces of 387 x 852 |
| 2 | 261 | 1,922 | 5 pieces of 387 x 852 |
| 3 | 350 | 2,481 | 7 pieces of 387 x 852 |

## C9. Top insulation

Two discs of 89 mm batt, 345 mm diameter, over the lid, to 178 mm. Slit for the legs, heater leads and thermocouple probes.

*Batt check: about 5.98 m2 of 89 mm batt is needed (headspace, side, top and base) against 5.55 m2 in one pack. The BOM lists 2 packs (11.09 m2).*

## C10. Jacket

Aluminum flashing, 508 mm (20 in) wide. Side: two rows, each 2,814 mm long (includes 50 mm overlap), lapped 50 mm where they meet; total height 966 mm, trim the top row to fit. Top cap: a 910 mm disc from two overlapped strips, with a 15 mm turned-down edge, and holes for both legs (44.2 mm), the heater leads and the thermocouple leads. Flashing used: about 7.4 m of the 7.6 m roll.

## C11. Controller enclosure

Lid, measured from its bottom-left corner seen from the front (250 x 200 lid):

| Cutout | x | z | Size |
| --- | --- | --- | --- |
| REX-C100 | 185 | 55 | 45 x 45 square (center) |
| STOP | 100 | 55 | 22.5 diameter |
| START | 135 | 55 | 22.5 diameter |

Bottom face, holes on a line 75 mm back from the lid face, x from the left end:

| Gland | x | Hole |
| --- | --- | --- |
| M25 TC bundle | 45 | 25.5 diameter |
| M16 blower | 90 | 16.5 diameter |
| M20 supply | 180 | 20.5 diameter |
| M20 heater out | 220 | 20.5 diameter |

DIN rail: cut to 152 mm, fixed to the mounting plate 132 mm up from the plate's bottom edge, starting at its left edge.

## C12. Wiring list

Every connection on TBK-DWG-003, generated from `electronics/src/schematic.py`. Mains nets (L_, N, PE and heater nets) in 16 AWG, 105 C rated, except the cord to F1 in 14 AWG; low-voltage nets in 22 AWG.

| Net | Connects |
| --- | --- |
| L_COIL | K1.A1, U2.NO |
| L_F | F1.2, K1.11, PS1.L, SW1.1, U2.L |
| L_HEAT | H1.1, H2.1, H3.1, H4.1, U1.2 |
| L_IN | F1.1, J1.L |
| L_K | K1.14, U1.1 |
| L_RUN | K1.24, SW2.2, U2.COM |
| L_STOP | K1.21, SW1.2, SW2.1 |
| N | H1.2, H2.2, H3.2, H4.2, J1.N, K1.A2, PS1.N, U2.N |
| PE | J1.PE |
| +12V | PS1.V+, U3.IN+, U4.VIN+ |
| +3V3 | U10.VCC, U5.3V3, U6.VCC, U7.VCC, U8.VCC, U9.VCC |
| +5V | U3.OUT+, U5.5V |
| BLOWER_N | M1.-, U4.OUT- |
| BLOWER_P | M1.+, U4.OUT+ |
| BLOWER_PWM | R2.1, U4.PWM, U5.IO25 |
| CS_T1 | U5.IO5, U6.CS |
| CS_T3 | U5.IO17, U7.CS |
| CS_T4 | U5.IO16, U8.CS |
| CS_T5 | U5.IO4, U9.CS |
| CS_T6 | U10.CS, U5.IO22 |
| GND | PS1.V-, R1.2, R2.2, U1.4, U10.GND, U3.IN-, U3.OUT-, U4.GND, U4.VIN-, U5.GND, U6.GND, U7.GND, U8.GND, U9.GND |
| SCK | U10.SCK, U5.IO18, U6.SCK, U7.SCK, U8.SCK, U9.SCK |
| SO | U10.SO, U5.IO19, U6.SO, U7.SO, U8.SO, U9.SO |
| SSR_IN | R1.1, U1.3, U5.IO26 |
| TC1N | TC1.-, U6.T- |
| TC1P | TC1.+, U6.T+ |
| TC2N | TC2.-, U2.TC- |
| TC2P | TC2.+, U2.TC+ |
| TC3N | TC3.-, U7.T- |
| TC3P | TC3.+, U7.T+ |
| TC4N | TC4.-, U8.T- |
| TC4P | TC4.+, U8.T+ |
| TC5N | TC5.-, U9.T- |
| TC5P | TC5.+, U9.T+ |
| TC6N | TC6.-, U10.T- |
| TC6P | TC6.+, U10.T+ |

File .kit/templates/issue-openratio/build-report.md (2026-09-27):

---
name: Build report
about: Tell us what happened when you built, printed or tested part of this design
title: "Build report: "
labels: build-report
---

This is a research and educational prototype, not a medical device. It is a TRL 3 concept and is not released for fabrication. If you build any part of it, you do so at your own risk. Reports help everyone.

**What you built** (part, sub-assembly or test)

**Materials, tools and settings**

**What worked**

**What did not work, with photos or measurements if you have them**

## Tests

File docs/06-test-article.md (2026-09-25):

---
doc_id: TBK-PRC-002
title: ThermaBrick test article design precis
project: ThermaBrick
doc_type: Design precis
version: "0.11"
status: Draft
date: '2026-09-24'
author: Amish Chadha
license: CERN-OHL-S-2.0
revisions:
- version: "0.1"
  date: '2026-09-24'
  author: Amish Chadha
  change: Initial draft. Reduced-scale test article of about 6 kWh(th) within $600, with objectives, design, BOM summary, test plan and safety; general arrangement TBK-DWG-002 Rev P1
- version: "0.2"
  date: '2026-09-24'
  author: Amish Chadha
  change: Replaced the test outline with a summary of test plan TBK-TST-001 and renumbered the tests TP0 to TP6 so they no longer share tags with the thermocouples
- version: "0.3"
  date: '2026-09-24'
  author: Amish Chadha
  change: Controller firmware and logging host written; pin assignments recorded in firmware/README.md
- version: "0.4"
  date: '2026-09-24'
  author: Amish Chadha
  change: Analysis script for TBK-TST-001 written and self-tested
- version: "0.5"
  date: '2026-09-24'
  author: Amish Chadha
  change: Controller schematic TBK-DWG-003 Rev P1 added; relay specified as DPDT; pull-down resistors added to the BOM ($599.70); PE bonding stated
- version: "0.6"
  date: '2026-09-24'
  author: Amish Chadha
  change: Added the optional controller board (TBK-DWG-004 Rev P1) and its cost, $24.85 above the hand-wired baseline
- version: "0.7"
  date: '2026-09-24'
  author: Amish Chadha
  change: Added the controller enclosure (TBK-DWG-005 Rev P1). The fit check required a 150 mm deep enclosure and a DIN-rail 12 V supply, and added glands, DIN rail and wiring parts; the estimate rose to $635.70, over the $600 budget, with options listed
- version: "0.8"
  date: '2026-09-24'
  author: Amish Chadha
  change: Recorded the decision to accept $635.70 as the test article budget
- version: "0.9"
  date: '2026-09-24'
  author: Amish Chadha
  change: Build section now points to the build procedure and cut list; corrected the well cut length (692 mm), the envelope height (1,688 mm) and the thermocouple height (300 mm above the drum floor); listed the open items the build procedure found
- version: "0.10"
  date: '2026-09-24'
  author: Amish Chadha
  change: Added the four items the build procedure found to the BOM (second stone wool pack, heater cable, wiring consumables, thermocouple extension); budget now $727.70
- version: "0.11"
  date: '2026-09-24'
  author: Amish Chadha
  change: 'Review pass: the $727.70 budget returned to proposed, awaiting Amish (accepted budget remains $635.70); controller board marked optional and deferred'
---

# ThermaBrick test article design precis

The test article is a one-third-scale ThermaBrick. It is a 16 US gal steel drum holding 68 kg of sand, storing 5.9 kWh(th) between 150 °C and 450 °C. The parts are estimated at $727.70, $127.70 over the original $600 target. Amish accepted $635.70 on 2026-09-24; the rise to $727.70 is proposed, awaiting Amish (section 5). It keeps the part of the design that carries the most risk at full fidelity: four heater cells built from the same 5/8 in cartridge heaters, 3/4 in wells and cell spacing as the full-scale unit. It cuts cost everywhere else:

- one U-tube instead of the full-scale density;
- a 120 V plug-in supply instead of a 240 V branch circuit;
- stone wool in place of AES fiber;
- a small blower and dilution stack in place of the fan and mixing tee;
- a generic controller as the independent limit.

Its purpose is to measure the numbers the full-scale design rests on before $3,674 is spent on it. Those are sand conductivity, wall contact conductance, insulation loss and the exchanger's heat transfer.

| Parameter | Value |
| --- | --- |
| Vessel | 16 US gal open-head steel drum, unlined, 20 ga (Uline S-19411) |
| Storage | 68 kg washed play sand, 491 mm deep; 5.9 kWh(th) between 150 °C and 450 °C |
| Charge | 4 cartridge heaters, 250 W at 120 V, in 3/4 in crimped wells; 1.0 kW, 8.3 A |
| Charge time from empty | 15.7 h at up to 1.0 kW, including standby loss |
| Discharge | One 1-1/4 in U-tube, 12 V blower up to 4 L/s; 250 W held for 8.8 h |
| Standby loss | 249 W at full charge |
| Envelope and mass | 880 mm diameter, 1,688 mm high including the stack; about 116 kg |
| Controls | ESP32 with five thermocouple channels; separate latching 600 °C limit |
| Parts cost | $727.70 estimated (`bom/bom-test-article.csv`); accepted budget $635.70, rise proposed |

*Table 1. Key parameters of the test article.*

Test article general arrangement drawing TBK-DWG-002 Rev P1

*Figure 1. Test article general arrangement, TBK-DWG-002 Rev P1, generated from `cad/src/test_article.py`.*

## 1. Objectives

The article answers five questions. Each one feeds a specific number in TBK-CAL-001.

| No. | Question | What it settles at full scale |
| --- | --- | --- |
| O1 | What are the effective conductivity of the sand and the contact conductance at the well wall, from 150 °C to 550 °C? | Charge time and the R3 shortfall (TBK-CAL-001, section 3 and Table 8) |
| O2 | How much heat does the envelope lose, and is stone wool acceptable as the hot face? | Standby loss (R7) and a possible saving of about $330 on AES fiber |
| O3 | Does the U-tube air-side and sand-side model predict exchanger duty within 15 %? | Rated output (R4) and boost (R5) |
| O4 | Do the well-wall charge limit and the latching high limit work as intended? | Safety design (R8, R10, R12) |
| O5 | Does a thin drum grow or deform over repeated cycles? | Ratcheting risk (R19) |

*Table 2. Test objectives.*

## 2. What is kept and what is cut

| Element | Full scale | Test article | Effect on the test |
| --- | --- | --- | --- |
| Heater cell | 5/8 in heater in a 3/4 in well, cell radius 79.7 mm | Same heater and well, cell radius 84.4 mm | Full fidelity for O1 |
| Heater | 20 in, 240 V, US industrial brand | 18 in, 120 V, made-to-order import | Check each resistance on arrival |
| Well bottom | Threaded cap | Pipe end crimped closed in a vise | No threader needed |
| Exchanger | Six U-tubes, leg cell radius 81 mm | One U-tube, leg cell radius 120 mm | Tests the model, not the full-scale output (O3) |
| Air handling | Fan, servo damper, collector, mixing tee | 12 V blower on the inlet leg; dilution stack over the outlet | Flow measured directly at the inlet |
| Insulation | AES hot face and stone wool | Stone wool throughout | Tests a cost-down option (O2) |
| Supply | 240 V, 20 A, GFCI breaker | 120 V plug into a GFCI receptacle | Saves $190 |
| Limits | 1/16 DIN limit and contactor | REX-C100 and latching power relay | Same function (O4) |
| PV following | Energy meter | Not fitted; charges on a timer or from the inverter API | Deferred to firmware |

*Table 3. Differences from the full-scale design.*

## 3. Design

**Vessel and sand.** The 16 US gal drum stands on four K-23 firebricks set on edge under the chime, with stone wool packed between them. Three 50 lb bags of play sand, sieved and weighed, fill it to 491 mm. Remove the rubber lid gasket, which is rated only to 121 °C, and seal the lid with a strip of stone wool.

**Heaters and wells.** Cut a 10 ft stick of 3/4 in black pipe into four 692 mm wells, and crimp the bottom 25 mm of each closed in a vise. The wells stand 20 mm off the drum floor at (±90, ±75) mm and end 25 mm above the lid. Each holds a 5/8 in by 18 in cartridge heater, 250 W at 120 V. The four heaters are wired in parallel through one fuse, one SSR and the contacts of the latching relay.

**Exchanger.** A U-tube made of two 1-1/4 in by 36 in black nipples, two elbows and a 6 in nipple, with its legs at y = ±103 mm. The blower is taped to the inlet leg. The outlet leg ends 40 mm inside the open bottom of a 24 in, 4 in stovepipe, which draws in room air and dilutes the exchanger air before it leaves the top. Peak outlet air is 319 °C at the lowest test demand.

**Envelope.** Two layers of stone wool in the headspace and two over the lid, three layers around the side and an aluminum flashing jacket. The jacket runs at 26 °C at full charge.

**Controls.** An ESP32 reads five MAX6675 channels:

- T1: well-wall control thermocouple, clamped to one well 300 mm above the drum floor;
- T3: sand at the center, 300 mm above the drum floor;
- T4: sand 20 mm from the drum wall, beside a well, 300 mm above the drum floor;
- T5: exchanger outlet air;
- T6: room air.

It drives the SSR with the same rule as full scale: full power until T1 reaches 550 °C, then PI control to hold it. A separate REX-C100 reads T2, a second thermocouple on another well. Its relay output is closed below 600 °C and sits in the coil circuit of the latching power relay. An over-temperature, a press of STOP or a power interruption drops the relay, and it stays open until START is pressed. The ESP32 also drives the blower by PWM and logs every channel at 10 s intervals over Wi-Fi.

The full circuit is TBK-DWG-003 Rev P1, the controller schematic. Its KiCad source is in `electronics/test-article/`, generated by `electronics/src/schematic.py`. The latching relay K1 is double pole: pole 1 carries the heater current and pole 2 is the holding contact. R1 and R2, both 10 kΩ, hold the SSR and blower off while the ESP32 boots. The drum, wells, jacket, stack, enclosure, heater junction box and SSR heat sink are all bonded to the protective earth of the supply cord.

**Enclosure.** The controller sits in a 250 × 200 × 150 mm polycarbonate wall enclosure (IP65, UL 94 V-0 or 5VA) with a steel mounting plate bonded to PE. The layout is drawing TBK-DWG-005, generated from `cad/src/enclosure.py`.

- **DIN rail:** the HDR-15-12 supply and the K1 relay socket.
- **Top right:** the SSR on its heat sink, fins vertical.
- **Bottom left:** the controller, as modules or the optional board.
- **Under the REX-C100:** the lever-connector junctions for L_F and N.
- **Lid:** the REX-C100 and the STOP and START buttons.
- **Bottom face:** four cable glands (M25 thermocouples, M16 blower, M20 supply and M20 heater cable).

The model's fit check confirms that every part clears its neighbors by 3 mm. The REX-C100 body, 98 mm deep, ends 36 mm in front of the plate. A 100 mm deep enclosure fails the same check.

## 4. Build

The step-by-step procedure is `docs/07-build/test-article-build.md`. It takes about three working days, and needs no pipe threader and no electrician. Every dimension in it comes from the generated cut list, `docs/07-build/cut-list.md`.

The stages run in this order:

1. Incoming checks.
2. Drum preparation.
3. Wells and U-tube.
4. Thermocouples.
5. Base and drum, set at the final position.
6. Sand, filled through a plywood template.
7. Heaters.
8. Insulation and jacket.
9. Blower and stack.
10. Controller enclosure.
11. Checks with the unit unplugged.
12. First power-up with the heaters disconnected.

Writing the procedure turned up four items the BOM had not covered. All four were added on 2026-09-24, for $92.00:

- a second pack of stone wool ($60.00), since the cut list needs about 5.98 m² against 5.55 m² in one pack;
- a heater cable from the junction box to the enclosure ($8.00);
- wiring consumables ($12.00);
- type K extension wire with miniature connectors ($12.00), so the enclosure need not sit within reach of the 1 m probe leads.

> **Safety:** Respirable crystalline silica and mineral fiber. Fill and fit insulation outdoors or with local exhaust, wearing a P100 or N95 respirator, gloves and eye protection.

> **Safety:** The 4 in stack and the exchanger outlet run above 100 °C during discharge. Keep 450 mm clear of combustibles around the stack, and do not touch it while the blower is running.

> **Safety:** Plug only into a GFCI-protected receptacle rated 15 A or more, with nothing else on the circuit. Never bypass or bridge the latching relay or the REX-C100 limit.

## 5. Budget

| Group | Cost (USD) |
| --- | --- |
| Drum and sand | 134.50 |
| Heaters and wells | 100.00 |
| U-tube, blower, supply and stack | 118.00 |
| Insulation, bricks and jacket | 180.00 |
| Controls, enclosure and wiring | 195.20 |
| Total | 727.70 |

*Table 4. Test article cost by group. Line items are in `bom/bom-test-article.csv`.*

The basis is the same as the full-scale BOM: US retail and marketplace list prices in September 2026, before tax and shipping.

The estimate is $35.70 over the original $600 target. The controller enclosure model (TBK-DWG-005, section 3) showed that the $600 figure rested on three wrong entries:

- a $10 enclosure, 100 mm deep, that cannot take the REX-C100 (98 mm behind the lid);
- a barrel-jack 12 V adapter that should not be hard-wired inside a mains enclosure;
- no allowance for glands, DIN rail, lever connectors or an earth stud.

The corrected enclosure and wiring add $36.00. Three options were considered:

1. accept $635.70, with every part specified;
2. defer the $25 discharge kit until TP5 and build for $610.70 first;
3. use an enclosure or supply already on hand.

**Decided by Amish on 2026-09-24: option 1.** The budget for the test article is $635.70, and the whole article, discharge kit included, is built at once.

The build procedure (section 4) then found $92.00 of parts the BOM had not covered: a second stone wool pack, the heater cable, wiring consumables and thermocouple extension wire. Amish had them added to the BOM the same day, so it now totals $727.70. Raising the accepted budget from $635.70 to $727.70 is **proposed, awaiting Amish**.

The following tools are assumed to be on hand and are not in the budget: a multimeter, a bathroom scale, a vise, a pipe cutter, a drill with hole saws, snips and a stopwatch.

### 5.1 Optional controller board (deferred)

**Status: optional and deferred.** The test article is built with hand-wired modules. The board is not ordered or built unless Amish decides otherwise after the review.

The low-voltage controller can be built on a printed circuit board instead of hand-wired modules. The board is drawing TBK-DWG-004 Rev P1, with its KiCad source and gerbers in `electronics/controller-board/` and its parts in `bom/bom-controller-board.csv`. It measures 110 mm by 80 mm and has two layers with a ground plane.

The ESP32-DevKitC V4 and the five MAX6675 modules plug into sockets. Discrete parts replace the buck and MOSFET modules: a RECOM R-78E regulator, an IRLZ44N MOSFET with a 1N5819 flyback diode, and a 2N3904 SSR driver. The nets and GPIO pins are the same as TBK-DWG-003, so the firmware is unchanged. The mains wiring stays on the panel either way.

The board adds $24.85:

- $27.85 of board parts, including one order of five boards;
- less $6.00 for the two modules it replaces;
- plus about $3.00 for a genuine DevKitC V4 in place of a generic board, whose header spacing may not fit.

That would take the test article to $752.55. It is therefore an option, not the baseline, and it is deferred. Its value is a repeatable, inspectable wiring job for the controller.

## 6. Test plan

Test plan TBK-TST-001 sets out seven procedures over about seven weeks, summarized in Table 5. The procedure numbers (TP) are separate from the thermocouple tags (T1 to T6).

| Procedure | Purpose | Key pass criterion |
| --- | --- | --- |
| TP0 Inspection and instrument checks | Build, sand mass, thermocouple and airflow calibration | Channels within ±2 K at 0 °C and 100 °C |
| TP1 Limit and fault response, cold | O4 | Latching trip at 600 °C ± 10 K; firmware safe state within 10 s |
| TP2 Bake-out and commissioning | Dry the sand, burn off binder, settle at 150 °C | 1 MΩ or more per heater at 500 V |
| TP3 Charge | O1 | Fitted model within 10 K RMS; time to 80 % within 10 % |
| TP4 Cool-down | O2 | Loss within 20 % of 249 W before fitting |
| TP5 Discharge | O3 | Duty within 15 % of the model, with no refit |
| TP6 Cycling | O5 | Drum growth under 0.25 % after 25 cycles |

*Table 5. Test procedures (TBK-TST-001).*

The fitted sand conductivity, contact conductance and insulation conductivity then go back into `tbk_cal_001.py`. TBK-CAL-001 will be reissued with measured values before the full-scale build is committed.

## 7. Open questions

- [ ] Confirm heater lead time and resistance tolerance from the chosen supplier; order one spare if the budget allows.
- [ ] Confirm the blower delivers 4 L/s through the U-tube (96 Pa) by the bag method in TP0.
- [x] Write firmware for charge control, logging and blower PWM (`firmware/`; wiring and API in `firmware/README.md`).
- [x] Write the formal test plan, TBK-TST-001.
- [x] Write the analysis script `docs/05-tests/tbk_tst_001_fit.py` (TBK-TST-001, section 9).

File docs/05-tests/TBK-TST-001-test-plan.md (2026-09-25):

---
doc_id: TBK-TST-001
title: ThermaBrick test article test plan
project: ThermaBrick
doc_type: Test plan
version: "0.6"
status: Draft
environment: lab
date: '2026-09-24'
author: Amish Chadha
license: CERN-OHL-S-2.0
revisions:
- version: "0.1"
  date: '2026-09-24'
  author: Amish Chadha
  change: Initial draft. Six test procedures for the reduced-scale test article, with instrumentation, uncertainty, analysis method, pass criteria, safety and schedule
- version: "0.2"
  date: '2026-09-24'
  author: Amish Chadha
  change: Firmware and logging host written (firmware/); section 1 now references them and lists the added sand trip; prerequisite checked off
- version: "0.3"
  date: '2026-09-24'
  author: Amish Chadha
  change: Analysis script written and checked on synthetic data. Section 9 adds a fitted heater power correction and defines the time-to-80 % and closure checks so they are independent of the fitted model state; TP3 pass wording and prerequisites updated
- version: "0.4"
  date: '2026-09-24'
  author: Amish Chadha
  change: Thermocouple tips moved from 245 mm to 300 mm above the drum floor, so the 500 mm probes end inside the top insulation (docs/07-build/cut-list.md, C4)
- version: "0.5"
  date: '2026-09-24'
  author: Amish Chadha
  change: Section 12 names the report template TBK-TST-002 and the script that fills its analysis sections
- version: "0.6"
  date: '2026-09-24'
  author: Amish Chadha
  change: 'Kit 1.1.4: front matter adds environment: lab (the test article is tested in a lab setting, STANDARDS section 1)'
---

# ThermaBrick test article test plan

This plan tests the reduced-scale test article (TBK-PRC-002) in six procedures over about seven weeks. They measure the three properties the full-scale design rests on: the effective conductivity of the sand, the contact conductance at the well wall and the conductivity of the insulation. They also check the exchanger model, the safety limits and the drum's durability over 25 cycles. The measured values replace the literature values in `tbk_cal_001.py`, and TBK-CAL-001 is reissued with them before any money is committed to the full-scale build. Results go in test report TBK-TST-002.

| Procedure | Purpose | Objective (TBK-PRC-002) | Full-scale requirement informed | Duration |
| --- | --- | --- | --- | --- |
| TP0 | Inspection and instrument checks | None | None | 1 day |
| TP1 | Limit and fault response, cold | O4 | R10, R12 | 0.5 day |
| TP2 | Bake-out and commissioning | O4 | R13 | 3 days |
| TP3 | Charge | O1 | R3, R8 | 1 day |
| TP4 | Cool-down | O2 | R7 | 2 days |
| TP5 | Discharge | O3 | R4, R5 | 4 days |
| TP6 | Cycling | O5 | R19 | 5 weeks |

*Table 1. Test procedures, in order of execution.*

Procedure numbers follow the order in which the procedures are run. The limit test comes before any heating, and the charge test starts from the uniform 150 °C that the bake-out leaves behind. Sensor tags (T1 to T6) are those of TBK-PRC-002, section 3. They are not the same thing as the procedure numbers.

## 1. Test article and configuration

The article is built to TBK-DWG-002 Rev P1 and `bom/bom-test-article.csv`. Any departure from the drawing is recorded in the test log before TP0 and repeated in the report. The firmware version (Git commit) is recorded at the start of every procedure.

The firmware must provide five things before TP1:

1. **Charge mode:** full power until T1 reaches its setpoint, then PI control to hold it. The setpoint is adjustable, 550 °C by default.
2. **Hold mode:** PI control on T1 at a lower setpoint, used for the bake-out.
3. **Blower mode:** fixed PWM duty set from the Wi-Fi interface.
4. **Logging:** every channel, the SSR duty and the blower duty at 10 s intervals to a CSV file, with a monotonic time stamp.
5. **Safe state:** heaters off (SSR input low, with a pull-down resistor on the pin) after a reset, an open thermocouple on T1, a T1 reading above 575 °C or loss of the log for 60 s.

The firmware in `firmware/` provides all five, and `firmware/README.md` gives the wiring, commands and fault codes. It adds two further trips: T3 or T4 above 560 °C, and a stalled main loop. The logging host is `firmware/tools/logger.py`. Its polling is the log heartbeat in item 5, so stopping the logger is how TP1 step 5 tests that trigger. The T1 injection in TP1 step 5 uses the `esp32dev_test` build.

## 2. Instrumentation

| Tag | Quantity | Location | Sensor and reader |
| --- | --- | --- | --- |
| T1 | Well-wall temperature (control) | Well W1 at (90, 75) mm, outer face toward the drum wall, 300 mm above the drum floor | Type K, MI 3 mm, 500 mm; MAX6675 |
| T2 | Well-wall temperature (limit) | Well W3 at (−90, −75) mm, same height and face | Type K, MI 3 mm, 500 mm; REX-C100 |
| T3 | Sand temperature, center | Drum axis, 300 mm above the drum floor | Type K, MI 3 mm, 500 mm; MAX6675 |
| T4 | Sand temperature, outer | On the ray through W1, 151 mm from the axis (34 mm from the W1 center, 20 mm from the drum wall), 300 mm above the floor | Type K, MI 3 mm, 500 mm; MAX6675 |
| T5 | Exchanger outlet air | 50 mm inside the top of the outlet leg, on its axis | Type K kit probe; MAX6675 |
| T6 | Room and inlet air | 300 mm from the blower intake, shaded from the unit | Type K kit probe; MAX6675 |
| P | Heater power | Derived from SSR duty, line voltage and measured hot resistance | ESP32 log and multimeter |
| V | Exchanger airflow | Outlet leg top, before the stack is fitted | Bag method: 159 L (42 gal) contractor bag and stopwatch |
| C | Drum circumference | At 100 mm, 330 mm and 560 mm above the drum bottom, over the bare drum | Steel tape, 1 mm graduation |
| M | Sand mass | Every bag before filling | Bathroom scale, 0.1 kg graduation |

*Table 2. Instrumentation.*

The tips sit 300 mm above the drum floor, within the heated length (45 mm to 451 mm) and clear of both its ends. At that height the 500 mm probes end inside the top insulation, where their lead junctions stay cool. T3 and T4 sit at radii the model can reproduce. T4 is 34 mm from the center of W1, inside that heater's cell, and is compared with the model at 34 mm. T3 lies 117 mm from all four wells, beyond the 84 mm cell radius, and is compared with the model's outer edge. Before filling, photograph each thermocouple against a steel rule and record its as-built position to ±5 mm.

### 2.1 Checks before testing

- **Thermocouple channels.** Put all six probes in an ice bath (0 °C) and then in boiling water (100 °C less about 0.0033 K per meter of site elevation). Accept a channel if it reads within ±2 K at both points, and record its offsets. Correct the logged data with them.
- **Heater resistance.** Measure each heater cold with the multimeter; the expected value is 55 Ω to 60 Ω. Record the values and compute the four-in-parallel resistance.
- **Line voltage.** Measure it at the receptacle, under load, at the start and end of every heated procedure.
- **Airflow.** With the stack off and the unit cold, tape the bag mouth over the outlet leg top. Time the fill at blower duties of 25 %, 50 %, 75 % and 100 %, three times each. The result is the duty-to-airflow table used in TP5.

### 2.2 Measurement uncertainty

| Quantity | Uncertainty | Basis |
| --- | --- | --- |
| Temperature, 20 °C to 600 °C | ±5 K | Type K standard limits (±2.2 K or ±0.75 %) plus converter, after the two-point check |
| Heater power | ±5 % | Line voltage read twice per run; NiCr resistance rises about 4 % from cold to 600 °C and is corrected |
| Energy input | ±5 % | Integrated power |
| Exchanger airflow | ±10 % | Bag method, mean of three fills; hot running changes the system resistance |
| Exchanger duty | ±12 % | Airflow and temperature rise combined |
| Standby loss from cool-down | ±15 % | Slope of the estimated mean temperature; sand mass ±1 % |
| Drum circumference | ±1 mm in 1,080 mm (±0.1 %) | Steel tape, same person, same marks |

*Table 3. Measurement uncertainty.*

The mean sand temperature cannot be measured directly with three sand-side thermocouples. The analysis therefore does not estimate it from the sensors. Instead, the model is run with the measured heater power as its input, and its predicted T1, T3 and T4 are compared with the measurements (section 9).

## 3. Safety

The article runs at up to 550 °C inside, with 1.0 kW on a 120 V receptacle, and it releases hot air during discharge.

> **Safety:** Stop the test, press STOP and let the unit cool if any of the following occurs: T1 or T2 above 575 °C; smoke from the unit after TP2 is complete; a GFCI trip; any jacket surface above 45 °C; a smell of hot electrical insulation from the enclosure; or loss of logging for more than 60 s during heating.

> **Safety:** Do not leave the article unattended until TP1 has passed and the first charge (TP3) has run without incident. After that it may run unattended only with the latching limit in service, the smoke alarm in the room working, and 1 m clear of combustibles all round and above the stack.

> **Safety:** Wear a P100 or N95 respirator, gloves and eye protection when opening the insulation. Do not open the lid or pull a heater until T3 reads below 60 °C.

## 4. TP0 Inspection and instrument checks

1. Inspect the build against TBK-DWG-002. Record the sand mass per bag and the total (target 68 kg ± 1 kg) and the as-built thermocouple positions.
2. Mark the three circumference heights on the bare drum with a paint pen. Measure and record them before the insulation is fitted. These are the cycle-0 values for TP6.
3. Carry out the checks in section 2.1.
4. Confirm the receptacle is GFCI protected by pressing its TEST button, and that nothing else is on the circuit.

**Pass:** all channels within ±2 K; heater resistances within 55 Ω to 60 Ω and within 5 % of one another; sand mass 67 kg to 69 kg.

## 5. TP1 Limit and fault response, cold

The heaters stay cold throughout. T2 is withdrawn from its well only for this test and refitted afterward.

1. Set the REX-C100 to open its relay at 600 °C. Power the unit, press START, and confirm the latching relay pulls in. The heaters must not be energized, so hold the SSR input low from the firmware.
2. Place the T2 tip in the jet of a heat gun beside a reference Type K probe. Raise the temperature slowly, at about 5 K/s near 600 °C. Record the reading of each at the moment the relay drops.
3. Remove the heat. Confirm the relay stays open when T2 falls below 600 °C, and that it closes only when START is pressed.
4. Press STOP with the relay latched and confirm it drops. Unplug the cord, plug it back in, and confirm the relay stays open until START is pressed.
5. With the heaters enabled at a 10 % duty, check each firmware safe-state trigger: unplug T1 at its connector; force a T1 reading above 575 °C with a test build; reset the ESP32; stop the logging host. Record the time to heaters off for each.

**Pass:** the relay drops at 600 °C ± 10 K by the reference probe; it latches open in every case; each firmware trigger turns the heaters off within 10 s.

## 6. TP2 Bake-out and commissioning

This procedure dries the sand, burns off the stone wool binder and the drum's residues, and leaves the bed at a uniform 150 °C for TP3.

1. Check the insulation resistance of each heater, lead to sheath, with an insulation tester at 500 V. Borrow or rent the tester, since it is not in the BOM. If none is available, record the multimeter reading on its highest range and note the lower confidence. Expect low values if the MgO has absorbed moisture; the bake-out cures this.
2. Ventilate the room. Hold T1 at 200 °C in hold mode until T3 reaches 100 °C. Leave the U-tube legs open so steam can escape.
3. Raise the T1 setpoint to 300 °C. Hold until T3 and T4 are both within 10 K of 150 °C, then lower the T1 setpoint so that T1, T3 and T4 settle within 15 K of 150 °C for 6 h.
4. Note any smoke or odor and when it stopped.
5. Repeat step 1 on the hot unit with the power off.

Assumption: washed play sand arrives with 3 % to 5 % moisture. Driving off 2 kg to 3.4 kg of water takes 1.5 kWh to 2.5 kWh on top of heating the bed, so the bake-out takes about two days.

**Pass:** insulation resistance of 1 MΩ or more per heater at 500 V after the bake-out; no smoke in the last 12 h; T1, T3 and T4 within 15 K of 150 °C for 6 h.

## 7. TP3 Charge

1. Start from the end state of TP2. Tape the U-tube leg ends and switch off the blower.
2. Record the line voltage. Switch to charge mode with the T1 setpoint at 550 °C.
3. Log until T3 reaches 420 °C or 24 h have passed, whichever comes first. Record the line voltage every 4 h.
4. Note the time at which the SSR duty first falls below 100 %. The model predicts 2.1 h (TBK-CAL-002, section 3).

The unit is full, at a 450 °C mean, when the fitted model says so (section 9). The 420 °C T3 end point is a practical stop that the model predicts shortly before full charge.

**Pass:** the fitted model reproduces T1, T3 and T4 with an RMS error of 10 K or less; its controller-driven run predicts the time to 80 % charge within 10 % of the measured energy balance; and the heater power correction is within 5 % (section 9).

**Also report:** the unfitted prediction error; the fitted sand conductivity multiplier and contact conductance; and the time at which the well-wall limit was reached.

## 8. TP4 Cool-down

1. Immediately after TP3, switch the heaters off. Leave the blower off with the legs taped.
2. Log for 48 h. Once an hour for the first 6 h, and then every 12 h, record the jacket temperature at mid-height on four sides and on the top with a contact thermometer. Record room temperature from T6.
3. Remove the tape from the leg ends at the end of the test.

**Pass:** the measured loss at a 450 °C mean, from the fitted cooling rate, is within 20 % of the 249 W predicted by TBK-CAL-002 before fitting. No jacket surface exceeds 45 °C.

**Also report:** the fitted insulation conductivity multiplier; loss at 300 °C and 150 °C; any hot spot on the jacket.

## 9. Analysis method

The analysis script `docs/05-tests/tbk_tst_001_fit.py` fits four values to the TP3 and TP4 data:

- `k_sand`, a multiplier on the sand conductivity;
- `h_contact`, the wall contact conductance, in W/(m² K);
- `k_ins`, a multiplier on the stone wool and firebrick conductivity; and
- `p_scale`, a correction to the logged heater power, which carries the ±5 % uncertainty of Table 3.

The script drives the TBK-CAL-002 model with the measured heater power instead of the model's own controller. It then minimizes, by Levenberg–Marquardt least squares, the RMS difference between measured and modeled T1 (well wall), T4 (cell at 34 mm) and T3 (cell outer edge), over the whole TP3 and TP4 record at 60 s spacing. The model starts from a uniform bed at the mean of T3 and T4 in the first row.

**Why the four values can be separated:**
- The cool-down has no heater power, so it fixes `k_ins` on its own.
- With the loss known, the rate at which the bed heats in TP3 fixes `p_scale`.
- The shape of the charge curves at the three radii fixes `k_sand` and `h_contact`.

The script reports each value with a 95 % interval from the fit's Jacobian. That interval is optimistic, because successive residuals are correlated; treat it as a lower bound on the uncertainty.

The script reports these checks:

- **RMS error**, fitted and unfitted, overall and for each thermocouple.
- **Time to 80 % charge.** The measured value comes from the energy balance: the corrected heater energy less the loss fitted on the cool-down, added to the heat at the start. The predicted value comes from a run of the fitted model under its own 550 °C well-wall controller. Agreement shows that the real controller and bed take heat as fast as the model says.
- **Energy closure over TP3.** The corrected heater energy is compared with the stored heat plus the fitted loss. The stored heat is estimated from the measured temperatures alone, through a linear radial profile between T1, T4 and T3. The estimate reads slightly high because T1 includes the contact drop at the well wall. Closure within 10 % is expected.
- **Standby loss** from the fitted envelope, at 450 °C, 300 °C and 150 °C, against the 249 W prediction.
- **Power correction** within 5 %. A larger correction points to a wrong `v_line` or `r_heat` setting in the firmware.

TP5 is then predicted with the fitted values and no further fitting. Its only comparison is between measured and modeled exchanger duty, averaged over each hour. The first hour is not scored, because the model starts from a uniform bed.

The commands are as follows, run from the repo root:

```bash
python docs/05-tests/tbk_tst_001_fit.py selftest
```

```bash
python docs/05-tests/tbk_tst_001_fit.py fit --tp3 docs/05-tests/data/DATE_TP3.csv --tp4 docs/05-tests/data/DATE_TP4.csv
```

```bash
python docs/05-tests/tbk_tst_001_fit.py tp5 --tp5 docs/05-tests/data/DATE_TP5.csv
```

Results are written as JSON and SVG to `docs/05-tests/results/`. The self-test builds charge, cool-down and discharge records from known values with the model. It adds 1.5 K of thermocouple noise, a 2 % power error and 3 % duty noise, then fits them. It passes only if every value is recovered: `k_sand` and `k_ins` within 5 %, `h_contact` within 30 %, `p_scale` within 2 %, and TP5 within 15 %. The TP5 part checks the plumbing of the prediction, not the physics, because the same model made the data.

## 10. TP5 Discharge

1. Charge to full as in TP3, allowing up to 16 h.
2. Remove the tape, fit the blower and set it to the duty that gives 1.0 L/s from the section 2.1 table. Fit the stack.
3. Run at constant blower duty for 8 h, then 2.0 L/s for 8 h, then 4.0 L/s until T3 falls to 180 °C.
4. Recharge to full and repeat with a closed-loop demand of 250 W. The firmware adjusts the blower duty to hold ṁ cp (T5 − T6) at 250 W, using the airflow table.

Exchanger duty is ṁ cp (T5 − T6), with ṁ from the airflow table and cp of air at the mean of T5 and T6.

**Pass:** at each constant-airflow step, measured duty averaged over each hour is within 15 % of the model's prediction using the parameters fitted in section 9. In the closed-loop run, 250 W is held for 8.8 h ± 1.5 h.

**Also report:** the peak T5; the stack exit temperature measured with the contact thermometer; and whether the blower met 4.0 L/s hot.

## 11. TP6 Cycling

1. Run 25 cycles. Each cycle is a charge to full as in TP3, followed by a discharge at 4.0 L/s until T3 falls to 180 °C. This takes about 32 h per cycle.
2. Every five cycles, when T3 is below 60 °C, open the side insulation at the three marks. Measure the drum circumference at each and refit the insulation. Photograph the drum and the bricks.
3. Log continuously. Note any drift in the time for T1 to reach 550 °C from cycle to cycle; a steady increase suggests the sand is packing or breaking down around the wells.
4. After cycle 25, open the lid and inspect the sand surface. Draw one heater, and inspect it and its well.

**Pass:** circumference growth under 0.25 % at every height after 25 cycles, with no trend that would exceed 1 % in 1,000 cycles when extrapolated (full-scale R19); no crushing of the firebricks; heaters within 5 % of their TP0 resistance.

## 12. Schedule and records

| Week | Procedures |
| --- | --- |
| 1 | TP0, TP1, TP2 |
| 2 | TP3, TP4, TP5, analysis of TP3 and TP4 |
| 3 to 7 | TP6 (25 cycles of about 32 h) |

*Table 4. Schedule.*

Raw logs are saved as `docs/05-tests/data/YYYY-MM-DD_TPn.csv`. Record in the file header the firmware commit, the channel offsets from section 2.1 and the line voltage readings. Photographs and daily notes go in `build-log/` as dated entries. Nothing in the raw data is edited; corrections are applied in the analysis script and recorded there.

The results, fitted parameters and pass or fail for every procedure go in test report TBK-TST-002. After running the analysis, `python docs/05-tests/tbk_tst_002_fill.py` fills the report's TP3 to TP5 results, its fitted-property tables and a re-run of the full-scale sizing with the fitted values; the rest is written by hand from the build log and test records. The fitted values are then entered in `tbk_cal_001.py`, and TBK-CAL-001 is reissued. That reissue decides the options for the full-scale charge-time gap (TBK-PRC-001, section 8).

## 13. Prerequisites

- [ ] Test article built and inspected to TBK-DWG-002 (TP0).
- [x] Firmware with the five functions in section 1, committed to `firmware/`; host unit tests pass.
- [ ] Firmware flashed and the wiring checked against `firmware/README.md`, Table 1.
- [x] Analysis script `docs/05-tests/tbk_tst_001_fit.py`, checked against a synthetic data set made with `tbk_cal_002.py` (`selftest` passes).
- [ ] Insulation tester borrowed or rented for TP2.
- [ ] Contact thermometer for jacket and stack surfaces (a Type K bead probe on a spare MAX6675 channel is acceptable).
- [ ] Smoke alarm working in the test room.

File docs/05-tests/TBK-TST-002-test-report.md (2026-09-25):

---
doc_id: TBK-TST-002
title: ThermaBrick test article test report
project: ThermaBrick
doc_type: Test report
version: "0.2"
status: Draft
environment: lab
date: '2026-09-24'
author: Amish Chadha
license: CERN-OHL-S-2.0
revisions:
- version: "0.1"
  date: '2026-09-24'
  author: Amish Chadha
  change: Template. Structure follows TBK-TST-001; sections 5, 6 and 8 and the summary rows for TP3 to TP5 are filled from the analysis results by tbk_tst_002_fill.py
- version: "0.2"
  date: '2026-09-24'
  author: Amish Chadha
  change: 'Kit 1.1.4: front matter adds environment: lab'
---

# ThermaBrick test article test report

*Summary to be written once the tests are complete. State in two or three sentences whether the test article met TBK-TST-001, give the measured sand conductivity, contact conductance and insulation conductivity against the values assumed in TBK-CAL-001, and say what they mean for the full-scale charge-time requirement R3 (section 8).*

| Procedure | Dates | Pass criterion (TBK-TST-001) | Result | Pass |
| --- | --- | --- | --- | --- |
| TP0 Inspection and instrument checks | | Channels within ±2 K at 0 °C and 100 °C | | |
| TP1 Limit and fault response | | Trip at 600 °C ± 10 K; latches; firmware safe state within 10 s | | |
| TP2 Bake-out and commissioning | | 1 MΩ or more per heater at 500 V; no smoke in the last 12 h | | |
<!-- auto:summary -->
| TP3 Charge | | Fitted RMS 10 K or less; time to 80 % within 10 %; power correction within 5 % | *filled by script* | |
| TP4 Cool-down | | Loss at 450 °C within 20 % of 249 W before fitting | *filled by script* | |
| TP5 Discharge | | Hourly duty within 15 % of the model, no refit | *filled by script* | |
<!-- /auto:summary -->
| TP6 Cycling | | Circumference growth under 0.25 % after 25 cycles | | |

*Table 1. Results against TBK-TST-001. The TP3 to TP5 rows are filled by `tbk_tst_002_fill.py`; enter the dates by hand.*
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

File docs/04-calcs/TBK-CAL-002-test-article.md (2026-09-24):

---
doc_id: TBK-CAL-002
title: ThermaBrick test article sizing
project: ThermaBrick
doc_type: Calculation
version: "0.2"
status: Draft
date: '2026-09-24'
author: Amish Chadha
license: CERN-OHL-S-2.0
revisions:
- version: "0.1"
  date: '2026-09-24'
  author: Amish Chadha
  change: Initial draft. Sizing of the reduced-scale test article with the TBK-CAL-001 v0.2 models, including standby loss
- version: "0.2"
  date: '2026-09-24'
  author: Amish Chadha
  change: Test references updated to the procedure numbers in TBK-TST-001
---
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

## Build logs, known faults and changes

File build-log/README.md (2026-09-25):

# Build log

Dated entries, newest first. One entry per working session, whether building the test article (stages A to L of `docs/07-build/test-article-build.md`), running a test (TP0 to TP6 of TBK-TST-001), or sourcing parts.

## Writing an entry

Start each entry from the template with the helper, run from the repo root:

```bash
python build-log/new_entry.py "Drum preparation" --stage B
```

The helper names the file `YYYY-MM-DD-short-title.md` and fills in the date, author, stage and repo commit. It also adds the record table for that stage and lists the entry in the index below. Without `--stage`, it writes a blank record table. `TEMPLATE.md` holds the layout.

Conventions:

- **Record measurements when you take them,** with units, in the entry's record table. Test data goes to `docs/05-tests/data/` through the logger; the entry names the data file.
- **Log every deviation.** Each one names the document to change, whether drawing, cut list, BOM or procedure. The entry is not closed until those changes are committed.
- **Record actual prices** against the BOM estimate, so the next build's BOM can be corrected.
- **Save photos** to `media/build/` as `YYYY-MM-DD-stage-short-name.jpg`.
- **Leave raw notes unedited** after the session. Correct them with a dated note below the original.

## Entries

<!-- index start -->
- [2026-09-24: Kit 1.3.1](2026-09-24-kit-1-3-1.md)
- [2026-09-24: Kit 1.3.0](2026-09-24-kit-1-3-0.md)
- [2026-09-24: Kit 1.2.0 and TRL target capped at 3](2026-09-24-kit-1-2-0.md)
- [2026-09-24: TRL 3 recorded](2026-09-24-trl-3-recorded.md)
<!-- index end -->

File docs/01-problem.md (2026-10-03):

---
doc_id: TBK-PRB-001
title: ThermaBrick problem statement
project: ThermaBrick
doc_type: Problem statement
version: "0.11"
status: Draft
date: '2026-10-02'
author: Amish Chadha
license: CERN-OHL-S-2.0
revisions:
- version: "0.1"
  date: '2026-09-24'
  author: Amish Chadha
  change: Initial scaffold
- version: "0.2"
  date: '2026-09-24'
  author: Amish Chadha
  change: Developed the energy case, users and context, constraints, success measures and scope; flagged the budget gap found in the v0.2 costing
- version: "0.3"
  date: '2026-09-24'
  author: Amish Chadha
  change: Recorded the budget decision to build a reduced-scale test article within $600 first
- version: "0.4"
  date: '2026-09-24'
  author: Amish Chadha
  change: Noted that the test article estimate is now $635.70 after the enclosure fit check; the way back to $600 is open
- version: "0.5"
  date: '2026-09-24'
  author: Amish Chadha
  change: Recorded the decision to accept the test article at $635.70
- version: "0.6"
  date: '2026-09-24'
  author: Amish Chadha
  change: Test article budget raised to $727.70 for the parts the build procedure found
- version: "0.7"
  date: '2026-09-24'
  author: Amish Chadha
  change: 'Review pass: the $727.70 budget returned to proposed, awaiting Amish; only $635.70 was accepted by Amish'
- version: "0.8"
  date: '2026-09-25'
  author: Amish Chadha
  change: Recommendations accepted by Amish (DDR-002)
- version: "0.9"
  date: '2026-10-01'
  author: Amish Chadha
  change: 'Operating mass 415 kg and full-scale estimate $3,854 after the design was made constructable (TBK-DDR-003); budget worded as a value-engineering target'
- version: "0.10"
  date: '2026-10-02'
  author: Amish Chadha
  change: 'Standby loss open decision recorded as decided on 2026-10-02 (TBK-DEC-001)'
- version: "0.11"
  date: '2026-10-02'
  author: Amish Chadha
  change: 'Full-scale estimate $3,869 after the warning labels line (BOM line 47)'
---

# ThermaBrick problem statement

Homes with rooftop solar increasingly export their midday surplus for a few cents per kilowatt-hour, or lose it to curtailment. The same homes then buy gas or grid power at full price to heat the evening. ThermaBrick stores that surplus as heat in sand at up to 450 °C and releases it as warm air when the house needs it. It aims to shift about 18 kWh(th) a day from midday to the evening and night, using parts that a capable maker can buy and assemble in a garage.

## 1. The energy case

The mismatch is one of timing, not quantity. A 6 kWp rooftop array in a sunny, cold climate such as Denver produces roughly 20 to 25 kWh on a clear January day, most of it between 10:00 and 15:00. Household base load over those hours is typically 0.5 to 1.5 kW. That leaves roughly 8 to 14 kWh of midday surplus on a sunny winter day, and more in spring and autumn. Heating demand peaks between 17:00 and 08:00, after the surplus has gone.

Assumptions:

- Array yield of 3.5 to 4.2 kWh per kWp on a clear January day at 40° N.
- Heating demand of 20 to 60 kWh(th) per day for a small, reasonably insulated house or a large room.

Some tariffs and installations pay little or nothing for exports. Examples include the California net billing tariff that replaced net metering in 2023, export-capped installations and zero-export inverters. There, the surplus is worth far more as heat than as export. At an export value of $0.05/kWh, 18 kWh of surplus earns $0.90. The same 18 kWh(th) of heat displaces about 0.68 therm of gas at 90 % furnace efficiency, or 18 kWh of resistance heating bought at the retail rate.

A battery can also shift the surplus, but stationary lithium storage costs several hundred dollars per kilowatt-hour of capacity. Its cycles are better spent on loads that need electricity. Heat is the one large household load that can be stored cheaply in an inert, abundant material. Sand is nearly free, does not burn and does not degrade with cycling.

The honest limit of the case is scale. At this size standby losses are high (TBK-CAL-001, section 5), and the parts cost equals several years of savings. The prototype is a technology demonstrator and a design reference. It is not an economic product, and payback is not a design goal.

## 2. Users and context

The primary user is a homeowner or experienced maker who:

- has rooftop PV of 4 kWp or more and a way to read grid export in real time, such as an inverter API or an energy meter;
- has a slab-on-grade space inside the heated envelope, such as a basement, an attached garage workshop or a ground-floor utility room, with 1.5 m by 1.5 m of floor space;
- can have a dedicated 240 V, 20 A circuit installed; and
- is comfortable with pipe threading, sheet metal and low-voltage electronics, and will hire an electrician for the branch circuit where local code requires it.

The secondary audience is other designers, students and community energy groups, who will use the documentation to adapt the design. For them the calculation note and the parametric model matter as much as the hardware.

The operating context sets the design. The unit charges from about 10:00 to 16:00 whenever export is detected, holds heat through the late afternoon, and releases it through a room register from evening to morning. In the heating season its standby loss warms the same room. That heat is not wasted, but it cannot be switched off. Outside the heating season the unit is idle.

## 3. Constraints

- **Garage-buildable.** No welding, no pressure vessel and no custom machining. Cutting and threading pipe, riveting sheet metal and basic electrical assembly are acceptable.
- **Safe at the temperatures involved.** Independent hardware over-temperature protection, no coated or galvanized steel in hot zones, cool touchable surfaces and insulation fibers that are safe to handle.
- **Standard supply.** 240 V split phase on one 20 A circuit, the normal North American arrangement for a fixed heater.
- **Indoor siting on a concrete slab.** The unit weighs about 415 kg in service.
- **Prototype budget of about $600 USD.** The v0.2 costing (`bom/bom.csv`) estimated $3,674 for the full-scale design; the constructable design (TBK-DDR-003) is estimated at $3,869, USD 3,141 over the USD 728 value-engineering target. The target is a hypothetical control figure for value engineering, not a spending limit. The budget now funds a reduced-scale test article, with a budget of $727.70 decided by Amish on 2026-09-25 (TBK-DDR-002). The test article is archived and on hold with TRL 4 (section 5).

## 4. What success looks like

The v0.2 draft sets the following measures, which TBK-REQ-001 turns into verifiable requirements. ThermaBrick:

- stores at least 18 kWh(th) between 150 °C and 450 °C sand mean temperature;
- absorbs at least 11 kWh in 4 h of full surplus and fills in 8 h or less;
- delivers a steady 1.0 kW of warm air through most of the stored range, with supply air at 55 °C or below;
- never lets any sand pass 550 °C, and keeps every accessible surface at 45 °C or below;
- follows live PV export, so it draws surplus power and never imports from the grid to charge; and
- can be reproduced entirely from the published model, drawings, BOM and firmware.

## 5. Open decisions

1. **Budget.** Decided by Amish on 2026-09-24. The $600 budget funds a reduced-scale test article first: a 16 US gal drum storing about 6 kWh(th), built with the same heater cells as the full-scale design (TBK-PRC-002). Its measurements will settle sand conductivity, contact conductance and standby loss. The full-scale budget will be revisited with those results. After the controller enclosure was modeled, the test article estimate rose to $635.70. Decided 2026-09-24: accept $635.70 as the test article budget, with every part specified, rather than defer parts or rely on parts on hand. The build procedure then found $92.00 of parts the BOM had missed (insulation, cable, wiring consumables and thermocouple extension); Amish had them added to the BOM, which now totals $727.70. Decided by Amish, 2026-09-25: go with recommendation. The test article budget is raised from $635.70 to $727.70 (TBK-DDR-002). The test article is archived under `archive/out-of-phase-trl4/` and is on hold with TRL 4, so nothing will be bought until TRL 4 resumes. Revisiting the full-scale budget with the test article's results is also decided, and on hold for the same reason.
2. **Standby loss.** Decided by Amish on 2026-10-02 (TBK-DEC-001): 459 W of uncontrolled output at full charge is accepted for now; the loss-reduction options in TBK-CAL-001, Table 5 are decided together with the R3 charge-time fix once the test article has measured loss.

## 6. Out of scope

- Domestic hot water. A later revision could add a water coil to the collector.
- Charging from cheap night-rate grid power. The controller could do it, but it is not a design driver.
- Certification to UL 2021 or a similar appliance standard. The prototype is a documented experimental build, not a listed product.
- Multi-unit or district scale.

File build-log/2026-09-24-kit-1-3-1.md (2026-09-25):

# 2026-09-24: Kit 1.3.1

| Field | Entry |
| --- | --- |
| Date | 2026-09-24 |
| Author | Amish Chadha |
| Stage or procedure | Project record: portfolio kit 1.3.1 |
| Hours | |
| Room temperature | Not applicable |
| Repo commit | `bb3fb78` (before this change) |

## Goal

Sync the portfolio kit from 1.3.0 to 1.3.1, at Amish's request.

## Work done

1. Synced `.kit/`, the root `CLAUDE.md` and `.claude/commands/` from `wastewise-scan` at commit `b033da6`, the commit that released 1.3.1. The kit adds context parts for small objects, cutaway exclusions and text labels in flow diagrams, and changes the flow diagram layout.
2. Regenerated the concept media with `cad/src/concept_media.py`. Only `media/flow.png` changed, from the new layout; its values are unchanged. The concept sheet TBK-DWG-006 is unchanged and stays at Rev P2. ThermaBrick keeps the 1.75 m person for scale, since the unit is floor-standing.

## Records

| Quantity | Expected | Measured | OK |
| --- | --- | --- | --- |
| Kit version | 1.3.1, identical to `wastewise-scan@b033da6` | `diff -r` shows no differences in `.kit/`, `CLAUDE.md` or `.claude/commands/` | Yes |
| Kit check | Passes | `render.py --check` exit code 0 | Yes |

## Deviations

| What differs | Why | Document to update | Done |
| --- | --- | --- | --- |
| None | | | |

## Problems and fixes

None.

## Parts and cost

| BOM item | Qty | BOM estimate (USD) | Paid (USD) | Supplier |
| --- | --- | --- | --- | --- |
| None | | | | |

## Photos

None.

## Safety

None.

## Next steps

- [ ] None from this change. TRL stays at 3, the portfolio cap.

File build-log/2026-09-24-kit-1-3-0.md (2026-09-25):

# 2026-09-24: Kit 1.3.0

| Field | Entry |
| --- | --- |
| Date | 2026-09-24 |
| Author | Amish Chadha |
| Stage or procedure | Project record: portfolio kit 1.3.0 (`.kit/STANDARDS.md`, section 11) |
| Hours | |
| Room temperature | Not applicable |
| Repo commit | `c534b49` (before this change) |

## Goal

Sync the portfolio kit from 1.2.0 to 1.3.0, at Amish's request, so ThermaBrick matches the other 37 repos.

## Work done

1. Synced `.kit/` to 1.3.0 from `wastewise-scan` at commit `571685f`, the commit that adopted 1.3.0. The root `CLAUDE.md` and the session commands in `.claude/commands/` (`/populate`, `/advance-trl3`, `/rein-in`, `/refresh-media`) come from the same commit.
2. Regenerated the concept media with `cad/src/concept_media.py`. Kit 1.3.0 adds a 1.75 m person for scale to the hero render and the concept sheet, and requires `media/model.glb`; `media/viewer.html` is written with it.
3. Added the heat flow diagram `media/flow.png`, which kit 1.3.0 asks for when a concept moves energy. Its values are the TBK-CAL-001 v0.2 discharge figures (18.3 kWh stored, 14.5 kWh output, 3.8 kWh standby loss), marked as estimates.
4. Reissued the concept sheet TBK-DWG-006 at Rev P2, because its isometric view now carries the scale figure.

## Records

| Quantity | Expected | Measured | OK |
| --- | --- | --- | --- |
| Kit version | 1.3.0, identical to `wastewise-scan@571685f` | `diff -r` shows no differences in `.kit/`, `CLAUDE.md` or `.claude/commands/` | Yes |
| Required concept media | `concept-blueprint.png`, `hero.png`, `model.glb` | Present | Yes |
| `trl`, `trl_target` against the cap | 3 or less | 3, 3 | Yes |
| Kit check | Passes | `render.py --check` exit code 0 | Yes |

## Deviations

| What differs | Why | Document to update | Done |
| --- | --- | --- | --- |
| None | | | |

## Problems and fixes

The concept sheet's revision table shows only P2, because `.kit/concept.py` writes a single revision row. P1 is recorded in `build-log/2026-09-24-kit-1-2-0.md` and in git. In the isometric view on the sheet, the scale figure overlaps the edge of the unit's jacket; the kit places the figure, and the hero render is clear.

## Parts and cost

| BOM item | Qty | BOM estimate (USD) | Paid (USD) | Supplier |
| --- | --- | --- | --- | --- |
| None | | | | |

## Photos

None. The concept renders are in `media/`.

## Safety

None.

## Next steps

- [ ] None from this change. TRL stays at 3, the portfolio cap.

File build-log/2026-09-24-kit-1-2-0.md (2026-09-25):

# 2026-09-24: Kit 1.2.0 and TRL target capped at 3

| Field | Entry |
| --- | --- |
| Date | 2026-09-24 |
| Author | Amish Chadha |
| Stage or procedure | Project record: portfolio kit 1.2.0 (`.kit/STANDARDS.md`, sections 10 and 11) |
| Hours | |
| Room temperature | Not applicable |
| Repo commit | `ef2caad` (before this change) |

## Goal

Sync the portfolio kit from 1.1.4 to 1.2.0 and meet its check, at Amish's request (option A: cap the TRL target at 3 and generate the required concept media).

## Work done

1. Synced `.kit/` to 1.2.0, taken from `wastewise-scan` at commit `8ee209e`, the commit that adopted 1.2.0. The kit adds `PHASE.yaml` (portfolio cap at TRL 3), `concept.py`, `.kit/CLAUDE.md`, and the phase and media checks in `render.py`. The root `CLAUDE.md` was copied from the same commit.
2. Installed the new kit requirements, NumPy and Matplotlib, into the kit environment.
3. Changed `trl_target` from 4 to 3 in `project.yaml`. `trl` stays at 3. The TRL does not change, so this entry records a change of target only.
4. Added `cad/src/concept_media.py`, which builds the full-scale assembly from `cad/src/model.py` and writes the concept media through `.kit/concept.py`: `media/hero.png`, `media/cutaway.png`, `media/exploded.png`, and the concept sheet `media/concept-blueprint.png`, `.pdf` and `.svg` (TBK-DWG-006 Rev P1). Callout numbers in the exploded view are `bom/bom.csv` line numbers. Key figures on the sheet come from TBK-CAL-001 v0.2.

## Records

| Quantity | Expected | Measured | OK |
| --- | --- | --- | --- |
| Kit version | 1.2.0, identical to `wastewise-scan@8ee209e` | `diff -r` shows no differences | Yes |
| `trl`, `trl_target` against the cap | 3 or less | 3, 3 | Yes |
| Required concept media | `media/concept-blueprint.png`, `media/hero.png` | Present, both marked "CONCEPT, NOT FOR FABRICATION" | Yes |
| Kit check | Passes | `render.py --check` exit code 0 | Yes |

## Deviations

| What differs | Why | Document to update | Done |
| --- | --- | --- | --- |
| None | | | |

## Problems and fixes

Before this change, the 1.2.0 check failed on two points: `trl_target: 4` exceeded the cap, and the concept media were missing. Amish chose option A.

The check still warns that work beyond the TRL 3 cap is present: TBK-TST-001, TBK-TST-002, `docs/07-build/`, `bom/purchasing-checklist.md` and `build-log/TEMPLATE.md`. Under section 10 this work is kept but not extended.

## Parts and cost

| BOM item | Qty | BOM estimate (USD) | Paid (USD) | Supplier |
| --- | --- | --- | --- | --- |
| None | | | | |

## Photos

None. The concept renders are in `media/`.

## Safety

None.

## Next steps

- [x] Kit 1.2.0 asks for the review note at `docs/REVIEW.md`. This repo's review is `docs/REVIEW-2026-09.md`, the name Amish gave it. Whether to rename it is proposed, awaiting Amish.
- [ ] While the portfolio is capped at TRL 3, the test article work stays as it is. Raising the target back to 4 is for Amish, through `PHASE.yaml`.

*Note added 2026-09-24: Amish chose to rename the review; it is now `docs/REVIEW.md`.*

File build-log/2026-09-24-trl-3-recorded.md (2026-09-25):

# 2026-09-24: TRL 3 recorded

| Field | Entry |
| --- | --- |
| Date | 2026-09-24 |
| Author | Amish Chadha |
| Stage or procedure | Project record: Technology Readiness Level (`.kit/STANDARDS.md`, section 9) |
| Hours | |
| Room temperature | Not applicable |
| Repo commit | `a07b0c2` |

## Goal

Record ThermaBrick at TRL 3 (analytical proof of concept), at Amish's request, with the evidence that section 9 requires.

## Work done

1. Synced the portfolio kit from 1.0.0 to 1.1.4, which adds section 9 and makes `python .kit/render.py --check` verify the claimed TRL. The 1.1.4 copy was taken from `wastewise-scan` at commit `d5cba39`, the commit that adopted 1.1.4.
2. Fixed the invalid U-tube solid in the full-scale model (commit `a07b0c2`), which had been the one gap in the TRL 3 evidence.
3. Added `trl: 3`, `trl_target: 4` and `trl_evidence` to `project.yaml`.
4. Added `environment: lab` to the TST front matter, as kit 1.1.4 requires.

## Records

| Quantity | Expected | Measured | OK |
| --- | --- | --- | --- |
| TRL 1: problem statement (PRB) | Present | TBK-PRB-001 v0.7 | Yes |
| TRL 2: precis (PRC) and requirements (REQ) | Draft present | TBK-PRC-001 v0.4, TBK-REQ-001 v0.8 | Yes |
| TRL 3: calculation note (CAL) | Present | TBK-CAL-001 v0.2 (and TBK-CAL-002 for the test article) | Yes |
| TRL 3: working build123d model | Builds, all solids valid | `cad/src/model.py`: assembly valid after `a07b0c2` | Yes |
| TRL 3: STEP export | Present and readable | `cad/step/thermabrick.step`: reads back as 47 valid solids | Yes |
| TRL 3: drawing sheet (DWG) | Present | TBK-DWG-001 Rev P1 (and TBK-DWG-002 to TBK-DWG-005) | Yes |
| TRL 3: priced BOM | Every unit cost filled in | `bom/bom.csv`: 42 lines, all priced, $3,673.50 | Yes |
| Kit check | Passes at TRL 3 | `render.py --check` passes with kit 1.1.4 | Yes |

## Deviations

| What differs | Why | Document to update | Done |
| --- | --- | --- | --- |
| None | | | |

## Problems and fixes

The TRL 3 evidence was first found incomplete in the September 2026 review (`docs/REVIEW-2026-09.md`, section 3, item 5). The full-scale model carried one invalid U-tube solid, fixed in `a07b0c2`.

TRL 3 is a documentation claim. It does not mean the design meets its requirements: the full-scale unit still misses R3 (a 9.6 h charge against 8 h), and its standby loss is 47 % of the stored heat per day. Both are open in the review.

## Parts and cost

| BOM item | Qty | BOM estimate (USD) | Paid (USD) | Supplier |
| --- | --- | --- | --- | --- |
| None | | | | |

## Photos

None.

## Safety

None.

## Next steps

- [ ] TRL 4 needs hardware: build the test article, run TBK-TST-001, and complete TBK-TST-002 with `environment: lab`, supported by build log entries.
- [ ] Kit 1.1.4's TRL 4 check is too weak. With `trl: 4` set temporarily, `render.py --check` passed for this repo with no hardware built. It counts any TST document (the test plan qualifies) and any two `.md` files in `build-log/` (`README.md` and `TEMPLATE.md` qualify). The fix belongs in the kit source, not this repo; `trl` was restored to 3.
- [ ] Kit 1.2.0 exists in `wastewise-scan` (commit `8ee209e`, "TRL 3 cap, CLAUDE.md guardrails, concept media standard"); syncing to it is for Amish to decide.

*Note added 2026-09-24: the review cited above was renamed `docs/REVIEW.md` at Amish's request.*

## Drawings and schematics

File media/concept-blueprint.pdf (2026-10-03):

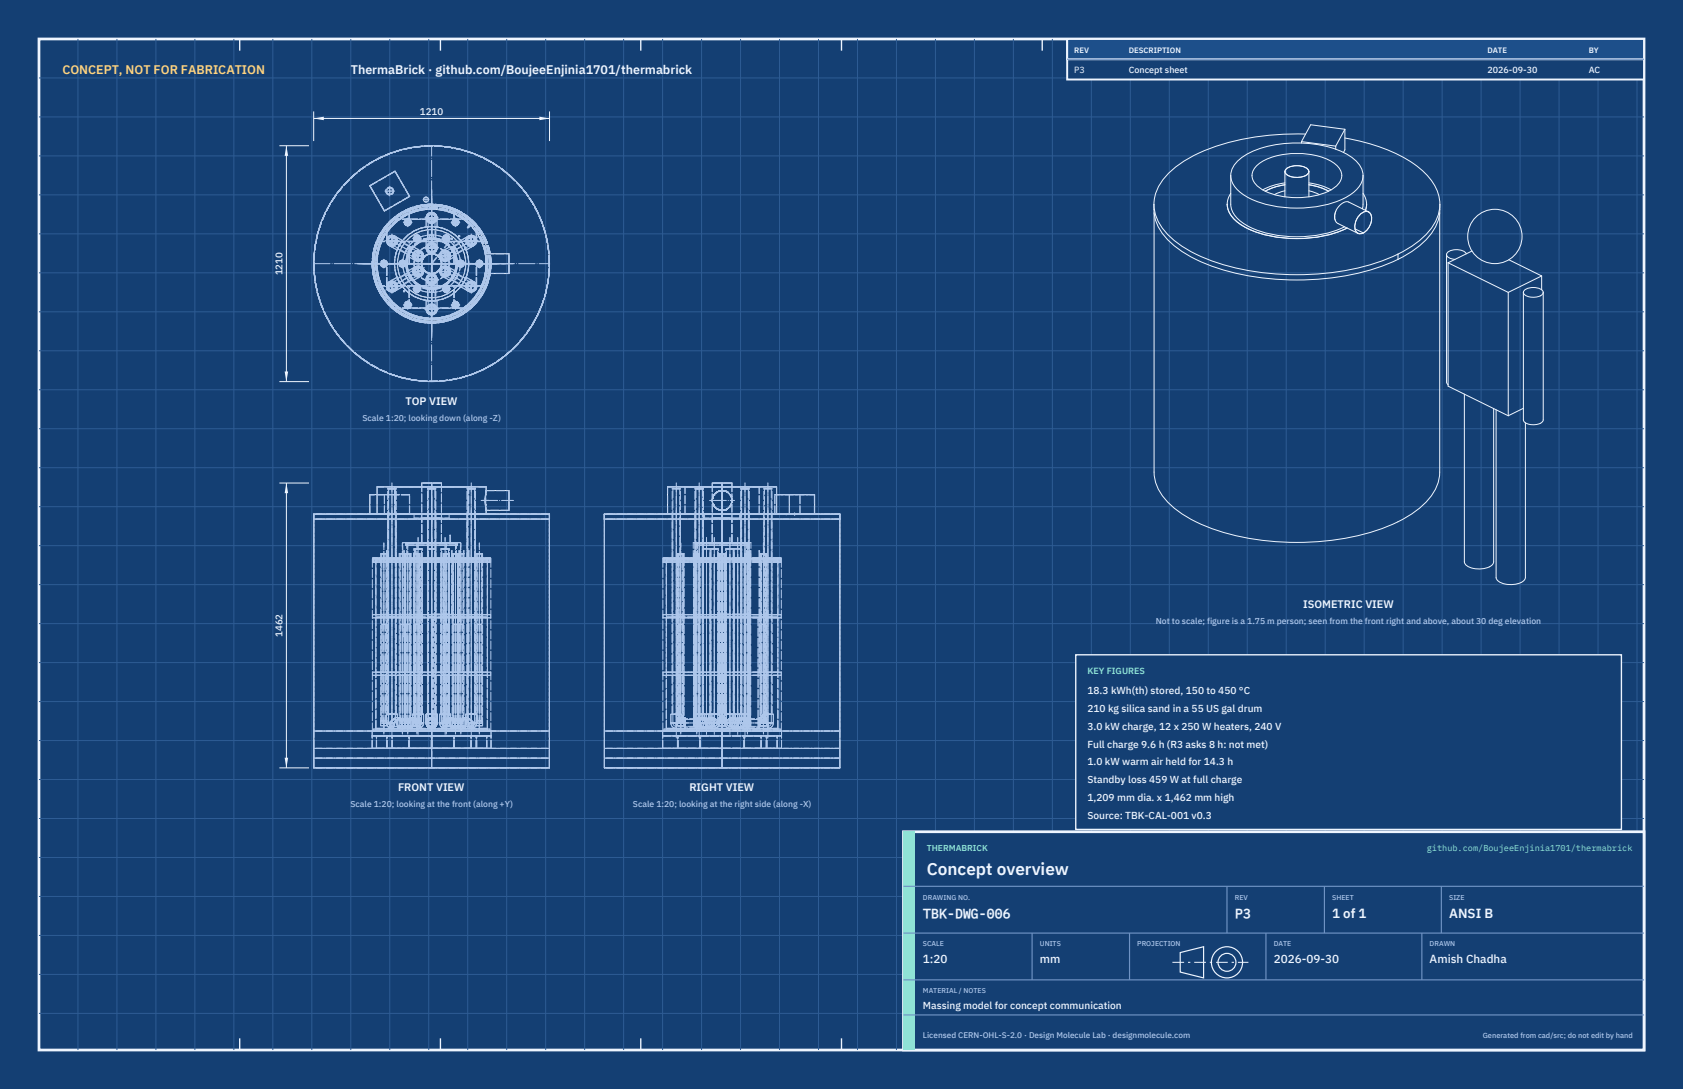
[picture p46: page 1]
CONCEPT, NOT FOR FABRICATION; ThermaBrick · github.com/BoujeeEnjinia1701/thermabrick; FRONT VIEW; TOP VIEW; RIGHT VIEW; ISOMETRIC VIEW; REV; DESCRIPTION; DATE; Concept sheet; THERMABRICK; github.com/BoujeeEnjinia1701/thermabrick; Concept overview; DRAWING NO. TBK-DWG-006; REV P3; SHEET 1 of 1; SIZE ANSI B; SCALE 1:20; UNITS mm; PROJECTION; DRAWN Amish Chadha; Licensed CERN-OHL-S-2.0 · Design Molecule Lab · designmolecule.com; Generated from cad/src; do not edit by hand

Scale 1:20; looking down (along -Z)

Not to scale; figure is a 1.75 m person; seen from the front right and above, about 30 deg elevation

KEY FIGURES
18.3 kWh(th) stored, 150 to 450 °C
210 kg silica sand in a 55 US gal drum
3.0 kW charge, 12 x 250 W heaters, 240 V
Full charge 9.6 h (R3 asks 8 h: not met)
1.0 kW warm air held for 14.3 h
Standby loss 459 W at full charge
1,209 mm dia. x 1,462 mm high
Source: TBK-CAL-001 v0.3

Scale 1:20; looking at the front (along +Y)

Scale 1:20; looking at the right side (along -X)

MATERIAL / NOTES
Massing model for concept communication

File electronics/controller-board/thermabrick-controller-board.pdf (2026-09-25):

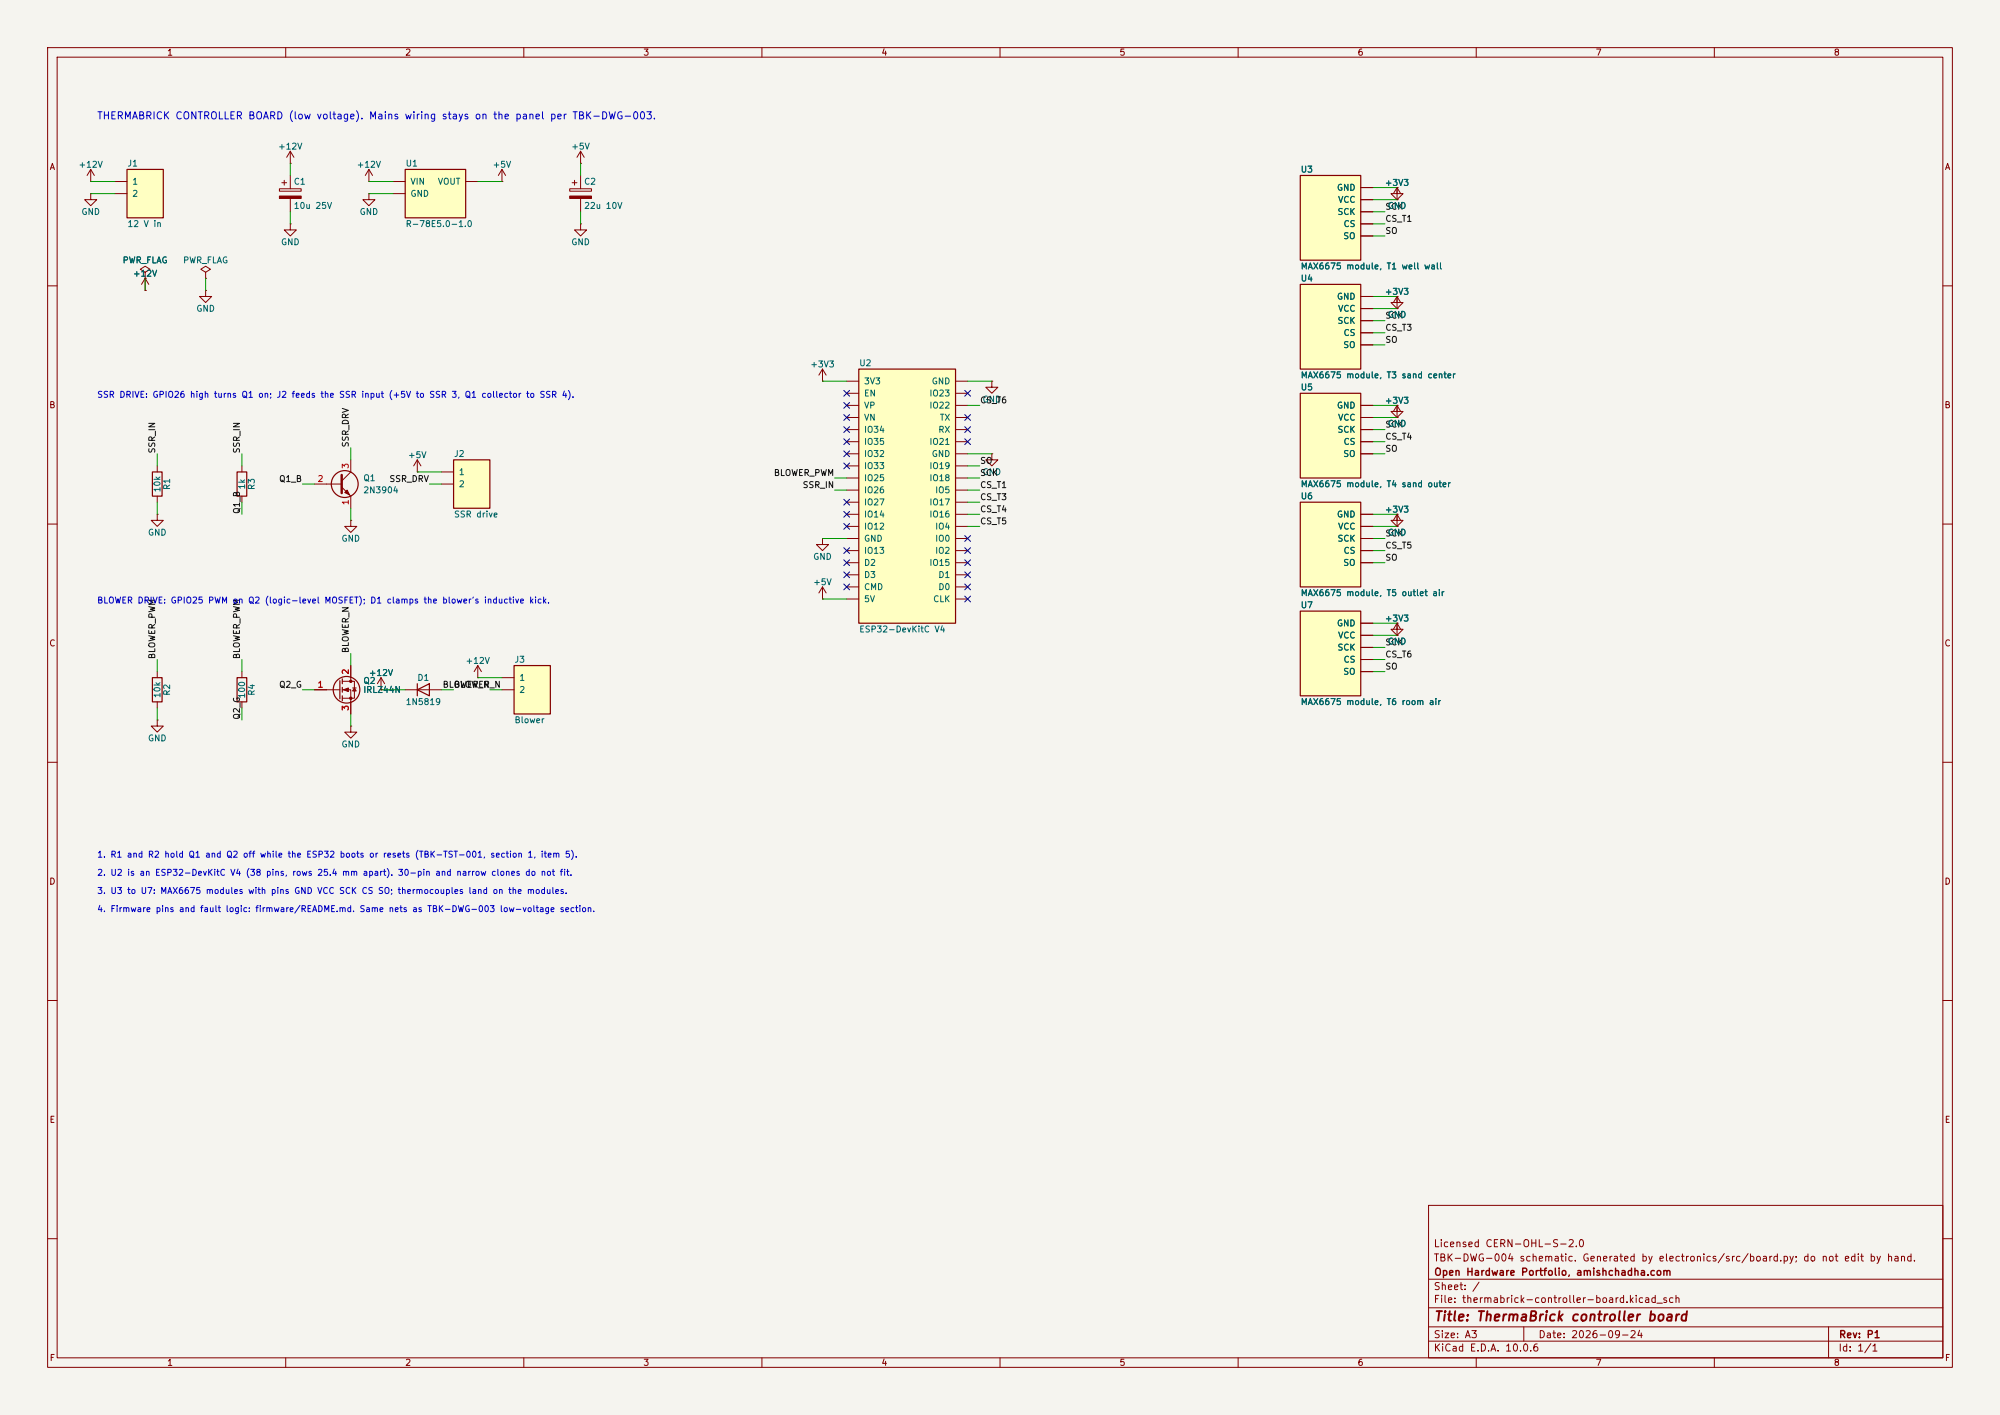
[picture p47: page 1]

THERMABRICK CONTROLLER BOARD (low voltage). Mains wiring stays on the panel per TBK-DWG-003.

GND U3MAX6675 module, T1 well wall GND
U5MAX6675 module, T4 sand outer +3V3 +3V3 GND

3. U3 to U7: MAX6675 modules with pins GND VCC SCK CS SO; thermocouples land on the modules.

Licensed CERN-OHL-S-2.0
TBK-DWG-004 schematic. Generated by electronics/src/board.py; do not edit by hand.
Open Hardware Portfolio, amishchadha.com
Sheet: /
File: thermabrick-controller-board.kicad_sch
Title: ThermaBrick controller board

Size: A3 | Rev: P1 | F Date: 2026-09-24
KiCad E.D.A. 10.0.6 | Id: 1/1

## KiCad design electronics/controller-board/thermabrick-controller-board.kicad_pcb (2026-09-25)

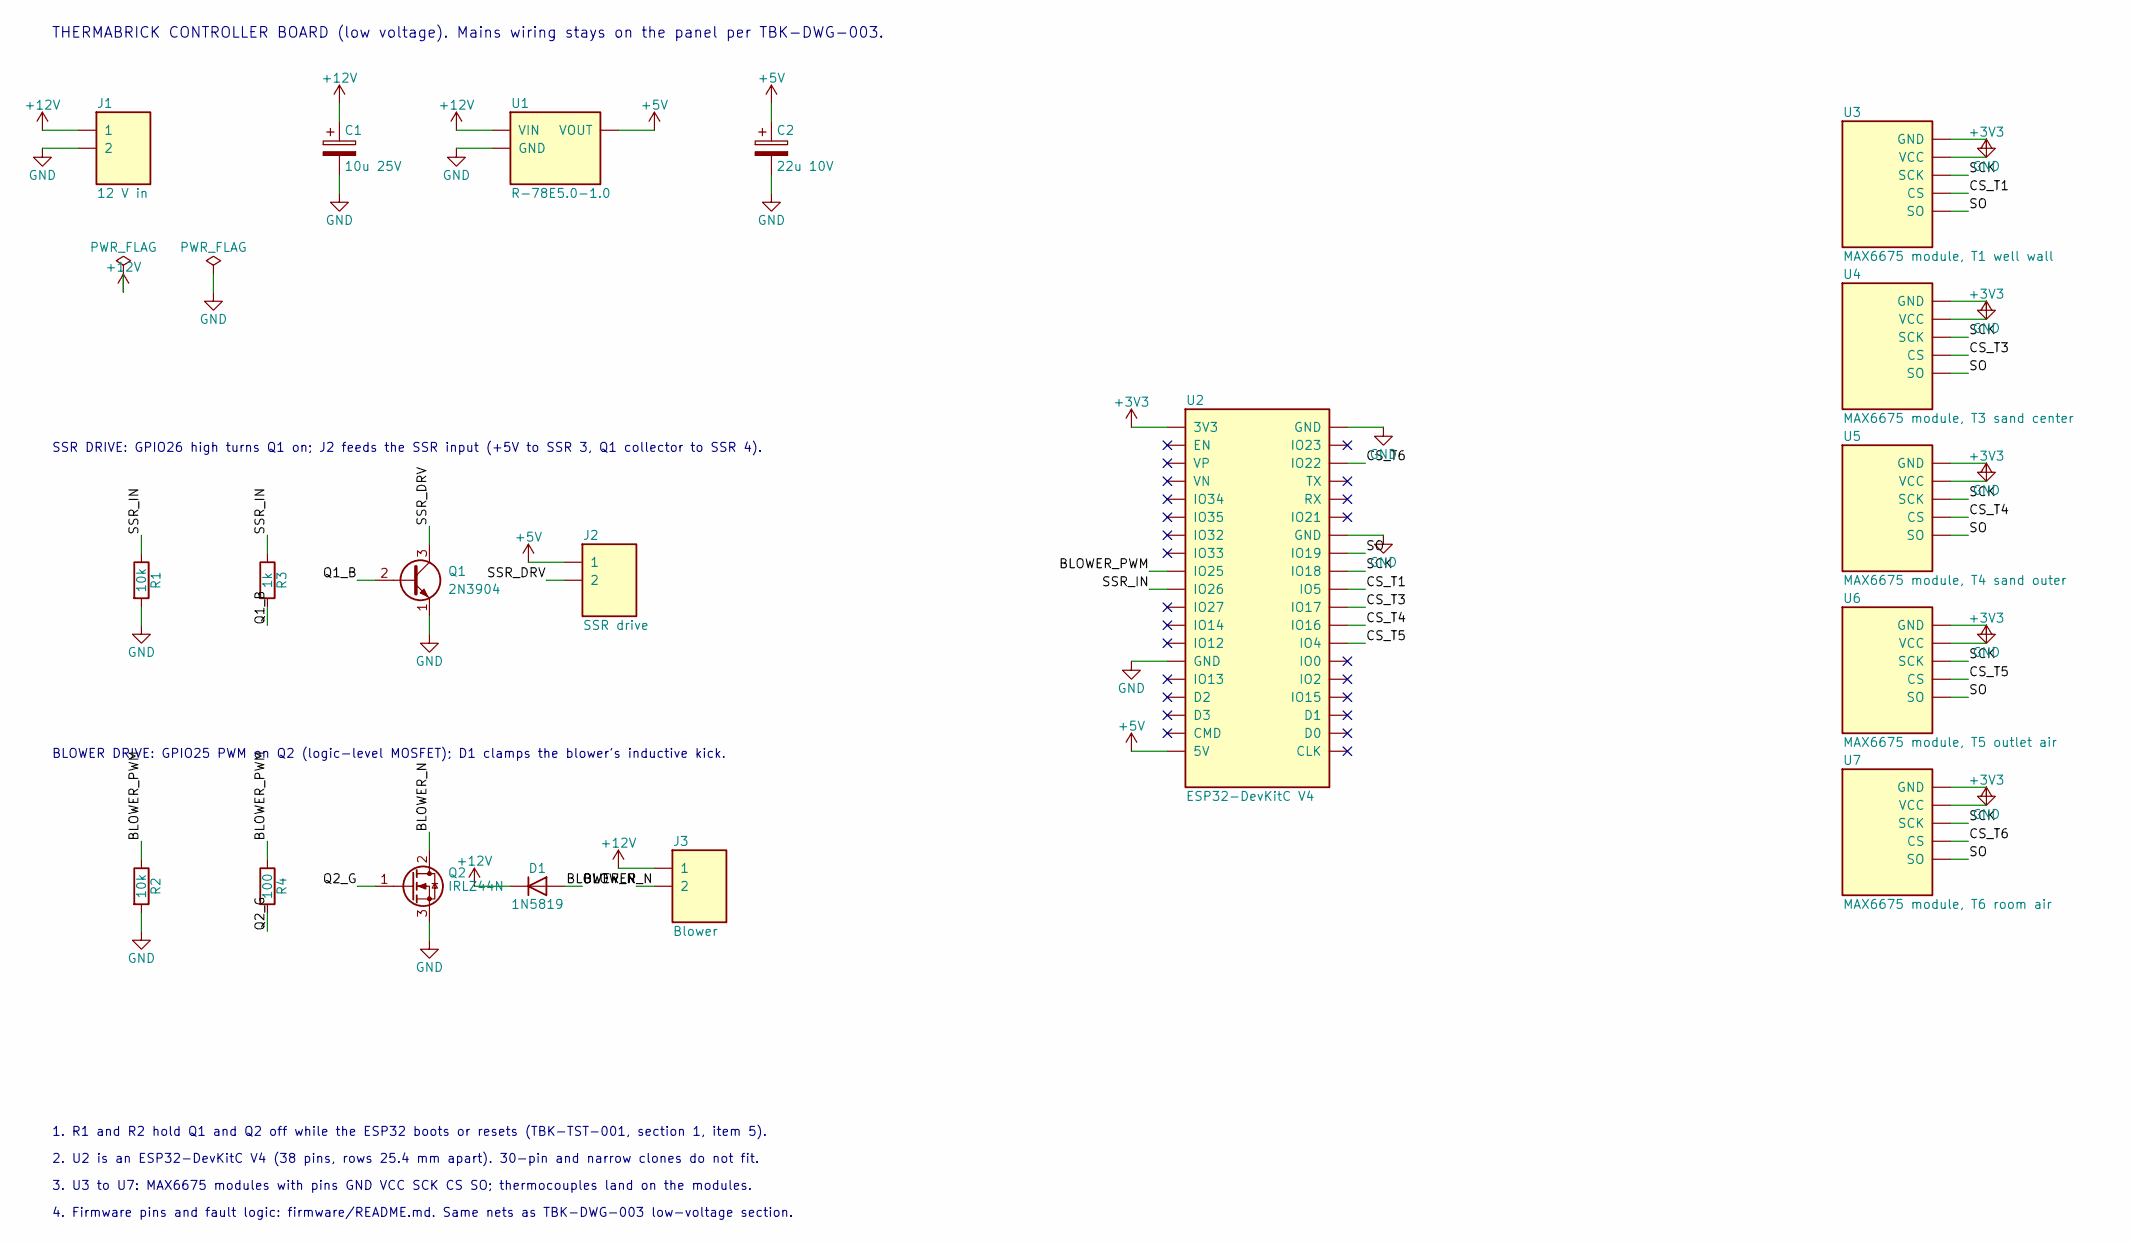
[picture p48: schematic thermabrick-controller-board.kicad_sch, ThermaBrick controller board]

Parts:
C1: 10u 25V; CP_Radial_D5.0mm_P2.00mm
C2: 22u 10V; CP_Radial_D5.0mm_P2.00mm
D1: 1N5819; D_DO-41_SOD81_P10.16mm_Horizontal
J1: 12 V in; TerminalBlock_Phoenix_MKDS-1,5-2-5.08_1x02_P5.08mm_Horizont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
J2: SSR drive; TerminalBlock_Phoenix_MKDS-1,5-2-5.08_1x02_P5.08mm_Horizont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
J3: Blower; TerminalBlock_Phoenix_MKDS-1,5-2-5.08_1x02_P5.08mm_Horizont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
Q1: 2N3904; TO-92_Inline_Wide
Q2: IRLZ44N; TO-220-3_Vertical
R1, R2: 10k; R_Axial_DIN0207_L6.3mm_D2.5mm_P10.16mm_Horizontal
R3: 1k; R_Axial_DIN0207_L6.3mm_D2.5mm_P10.16mm_Horizontal
R4: 100; R_Axial_DIN0207_L6.3mm_D2.5mm_P10.16mm_Horizontal
U1: R-78E5.0-1.0; Converter_DCDC_RECOM_R-78E-0.5_THT
U2: ESP32-DevKitC V4; ESP32_DevKitC_V4_Socket
U3: MAX6675 module, T1 well wall; MAX6675_Module_Socket
U4: MAX6675 module, T3 sand center; MAX6675_Module_Socket
U5: MAX6675 module, T4 sand outer; MAX6675_Module_Socket
U6: MAX6675 module, T5 outlet air; MAX6675_Module_Socket
U7: MAX6675 module, T6 room air; MAX6675_Module_Socket

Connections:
+3V3: U2.1 (3V3), U3.2 (VCC), U4.2 (VCC), U5.2 (VCC), U6.2 (VCC), U7.2 (VCC)
+5V: C2.1, J2.1, U1.3 (VOUT), U2.19 (5V)
+12V: C1.1, D1.1 (K), J1.1, J3.1, U1.1 (VIN)
/BLOWER_N: D1.2 (A), J3.2, Q2.2 (D)
/BLOWER_PWM: R2.1, R4.1, U2.9 (IO25)
/CS_T1: U2.29 (IO5), U3.4 (CS)
/CS_T3: U2.30 (IO17), U4.4 (CS)
/CS_T4: U2.31 (IO16), U5.4 (CS)
/CS_T5: U2.32 (IO4), U6.4 (CS)
/CS_T6: U2.22 (IO22), U7.4 (CS)
/Q1_B: Q1.2 (B), R3.2
/Q2_G: Q2.1 (G), R4.2
/SCK: U2.28 (IO18), U3.3 (SCK), U4.3 (SCK), U5.3 (SCK), U6.3 (SCK), U7.3 (SCK)
/SO: U2.27 (IO19), U3.5 (SO), U4.5 (SO), U5.5 (SO), U6.5 (SO), U7.5 (SO)
/SSR_DRV: J2.2, Q1.3 (C)
/SSR_IN: R1.1, R3.1, U2.10 (IO26)
GND: C1.2, C2.2, J1.2, Q1.1 (E), Q2.3 (S), R1.2, R2.2, U1.2 (GND), U2.14 (GND), U2.20 (GND), U2.26 (GND), U3.1 (GND), U4.1 (GND), U5.1 (GND), U6.1 (GND), U7.1 (GND)

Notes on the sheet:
THERMABRICK CONTROLLER BOARD (low voltage). Mains wiring stays on the panel per TBK-DWG-003.
SSR DRIVE: GPIO26 high turns Q1 on; J2 feeds the SSR input (+5V to SSR 3, Q1 collector to SSR 4).
BLOWER DRIVE: GPIO25 PWM on Q2 (logic-level MOSFET); D1 clamps the blower's inductive kick.
1. R1 and R2 hold Q1 and Q2 off while the ESP32 boots or resets (TBK-TST-001, section 1, item 5).
2. U2 is an ESP32-DevKitC V4 (38 pins, rows 25.4 mm apart). 30-pin and narrow clones do not fit.
3. U3 to U7: MAX6675 modules with pins GND VCC SCK CS SO; thermocouples land on the modules.
4. Firmware pins and fault logic: firmware/README.md. Same nets as TBK-DWG-003 low-voltage section.

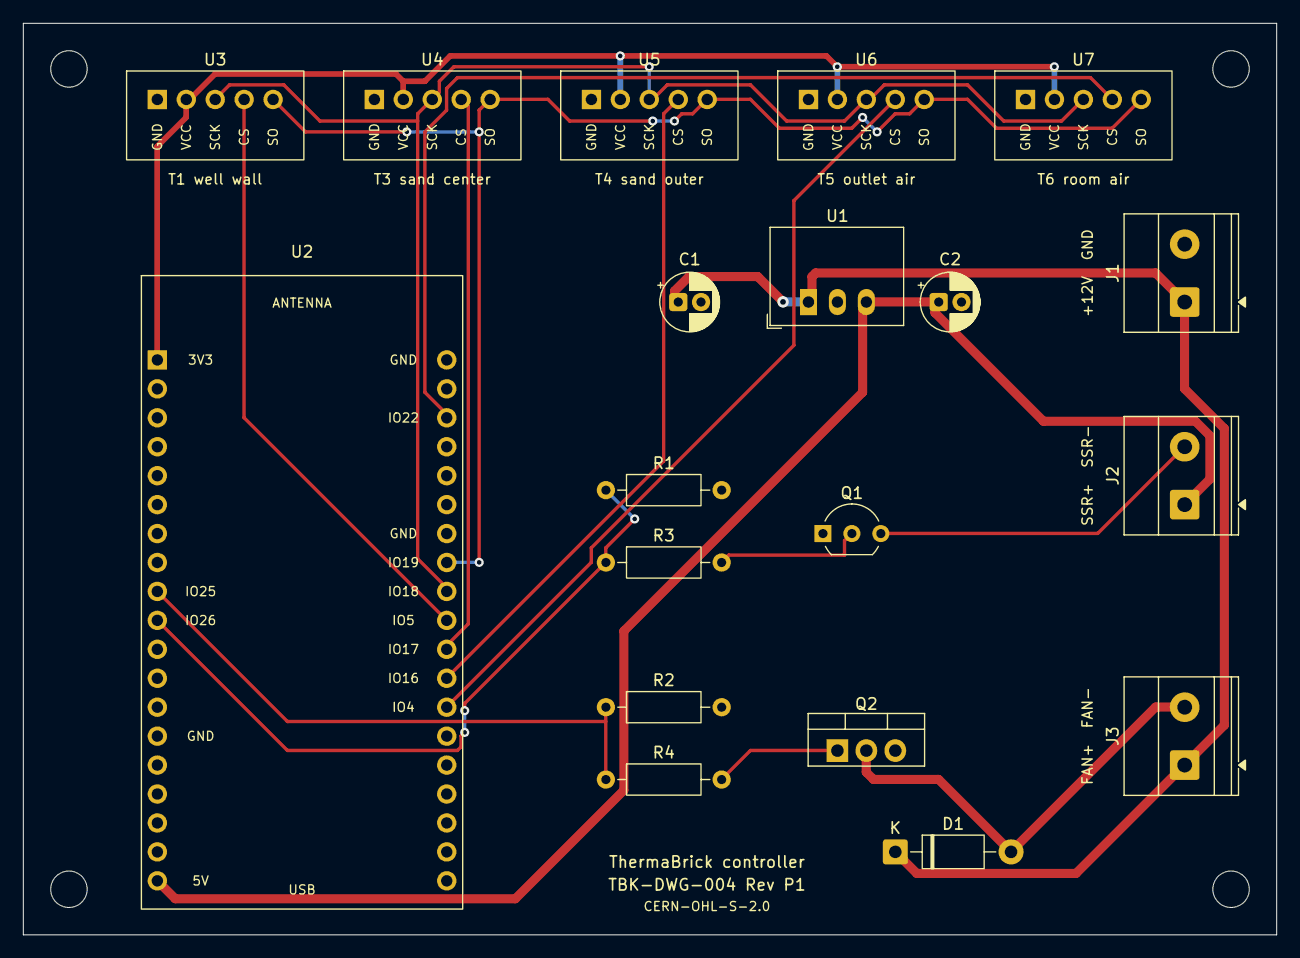
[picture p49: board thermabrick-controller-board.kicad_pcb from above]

Board: 2 copper layers, 110.0 x 80.0 mm, 23 parts (0 on the bottom side), 17 nets.

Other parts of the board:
H1, H2, H3, H4: MountingHole_3.2mm_M3

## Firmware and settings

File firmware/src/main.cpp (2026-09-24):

// ThermaBrick test article controller (ESP32, Arduino framework).
//
// Implements the five functions required by TBK-TST-001, section 1:
//   1. Charge mode: full power until T1 reaches the setpoint (550 C default), then PI on T1.
//   2. Hold mode:   PI on T1 at a lower setpoint (bake-out).
//   3. Blower:      fixed PWM duty, or closed-loop exchanger duty (W) from the airflow table.
//   4. Logging:     every channel, heater and blower duty at 10 s to a ring buffer, served
//                   as CSV over HTTP to the logging host (tools/logger.py).
//   5. Safe state:  heaters off after a reset (SSR pin pulled down), on T1 open, T1 > 575 C,
//                   sand > 560 C, loss of the logging host for 60 s, or a stalled main loop.
//
// The independent 600 C limit (REX-C100 and latching relay) is hardware and does not depend
// on this firmware.
//
// Licensed MIT (see LICENSE-SOFTWARE).
#include <Arduino.h>
#include <Preferences.h>
#include <WebServer.h>
#include <WiFi.h>
#include <esp_task_wdt.h>
#include <esp_timer.h>

#include "control.h"
#include "secrets.h"  // WIFI_SSID, WIFI_PASS, API_TOKEN (see include/secrets.example.h)

#ifndef TB_FW_REV
#define TB_FW_REV "unknown"
#endif

// ---------------------------------------------------------------- pins (TBK-PRC-002)
static const int PIN_SCK = 18;
static const int PIN_SO = 19;
static const int PIN_CS[5] = {5, 17, 16, 4, 22};   // T1, T3, T4, T5, T6
static const char* TC_NAME[5] = {"T1", "T3", "T4", "T5", "T6"};
enum { CH_T1 = 0, CH_T3, CH_T4, CH_T5, CH_T6 };
static const int PIN_SSR = 26;      // 10 kOhm pull-down to GND on the board
static const int PIN_BLOWER = 25;   // MOSFET module input, 10 kOhm pull-down
static const int BLOWER_LEDC_CH = 0;

// ---------------------------------------------------------------- timing
static const uint32_t TICK_MS = 1000;       // control and safety loop
static const uint32_t LOG_MS = 10000;       // log interval
static const int BURST_TICKS = 100;         // 1 s window of 10 ms ticks
static const uint32_t LOOP_STALL_MS = 6000; // output timer forces heaters off after this
static const int WDT_TIMEOUT_S = 8;

// ---------------------------------------------------------------- configuration (NVS)
struct Config {
    float v_line = 120.0f;       // measured line voltage, V
    float r_heat = 14.4f;        // four heaters in parallel, hot, Ohm
    float kp = 0.05f;            // heater PI, duty per K (full to zero over 20 K); tune in TP3
    float ti = 300.0f;           // heater PI, s
    float kpb = 0.002f;          // blower PI, duty per W
    float tib = 120.0f;          // blower PI, s
    float blower_min = 0.15f;    // lowest duty in power mode
    float off_t1 = 0.0f;         // T1 calibration offset, used for control and safety only
    uint32_t pwm_hz = 100;       // blower PWM frequency
    int air_n = 4;               // airflow table from TBK-TST-001 TP0 (duty 0..1 -> L/s)
    float air_duty[8] = {0.25f, 0.50f, 0.75f, 1.00f};
    float air_ls[8] = {1.0f, 2.0f, 3.0f, 4.0f};
} cfg;

Preferences prefs;

// ---------------------------------------------------------------- state
struct Channel {
    bool ok = false;
    bool open = false;
    float c = NAN;
};
Channel tc[5];

tb::HeaterController heater;
tb::Safety safety;
enum class BlowerMode : uint8_t { Off = 0, Duty = 1, Power = 2 };
BlowerMode blower_mode = BlowerMode::Off;
float blower_value = 0.0f;   // duty (0..1) or target W
float blower_duty = 0.0f;
tb::Pi blower_pi;

volatile float heater_duty = 0.0f;          // read by the output timer
volatile uint32_t loop_alive_ms = 0;
volatile bool loop_stalled = false;
float power_w = 0.0f, energy_wh = 0.0f, airflow_ls = 0.0f, exch_w = NAN;
uint32_t last_poll_ms = 0;
bool ever_polled = false;

// Log ring buffer: 3 h at 10 s
struct Row {
    uint32_t seq, t_s;
    float t[5];
    uint8_t hmode;
    float sp, hduty, p, e;
    uint8_t bmode;
    float bduty, v, q;
    uint16_t faults;
};
static const int RING = 1080;
Row ring[RING];
uint32_t seq = 0;

WebServer server(80);

// ---------------------------------------------------------------- MAX6675
// Bit-banged read, the same timing as the long-standing Adafruit driver. Each module needs
// at least 220 ms between reads; the loop reads every channel once per second.
static uint16_t max6675_read(int cs) {
    uint16_t v = 0;
    digitalWrite(cs, LOW);
    delayMicroseconds(10);
    for (int i = 15; i >= 0; --i) {
        digitalWrite(PIN_SCK, LOW);
        delayMicroseconds(10);
        if (digitalRead(PIN_SO)) v |= (1u << i);
        digitalWrite(PIN_SCK, HIGH);
        delayMicroseconds(10);
    }
    digitalWrite(cs, HIGH);
    return v;
}

static void read_thermocouples() {
    for (int k = 0; k < 5; ++k) {
        tb::TcReading r = tb::decode_max6675(max6675_read(PIN_CS[k]));
        tc[k].ok = r.ok;
        tc[k].open = r.open;
        tc[k].c = r.ok ? r.c : NAN;
    }
}

// ---------------------------------------------------------------- heater output timer
static int burst_tick = 0;
static void output_timer_cb(void*) {
    uint32_t now = millis();
    if ((uint32_t)(now - loop_alive_ms) > LOOP_STALL_MS) loop_stalled = true;
    int on_ticks = loop_stalled ? 0 : tb::burst_on_ticks(heater_duty, BURST_TICKS);
    digitalWrite(PIN_SSR, burst_tick < on_ticks ? HIGH : LOW);
    burst_tick = (burst_tick + 1) % BURST_TICKS;
}

// ---------------------------------------------------------------- blower
static void blower_write(float duty) {
    blower_duty = duty < 0 ? 0 : (duty > 1 ? 1 : duty);
    ledcWrite(BLOWER_LEDC_CH, (uint32_t)(blower_duty * 1023.0f + 0.5f));
}

static void blower_update(float dt) {
    airflow_ls = tb::interp(cfg.air_duty, cfg.air_ls, cfg.air_n, blower_duty);
    bool air_ok = tc[CH_T5].ok && tc[CH_T6].ok;
    exch_w = (air_ok && blower_duty > 0) ? tb::exchanger_duty_w(airflow_ls, tc[CH_T6].c, tc[CH_T5].c) : NAN;
    switch (blower_mode) {
        case BlowerMode::Off:
            blower_write(0);
            break;
        case BlowerMode::Duty:
            blower_write(blower_value);
            break;
        case BlowerMode::Power:
            if (!air_ok) break;   // hold the last duty until both air channels read again
            blower_write(blower_pi.update(blower_value - exch_w, dt, cfg.blower_min, 1.0f));
            break;
    }
}

// ---------------------------------------------------------------- config persistence
static void config_load() {
    prefs.begin("tb", true);
    cfg.v_line = prefs.getFloat("v_line", cfg.v_line);
    cfg.r_heat = prefs.getFloat("r_heat", cfg.r_heat);
    cfg.kp = prefs.getFloat("kp", cfg.kp);
    cfg.ti = prefs.getFloat("ti", cfg.ti);
    cfg.kpb = prefs.getFloat("kpb", cfg.kpb);
    cfg.tib = prefs.getFloat("tib", cfg.tib);
    cfg.blower_min = prefs.getFloat("bmin", cfg.blower_min);
    cfg.off_t1 = prefs.getFloat("off_t1", cfg.off_t1);
    cfg.pwm_hz = prefs.getUInt("pwm_hz", cfg.pwm_hz);
    if (prefs.isKey("air_n")) {
        cfg.air_n = prefs.getInt("air_n", cfg.air_n);
        prefs.getBytes("air_d", cfg.air_duty, sizeof(cfg.air_duty));
        prefs.getBytes("air_l", cfg.air_ls, sizeof(cfg.air_ls));
    }
    prefs.end();
}

static void config_save() {
    prefs.begin("tb", false);
    prefs.putFloat("v_line", cfg.v_line);
    prefs.putFloat("r_heat", cfg.r_heat);
    prefs.putFloat("kp", cfg.kp);
    prefs.putFloat("ti", cfg.ti);
    prefs.putFloat("kpb", cfg.kpb);
    prefs.putFloat("tib", cfg.tib);
    prefs.putFloat("bmin", cfg.blower_min);
    prefs.putFloat("off_t1", cfg.off_t1);
    prefs.putUInt("pwm_hz", cfg.pwm_hz);
    prefs.putInt("air_n", cfg.air_n);
    prefs.putBytes("air_d", cfg.air_duty, sizeof(cfg.air_duty));
    prefs.putBytes("air_l", cfg.air_ls, sizeof(cfg.air_ls));
    prefs.end();
}

// Parse "0.25:1.1,0.5:2.2,..." (duty 0..1 : L/s), ascending duty. Returns false if invalid.
static bool parse_air_table(const String& s) {
    float d[8], l[8];
    int n = 0, start = 0;
    while (start < (int)s.length() && n < 8) {
        int comma = s.indexOf(',', start);
        String pair = s.substring(start, comma < 0 ? s.length() : comma);
        int colon = pair.indexOf(':');
        if (colon < 0) return false;
        d[n] = pair.substring(0, colon).toFloat();
        l[n] = pair.substring(colon + 1).toFloat();
        if (d[n] <= 0 || d[n] > 1 || l[n] <= 0 || (n > 0 && (d[n] <= d[n - 1] || l[n] <= l[n - 1]))) return false;
        ++n;
        if (comma < 0) break;
        start = comma + 1;
    }
    if (n < 2) return false;
    cfg.air_n = n;
    for (int k = 0; k < n; ++k) {
        cfg.air_duty[k] = d[k];
        cfg.air_ls[k] = l[k];
    }
    return true;
}

// ---------------------------------------------------------------- logging
static const char* CSV_HEADER =
    "seq,t_s,T1_C,T3_C,T4_C,T5_C,T6_C,heater_mode,setpoint_C,heater_duty,heater_W,heater_Wh,"
    "blower_mode,blower_duty,airflow_Ls,exchanger_W,faults";

static void log_row() {
    Row& r = ring[seq % RING];
    r.seq = seq + 1;
    r.t_s = millis() / 1000;   // monotonic since boot; the host adds wall-clock time
    for (int k = 0; k < 5; ++k) r.t[k] = tc[k].c;
    r.hmode = (uint8_t)heater.mode;
    r.sp = heater.setpoint;
    r.hduty = heater_duty;
    r.p = power_w;
    r.e = energy_wh;
    r.bmode = (uint8_t)blower_mode;
    r.bduty = blower_duty;
    r.v = airflow_ls;
    r.q = exch_w;
    r.faults = safety.latched;
    ++seq;
    Serial.printf("%u,%u", r.seq, r.t_s);
    for (int k = 0; k < 5; ++k) Serial.printf(",%.2f", r.t[k]);
    Serial.printf(",%u,%.1f,%.3f,%.1f,%.2f,%u,%.3f,%.2f,%.1f,%u\n", r.hmode, r.sp, r.hduty, r.p, r.e, r.bmode,
                  r.bduty, r.v, r.q, r.faults);
}

static void fmt(String& out, float v, int dp) {
    out += ',';
    if (!isnan(v)) out += String(v, dp);   // blank field for an invalid reading
}

// ---------------------------------------------------------------- HTTP API
static bool authorized() {
    if (strlen(API_TOKEN) == 0) return true;
    if (server.arg("token") == API_TOKEN) return true;
    server.send(403, "text/plain", "forbidden\n");
    return false;
}

static void heartbeat() {
    last_poll_ms = millis();
    ever_polled = true;
}

static String status_json() {
    String j = "{\"fw\":\"" TB_FW_REV "\",\"uptime_s\":" + String(millis() / 1000);
    for (int k = 0; k < 5; ++k) {
        j += ",\"" + String(TC_NAME[k]) + "\":";
        j += tc[k].ok ? String(tc[k].c, 2) : (tc[k].open ? "\"open\"" : "\"fault\"");
    }
    j += ",\"heater_mode\":" + String((int)heater.mode) + ",\"setpoint\":" + String(heater.setpoint, 1);
    j += ",\"heater_duty\":" + String(heater_duty, 3) + ",\"heater_W\":" + String(power_w, 1);
    j += ",\"heater_Wh\":" + String(energy_wh, 2);
    j += ",\"blower_mode\":" + String((int)blower_mode) + ",\"blower_value\":" + String(blower_value, 3);
    j += ",\"blower_duty\":" + String(blower_duty, 3) + ",\"airflow_Ls\":" + String(airflow_ls, 2);
    j += ",\"exchanger_W\":" + (isnan(exch_w) ? String("null") : String(exch_w, 1));
    j += ",\"faults_latched\":" + String(safety.latched) + ",\"faults_active\":" + String(safety.active);
    j += ",\"seq\":" + String(seq) + "}";
    return j;
}

static void handle_status() {
    if (!authorized()) return;
    server.send(200, "application/json", status_json() + "\n");
}

// GET /log?since=N : header line, then every buffered row with seq > N (up to 360).
// Each call is also the heartbeat that keeps the heaters enabled.
static void handle_log() {
    if (!authorized()) return;
    heartbeat();
    uint32_t since = server.arg("since").toInt();
    uint32_t oldest = seq > RING ? seq - RING + 1 : 1;
    uint32_t from = since + 1 < oldest ? oldest : since + 1;
    String out = CSV_HEADER;
    out += '\n';
    int count = 0;
    for (uint32_t s = from; s <= seq && count < 360; ++s, ++count) {
        const Row& r = ring[(s - 1) % RING];
        out += String(r.seq) + ',' + String(r.t_s);
        for (int k = 0; k < 5; ++k) fmt(out, r.t[k], 2);
        out += ',' + String(r.hmode);
        fmt(out, r.sp, 1);
        fmt(out, r.hduty, 3);
        fmt(out, r.p, 1);
        fmt(out, r.e, 2);
        out += ',' + String(r.bmode);
        fmt(out, r.bduty, 3);
        fmt(out, r.v, 2);
        fmt(out, r.q, 1);
        out += ',' + String(r.faults) + '\n';
    }
    server.send(200, "text/csv", out);
}

// GET /heater?mode=off|charge|hold|manual&sp=550&duty=0.1
static void handle_heater() {
    if (!authorized()) return;
    String m = server.arg("mode");
    float sp = server.hasArg("sp") ? server.arg("sp").toFloat() : NAN;
    if (m == "off") {
        heater.set_mode(tb::HeaterMode::Off, heater.setpoint);
    } else if (m == "charge" || m == "hold") {
        float s = isnan(sp) ? (m == "charge" ? 550.0f : 200.0f) : sp;
        if (s < 20.0f || s > 550.0f) return (void)server.send(400, "text/plain", "sp must be 20 to 550\n");
        heater.set_mode(m == "charge" ? tb::HeaterMode::Charge : tb::HeaterMode::Hold, s);
    } else if (m == "manual") {
        float d = server.arg("duty").toFloat();
        if (d < 0.0f || d > 0.25f) return (void)server.send(400, "text/plain", "manual duty must be 0 to 0.25\n");
        heater.set_mode(tb::HeaterMode::Manual, heater.setpoint, d);
    } else {
        return (void)server.send(400, "text/plain", "mode must be off, charge, hold or manual\n");
    }
    handle_status();
}

// GET /blower?mode=off|duty|power&value=...
static void handle_blower() {
    if (!authorized()) return;
    String m = server.arg("mode");
    float v = server.arg("value").toFloat();
    if (m == "off") {
        blower_mode = BlowerMode::Off;
    } else if (m == "duty") {
        if (v < 0.0f || v > 1.0f) return (void)server.send(400, "text/plain", "duty must be 0 to 1\n");
        blower_mode = BlowerMode::Duty;
        blower_value = v;
    } else if (m == "power") {
        if (v <= 0.0f || v > 1000.0f) return (void)server.send(400, "text/plain", "power must be 1 to 1000 W\n");
        blower_mode = BlowerMode::Power;
        blower_value = v;
        blower_pi.kp = cfg.kpb;
        blower_pi.ti = cfg.tib;
        blower_pi.reset(blower_duty > cfg.blower_min ? blower_duty : cfg.blower_min, 0.0f);
    } else {
        return (void)server.send(400, "text/plain", "mode must be off, duty or power\n");
    }
    handle_status();
}

// GET /config : show. GET /config?key=value&... : set and save.
// Keys: v_line, r_heat, kp, ti, kpb, tib, bmin, off_t1, pwm_hz, air (e.g. 0.25:1.1,0.5:2.2)
static void handle_config() {
    if (!authorized()) return;
    bool changed = false;
    auto setf = [&](const char* key, float& dst, float lo, float hi) {
        if (!server.hasArg(key)) return true;
        float v = server.arg(key).toFloat();
        if (v < lo || v > hi) return false;
        dst = v;
        changed = true;
        return true;
    };
    bool ok = setf("v_line", cfg.v_line, 90, 140) && setf("r_heat", cfg.r_heat, 5, 50) && setf("kp", cfg.kp, 0, 1) &&
              setf("ti", cfg.ti, 10, 10000) && setf("kpb", cfg.kpb, 0, 0.1f) && setf("tib", cfg.tib, 5, 10000) &&
              setf("bmin", cfg.blower_min, 0, 0.8f) && setf("off_t1", cfg.off_t1, -5, 5);
    if (ok && server.hasArg("pwm_hz")) {
        uint32_t hz = server.arg("pwm_hz").toInt();
        if (hz < 20 || hz > 25000) ok = false;
        else {
            cfg.pwm_hz = hz;
            ledcSetup(BLOWER_LEDC_CH, cfg.pwm_hz, 10);
            changed = true;
        }
    }
    if (ok && server.hasArg("air")) {
        ok = parse_air_table(server.arg("air"));
        changed = changed || ok;
    }
    if (!ok) return (void)server.send(400, "text/plain", "value out of range\n");
    if (changed) config_save();
    heater.pi.kp = cfg.kp;
    heater.pi.ti = cfg.ti;
    String j = "{\"v_line\":" + String(cfg.v_line, 1) + ",\"r_heat\":" + String(cfg.r_heat, 2) +
               ",\"kp\":" + String(cfg.kp, 4) + ",\"ti\":" + String(cfg.ti, 0) + ",\"kpb\":" + String(cfg.kpb, 5) +
               ",\"tib\":" + String(cfg.tib, 0) + ",\"bmin\":" + String(cfg.blower_min, 2) +
               ",\"off_t1\":" + String(cfg.off_t1, 2) + ",\"pwm_hz\":" + String(cfg.pwm_hz) + ",\"air\":\"";
    for (int k = 0; k < cfg.air_n; ++k) j += (k ? "," : "") + String(cfg.air_duty[k], 2) + ":" + String(cfg.air_ls[k], 2);
    j += "\"}\n";
    server.send(200, "application/json", j);
}

// GET /clear : clear latched faults if no fault condition is present now.
static void handle_clear() {
    if (!authorized()) return;
    bool ok = safety.clear();
    if (ok) loop_stalled = false;   // the loop is running, since it is serving this request
    server.send(ok ? 200 : 409, "text/plain", ok ? "cleared\n" : "fault still present\n");
}

#ifdef TB_TEST_INJECT
// Test build only (env esp32dev_test): /inject?t1=600 overrides T1 for TBK-TST-001 TP1 step 5.
float inject_t1 = NAN;
static void handle_inject() {
    if (!authorized()) return;
    inject_t1 = server.hasArg("t1") ? server.arg("t1").toFloat() : NAN;
    server.send(200, "text/plain", isnan(inject_t1) ? "injection off\n" : "T1 injected\n");
}
#endif

// ---------------------------------------------------------------- setup and loop
void setup() {
    pinMode(PIN_SSR, OUTPUT);
    digitalWrite(PIN_SSR, LOW);
    Serial.begin(115200);
    pinMode(PIN_SCK, OUTPUT);
    digitalWrite(PIN_SCK, HIGH);
    pinMode(PIN_SO, INPUT);
    for (int k = 0; k < 5; ++k) {
        pinMode(PIN_CS[k], OUTPUT);
        digitalWrite(PIN_CS[k], HIGH);
    }
    config_load();
    heater.pi.kp = cfg.kp;
    heater.pi.ti = cfg.ti;
    ledcSetup(BLOWER_LEDC_CH, cfg.pwm_hz, 10);
    ledcAttachPin(PIN_BLOWER, BLOWER_LEDC_CH);
    blower_write(0);

    loop_alive_ms = millis();
    esp_timer_create_args_t targs = {};
    targs.callback = &output_timer_cb;
    targs.name = "ssr";
    esp_timer_handle_t timer;
    esp_timer_create(&targs, &timer);
    esp_timer_start_periodic(timer, 10000);   // 10 ms

    esp_task_wdt_init(WDT_TIMEOUT_S, true);
    esp_task_wdt_add(NULL);

    WiFi.mode(WIFI_STA);
    WiFi.setAutoReconnect(true);
    WiFi.begin(WIFI_SSID, WIFI_PASS);

    server.on("/status", handle_status);
    server.on("/log", handle_log);
    server.on("/heater", handle_heater);
    server.on("/blower", handle_blower);
    server.on("/config", handle_config);
    server.on("/clear", handle_clear);
#ifdef TB_TEST_INJECT
    server.on("/inject", handle_inject);
#endif
    server.begin();
    Serial.printf("# ThermaBrick test article firmware %s\n%s\n", TB_FW_REV, CSV_HEADER);
}

void loop() {
    static uint32_t last_tick = 0, last_log = 0;
    static bool wifi_reported = false;
    uint32_t now = millis();
    loop_alive_ms = now;
    esp_task_wdt_reset();
    server.handleClient();

    if (!wifi_reported && WiFi.status() == WL_CONNECTED) {
        Serial.printf("# connected, http://%s/status\n", WiFi.localIP().toString().c_str());
        wifi_reported = true;
    }

    if ((uint32_t)(now - last_tick) >= TICK_MS) {
        float dt = (now - last_tick) / 1000.0f;
        if (last_tick == 0) dt = TICK_MS / 1000.0f;
        last_tick = now;
        read_thermocouples();
        bool t1_ok = tc[CH_T1].ok;
        float t1 = tc[CH_T1].c + cfg.off_t1;
#ifdef TB_TEST_INJECT
        if (!isnan(inject_t1)) {
            t1_ok = true;
            t1 = inject_t1;
        }
#endif
        safety.evaluate(t1_ok, t1, tc[CH_T3].ok, tc[CH_T3].c, tc[CH_T4].ok, tc[CH_T4].c, now, last_poll_ms,
                        ever_polled);
        if (loop_stalled) safety.latched |= tb::F_LOOP;
        // Any latched fault drops the heater to Off, so clearing a fault never restarts heating.
        if (!safety.heaters_allowed() && heater.mode != tb::HeaterMode::Off)
            heater.set_mode(tb::HeaterMode::Off, heater.setpoint);
        heater_duty = heater.update(safety.heaters_allowed(), t1_ok, t1, dt);
        power_w = tb::heater_power_w(heater_duty, cfg.v_line, cfg.r_heat);
        energy_wh += power_w * dt / 3600.0f;
        blower_update(dt);
    }
    if ((uint32_t)(now - last_log) >= LOG_MS) {
        last_log = now;
        log_row();
    }
    delay(2);
}

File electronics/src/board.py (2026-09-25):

#!/usr/bin/env python3
"""ThermaBrick controller board: schematic, PCB layout and fabrication files (TBK-DWG-004).

Run from the repo root:  python electronics/src/board.py

Stage 1 (any Python 3.9+): writes the board schematic and project library to
electronics/controller-board/, runs ERC and checks every net (reusing schematic.py).
Stage 2 (KiCad's bundled Python, started automatically): places the footprints,
routes the board with a two-layer grid router, pours GND, runs DRC with schematic
parity, and exports gerbers, drill files and the TBK-DWG-004 sheet.

The board carries the low-voltage controller only: ESP32-DevKitC V4, five MAX6675
modules, a 12 V to 5 V regulator, the SSR driver and the blower driver. Mains wiring
(fuse, latching relay, SSR, REX-C100, heaters) stays as panel wiring per TBK-DWG-003.
Licensed MIT (the script) and CERN-OHL-S-2.0 (the design it produces).
"""
import json
import math
import heapq
import os
import re
import shutil
import subprocess
import sys
from pathlib import Path

HERE = Path(__file__).resolve().parent
ROOT = HERE.parents[1]
sys.path.insert(0, str(HERE))
import schematic as S  # noqa: E402

NAME = "thermabrick-controller-board"
OUT = ROOT / "electronics" / "controller-board"
DWG, REV, DATE = "TBK-DWG-004", "P1", "2026-09-24"
G = S.G
P_IN, P_OUT, PASS, TRI, IN, DOUT = S.P_IN, S.P_OUT, S.PASS, S.TRI, S.IN, S.DOUT

# ---------------------------------------------------------------- ESP32-DevKitC V4 pinout
# Espressif ESP32-DevKitC V4 user guide: header J2 (left, pads 1-19) and J3 (right, pads 20-38),
# both numbered from the antenna end. Rows are 25.4 mm apart.
J2 = ["3V3", "EN", "VP", "VN", "IO34", "IO35", "IO32", "IO33", "IO25", "IO26", "IO27", "IO14", "IO12",
      "GND", "IO13", "D2", "D3", "CMD", "5V"]
J3 = ["GND", "IO23", "IO22", "TX", "RX", "IO21", "GND", "IO19", "IO18", "IO5", "IO17", "IO16", "IO4",
      "IO0", "IO2", "IO15", "D1", "D0", "CLK"]
DEVKIT_PAD = {}
for i, n in enumerate(J2):
    DEVKIT_PAD.setdefault(n, []).append(str(i + 1))
for i, n in enumerate(J3):
    DEVKIT_PAD.setdefault(n, []).append(str(i + 20))
USED = {"3V3": "+3V3", "5V": "+5V", "GND": "GND", "IO18": "SCK", "IO19": "SO", "IO5": "CS_T1", "IO17": "CS_T3",
        "IO16": "CS_T4", "IO4": "CS_T5", "IO22": "CS_T6", "IO26": "SSR_IN", "IO25": "BLOWER_PWM"}


def pin_type(name):
    return {"3V3": P_OUT, "5V": P_IN, "GND": P_IN, "IO19": IN}.get(name, DOUT if name in USED else PASS)


devkit_left = [(str(i + 1), n, pin_type(n)) for i, n in enumerate(J2)]
devkit_right = [(str(i + 20), n, pin_type(n)) for i, n in enumerate(J3)]
devkit_nets = {}
for n, pads in DEVKIT_PAD.items():
    for p in pads:
        devkit_nets[p] = USED.get(n)

CUSTOM = {
    "Term2": S.box_symbol("Term2", "J", "Screw terminal 1x2 5.08 mm", [("1", "1", PASS), ("2", "2", PASS)], [],
                          7.62, "2-way 5.08 mm screw terminal"),
    "R78E": S.box_symbol("R78E", "U", "R-78E5.0-1.0", [("1", "VIN", P_IN), ("2", "GND", P_IN)],
                         [("3", "VOUT", P_OUT)], 12.7, "RECOM R-78E switching regulator, SIP-3"),
    "DevKitC": S.box_symbol("DevKitC", "U", "ESP32-DevKitC V4", devkit_left, devkit_right, 20.32,
                            "ESP32-DevKitC V4 in two 1x19 sockets, rows 25.4 mm apart"),
    "MAX6675_Socket": S.box_symbol("MAX6675_Socket", "U", "MAX6675 module",
                                   [], [("1", "GND", P_IN), ("2", "VCC", P_IN), ("3", "SCK", IN), ("4", "CS", IN),
                                        ("5", "SO", TRI)], 12.7, "MAX6675 module on a 1x5 socket (GND VCC SCK CS SO)"),
}
STD = [("Device", "R"), ("Device", "C_Polarized"), ("Device", "D"), ("Transistor_BJT", "Q_NPN_EBC"),
       ("Transistor_FET", "Q_NMOS_GDS"), ("power", "GND"), ("power", "+3V3"), ("power", "+5V"),
       ("power", "+12V"), ("power", "PWR_FLAG")]

FP_R = "Resistor_THT:R_Axial_DIN0207_L6.3mm_D2.5mm_P10.16mm_Horizontal"
FP_TERM = "TerminalBlock_Phoenix:TerminalBlock_Phoenix_MKDS-1,5-2-5.08_1x02_P5.08mm_Horizontal"
FP_CP = "Capacitor_THT:CP_Radial_D5.0mm_P2.00mm"
FOOTPRINTS_STD = {
    "J1": FP_TERM, "J2": FP_TERM, "J3": FP_TERM, "C1": FP_CP, "C2": FP_CP,
    "U1": "Converter_DCDC:Converter_DCDC_RECOM_R-78E-0.5_THT",
    "R1": FP_R, "R2": FP_R, "R3": FP_R, "R4": FP_R,
    "Q1": "Package_TO_SOT_THT:TO-92_Inline_Wide", "Q2": "Package_TO_SOT_THT:TO-220-3_Vertical",
    "D1": "Diode_THT:D_DO-41_SOD81_P10.16mm_Horizontal",
}
# Every footprint is copied into the project library TB, so the project needs no global libraries
FOOTPRINTS = {ref: "TB:" + fp.split(":", 1)[1] for ref, fp in FOOTPRINTS_STD.items()}
FOOTPRINTS["U2"] = "TB:ESP32_DevKitC_V4_Socket"
TCS = [("U3", "CS_T1", "T1 well wall"), ("U4", "CS_T3", "T3 sand center"), ("U5", "CS_T4", "T4 sand outer"),
       ("U6", "CS_T5", "T5 outlet air"), ("U7", "CS_T6", "T6 room air")]
for u, _cs, _l in TCS:
    FOOTPRINTS[u] = "TB:MAX6675_Module_Socket"
MOUNTING_HOLE = "MountingHole:MountingHole_3.2mm_M3"

PARTS = [
    ("J1", "TB:Term2", "12 V in", 30.48, 40.64, {"1": "+12V", "2": "GND"}),
    ("#FLG01", "TB:PWR_FLAG", "PWR_FLAG", 30.48, 58.42, {"1": "+12V"}),
    ("#FLG02", "TB:PWR_FLAG", "PWR_FLAG", 43.18, 58.42, {"1": "GND"}),
    ("C1", "TB:C_Polarized", "10u 25V", 60.96, 40.64, {"1": "+12V", "2": "GND"}),
    ("U1", "TB:R78E", "R-78E5.0-1.0", 91.44, 40.64, {"1": "+12V", "2": "GND", "3": "+5V"}),
    ("C2", "TB:C_Polarized", "22u 10V", 121.92, 40.64, {"1": "+5V", "2": "GND"}),
    ("U2", "TB:DevKitC", "ESP32-DevKitC V4", 190.5, 104.14, devkit_nets),
    ("R1", "TB:R", "10k", 33.02, 101.6, {"1": "SSR_IN", "2": "GND"}),
    ("R3", "TB:R", "1k", 50.8, 101.6, {"1": "SSR_IN", "2": "Q1_B"}),
    ("Q1", "TB:Q_NPN_EBC", "2N3904", 71.12, 101.6, {"1": "GND", "2": "Q1_B", "3": "SSR_DRV"}),
    ("J2", "TB:Term2", "SSR drive", 99.06, 101.6, {"1": "+5V", "2": "SSR_DRV"}),
    ("R2", "TB:R", "10k", 33.02, 144.78, {"1": "BLOWER_PWM", "2": "GND"}),
    ("R4", "TB:R", "100", 50.8, 144.78, {"1": "BLOWER_PWM", "2": "Q2_G"}),
    ("Q2", "TB:Q_NMOS_GDS", "IRLZ44N", 71.12, 144.78, {"1": "Q2_G", "2": "BLOWER_N", "3": "GND"}),
    ("D1", "TB:D", "1N5819", 88.9, 144.78, {"1": "+12V", "2": "BLOWER_N"}),
    ("J3", "TB:Term2", "Blower", 111.76, 144.78, {"1": "+12V", "2": "BLOWER_N"}),
]
for i, (u, cs, label) in enumerate(TCS):
    PARTS.append((u, "TB:MAX6675_Socket", f"MAX6675 module, {label}", 279.4, 45.72 + i * 22.86,
                  {"1": "GND", "2": "+3V3", "3": "SCK", "4": cs, "5": "SO"}))
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

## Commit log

2026-09-24 Initial scaffold: standard open hardware layout, CERN-OHL-S v2 + MIT licenses
    Claude-Session: https://claude.ai/code/session_01XuhhSU4W6fYhgCfURbrkut
    [bom.csv]
2026-09-24 Develop ThermaBrick to v0.2 draft
    - TBK-PRB-001 v0.2: energy case, users and context, constraints,
    success measures, open decisions and scope
    - TBK-REQ-001 v0.2: 20 requirements with targets, verification
    methods and compliance status
    - TBK-PRC-001 v0.2: full design precis (architecture, subsystems,
    controls, build and commissioning, safety, decisions, risks)
    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
    [bom.csv, thermabrick.step, thermabrick.stl]
2026-09-24 Add 6 kWh test article; correct full-scale sizing for standby loss
    Test article (within the $600 prototype budget, BOM $599.50):
    - TBK-PRC-002 v0.1: design precis, objectives, test plan outline
    - TBK-CAL-002 v0.1: sizing with the shared models and script
    - cad/src/test_article.py: 16 US gal drum, 68 kg sand, four
    full-fidelity heater cells, one U-tube; STEP and STL exports
    - TBK-DWG-002 Rev P1: general arrangement
    - bom/bom-test-article.csv
    Correction to the full-scale design:
    - TBK-CAL-001 v0.2: charge and discharge now include standby loss.
    Full charge 9.6 h (was 7.9 h), so R3 is not met; 1.0 kW held
    14.3 h (was 18 h)
    - TBK-REQ-001 v0.3, TBK-PRC-001 v0.3, TBK-PRB-001 v0.3: updated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
    [bom-test-article.csv, thermabrick-test-article.step, thermabrick-test-article.stl]
2026-09-24 Add test article controller firmware and logging host
    - firmware/: ESP32 (Arduino, PlatformIO) controller with charge, hold
    and manual heater modes, burst-fired SSR output, blower duty and
    closed-loop exchanger power, 10 s logging over HTTP, and latched
    safe-state faults (T1 invalid or above 575 C, sand above 560 C,
    logger lost for 60 s, loop stall) plus task watchdog
    - lib/control with 14 host unit tests (pio test -e native)
    - tools/logger.py: logging host and heartbeat, writes test CSVs
    - esp32dev_test build adds T1 injection for TBK-TST-001 TP1
    - TBK-TST-001 v0.2, TBK-PRC-002 v0.3, README updated; PDFs rendered
    [main.cpp]
2026-09-24 Add TBK-TST-001 analysis script with synthetic self-test
    - docs/05-tests/tbk_tst_001_fit.py: fits sand conductivity, wall
    contact conductance, insulation conductivity and a heater power
    correction to TP3 and TP4 logs (Levenberg-Marquardt, NumPy only);
    reports TP3/TP4 pass criteria, energy closure and time to 80 %;
    predicts TP5 with no refit; selftest recovers known values from
    synthetic data with noise and a 2 % power error
    - TBK-TST-001 v0.3: section 9 describes the method as built
    - TBK-PRC-002 v0.4, README updated; PDFs re-rendered
    - Synthetic self-test output ignored
2026-09-24 Add test article controller schematic TBK-DWG-003 Rev P1
    - electronics/src/schematic.py: generates the KiCad project, runs ERC
    (0 errors, 0 warnings), checks all 36 nets against the declared
    circuit, exports PDF and builds the ANSI B sheet; deterministic
    - electronics/test-article/: self-contained KiCad project and PDF
    - cad/drawings/TBK-DWG-003: schematic on the portfolio sheet
    - BOM: relay specified as DPDT; 10 kOhm pull-downs added ($599.70)
    - TBK-PRC-002 v0.5 (schematic, PE bonding), TBK-REQ-001 v0.4 (R20),
    README, firmware and electronics READMEs; PDFs re-rendered
    [bom-test-article.csv, thermabrick-test-article.kicad_sch]
2026-09-25 Add optional controller board layout TBK-DWG-004 Rev P1
    - electronics/src/board.py: generates the board schematic, places
    footprints, routes with a two-layer grid router, pours the GND
    plane, runs DRC with schematic parity (0 errors, 0 warnings,
    0 unconnected) and exports gerbers, drill files and the sheet
    - electronics/controller-board/: self-contained KiCad project,
    schematic PDF and gerber package for a 110 x 80 mm 2-layer board
    - cad/drawings/TBK-DWG-004: board layout on the portfolio sheet
    - bom/bom-controller-board.csv: board parts, +$24.85 net over the
    $600 hand-wired baseline, so the board is optional
    - schematic.py takes the circuit as a parameter (baseline unchanged)
    - TB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
    [bom-controller-board.csv, thermabrick-controller-board.kicad_pcb, thermabrick-controller-board.kicad_sch]
2026-09-25 Add controller enclosure model TBK-DWG-005 Rev P1
    - cad/src/enclosure.py: parametric 250 x 200 x 150 mm enclosure with
    DIN rail, supply, relay, SSR heat sink, controller, REX-C100,
    buttons and glands; fit check (3 mm clearance, lid closure) that
    also shows the original 100 mm deep box fails; STEP and STL
    - cad/src/sheets.py: TBK-DWG-005 sheet, per-sheet iso options
    - TBK-DWG-003 Rev P2: PS1 is a DIN-rail HDR-15-12 12 V 1.25 A supply
    - BOM: enclosure, supply, DIN rail, glands, lever connectors and
    earth stud corrected; test article now $635.70, over $600
    - TBK-PRC-002 v0.7, TBK-REQ-001 v0.5, TBK-PRB-001 v0.4, README and
    BOM notes updated with the overrun and options; PDFs re-rendere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
    [bom-test-article.csv, thermabrick-controller-enclosure.step, thermabrick-controller-enclosure.stl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]
2026-09-25 Accept the test article budget at $635.70
    - TBK-PRB-001 v0.5, TBK-PRC-002 v0.8, TBK-REQ-001 v0.6: record the
    decision (option 1) to build the whole test article at $635.70
    - BOM notes and README header updated
    - project.yaml: budget_usd 636 for the website card
    - PDFs re-rendered
2026-09-25 Add purchasing checklist for the test article
    - bom/checklist.py: generates bom/purchasing-checklist.md from the
    BOMs, grouped by supplier in ordering order, with order and arrival
    checks; fails if a line is unassigned or totals disagree ($635.70)
    - Optional controller board parts, tools and pre-build checks listed
    - BOM: thermocouples specified as ungrounded junction (no cost change)
    - README and BOM notes link the checklist
    [bom-test-article.csv]
2026-09-25 Add build procedure and cut list; add missing build items to BOM
    - docs/07-build/test-article-build.md: twelve-stage build procedure
    from incoming checks to first power-up, with unplugged checks and
    sign-off
    - docs/07-build/cutlist.py and cut-list.md: every build dimension,
    hole position, insulation piece and the wiring list, generated
    from the CAD models and schematic
    - Model fixes found while writing it: bricks under the chime, legs
    at 36 in nipple length (TBK-DWG-002 Rev P2), wells cut to 692 mm,
    thermocouple tips at 300 mm (TBK-TST-001 v0.4)
    - BOM: second stone wool pack, heater cable, wiring consumables and
    type K extension wire added ($92.00); test article now $727.70
    - T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
    [bom-test-article.csv, thermabrick-test-article.step, thermabrick-test-article.stl]
2026-09-25 Add build log template and entry helper
    - build-log/TEMPLATE.md: session entry with records, deviations
    (each naming the document to change), problems, actual cost,
    photos, safety and next steps
    - build-log/new_entry.py: starts a dated entry with the record table
    for build stages A to L or tests TP0 to TP6, and keeps the README
    index newest first
    - build-log/README.md: conventions and index
    - Build procedure links the log
2026-09-25 Add test report template TBK-TST-002 and fill script
    - TBK-TST-002 v0.1: report structure following TBK-TST-001, with
    as-built record, calibration, TP1 to TP6 results, full-scale
    implications, anomalies, conclusions and data file list
    - tbk_tst_002_fill.py: fills the TP3 to TP5 summary rows, fitted
    properties, fit checks, Figure 1, TP5 comparison and a TBK-CAL-001
    re-run with the fitted values; checked on self-test results
    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
2026-09-25 Review pass: summary, revert unapproved decisions, defer board
    - docs/REVIEW-2026-09.md: work since v0.2, decisions and who made
    them, open issues (R3 charge-time miss, 47 % daily standby loss,
    budget $600 to $727.70), errors corrected, items awaiting Amish
    - $727.70 test article budget returned to proposed, awaiting Amish;
    accepted budget stays $635.70 (TBK-PRB-001 v0.7, TBK-REQ-001 v0.8,
    TBK-PRC-002 v0.11, BOM notes, checklist, README, project.yaml 636)
    - TBK-PRC-001 v0.4: design decisions D1 to D8 marked proposed
    - Controller board marked optional and deferred
    - TRL not added: full-scale model has one invalid U-tube solid, and
    this repo's kit (1.0.0) has no section 9; see review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
    [checklist.py]
2026-09-25 Fix invalid U-tube solid in the full-scale model
    - cad/src/model.py: build one U-tube along +X and rotate copies into
    place; the tube at 270 deg was an invalid solid because near-zero
    sine and cosine terms defeated the boolean
    - All six U-tubes valid and identical (935.34 cm3); assembly valid;
    re-exported STEP reads back as 47 valid solids; geometry unchanged
    - STEP and STL re-exported; TBK-DWG-001 unchanged (1 pixel of
    rendering noise), so not reissued
    - docs/REVIEW-2026-09.md: item 4 marked fixed; TRL still not added
    [thermabrick.step, thermabrick.stl]
2026-09-25 Sync kit to 1.1.4 and record TRL 3
    - .kit: synced from 1.0.0 to 1.1.4 (taken from wastewise-scan at
    d5cba39); adds STANDARDS section 9 and the TRL check in render.py;
    drawing.py and the CI workflow are unchanged
    - project.yaml: trl 3, trl_target 4, trl_evidence (full-scale PRB,
    PRC, REQ, CAL-001, model.py, STEP, TBK-DWG-001, bom.csv)
    - TBK-TST-001 v0.6 and TBK-TST-002 v0.2: environment: lab
    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
2026-09-25 Adopt portfolio kit v1.2.0: TRL target capped at 3, concept media
    Syncs .kit to 1.2.0 from wastewise-scan@8ee209e and adds the root
    CLAUDE.md. Per Amish (option A): trl_target 4 -> 3 under the
    PHASE.yaml cap, and cad/src/concept_media.py generates the hero,
    cutaway, exploded and concept sheet (TBK-DWG-006 Rev P1) in media/.
    Recorded in build-log/2026-09-24-kit-1-2-0.md; review updated.
2026-09-25 Adopt portfolio kit v1.3.0: scale figure, 3D viewer, heat flow diagram
    Syncs .kit, CLAUDE.md and .claude/commands from wastewise-scan@571685f,
    at Amish's request. Concept media regenerated: hero and TBK-DWG-006
    (now Rev P2) carry a 1.75 m scale figure, media/model.glb and
    viewer.html added, and media/flow.png shows the TBK-CAL-001 discharge
    estimates. Recorded in build-log/2026-09-24-kit-1-3-0.md.
2026-09-25 Adopt portfolio kit v1.3.1
    Syncs .kit, CLAUDE.md and .claude/commands from wastewise-scan@b033da6,
    at Amish's request. Concept media regenerated; only media/flow.png
    changed (new layout, same values). Recorded in
    build-log/2026-09-24-kit-1-3-1.md.
2026-09-25 Rein in ThermaBrick to TRL 3: archive out-of-phase TRL 4 work
    Test article, test plan, firmware, electronics, build procedure and purchasing material moved to archive/out-of-phase-trl4/ with history; nothing deleted. TRL 4 on hold by Amish's instruction (2026-0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
    [bom-controller-board.csv, bom-test-article.csv, synthetic_TP3.csv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]
2026-09-26 Accept all recommendations (DDR-002), switch footer to designmolecule.com, add README write-up with new inspiration point
    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
    [thermabrick-controller-board.kicad_sch, thermabrick-test-article.kicad_sch, thermabrick.step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]
2026-09-27 Product appearance model and photoreal renders
    Adds cad/src/product_model.py (appearance model for renders only, all main
    dimensions from model.py) and Blender renders in media/render-*.png,
    captioned with the project, repository and viewing direction. README leads
    with the product render; trl stays 3.
    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
2026-10-01 Image quality pass: legible exploded views, flow diagrams and drawing sheets
    Kit 1.6.1 image layout: the parts list sits in its own column, number bubbles sit on visible parts and never overlap, small parts get a leader, pictures are cropped to the subject, flow labels keep numbers with their units, and sheet captions and the revision table no longer overprint. Concept images, blueprint and general arrangement sheet regenerated; repo-specific labels moved clear of other text and lines.
2026-10-02 Kit 1.7.0: constructable design, illustrated build plan and design decisions register
    The design is now constructable: every part can be made and fits its neighbours, with each change recorded in a Design for construction decision record (made under Amish's 2026-09-30 instruction; ope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
    FlexHand also credits Dr. Geeti Chadha as a contribut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
    [bom.csv, thermabrick.step, thermabrick.stl]
2026-10-02 Record Amish's approval of the open-decision recommendations
    Amish approved the recommendation on every open decision in the design decisions register ("i approve your recommendations for all 555 open decisions.", 2026-10-02). Each decision is moved to Decisio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
2026-10-03 Carry approved follow-ups into the design and redo photoreal renders
    Amish approved the follow-up actions from the open-decision sign-off ("APPROVED CHANGES, COMPLETE THESE", 2026-10-02), the design-for-construction change tables in ten repos, the last wave's open dec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
    [bom.csv, thermabrick.step, thermabrick.stl]
2026-10-03 Record Amish's 2026-10-03 decisions; FlatTrike fork and PotPress guard fixes
    Amish, 2026-10-03: "PalletPilot - i accept it"; "FlatTrike - i accept your design recommendation, proceed and execute the solution for fork direction or caster"; "PotPress - move forward with the four guard fixes. I accept the cost."; "GravitySort - i accept your recommendation"; "TIght Margins - i accept the margins"; "Cost over target - i accept all the cost variations and overruns". FlatTrike knuckle forks turned to trail (35 mm trail); PotPress finer mesh, small-hole plates, top beam and crank bracket covers, ISO 13857 desk check now met on paper. Registers, requirements, drawings, pictures, renders and PDFs upd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

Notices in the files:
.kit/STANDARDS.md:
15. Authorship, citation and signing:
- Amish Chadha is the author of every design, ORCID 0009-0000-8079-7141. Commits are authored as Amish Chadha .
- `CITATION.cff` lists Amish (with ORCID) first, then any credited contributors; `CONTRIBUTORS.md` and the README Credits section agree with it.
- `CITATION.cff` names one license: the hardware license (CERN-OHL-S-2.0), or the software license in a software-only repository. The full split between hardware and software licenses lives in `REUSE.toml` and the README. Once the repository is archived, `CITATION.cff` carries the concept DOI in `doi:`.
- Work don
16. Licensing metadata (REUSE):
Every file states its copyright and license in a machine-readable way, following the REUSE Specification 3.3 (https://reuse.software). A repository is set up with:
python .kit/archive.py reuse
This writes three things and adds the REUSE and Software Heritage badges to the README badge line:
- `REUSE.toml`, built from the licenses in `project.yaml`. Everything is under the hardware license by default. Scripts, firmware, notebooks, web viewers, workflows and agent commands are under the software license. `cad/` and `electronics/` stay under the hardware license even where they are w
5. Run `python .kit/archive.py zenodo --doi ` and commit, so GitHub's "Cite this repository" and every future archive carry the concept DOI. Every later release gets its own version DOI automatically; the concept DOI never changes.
